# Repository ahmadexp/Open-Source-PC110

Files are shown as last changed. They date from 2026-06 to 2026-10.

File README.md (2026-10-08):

<p align="center">
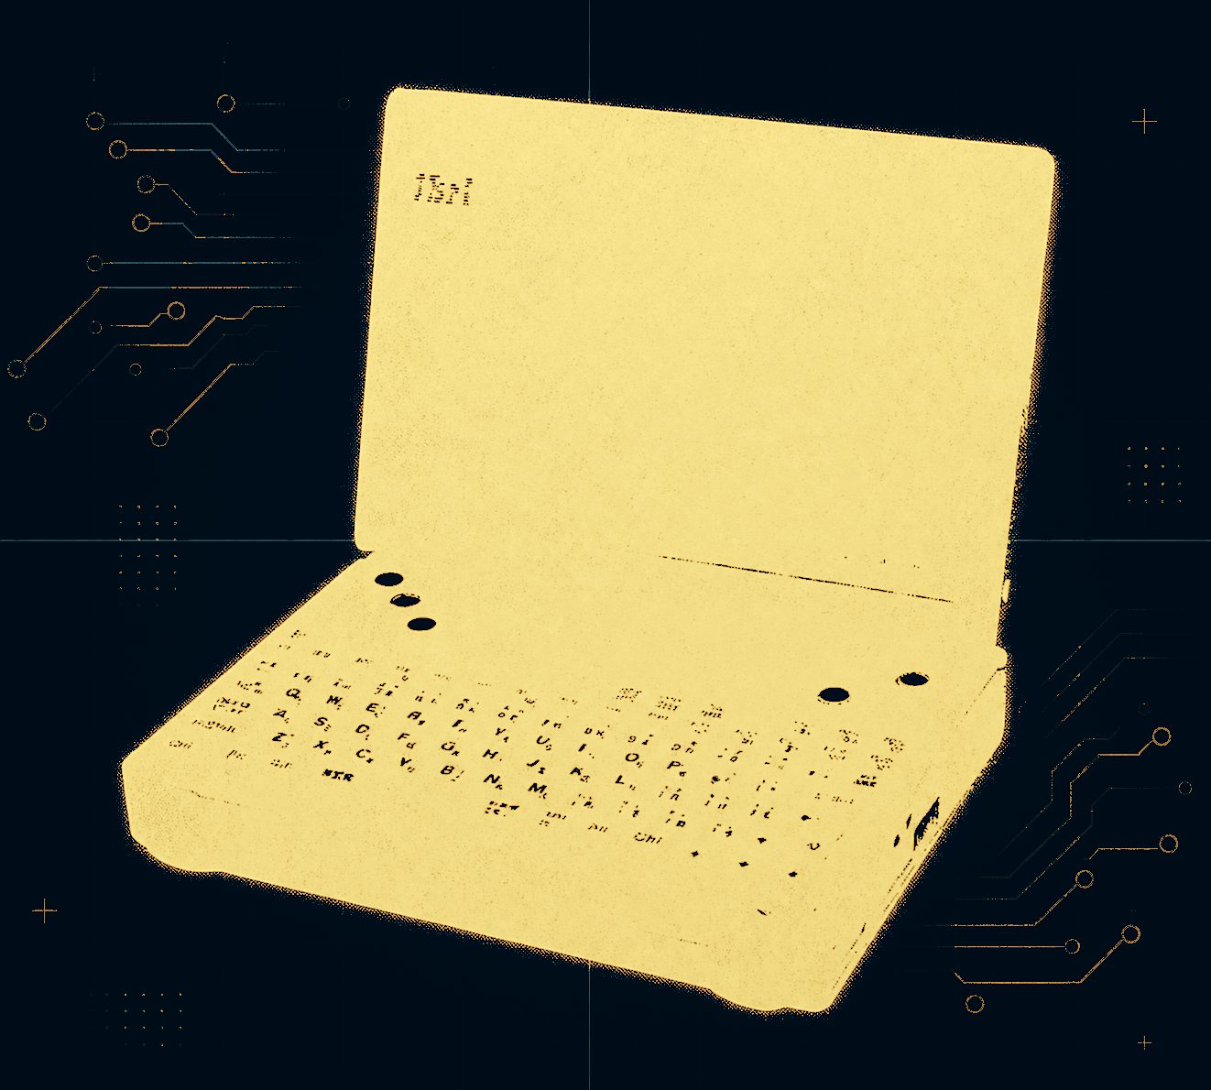
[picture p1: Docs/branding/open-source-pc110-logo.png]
Open-Source PC110 logo
  
</p>

<h1 align="center">Open-Source IBM Palm Top PC110</h1>

<p align="center">
  A complete, open-source reverse engineering of the IBM Palm Top PC110: schematics, PCB layouts,
  ROM and firmware dumps, chip analysis, optical scans, hardware mods, and system tools.
</p>

<p align="center">
  
  
</p>

<p align="center">
  <a href="https://github.com/ahmadexp/Open-Source-PC110/wiki"><strong>Wiki / project story</strong></a>
  ·
  <a href="PCB/PC110-Schematics-Combined.pdf"><strong>Combined schematics</strong></a>
  ·
  <a href="Discovery/Service-Manual/"><strong>Service manual</strong></a>
  ·
  <a href="Mods/ROADMAP.md"><strong>Modernization roadmap</strong></a>
  ·
  <a href="Mods/"><strong>Mods</strong></a>
  ·
  <a href="Software/"><strong>Software</strong></a>
</p>

<p align="center">
  IBM Palm Top PC110 hardware
  PC110 reverse-engineering view
</p>

A complete, open-source reverse engineering of the **IBM Palm Top PC110** (type 2431, 1995), a Japanese-market, 486-class subnotebook co-developed by IBM Japan and Ricoh / RIOS Systems. This repository gathers everything needed to understand, repair, recreate, and modernize the machine: recreated schematics and PCB layouts, die-level chip analysis, firmware and BIOS dumps with disassembly, high-resolution optical and X-ray scans, datasheets, and hardware mods.

> **Goal:** preserve the PC110 in full, signal-for-signal, so it can be rebuilt, repaired, emulated, and reimagined long after the last original board has corroded away.

---

## PC110 Atlas platform compatibility

PC110 Atlas brings the PC110 hardware reference and emulator to modern devices.
Updated October 8, 2026. Features and release availability differ by edition.

### Released editions

| Platform / channel | Compatibility | Download or installation | Availability |
| --- | --- | --- | --- |
| iPhone and iPad | iOS / iPadOS 17 or later | [App Store](https://apps.apple.com/us/app/pc-110/id6801404183) | Available; 1.0.2 (65), released October 7, 2026 |
| iPhone Duo adaptation | Native iOS edition with adaptive inner/outer-display layouts and hinge alignment | [App Store](https://apps.apple.com/us/app/pc-110/id6801404183) | Available in 1.0.2 (65); simulator-tested, with physical-device and guest-runtime validation pending |
| Apple Watch | watchOS 10 or later, paired iPhone | [App Store companion](https://apps.apple.com/us/app/pc-110/id6801404183) | Available; live display, controls, and guest audio from the iPhone session |
| Apple Vision Pro | visionOS 2 or later | [App Store](https://apps.apple.com/us/app/pc-110/id6801404183) | Available; native visionOS edition with local emulation and an interactive 3D PC110 |
| Apple TV | tvOS 17 or later | [App Store](https://apps.apple.com/us/app/pc-110/id6801404183) | Available; hardware, schematics, and history reference with Siri Remote navigation |
| Android phones, tablets, and foldables | Android 8.0 or later; 64-bit ARM64 or x86-64 runtime | [Google Play](https://play.google.com/store/apps/details?id=org.opensourcepc110.atlas) | Available; 1.1.0 (6), published October 8, 2026, with fold-aware layouts, keyboard/mouse support, and optional gamepad controls |
| Wear OS / PC110 Live | Wear OS 3 or later; paired Android phone with matching app and Google Play services | [Google Play companion](https://play.google.com/store/apps/details?id=org.opensourcepc110.atlas) | Available; 1.1.1 (1000007), published October 8, 2026; live display, controls, and optional guest audio |
| Chromebooks and Android gaming handhelds | Compatible Android runtime with Google Play; same Android requirements above | [Google Play](https://play.google.com/store/apps/details?id=org.opensourcepc110.atlas) | Included in Android 1.1.0; resizable workspace and controller support, with physical-device validation still pending |
| Mac App Store edition | macOS 14 or later, Apple M1 or later | [Mac App Store](https://apps.apple.com/us/app/pc-110/id6801404183) | Available |
| Mac desktop / Homebrew | macOS 12 or later; Intel and Apple silicon | [Intel DMG](https://github.com/ahmadexp/homebrew-pc110-atlas/releases/download/desktop-v1.0.0/pc110-atlas-1.0.0-macos-x64.dmg), [Apple silicon DMG](https://github.com/ahmadexp/homebrew-pc110-atlas/releases/download/desktop-v1.0.0/pc110-atlas-1.0.0-macos-arm64.dmg), or [Homebrew instructions](https://github.com/ahmadexp/homebrew-pc110-atlas#install) | Available; Developer ID signed and Apple notarized |
| Windows installers | Windows 10 or later, x64 | [MSI](https://github.com/ahmadexp/homebrew-pc110-atlas/releases/download/desktop-v1.0.0/pc110-atlas-1.0.0-windows-x64.msi) or [EXE](https://github.com/ahmadexp/homebrew-pc110-atlas/releases/download/desktop-v1.0.0/pc110-atlas-1.0.0-windows-x64.exe) | Available |
| Windows / Chocolatey | Windows 10 or later, x64 | [Chocolatey Community package](https://community.chocolatey.org/packages/pc110-atlas/1.0.0) | Approved September 23, 2026; `choco install pc110-atlas` |
| Ubuntu / Snap Store | amd64 and arm64; Linux with snapd | [Snap Store](https://snapcraft.io/pc110-atlas) | Available on stable; `sudo snap install pc110-atlas` |
| Linux / APT | amd64 and arm64; tested on Ubuntu 24.04 | [Signed APT repository and setup](https://ahmadexp.github.io/homebrew-pc110-atlas/) | Available; DEB packages |
| Linux / YUM and DNF | x86_64 and aarch64; compatible RPM distributions | [Signed YUM/DNF repository and setup](https://ahmadexp.github.io/homebrew-pc110-atlas/) | Available; RPM packages |
| Pinokio launcher | Pinokio 8.2+; supported macOS, Windows x64, and Linux x64/ARM64 editions | [Public launcher and installation guide](https://github.com/ahmadexp/pc110-atlas-pinokio) | Available; launches the matching installed edition, not a separate emulator |

### Previews and pending distribution

| Platform / channel | Compatibility | Access or release record | Status |
| --- | --- | --- | --- |
| Android XR | Compatible Android XR headset and 64-bit Android runtime | [Google Play Android edition](https://play.google.com/store/apps/details?id=org.opensourcepc110.atlas) | Optional 3D-laptop preview in 1.1.0; simulator-tested, with physical-headset input and performance validation pending |
| Amazon Fire tablets | Compatible Fire OS with Android API 26+ and a 64-bit ARM64 runtime | [Android 1.1.0 source release](https://github.com/ahmadexp/PC110_MiSTer/releases/tag/pc110-android-1.1.0) | Separate Google-services-free build prepared; hardware validation and Amazon Appstore publication pending |
| Raspberry Pi / Pi-Apps | ARM64 desktop; Raspberry Pi OS Bookworm/Trixie or compatible Ubuntu | [1.0.1 review build](https://github.com/ahmadexp/homebrew-pc110-atlas/releases/tag/desktop-v1.0.1) and [testing guide](https://github.com/ahmadexp/homebrew-pc110-atlas/blob/main/desktop/packaging/pi-apps/README.md) | QEMU review build available and tested on Raspberry Pi 5; [Pi-Apps PR #3051](https://github.com/Botspot/pi-apps/pull/3051) remains open |
| Microsoft Store | Windows 10 or later, x64 desktop | Store ID `9P4QHSVPL2VF` | QEMU-enabled 1.0.1.0 submitted September 18; public Store release not confirmed |
| IRIX / Unix X11 | Experimental IRIX 6.5, MIPS n32 target | [Source test kit](https://github.com/ahmadexp/homebrew-pc110-atlas/releases/tag/irix-v1.0.0) and [build instructions](https://github.com/ahmadexp/homebrew-pc110-atlas/blob/main/unix/README.md) | Source only; frontend tested on Linux X11, with SGI hardware testing still required |

### Edition and device notes

- Apple TV is a reference edition, not a QEMU emulator, and does not import firmware or disk images.
- Apple Watch and Wear OS display a paired phone's running session. QEMU does not run on the watch. Wear OS physical pairing and audio validation remain pending.
- Android requires a 64-bit operating system, not just a 64-bit processor. Android TV / Google TV, cars, 32-bit Android, and Amazon Vega OS are not supported. Physical foldable, Chromebook, handheld/controller, XR, Wear OS, and Fire validation remains incomplete; implementation does not mean every device has been tested.
- The Mac App Store and Homebrew apps are separate editions. Published portable desktop 1.0.0 packages for Intel/Apple silicon Mac, Windows, and Linux use the portable PC110 core, not QEMU, and do not include guest audio. The Raspberry Pi review build and Microsoft Store candidate are separate QEMU-enabled packages.
- Linux packages require compatible system libraries and a graphical desktop. The smaller Unix edition requires a C99 compiler, GNU make, and X11 development libraries.
- Import your own legally obtained compatible system media where supported; guest operating-system compatibility varies by edition.

See [desktop downloads and checksums](https://github.com/ahmadexp/homebrew-pc110-atlas/releases/tag/desktop-v1.0.0),
the [distribution validation record](https://github.com/ahmadexp/homebrew-pc110-atlas/blob/main/desktop/DISTRIBUTION_VALIDATION.md),
and the [Android 1.1.0 corresponding source](https://github.com/ahmadexp/PC110_MiSTer/releases/tag/pc110-android-1.1.0).

## Start here

| If you want to... | Go here |
|---|---|
| Install PC110 Atlas on your device | [Platform compatibility and downloads](#pc110-atlas-platform-compatibility) |
| Understand the full reverse-engineering journey | [Wiki / A Tribute to the IBM PC110](https://github.com/ahmadexp/Open-Source-PC110/wiki) |
| Repair or inspect original hardware | [Unofficial service manual](Discovery/Service-Manual/) and [power sequence guide](Discovery/Power-Sequence/) |
| Review the recreated boards | [PCB projects](PCB/) and [combined schematic PDF](PCB/PC110-Schematics-Combined.pdf) |
| Explore the custom chips and ROMs | [Components](Components/) and [Flash / ROM dumps](Components/Flash/) |
| Work on emulation or system software | [Discovery notes](Discovery/), [PS2 tools](Software/), and [PC110 emulators & FPGA cores](#pc110-emulators--fpga-cores) |
| Build a modernized PC110 variant | [Mods](Mods/) including ITX boards, CPU upgrade work, RAM expansion, and TFT replacement |

## Repository map

| Folder | What you'll find |
|---|---|
| [**Wiki**](https://github.com/ahmadexp/Open-Source-PC110/wiki) | The polished project story and guided tour: why the PC110 matters, how the board was reconstructed, and where to start. |
| [**`PCB/`**](PCB/) | Recreated **KiCad schematics and PCB layouts** for the mainboard, PSU, keyboard membrane, docking station, modem, and 16 MB RAM module. Includes a [combined schematic PDF](PCB/PC110-Schematics-Combined.pdf), fab files, BOMs, and 3D renders. |
| [**`Components/`**](Components/) | **Chip-level reverse engineering**: die-level analysis (with John McMaster), firmware/BIOS/ROM dumps for six chips, disassembly, emulators, and the internal 4 MB disk image. |
| [**`Discovery/`**](Discovery/) | **Deep-dive subsystem notes** for each major chip and bus, plus an unofficial, comprehensive **service & technical reference manual**, a **live hardware dump** from a running unit, and a reverse-engineering of IBM's `PS2.EXE` tool. Start here to understand how it all fits together. |
| [**`Software/`**](Software/) | **Tools for the PC110** — including **PS2TUI**, **PS2GUI**, and **COMrade**, the serial bridge for DOS and Windows 95 control. |
| [**`Mods/`**](Mods/) | **Hardware modifications and redesigns**: ITX-form-factor recreations, a CPU upgrade adapter, a new docking station, a +4 MB RAM mod, a TFT display swap, and Altium ports. |
| [**`Optical/`**](Optical/) | **High-resolution optical scans, X-ray captures, and individual copper-layer images** of every board and the custom chips. |
| [**`Datasheets/`**](Datasheets/) | Datasheets, pinouts, and connector maps for the chips and connectors across the motherboard and peripheral boards. |
| [**`Docs/`**](Docs/) | The project's story — ["A Tribute to the IBM PC110"](Docs/) — covering the sanding, scanning, decapping, and schematic-extraction journey. |

---

## Recreated PCBs ([`PCB/`](PCB/))

All boards are recreated in **KiCad 9.0** (requires the [Alternate KiCad Library](https://alternatekicadlibrary.com/)), with fab files and BOMs.

| Board | Description | Layers |
|---|---|---|
| Mainboard | Motherboard | 10 |
| PSU | Power supply | 4 |
| Keyboard | Keyboard membrane | 2 + 2 |
| Docking Station | Port expansion | 4 |
| Modem | 14.4 kbps internal modem | 6 |
| RAM-16MB | 16 MB RAM module | 4 |

**[Combined schematic PDF →](PCB/PC110-Schematics-Combined.pdf)**

### Mother Board
- Schematic

Mainboard schematic

- Layout

Mainboard layout

### Power Supply
- Schematic

PSU schematic

- Layout

PSU layout

### Keyboard Membrane
- Schematic

Keyboard schematic

- Layout

Keyboard layout

### Port Expansion (Docking Station)
- Schematic

Dock schematic

- Layout

Dock layout

### 14.4 kbps Internal Modem
- Schematic

Modem schematic

- Layout

Modem layout

### 16 MB RAM Module
- Schematic

RAM schematic

- Layout

RAM layout front
RAM layout back

---

## Component Reverse Engineering ([`Components/`](Components/))

### Die-level investigation

A collaboration with [John McMaster](https://siliconpr0n.org/archive/doku.php?id=ibm:pc110) — laser-decapped chips with high-resolution die imaging.

| Designator | Part | Function | Notes |
|---|---|---|---|
| U61 | VL82C420FC5 | "SCAMP IV" chipset (DMA, PIC, PIT, RTC) | [Notes](Components/U61-VL82C420FC5/) |
| U35 | Pluto | Custom I/O gate array | [Notes](Components/U35-Pluto/) |
| U21 | Bowman | Custom system-controller gate array | [Notes](Components/U21-Bowman/) |
| U75 | D17137AGT | TrackPoint controller | [Notes](Components/U75-D17137AGT/) |

### Flash & ROM dumps

Raw readouts plus reverse-engineering analysis (reports, extracted strings, hexdumps, disassembly, and in some cases emulators) for the programmable chips. See [`Components/Flash/`](Components/Flash/).

| Chip | Size | Role |
|---|---|---|
| [Intel E28F002BXT](Components/Flash/E28F002BXT/) | 256 KiB | Main/system **BIOS** (IBM VGA-compatible, APM) — includes BIOS disassembly project |
| [OKI MSM538032E](Components/Flash/OKI-MSM538032E/) | 1 MiB | Japanese/system **font mask ROM** |
| [Eon EN29F040A](Components/Flash/EN29F040A/) | 512 KiB | **Modem/fax board** flash |
| [Mitsubishi M38813E4HP](Components/Flash/M38813E4HP/) | ~16 KiB | **Keyboard controller** firmware (U67) |
| [Mitsubishi M38223E4HP](Components/Flash/M38223E4HP/) | ~16 KiB | **Power-sense** MCU firmware (U6) — includes an emulator |
| [Atmel AT29LV512](Components/Flash/AT29LV512/) | 64 KiB | SanDisk PCMCIA ATA FlashDisk controller (68000) |

### Internal disk image

Images of the PC110's internal 4 MB solid-state drive in [`Components/Internal-Disk-Image/`](Components/Internal-Disk-Image/) (raw `.img` and PowerQuest `.PQI`).

---

## Discovery — subsystem deep-dives ([`Discovery/`](Discovery/))

Reconstructed from schematic recreations, firmware disassembly, die scans, and the datasheets of architectural-twin parts.

| Folder | Subject |
|---|---|
| [**Service-Manual**](Discovery/Service-Manual/) | Unofficial comprehensive service & technical reference manual — **start here** |
| [Chipset](Discovery/Chipset/) | VLSI VL82C420 "SCAMP IV" system controller, full pin map |
| [Bowman](Discovery/Bowman/) | U21 main system-controller ASIC |
| [Pluto](Discovery/Pluto/) | U35 I/O gate array (with 6502 disassembler) |
| [65535](Discovery/65535/) | C&T F65535 flat-panel/CRT VGA controller |
| [ES488](Discovery/ES488/) | ESS ES488F "AudioDrive" + YM3812 (OPL2) FM chain |
| [Modem](Discovery/Modem/) | MN195001 single-chip fax engine |
| [PSU-MB-M38](Discovery/PSU-MB-M38/) | U6 M38223E4HP power-sense MCU + connector map |
| [Power-Sequence](Discovery/Power-Sequence/) | Power-on sequence & "won't power on" repair guide |
| [Trackpoint](Discovery/Trackpoint/) | U75 µPD17137A pointing-device controller |
| [Debug](Discovery/Debug/) | 80486SX debug / JTAG headers + a homebrew debug pod |
| [PS2](Discovery/PS2/) | IBM's `PS2.EXE` configuration tool, fully reverse-engineered — including the hidden `_@` commands |
| [Live-Dump](Discovery/Live-Dump/) | Chipset / BIOS / OS state captured from a **running PC110** over a serial link |

---

## Modifications & redesigns ([`Mods/`](Mods/))

| Project | Description |
|---|---|
| [PC110-ITX](Mods/PC110-ITX/) | An ITX-form-factor motherboard reimplementing the PC110, with original BGA parts converted to QFP for easier assembly |
| [PC110-ITX-all-in-one](Mods/PC110-ITX-all-in-one/) | ITX variant that merges the motherboard and docking-station PSU into one board |
| [CPU Upgrade](Mods/CPU%20Upgrade/) | BGA-to-socket adapter work toward a faster CPU (shares the VL82C420 with Taka's 230cs upgrade) |
| [NewDock](Mods/NewDock/) | A redesigned docking station as a standalone KiCad project |
| [RAS4](Mods/RAS4/) | Enables an extra 4 MB of internal RAM by repurposing `VL_D12` as `RAS#4` |
| [TFT](Mods/TFT/) | TFT display replacement, including a BIOS patch image |
| [Altium](Mods/Altium/) | The PCB projects ported from KiCad to Altium |

---

## Optical scans & X-rays ([`Optical/`](Optical/))

High-resolution optical scans, X-ray captures, and individual copper-layer images of every board and the custom chips — including the full 10-layer copper stack of the mainboard, x-rays of the BGA/QFN packages, and corner-stitch die photos for the 486SX, VL82C420, F65535, Bowman, and Pluto. See [`Optical/README.md`](Optical/).

---

## Community

Join the discussion, ask questions, and share your work:

**Discord:** [discord.gg/WvRh6C6WT](https://discord.gg/WvRh6C6WT)
**Facebook group:** [IBM PC110 community](https://www.facebook.com/groups/985746629171739)

---

## How can you help?

- **Review** the schematics and PCB layouts to spot bugs, errors, and issues.
- **Verify** the layout against the schematic and against real hardware.
- **Find** missing datasheets for the custom and undocumented parts.
- **Contribute** firmware / ROM analysis and disassembly.
- **[Fund the next iteration of PCBA](https://gofund.me/716b7dae)** so we can fabricate and test the recreated motherboard.

---

## Press

Featured on **Hackaday**:
- [Reverse Engineering The IBM PC110, One PCB At A Time](https://hackaday.com/2025/04/06/reverse-engineering-the-ibm-pc110-one-pcb-at-a-time/)

Featured on **Taka's blog**:
- [PC110 New PSU](https://garakutaen.sakura.ne.jp/misc2/MlogmP3.html#e0318)
- [PC110 PCB Pattern](https://garakutaen.sakura.ne.jp/misc2/MlogmP1.html#e0130)
- [PC110 PCB Layout creation](https://garakutaen.sakura.ne.jp/misc2/MlogmP2.html#e0208)
- [PC110 New Docking Station PCB](https://garakutaen.sakura.ne.jp/misc2/MlogmP3.html#e0324)
- [X-ray photos of the inside of the PC110's LSI](https://garakutaen.sakura.ne.jp/misc2/MlogmP2.html#e0225)

**Jeff Geerling's YouTube Channel**:
- [Reverse engineering Episode](https://youtu.be/p7IvioiveOo?si=PUlHSzOhwXYEpZJ3&t=217)

**LGR YouTube Channel**:
- [LGR Vlog: VCFMW20](https://www.youtube.com/watch?v=yIwXQicYClw&t=7595s)

**VCFMW20 YouTube Channel**:
- [Archaeology of the IBM PC110](https://www.youtube.com/watch?v=8Uja7g9hQlo)

---

## Acknowledgements

This project would not have been possible without **Kevin Moonlight** (microcontroller ROM extraction), **Mike Lycett** (fundraiser & coordination), **Nick Rogers** (debugging & verification), **John McMaster** (high-resolution die imaging), **CLC / Fred Nielsen** (decapping & silicon prep), and the wider **open hardware & retrocomputing community**.

---

## PC110 Emulators & FPGA cores

**[PC110-EMU](https://github.com/ahmadexp/PC110-EMU)**: an experimental emulator built around the *real* machine artifacts documented here. It boots the actual PC110 BIOS, runs PC DOS and Personaware, and loads the power-sense and keyboard-controller MCU firmware and the Japanese font flash — the very dumps that live in this repository's [`Components/Flash/`](Components/Flash/) folder.

Highlights:

- Boots the real PC110 BIOS and runs **PC DOS** and supported **Personaware** disk images, including the ROM-backed graphical **Easy-Setup** screen.
- Renders the Personaware launcher with **Japanese DBCS glyphs** pulled from the PC110 font flash ([`MSM538032E`](Components/Flash/OKI-MSM538032E/)).
- Loads the **M38223** power-sense MCU and **M38813** MELPS 740 keyboard-controller firmware for diagnostics and controller responses.
- Models the **front LCD status strip** (the startup `IBM` segment display, time, disk, PMCU, KBC, speaker, and setup state).
- Two frontends: a native **macOS SwiftUI** app for bring-up and diagnostics, and a **portable CMake** build (Linux / Windows / macOS) with a headless runner and an optional SDL2 GUI.
- Rich diagnostics: copy-ready CPU state, traces, memory, and text-screen dumps.

> The emulator ships **no copyrighted ROMs** — use the legally obtained dumps from hardware you own. This repo documents where those dumps come from and what each one does.

The macOS frontend running **Personaware**, with live diagnostics and the modeled front LCD:

PC110 EMU running Personaware with diagnostics and front LCD

The ROM-backed graphical **BIOS Easy-Setup** screen:

PC110 BIOS Easy-Setup screen

**[Get the emulator → ahmadexp/PC110-EMU](https://github.com/ahmadexp/PC110-EMU)**

**[PC110-QEMU](https://github.com/ahmadexp/pc110-qemu)**: a QEMU based emulator for the PC110 with support for the BIOS and is able to boot into DOS7 and run Personaware.

It turns out stock QEMU can run the PC110's software once you give it the handful of PC110-specific
hardware bits the software insists on. PC110-QEMU adds three small QEMU device models, all fed by
the *real* ROM dumps archived in this repository:

- **`pc110-fontrom`** — the banked 1 MB **kanji font ROM** (I/O port `0x1160` selects one of 128 ×
  8 KB banks into a window at `0xDE000`, exactly the mechanism DOS/V's `$FONT.SYS` probes), fed by
  the [MSM538032E dump](Components/Flash/OKI-MSM538032E/). This is what makes Personaware's
  Japanese text render.
- **`pc110-chipset`** — a VLSI/SCAMP + power-MCU shim with an optional full-ROM shadow overlay,
  enough to boot the **real PC110 BIOS** ([E28F002BXT dump](Components/Flash/E28F002BXT/)) on QEMU.
- **`pc110-setupcfg`** — a SeaBIOS-safe config-register + power-MCU interface for the Easy-Setup
  program.

With those in place (`-cpu 486 -m 20M -vga cirrus -device pc110-fontrom,romfile=...`):

- **Personaware**, IBM's Japanese pen-centric GUI, boots to its full home screen in ~20 s — every
  applet (Schedule, ToDo, Notebook, Address, EMail, FAX, IR, WorldClock, DrawMemo, …), live clock,
  working mouse, and sharp DBCS kanji rendered from the real font ROM.
- The graphical **BIOS Easy-Setup** runs under SeaBIOS too: the LZW-compressed setup image is
  extracted from the BIOS flash and chain-loaded by a custom floppy boot sector that enters it
  exactly like the real BIOS does — full main menu, config screens, and the bird mascot — and
  exiting Easy-Setup drops you back into Personaware, just like on the real machine.

The repo also ships the supporting tooling: the LZW Easy-Setup extractor, the Easy-Setup boot
loader (with exit/restart routed back to the hard disk), a partition-dump → bootable-disk
converter (the PC110's internal disk images are partition dumps that need an MBR prepended), and
build/run scripts. No ROMs or disk images are included — supply your own legally obtained dumps,
which this repository documents how to make.

**[Get it → ahmadexp/pc110-qemu](https://github.com/ahmadexp/pc110-qemu)**

**[PC110_MiSTer](https://github.com/ahmadexp/PC110_MiSTer)**: the PC110 as an **FPGA core** — not
emulation but a hardware reimplementation, targeting the **MiSTer** platform (**DE10-Nano**) and built
on the `ao486` core infrastructure. Like the emulators above, it is fed by the *real* dumps archived
here.

Verified milestone: **a zero-error POST, IBM Easy-Setup with working keyboard navigation, and an
unattended PC DOS J7.0/V boot into the PersonaWare V1.0 desktop.**

What the core implements, and where it lines up with this repository:

- **486-class CPU** (forced 30 MHz) plus the AT peripheral set — IDE, floppy, VGA, keyboard, mouse.
- **The stock PC110 memory map**: 4 MiB planar RAM + a 16 MiB expansion module — i.e. the factory 20 MB
  configuration documented in [`Discovery/RAM-Module`](Discovery/RAM-Module/readme.md).
- **256 KiB flash mapped at `C0000h–FFFFFh`** — the [E28F002BXT BIOS dump](Components/Flash/E28F002BXT/).
- **Font-ROM banking** with a 1 MiB font image — the [MSM538032E dump](Components/Flash/OKI-MSM538032E/)
  and the `0x1160` bank-select mechanism, which is what makes Japanese text render.
- **PCMCIA and CMOS** interfaces, the **inking** interface
  ([`Discovery/Inking`](Discovery/Inking/)), and PC110-specific board **I/O decode**.

The project is refreshingly candid about its scope — it calls itself *"an engineering core, not yet a
cycle-exact replacement for the whole PC110 planar,"* and documents which parts are **measured** versus
**placeholder** separately. Building needs **Quartus 17.0.2** (provided via a Docker container), with
scripts for ROM preparation, build, and deployment to MiSTer hardware over SSH.

**[Get the core → ahmadexp/PC110_MiSTer](https://github.com/ahmadexp/PC110_MiSTer)**

## PC110 System Configuration tools

**[PS2TUI](https://github.com/ahmadexp/PS2TUI)**: a text UI based tool to configure, test and perform system level operations on the PC110.

`PS2.EXE` is IBM's command-line utility for configuring the PC110: ~50 cryptic, largely
undocumented switches controlling power management, device I/O assignment, display, keyboard, and
low-level chipset settings. We disassembled it and decoded its hardware interface in
[`Discovery/PS2`](Discovery/PS2/) — the full command reference **including the hidden `_@`
commands**, how it drives the APM BIOS (`INT 15h AX=5300/530A`), IBM's **vendor APM extension**
(`AX=5380`), and where the settings are stored in extended CMOS
([`DISASM.md`](Discovery/PS2/DISASM.md) has the annotated disassembly).

**PS2TUI** turns that knowledge into a tool you'd actually want to use: a full-screen,
keyboard-driven menu for all of it, written in assembly as a ~3.4 KB DOS `.COM`.

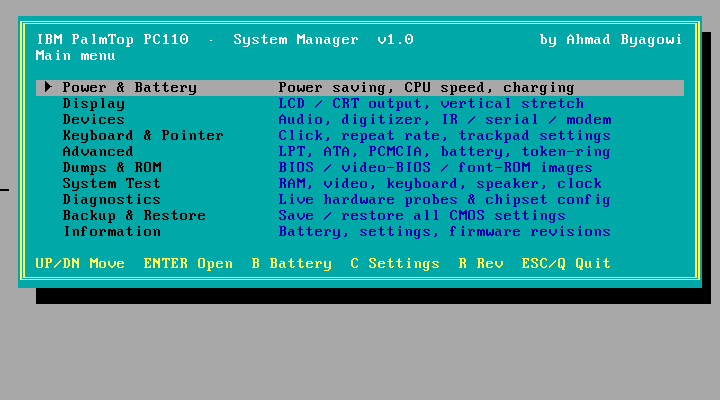
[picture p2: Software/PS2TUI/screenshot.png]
PS2TUI main menu


- Covers the documented **and hidden** setting groups (power, display, audio, IR/serial/modem
  routing, keyboard, PCMCIA, and more); every change shows the exact `PS2` command and asks for
  confirmation before running it.
- **Native read paths** — no `PS2.EXE` needed: live battery / AC status straight from the APM
  BIOS, and the current settings read directly from CMOS.
- Extras `PS2.EXE` never had: byte-perfect **dumps of the system BIOS, video BIOS, and the 1 MB
  font ROM** to disk (CRC-verified against the dumps in this repo), plus an Easy-Setup-style
  **system test** (RAM, video, keyboard, speaker).
- Settings are *applied* by invoking IBM's own `PS2.EXE`, so all writes go through IBM's tested
  hardware paths.
- Built with NASM; developed and verified **on real PC110 hardware** over a serial
  [COMrade](Discovery/Live-Dump/) session.

Prebuilt binary and source: [`Software/PS2TUI/`](Software/PS2TUI/) · standalone repo:
**[ahmadexp/PS2TUI](https://github.com/ahmadexp/PS2TUI)**

**[PS2GUI](https://github.com/ahmadexp/PS2GUI)**: a graphical IBM Easy-Setup-style system manager for the IBM PalmTop PC110.

**PS2GUI** builds on the same PS2TUI command tree and turns it into a VGA mode 12h
(640x480x16) icon-grid interface that closely matches the PC110's own BIOS Easy-Setup screen.

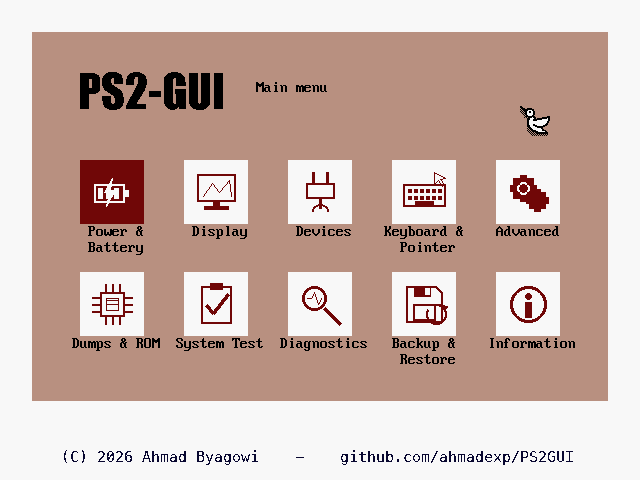
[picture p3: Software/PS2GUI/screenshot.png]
PS2GUI main menu


- Recreates the Easy-Setup look: white border, mauve desktop, dark-red selection, matching DAC
  palette, heavy title lettering, and a 5x2 grid of white icon tiles.
- Covers the same ten top-level categories and option lists as PS2TUI, with hand-drawn pixel-art
  icons for each category and item.
- Runs as a self-contained real-mode DOS `.COM`; the native APM / CMOS / SCAMP / PCIC / 8042
  read paths, dumps, diagnostics, and tests are built in, so no external `PS2TUI.COM` is needed.
- Supports keyboard navigation and INT 33h mouse input, including an Easy-Setup-style arrow cursor
  and graphical value-picker dialogs.
- Applies configuration changes through IBM's own `PS2.EXE` / `ULTRACHG.COM`, keeping writes on
  the original tested hardware paths.

Prebuilt binary and source: [`Software/PS2GUI/`](Software/PS2GUI/) · standalone repo:
**[ahmadexp/PS2GUI](https://github.com/ahmadexp/PS2GUI)**

**[COMrade](Software/COMrade/)**: a serial control bridge for PC110 bring-up and
remote diagnostics. The DOS TSR supports screen and console capture, file
transfer, keyboard injection, real-mode memory, port I/O, and hardware probes.
The included `COMR95.EXE` is a separate Win32 agent for Windows 95 with file,
keyboard, screen, and small GDI desktop-thumbnail support, using the same wire
protocol and Python MCP bridge.

Prebuilt agents and source: [`Software/COMrade/`](Software/COMrade/) · upstream:
**[yyzkevin/COMrade](https://github.com/yyzkevin/COMrade)**

---

## License

This project is licensed under the Creative Commons Attribution-NonCommercial 4.0 International License (CC BY-NC 4.0).

You are free to:
- Share, copy and redistribute the material in any medium or format
- Adapt, remix, transform, and build upon the material

Under the following terms:
- Attribution: You must give appropriate credit, provide a link to the license, and indicate if changes were made.
- NonCommercial: You may not use the material for commercial purposes.

For full details, see: https://creativecommons.org/licenses/by-nc/4.0/

As the project creator, I reserve the right to use this material commercially or under any other terms.

Apple and the Apple logo are trademarks of Apple Inc., registered in the U.S. and other countries and regions. App Store is a service mark of Apple Inc.

Google Play and the Google Play logo are trademarks of Google LLC.

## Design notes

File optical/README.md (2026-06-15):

# IBM PC110 — Optical Scans

This directory holds high-resolution optical scans, X-ray images, and PCB layer
captures of the IBM PC110 palmtop and its peripheral boards. The images are
intended to support reverse-engineering, repair, and re-creation of the original
hardware.

## Root images

- `top.png` / `top.jpg` — Optical scan of the top (component) side of the main board.
- `bottom.png` / `bottom.jpg` — Optical scan of the bottom side of the main board.
- `PC110 keyboard.png` — Scan of the keyboard.
- `PSU_BC.png`, `PSU_BC_2.png`, `PSU_BC_parts.jpg` — Power supply board scans (back/component side and part annotations).

## Folders

### `layers/`
Individual copper-layer images of the main board, extracted from the optical
stack. The layer order, from top to bottom, is:

`FC2` (top) → `FC1` → `IP1` (power) → `IC1` → `IC2` → `IC3` → `IC4` → `IP2` (ground) → `BC1` → `BC2` (bottom)

Also includes `top-parts.png` / `bottom-parts.png` part-annotation overlays.
See `layers/README.md` for the layer stack and a link to full-resolution files.

### `x-ray/`
X-ray captures of individual chips and the overall board, used to trace internal
bonding and routing. Includes the `82C420` (BGA and QFN packages), `82c144`,
`486`, `f65535`, `bowman`, and `pluto` devices.

### `Chip Diagnostic/`
Close-up die / package photos of the main ICs (`486sx`, `80486dx2`, `VL82C420`,
`F65535`, `Bowman`, `Pluto`) taken from multiple corners (TL/TR/BL/BR/center)
for stitching, plus board diagnostic shots (`BRD*`) and extracted layers.

### `VL82C420FC5/`
Detailed imagery of the VL82C420 system controller chip, including a
`04 Sample 4 ECO Green.pptx` reference deck.

### `Bowman/` and `Pluto/`
Sequential scan images (`Picture1`–`Picture12`) of the Bowman and Pluto
custom chips.

### `Modem/`
Scans of the modem board: component side (`FC`) and back (`BC`), with variants
showing parts, part values, mask-removed copper, and internal layers (`In1`–`In4`).

### `PSU/`
Scans of the power-supply board: front/back component sides with parts, plus
PCB copper layers (`FC`, `BC`, `IC`, `IP`) including mask-removed versions.

### `DockingStation/`
Scans of the docking-station board: front/back sides with and without parts,
ribbon cables (top/back), and internal layers.

### `16MB-RAM/`
Scans of the different layers of the 16 MB RAM module (front, back, and
multiple scan passes).

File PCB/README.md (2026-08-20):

## PC110 Recreated PCBs

Here you can find the recreated all the boards [Schematics](https://github.com/ahmadexp/Open-Source-PC110/blob/main/PCB/PC110-Schematics-Combined.pdf).

Mainboard, RAM-16MB, and Keyboard project file require KiCad 9.0 (with the [AKL](https://alternatekicadlibrary.com/) as a requirement).

Other project file require KiCad 10.0.4. footprint and symbol library included each project folder.

Here is a description of each folder:

| Index | Folder | Description | Number of Layers | KiCad version |
| ----- | --- | --- | --- | --- |
| 1 | Mainboard | Mother Board | 10 | 9.0 |
| 2 | PSU | Power Supply | 4 | 10.0.4 |
| 3 | Keyboard | Keyboard Membrane  | 2 + 2 | 9.0 |
| 4 | DockingStation | Port Expansion | 4 | 10.0.4 |
| 5 | Modem | 14.4 Interal Modem | 6 | 10.0.4 |
| 6 | RAM-16MB | 16MB RAM Module | 4 | 9.0 |

Here are some 3D renders of the PCBs

### Mother Board:

- Schematic

Screenshot 2025-06-19 at 7 54 10 AM

- Layout

motherboard

### Power Supply:

- Schematic
PSU

- Layout
Screenshot 2025-04-04 at 7 01 09 PM

### Keyboard Membrane:

- Schematic
Screenshot 2025-06-19 at 7 48 27 AM

- Layout
Screenshot 2025-03-26 at 6 59 02 PM

### Port Expansion (Docking Station):

- Schematic
dock

- Layout
dock

### 14.4 Kbps Internal Modem:

- Schematic
modem

- Layout
modem

### 16MB RAM Module:

- Schematic
Screenshot 2025-06-19 at 7 48 20 AM

- Layout
Screenshot 2025-03-26 at 7 45 36 PM

Screenshot 2025-03-26 at 7 45 54 PM

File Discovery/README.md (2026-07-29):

# PC110 Discovery

Reverse-engineering notes for the **IBM PalmTop PC110** (type 2431, 1995 — a Japanese-market, 486-class subnotebook co-developed by IBM Japan and Ricoh / RIOS Systems). Part of the [Open-Source-PC110](https://github.com/ahmadexp/Open-Source-PC110) project.

Each folder below is a deep-dive into one chip or subsystem, reconstructed from KiCad schematic recreations, ROM/firmware disassembly, die scans, and the datasheets of architectural-twin parts. Most folders contain a `readme.md` with the full analysis; several also include schematic crops, ROM dumps, and disassembly scripts.

## Folders

| Folder | Subject | What's inside |
|---|---|---|
| **Service-Manual** | Unofficial, comprehensive service & technical reference manual (rev 2.0, June 2026) | The umbrella document tying every subsystem together — machine overview, system architecture, chip roster, power, troubleshooting, and a glossary. Start here. |
| **Live-Dump** | Ground-truth capture from a **running** PC110 (2026) | Live I/O-port reads, BIOS/video-BIOS/CMOS/font-ROM dumps, power-MCU and PCMCIA-controller state, and the on-disk software inventory — read over the wire and cross-checked against the reverse-engineering chapters (incl. a live authentication of the archived BIOS ROM). |
| **PS2** | IBM's **`PS2.EXE`** system-management tool, reverse-engineered | How the tool drives the hardware (APM `INT 15h/53h` + direct CMOS/SCAMP/power-MCU port pokes), the live firmware-revision manifest, and a command↔subsystem cross-reference. A friendlier menu front-end lives in [`Software/PS2TUI`](../Software/PS2TUI/). |
| **ULTRACHG** | The **"operation charge"** utility, reverse-engineered | How `ULTRACHG.COM` lets the PC110 charge while running — it drives the **embedded-controller mailbox** at `0x15E8/0x15EC` with `Zn10`/`Zn00` commands (reclassifying that I/O window). |
| **Inking** | The **resistive inking / signature pad** (digitizer), reverse-engineered | The pen/handwriting/signature panel behind the `ADDINKing` I/O window (base `0x15E0`), read by the M38223 touch-panel ADC via Bowman. Full register model + 3-byte packet format from `INKDRV.COM`, verified live. A direct-drive **"Signature pad test"** ships in [`Software/PS2GUI`](../Software/PS2GUI/). |
| **Chipset** | VLSI **VL82C420** "SCAMP IV" system controller | Full technical reference: CPU local bus, DRAM controller, ISA bridge, integrated DMA/PIT/PIC/RTC, power management, and the reverse-engineered 208-signal pin map. |
| **BIOS-Flash** | Reprogramming the **U59** BIOS flash (Intel 28F002BXT) | How the machine reflashes its own BIOS: the board-level VPP switch and `Pluto_BIOS_WR_EN` WE#-gate (from the netlist), the register/port enable sequence and 28F002 program/erase commands (decoded from a working updater), the write-enable = `block2[0xFE]` + VPP-enable = `port 0x98` bit 3 answer, and the open-source in-system flasher in PS2GUI/PS2TUI. |
| **Bowman** | **U21 "Bowman"** — main system-controller ASIC | The custom ~144-pin RIOS gate array bridging the 80486SX local bus to the 16-bit ISA bus; ROM decode, interrupts, DMA, floppy, keyboard-MCU link, audio glue. |
| **Pluto** | **U35 "Pluto"** — I/O gate array | The 100-pin custom ASIC handling peripheral I/O glue: keyboard, floppy, PCMCIA/CF detect, IrDA, RS-232, LCD/power rails, docking, modem, BIOS flash. Includes a 6502 disassembler and KBC/RAM/dock notes. |
| **65535** | **U51** — Chips & Technologies **F65535** display controller | Deep-dive on the single-chip flat-panel/CRT VGA controller (BGA169): CPU bus interface, integrated DRAM controller and RAMDAC, LCD formatter, full pin map. |
| **ES488** | **U4** — ESS **ES488F** "AudioDrive" audio subsystem | Sound Blaster–compatible ISA codec plus the discrete YM3812 (OPL2) FM chain and speaker amp. Now includes the **complete traced audio signal path** — sound is mixed **twice** (inside the ES488, then again in a discrete NJM3414A summing mixer that sets the PCM:FM balance in *hardware*), the YM3014B serial DAC, the DS1669 push-button volume pot, the LM4861 BTL amp and headphone-mute logic — plus **live chip ID** (self-IDs as ES488, running only as **SB 2.0** — mono, 8-bit, no mixer) and two replacement assessments: an ES1488 swap (**not worth it**) and putting an **RP2350 in the U4 socket** to inherit the ISA interface, DMA channel and tuned analogue back-end while presenting SB Pro/SB16 in firmware (**the recommended path**). |
| **Modem** | **MN195001** single-chip fax engine | How the internal fax/modem module connects through the motherboard to the docking station, the "extra" dock pins, and analysis of the IC11 firmware ROM ("RIOS Ver 1.04"). A board-level teardown of the modem PCB itself (memory bus, discrete DAA, handset audio, CNP4 pinout) is in `board-teardown.md`. |
| **DockingStation** | The desktop **docking station** (port replicator) | Board-level analysis of the dock PCB: a mostly-passive, EMI-filtered port replicator (VGA, LPT, floppy, serial, dual PS/2) + power pass-through; full J1–J4 dock-connector net map, active parts (DS14C535, 74VHCT244), and recreation notes. |
| **Keyboard** | The **keyboard membrane** (key-matrix flex) | The passive 8×16 scan matrix behind the built-in keyboard: 90 keys + 2 pointer buttons, KB1/KB2 net → M38813 KBC port mapping, J1/J2 ribbon-tail pinouts, and PET-membrane recreation notes. |
| **RAM-Module** | The proprietary **16 MB RAM expansion module** | Eight 2M×8 EDO DRAMs as two 32-bit banks (RAS2/RAS3, four byte-lane CAS strobes), the full 64-pin J15 connector pinout, and the RAM_ID strap encoding read by Pluto. |
| **PSU-MB-M38** | **U6** — Mitsubishi **M38223E4HP** power-sense MCU | Firmware reverse-engineering of the power-management micro plus the J5/J3 inter-board connector map. Includes the disassembly (`disasm_full.asm`), tracing scripts, and connector crops. |
| **Power-Sequence** | Power-on sequence & "won't power on" repair guide | Step-by-step power-up chain derived from the U6 firmware and PSU schematics, with what to measure at each stage. |
| **Storage** | The **ATA/CF disk path** (`0x1F0–0x1F7`, IRQ 14, via the RF5C396 PCIC) | Why big CF cards fail: the BIOS has **no `INT 13h` extensions (no LBA)** and **never issues ATA `IDENTIFY`** — it only sends diagnostic/seek/read and reports a ~3.85 MB stub geometry, so Windows 95 bypasses it entirely. Includes ranked causes of the ~4 GB limit, workarounds, and the LBA fixes. |
| **Trackpoint** | **U75** — NEC **µPD17137A** trackpad controller | The 4-bit MCU (SSOP-28) that scans the pointing-device pad and reports over a PS/2-style interface; part, net map, and pinout. |
| **Debug** | CPU debug headers (J9 / J12 / JTAG) | Pinouts of the 80486SX debug/ICE headers and JTAG TAP, what they're for, and a homebrew modern debug-pod design. Includes pod source (`pc110_debug_pod.c`). |

## Conventions

Analyses use a confidence key throughout:

- ✅ **Verified** — read directly from firmware, a ROM dump, or a fully traced schematic net.
- 🟡 **Strongly inferred** — consistent with evidence and standard practice, not independently confirmed.
- ⚠️ **Assumption** — plausible but unverified; confirm on the bench against a known-good unit.

Some chapters also tag provenance: **[DS]** datasheet of an architectural twin, **[PAT]** patents, **[DECAP]** die analysis, **[RE]** reverse-engineered pin map / board, **[BIOS]** BIOS disassembly, **[H]** hypothesis.

> These materials are **unofficial**. IBM never published board-level schematics or datasheets for the PC110's custom silicon. Work on these boards at your own risk, observe ESD precautions, and never assume a board is fully "off" while powered.

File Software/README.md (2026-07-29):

# Software

DOS tools for the IBM PalmTop PC110, plus the host-side bridge used to drive one over a serial link.
All are small, dependency-free real-mode `.COM` programs (except COMrade, which runs on the host),
hand-written in assembly and built with NASM.

| Tool | What it is |
|---|---|
| **[PS2TUI](PS2TUI/)** | Full-screen text-UI **system manager** — replaces IBM's cryptic `PS2.EXE` switches with a two-level menu, reads live battery/settings natively (APM + CMOS), and adds ROM/CMOS dumps, hardware diagnostics, system tests, and the BIOS-flash features. |
| **[PS2GUI](PS2GUI/)** | A **graphical** fork of PS2TUI that reproduces IBM's *Easy-Setup* skin in VGA mode 12h — icon grid, exact palette, mouse support with the authentic duck cursor. Same engine and features. |
| **[SCAMPRD2](SCAMPRD2/)** | **Read-only** chipset probe: dumps the VL82C420 EC/ED config window (`0x00–0x0F`) + a Pluto strap byte. This is how a PC110's **installed RAM module is identified** (`eced[0x03]`). Produced the live data behind `Discovery/RAM-Module` §7.4. |
| **[ESSPROBE](ESSPROBE/)** | **Read-only** audio-chip identification: SB DSP version, the ESS family ID (`0xE7`), and a mixer dump. Confirmed live that the fitted part self-IDs as **ES488** (`0x48`) running as **SB 2.0** (DSP `2.01`) with no mixer decoded — see `Discovery/ES488` §9. |
| **[FNTEST](FNTEST/)** | **Read-only** raw-scancode monitor (`INT 9` hook). Built to settle empirically whether pressing **`Fn`** produces anything the host can see — see `Discovery/Keyboard` §6.4. |
| **[COMrade](COMrade/)** | Host-side **serial bridge / MCP server** to a resident DOS agent on the PC110: screen and console capture, keystroke injection, file transfer with CRC verification, and memory/I-O access. Used for most of the live reverse-engineering in `Discovery`. |

## Related

BIOS-patching tools live under [`Mods/`](../Mods/) rather than here, because they carry the
brick-risk warnings and the hardware prerequisites:

- **[`Mods/BIOS-Multi-Patcher`](../Mods/BIOS-Multi-Patcher/)** — `PCPATCH.COM`, one menu for every known
  BIOS mod (DSTN↔TFT, Windows 256-colour, 32 MB memory patch enable/remove) plus a **read-only
  diagnosis** of which patches a machine currently has.
- **[`Mods/32MB-Memory-BIOS-Patch`](../Mods/32MB-Memory-BIOS-Patch/)** — the standalone 17-byte
  memory-cap patch and a reproducible builder.
- **[`Mods/TFT/bios-patch`](../Mods/TFT/bios-patch/)** — the reproducible DSTN→TFT video-BIOS patch.

> ⚠️ Anything that **writes** the BIOS flash needs A/C **and** a battery ≥ 20 % installed, **and** a boot
> from a floppy in an IBM-marked drive (the 12 V VPP interlock). See
> [`Discovery/BIOS-Flash`](../Discovery/BIOS-Flash/readme.md) §7. The read-only tools above have no such
> requirement.

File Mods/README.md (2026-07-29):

# Modifications

> 🗺️ **New here? Start with the [Modernization roadmap](ROADMAP.md)** — a ranked, opinionated list of
> the mods worth doing (with effort/risk, what our reverse engineering already de-risks, and the traps
> and hard limits to know before you plan).

Hardware modifications and redesigns for the IBM PC110 palmtop. Each folder is a self-contained project, mostly KiCad/Altium PCB designs, with its own `README.md` and screenshots.

## Projects

### PC110-ITX
An ITX form factor motherboard that reimplements all of the PC110 components, with the original BGA parts converted to QFP alternatives for easier assembly. Full KiCad project with per-block schematics (Processor, Chipset, ASIC, Memory, ROM, VGA, Audio, PCMCIA, Storage, Power, Clock, Super I/O, Keyboard, Dock). Includes netlist, placement, and 3D render views.

### PC110-ITX-all-in-one
A variant of the ITX board that blends the motherboard and the docking station's PSU board into a single all-in-one design. Same KiCad block structure as PC110-ITX, plus the docking station ports and footprints.

### CPU Upgrade
Work toward upgrading the PC110 CPU using a BGA-to-socket adapter board (`pcb-bga-adapter`, plus dual-connector variants). Includes KiCad adapter projects, datasheets, and 3D models. References Taka's 230cs CPU upgrade, which shares the VL82C420 design with the PC110.

### NewDock
A redesigned docking station as a standalone KiCad project (`DockingStation`).

### RAS4
A modification that enables an extra 4MB of internal RAM by repurposing the `VL_D12` line as `RAS#4` on the schematic. Documented with annotated schematic captures.

### BIOS-Multi-Patcher
`PCPATCH.COM` — one DOS tool that applies (and where possible reverses) every known PC110 BIOS mod from a single menu: **DSTN↔TFT** display, **Windows 256-colour** fix, and **32 MB memory patch enable/remove**. Flash sequence byte-identical to `vpatch`; reflashes only the 96 KB main block (boot block preserved); CS-relative staging + pre-flash verification. **⚠️ VALIDATION REQUIRED** and requires booting from an IBM-marked floppy (12 V VPP interlock — see `Discovery/BIOS-Flash` §7).

### 32MB-Memory-BIOS-Patch
A **firmware** memory-expansion mod: a 17-byte BIOS patch that caps POST's extended-memory count so a PC110 populated beyond the stock 20 MB (e.g. a 16+16 MB module) cold-boots cleanly, without the RC circuit / `DARK2301` warm-boot dance of the classic taka 32 MB hack. Includes a reproducible build script and pre-built 256 KB / 96 KB images, flashable via the PS2GUI/PS2TUI "Flash BIOS" feature. **⚠️ VALIDATION REQUIRED — verified by disassembly + emulator only, never flashed to real hardware.**

### TFT
TFT display replacement work, including the TFT Upgrade Kit's BIOS patch floppy (`BIOS_Patch.img`) and a reproducible form of the same DSTN→TFT video-BIOS patch in [`TFT/bios-patch`](TFT/bios-patch) (builder + 18-byte patch spec, decoded in `Discovery/65535` §6c). **⚠️ VALIDATION REQUIRED**; a reverse TFT→DSTN patch is pending a confirmed unpatched-DSTN dump.

### Altium
The PCB projects converted from KiCad to Altium, to add versatility and make Altium's tooling available to the project.

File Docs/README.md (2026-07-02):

# A Tribute to the IBM PC110

WhatsApp Image 2026-06-18 at 18 43 05

Here is a picture of Kevin Moonlight and Ahmad Byagowi showcasing the recreated schematic of the PC110 during VCF2025. 

## A Deep Dive into Silicon, Sandpaper, and Secrets of the IBM PC110

**Reverse engineering the beloved IBM PC110, a 486SX-based subnotebook from the 90s, released exclusively in Japan with custom repackaged BGA chips, custom ASICs, and an attractive form factor.**

---

## Introduction: A Palm-Sized Powerhouse

The **IBM PC110**, released exclusively in **Japan in 1995**, was one of the smallest fully functional x86 systems ever made by IBM. This palmtop computer crammed a 486SX CPU, a CHIPS 65535 VGA chip, two PCMCIA slots, a CF card, and more great features into something that fits on top of your palm.

Despite rumors of an **English-language or U.S. release**, no such version ever reached the market. The project was reportedly in development but was quietly shelved, making the IBM PC110 unique and **regionally rare and historically mysterious**.

What fascinated me wasn’t just the size—it was the story under the keyboard: repackaged BGA packages and chips with no public documentation, the usage of camcorder batteries instead of a proprietary battery, and a CF card slot which made the machine sort of future proof and relevant to be "practical", even today. 

Unfortunately, most of the IBM PC110s ended up breaking down over time due to the leak of the bridge battery, causing corrosion and destroying the circuit board. It was heartbreaking to see those laptops end up in the landfill helplessly.  

So I decided to **reverse engineer the entire machine**. That journey involved **sandpaper**, **ROM dumps**, **laser decapping**, **high-resolution die photos**, and the help of some brilliant hardware and software hackers. What I found includes rare chipsets, custom logic arrays, and design decisions that were both *visionary* and *tragically destructive*.

---

## A Design Ahead of Its Time and One Fatal Flaw

The PC110 had forward-thinking design features, including:

- A **standard camcorder battery** (still sold on Amazon today)
- A **CompactFlash card slot**, used as its primary storage drive

These were remarkable decisions in 1995, long before CF replaced spinning disks in industrial systems.

But the system had a fatal flaw:  
A small **NiMH-based bridge battery**, placed internally, which was designed to maintain power between main battery swaps.
This was mainly because the internal PSU was unable to charge the battery while the machine was operating (things we take for granted with today's laptops). Therefore, the bridge battery was placed there to keep the machine running for about 2 minutes while you perform a battery swap.

Over time, that battery becomes a **ticking time bomb**.  
As it fails, it **leaks potassium hydroxide (KOH)**, a highly corrosive chemical that **destroys PCB traces**, **eats through components**, and **wrecks solder joints**.  
It’s the leading cause of death for otherwise restorable PC110 units today.

---

## Sanding a 10-Layer PCB — With a Flatbed Scanner

To begin understanding the system, I took the hard and destructive, yet necessary route:  
I **sanded the motherboard** down layer by layer.

The board is just **1.0mm thick**, with **10 copper layers**, each ~**70 microns**. I used **ultra-fine grit sandpaper** to remove layers delicately, scanning the exposed surface after each pass with a **high-resolution flatbed scanner**.

It was slow, imperfect, and occasionally damaging—but it worked. By the end, I had a full stack of perfectly aligned copper layers. Because I made several mistakes during the sanding and went too far, especially as I progressed through the layers, I had to sacrifice a second PCB, this time by sanding it from the other side.

---

## Reconstructing the Board in KiCad

With the scanned layers imported into **KiCad**, I aligned them and manually traced:

- Every net  
- Every via (through and blind)  
- Every component pad  
- Every trace/track  
- Every power polygon  
- Many more details  

Bit by bit, the **entire circuit** came together. I gave up many times in the middle due to some complexity or unresolved issues, but each time, I returned and continued. Some traces were incomplete or degraded, but logic and redundancy allowed me to **reconstruct the full schematic** of the system. Some tracks even appeared to go nowhere—perhaps used for debugging or cut later by the manufacturer. Who knows what software IBM used in the mid-90s; certainly not KiCad.

---

## Schematic Extraction and Deep System Insight

After the layout was reconstructed and the parts were identified, I began to **extract the schematic**, piece by piece.  
I organized different **subsystems** into separate schematic sheets, including:

- Clock Tree  
- CPU and debug port  
- Chipset and RTC  
- VGA controller  
- RAM interface  
- ROM and BIOS  
- ASICs  
- Super IO (FDD, Serial, LPT)  
- Power and charging logic  
- PCMCIA controller  
- Audio and FM Synthesizer  
- Storage and CF slot  
- Keyboard/PS2  
- IRDA and Docking station connector  

This gave me exceptional insight into **how IBM and RIOS Systems engineered this device**. After extracting the full schematic, I linked it back to the layout to identify and resolve discrepancies.  

The result is a schematic that **perfectly reflects the physical PCB** — signal-for-signal.

---

## Why This Schematic Unlocks the Future

With a fully accurate schematic and layout, this project now enables:

- **Redesigning the motherboard** with modern components  
- **Changing the form factor** entirely (e.g., vertical/landscape designs)  
- **Creating a Raspberry Pi-based recreation**  
- **Hardware diagnostics and repair**  
- **Upgrades and mods**, including custom RAM cards, new docks, and embedded devices

---

## The Known and Unknown Silicon

Identified components:

- **Intel 80486SX** CPU  
- **CHIPS65535** VGA controller  
- **Ricoh RB5C396** PCMCIA bridge  
- **FDC37C665IR** for FDD, Serial, LPT  
- **SC414281PU4** Storage Controller  
- Various logic ICs

Mysterious components:

- **VL82C420** – part of the SCAMP IV chipset, no datasheet available  
- **ES488** – no datasheet found; To recover the pinout, we purchased an old ISA sound card based on the ES488 and carefully traced all the connections from the ISA bus to the chip. This revealed almost the entire pinout and, in turn, helped us determine the ISA bus pinout of the PC110 motherboard.
- **IBM “Pluto” and “Bowman” ASICs**

The VL82C420 integrates 6 known chips (VL82C59s, VL82C37s, VL82C54, VL82C018) and a custom gate array.

---

## Decapping Chips with CLC and John McMaster

With Fred Nielsen from **CLC**, we decapped the VL82C420, Pluto, and Bowman using a laser-driven photo-chemical process.  
**John McMaster** provided high-resolution die imaging.

### Inside the VL82C420

- 2× VL82C59 (Interrupt Controller)  
- 2× VL82C37 (DMA Controller)  
- 1× VL82C54 (Timer)  
- 1× VL82C018 (RTC)  
- Integrated gate array  
- BGA packaging custom-made by RIOS

### Pluto and Bowman

IBM-designed gate arrays responsible for:

- Power sequencing  
- Interrupt control  
- ISA and docking logic  
- System glue logic

---

## PSU, Modem, and Docking Station Reverse Engineering

Reverse-engineering the PSU, modem, and docking station enabled:

- Full **pinout mapping**  
- Verification of unknown connector functions  
- Potential for **custom modern docks**

---

## Embedded Microcontrollers and ROM Extraction

| Chip | Function |
|---|---|
| **M38223** | Power sequencing |
| **M3881** | Keyboard & PS/2 |
| **D17137AGT**  | TrackPoint controller |

ROMs for M38223 and M3881 were extracted (thanks to **Kevin Moonlight**).  
**D17137AGT** was imaged optically but not visually decoded.

---

## Everything is Open-Source

GitHub Repo: [https://github.com/ahmadexp/Open-Source-PC110](https://github.com/ahmadexp/Open-Source-PC110)

### Contents

- `/scans/` — 10-layer PCB scans  
- `/kicad/` — Full KiCad schematic/layout  
- `/rom_dumps/` — ROM binaries  
- `/die_images/` — Die photographs  
- `/pinouts/` — Pin mappings  
- `/notes/` — Research notes

---

## What You Can Do

- Rebuild or modify the hardware  
- Use for emulation or form factor experiments  
- Study VL82C420 and ES488  
- Build docks, RAM, and CF replacements  
- Contribute firmware or ROM analysis

---

## Thanks and Acknowledgements

This project would not have been possible without:

- **Kevin Moonlight** — for microcontroller ROM extraction  
- **Mike Lycett** — for organizing the fundraiser, coordinating the effort, and promoting the project  
- **Nick Rogers** — for debugging and verification  
- **John McMaster** — for high-resolution die imaging and technical consultation  
- **CLC** — for decapping services and silicon prep  
- The **open hardware & retrocomputing community** — for encouragement, contributions, and documentation support

---

## Featured on Hackaday

Read the article: [https://hackaday.com/2025/04/06/reverse-engineering-the-ibm-pc110-one-pcb-at-a-time/](https://hackaday.com/2025/04/06/reverse-engineering-the-ibm-pc110-one-pcb-at-a-time/)

> “The kind of project that goes beyond repair — it preserves design history, reveals hidden hardware, and makes future restoration possible.”

---

## Stay Updated

- GitHub: [ahmadexp/Open-Source-PC110](https://github.com/ahmadexp/Open-Source-PC110)  
- Contact: Ahmad Byagowi / [@ahmadexp](https://github.com/ahmadexp)  
- YouTube video coming soon!

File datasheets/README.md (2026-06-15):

# Datasheets

A collection of datasheets, pinouts, and reference material for the chips and connectors found on the IBM PC110 (PalmTop PC) board and its peripherals.

Files are organized by board area or subsystem. PDFs are the original component datasheets; `.png`/`.jpg`/`.tif` files are pinouts, connector maps, and board photos used to identify parts. Where a part is marked with only a short SMD code on the silkscreen, the filename uses that code and the relevant README maps it to a full part number.

## Folder structure

| Folder | Contents |
|---|---|
| [`top/`](top/) | Components on the **top** layer of the motherboard, plus connector pinouts (RAM, LCD, docking, power). |
| [`bottom/`](bottom/) | Components on the **bottom** layer, including the i486SX CPU, VL82C420 chipset, CHIPS 65535 LCD controller, and BGA ball maps. |
| [`generic/`](generic/) | Small generic parts (transistors, regulators, logic) identified by SMD marking code. See the code→part-number table in the folder README. |
| [`Modem/`](Modem/) | Components on the modem board, including the modem connector and scanner pinout. |
| [`PSU/`](PSU/) | Power supply parts (regulators, controllers such as MAX786). |
| [`LCD/`](LCD/) | LCD panel datasheets, backlight, and the L6481L driver pinout. |
| [`DockingStation/`](DockingStation/) | Components on the docking station (LT1237, DS14C535). |
| [`VL82C420/`](VL82C420/) | Datasheets for the VL82C420 chipset's integrated peripheral cores (82C37 DMA, 82C54 timer, 82C59 interrupt controller, 82C018). |
| [`16MB-RAM/`](16MB-RAM/) | RAM chip datasheet (HM51W1788) used on the 16MB memory module. |

## Notable parts

- **CPU:** Intel i486SX-33 (`bottom/4-486SX-33.pdf`), with bond/die and BGA ball-map diagrams.
- **Chipset:** VL82C420 single-chip AT controller (`bottom/3-VL82C420.pdf`).
- **Video:** Chips & Technologies 65535 LCD/CRT controller (`bottom/2-CHIPS65535.pdf`).
- **Sound:** Yamaha YM3812 (OPL2) with Y3014 DAC (`top/7-YM3812.pdf`, `bottom/9-Y3014.pdf`).
- **I/O:** SMC FDC37C665IR super-I/O controller (`top/5-FDC37C665IR.pdf`).
- **Flash/BIOS:** Intel 28F002 / 28F200BX flash (`bottom/7-28F200BX-TB.PDF`).
- **IrDA:** HP HSDL-1000 infrared transceiver (`top/HSDL-1000.PDF`).

## Connector references

Connector pinouts are kept alongside the boards they belong to: RAM, LCD, docking, and power connectors in `top/`; the modem and scanner connectors in `Modem/`.

## Naming conventions

- Numeric prefixes (e.g. `4-486SX-33.pdf`, `2-CHIPS65535.pdf`) correspond to the part reference numbers marked on the board diagrams (`top-parts.tif`, `bottom-parts-complete.tif`).
- Single-letter prefixes (e.g. `a-sn74ls123.pdf`, `b-v74.pdf`) mark smaller logic/glue parts.
- Files in `generic/` are named by their SMD marking code; the folder README contains the code-to-part-number lookup table.

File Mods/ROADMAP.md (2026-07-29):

# Modernization roadmap — pushing the PC110 to the next level

An opinionated, ranked list of hardware (and firmware) mods that make a PC110 genuinely nicer to use
with today's parts — each one grounded in what this project's reverse engineering has already
established, so you know what is de-risked and what is still a research problem.

Three things recently changed what is realistic:

1. **A working in-system BIOS flasher** with patch / undo / diagnose ([`Mods/BIOS-Multi-Patcher`](BIOS-Multi-Patcher/)).
2. **Net-level schematics** for every board ([`PCB/`](../PCB/)), traced pin-by-pin.
3. **Firmware disassemblies** for the power MCU, the keyboard controller, and the BIOS memory sizer
   ([`Discovery/`](../Discovery/)).

That turns several "someday" ideas into weekend projects.

Effort/risk key: 🟢 low · 🟡 moderate · 🔴 high (irreversible or needs BGA/SMD rework)

---

## Tier 1 — do these first (high reward, low risk, mostly solved)

### 1. 28 MB RAM 🟢
The single biggest usability jump; Windows 95 on 28 MB vs 20 MB is a different machine. Two routes,
both now understood:

- **16 + 8 MB module = 28 MB on a bone-stock BIOS.** The POST sizer is **probe-based**, not table-based,
  and natively produces geometry codes `D` (16 MB) + `C` (8 MB) — no patch, no RC circuit, no
  `DARK2301`.
- **16 + 16 MB module + our count-cap patch** ([`Mods/32MB-Memory-BIOS-Patch`](32MB-Memory-BIOS-Patch/)).

**What we have:** the DRAM geometry decode (`eced[0x02]`/`[0x03]`, confirmed on 3 units), the patch, its
undo, and a detector. → [`Discovery/RAM-Module`](../Discovery/RAM-Module/readme.md) §7, [`Software/SCAMPRD2`](../Software/SCAMPRD2/)

### 2. TFT panel conversion (+ Windows 256-colour fix) 🟢
The DSTN is the worst thing about using a PC110 — viewing angle, ghosting, contrast. Now fully
**bidirectional**: the 18-byte XR patch, the **confirmed stock DSTN baseline**, the reverse patch, and a
detector that reports which state a machine is in. Flash the 256-colour fix (`0x1CB = 0x1F`) in the same
pass. → [`Discovery/65535`](../Discovery/65535/readme.md) §6c/§6c.1, [`Mods/TFT`](TFT/)

### 3. Internal ESP32 "WiFi modem" 🟢
Cheapest modern win by far. An ESP32 speaking Hayes-AT over the internal serial gives telnet/BBS
immediately, and with SLIP/PPP real TCP/IP under mTCP. Mount it **inside**, wired at **TTL** (skip the
RS-232 transceivers), powered from 3.3 V. Pluto muxes COM1/COM2 and the internal modem already sits at
COM2/`0x2F8`, so there is a free port to claim. → [`Discovery/Pluto`](../Discovery/Pluto/readme.md), [`Discovery/Modem`](../Discovery/Modem/readme.md)

### 4. CF / SD storage 🟢
Largely solved via the card slot, but worth doing deliberately: a modern CF gives a big FAT16 volume and
removes the original flash-disk wear risk. → [`Discovery/Live-Dump`](../Discovery/Live-Dump/) (ATA/CHS findings)

---

## Tier 2 — real projects with big payoff

### 5. Li-ion + USB-C PD conversion 🟡
Runtime and convenience, and we are unusually well armed: full PSU schematic, the J5/J3 connector map
**both sides**, MAX786 details (incl. ESR-critical caps), `ULTRACHG`'s charge logic, and the M38223
power-MCU firmware.

> **Two constraints our RE exposes — plan around them:**
> - The power MCU's battery sense feeds **both** the front-LCD gauge (rendered from `$70/$71`) **and**
>   the APM `530A` charge percentage. A bogus percentage has real consequences: the BIOS flasher
>   **refuses to run below 20 %** — we hit exactly this on a bench unit reporting 0 %.
> - **Keep the 12 V rail alive.** It feeds PCMCIA VPP *and* the BIOS-flash VPP. A naive 5 V-only USB-C
>   conversion silently destroys your ability to reflash.

→ [`Discovery/PSU-MB-M38`](../Discovery/PSU-MB-M38/readme.md), [`Discovery/Power-Sequence`](../Discovery/Power-Sequence/), [`Discovery/BIOS-Flash`](../Discovery/BIOS-Flash/readme.md) §7

### 6. Modern IPS panel via a parallel-RGB bridge 🟡
Potentially the best-looking result of any mod. The F65535 flat-panel port is 15-bit RGB
(`LCD_R0-4/G0-4/B0-4`) plus `SHFCLK`, `LP`, `FLM`, `M`, `STNDBY#` — and after the TFT patch it runs a
**25 MHz dot clock at 640×480**, essentially standard VGA timing. Many small IPS panels accept 24-bit
parallel RGB in that range, so the "bridge" may reduce to **level shifting and padding 5:5:5 → 8:8:8**
— no FPGA required. A CPLD is only needed for scaling or a different native resolution.
→ [`Discovery/65535`](../Discovery/65535/readme.md) §3d (pinout) + §6b (timing registers)

### 7. RP2040 replacing the M38813 keyboard controller 🟡
Feasible now because the original firmware is disassembled: **19 rows × 8 columns**, key index =
`row*8 + bit`, three scancode-set tables, the `E0`-prefix attribute table, and the 8042-style host
interface through Pluto (`KB_CCS`, `KB_CNTR#`, `KB_RESET#`). Payoff: full remapping, a **sane Fn layer**,
macros — and since the trackpad is a standard PS/2 mouse, pointer handling could fold in too. Doubles as
the repair path if a KBC dies. → [`Discovery/Keyboard`](../Discovery/Keyboard/readme.md) §6, [`Discovery/Pluto`](../Discovery/Pluto/readme.md), [`Discovery/Trackpoint`](../Discovery/Trackpoint/)

### 8. RP2040 on the internal ISA bus — emulate new devices 🟡
The PC110 has a **real internal ISA bus** (not just Bowman's ML/companion path): `SA`/`LA`/`SD`,
`MEMR#`/`MEMW#`, `IOR#`/`IOW#`, `BALE`, `SBHE#`, `MEMCS16#`, `IOCS16#`, `REFRESH#` and an 8 MHz
`ISA_SYSCLK`. RP2040-on-ISA device emulation is proven art on desktops (**PicoGUS**), and one PC110
detail makes it much easier than expected:

> **`IOCHRDY` is present** ([`Discovery/Chipset`](../Discovery/Chipset/readme.md) §6). You can **stretch
> bus cycles**, so the RP2040 does not have to meet hard ISA setup times — it can hold the CPU until
> ready. That turns the timing problem from "tight" into "comfortable."
>
> **But not at the U4 footprint.** The ES488's 52-pin package has **no `IOCHRDY` pin**
> ([`Discovery/ES488`](../Discovery/ES488/readme.md) §3), so a tap *or* a replacement there gets
> cycle-stretching only by running **one extra wire** to `IOCHRDY` on the bus proper. Budget for it,
> or plan to meet real 8 MHz ISA I/O timing (PicoGUS does, so it is possible — just not lazy).

**Best tap point: the ES488F audio chip (U4).** It is a 52-pin QFP ISA device carrying `A0–A9`
(= `SA1–SA9`), `IOR`, `IOW`, `AEN`, `IRQ1`, `IRQ2` and `DACK1#`, with data through HD151015
transceivers — **a complete 8-bit ISA I/O interface in one physical location**, and we have the
schematic crops plus a mainboard net dump for exactly that block.
→ [`Discovery/ES488`](../Discovery/ES488/readme.md)

**Two constraints our RE surfaces — design around them:**

- Those **HD151015s are documented as 5 V↔3.3 V level translators**, so *which side you tap decides your
  level-shifting bill*. The peripheral side may already be 3.3 V (RP2040-friendly). **Measure first.**
- **Skip DMA.** `AEN` comes from Pluto (`Pluto_ESS_AEN`) and `DACK1#` from Bowman
  (`Bowman_ESS_DACK1#`) — bus arbitration is produced by the custom gate arrays, not a standard
  82C206, and those cannot be reprogrammed. Target **8-bit, I/O-mapped, IRQ-driven** devices only.

Scoped that way it is ~22 signals rather than 40. Free I/O windows are pickable from the live port map,
and **IRQ 10/11 look available** (5 = audio, 9 = PC Card, 12 = pointer, 14 = ATA).
→ [`Discovery/Live-Dump`](../Discovery/Live-Dump/)

**What is worth emulating, ranked:**

1. **NE2000 + WiFi** — strictly better than the serial-modem route (#3): standard DOS packet drivers,
   mTCP, real throughput. Needs a Pico W/CYW43 or an ESP32 companion for the radio.
2. **Option ROM + SD-backed disk** — an "XT-IDE for PC110". This is also **the fix for the CF size
   limit**, because it supplies the `INT 13h` extensions the stock BIOS lacks.
   → [`Discovery/Storage`](../Discovery/Storage/readme.md)
3. **Sound — see #9 instead.** An earlier version of this item dismissed audio on the grounds that the
   machine "already has SB Pro." **That was wrong**: the live probe found the ES488 running as
   **SB 2.0** — mono, 8-bit, mixer registers all reading `0xFF`
   ([`Discovery/ES488`](../Discovery/ES488/readme.md) §9). There *is* a ceiling worth raising, but the
   way to raise it is to **take the socket** rather than tap it — which is item **#9**.

**Space:** removing the internal modem module frees a whole bay. (Its 26-pin connector carries serial,
not ISA — space only, not a bus tap.) → [`Discovery/Modem`](../Discovery/Modem/readme.md)

### 9. RP2350 **replacing** the ES488 (U4) — a programmable sound card 🟡
The same physical location as #8, but the opposite relationship to the chip: **remove U4 and take its
footprint** instead of soldering alongside it. That single change buys more than tapping does, because
you inherit everything the board already provides to that socket:

- the full 8-bit ISA I/O interface (`A0–A9`, `D0–D7`, `IOR`, `IOW`, `AEN`, `RESET`)
- an **IRQ** line (via `R29`) **and a working DMA channel** (`DRDY` + `DACK1#`)
- **the entire analogue back-end** — drive pin 9 (`LineOut`) and your audio flows through `C18` → `R34`
  → the NJM3414A summing mixer → the DS1669 volume pot → the LM4861 BTL amp → speaker, with
  headphone-mute already working. You inherit a tuned output stage *and* the physical volume buttons.
  → [`Discovery/ES488`](../Discovery/ES488/readme.md) §8

> **#8's "skip DMA" constraint does not apply here.** That warning exists because `AEN` (Pluto) and
> `DACK1#` (Bowman) are produced by gate arrays you cannot reprogram — but in this socket **you *are*
> the device those gate arrays were already wired to serve**, so DMA channel 1 works as designed.
> This matters: streaming PCM wants DMA.

**Pin budget** ≈ 28: 10 address + 8 data + 4 (`IOR`/`IOW`/`AEN`/`RESET`) + 3 (`DRDY`/`DACK1#`/IRQ) +
1 `DIR` (you must drive the YM3812's chip select — §8.2 there) + 2–3 for PWM audio out and mic in. An
RP2040's 30 GPIO technically fits but leaves nothing for a debug UART, so **RP2350B (48 GPIO) is the
right part**; RP2040 only if you drop the second IRQ and the game port.

**The payoff:** present **SB Pro or SB16** where the fitted part only ever did **SB 2.0** — stereo,
16-bit, a real mixer. Keep the genuine YM3812 for authentic OPL2 (you have to drive its `CS#` anyway),
*or* ignore it and emulate OPL3 on the second core for more voices. MPU-401 MIDI is nearly free.
**PicoGUS** is direct precedent for all of it, so most firmware is ported rather than invented.

**Five things to settle first:**

1. **Measure `PNET5`.** U4 shares it with the HD151015 `VCCB`, i.e. **U4 sits on the *translated* side**
   of those 5 V↔3.3 V transceivers. If PNET5 is 3.3 V an RP2350 connects nearly directly and the
   level-shifting problem largely evaporates. This one measurement swings the whole design.
2. **No `IOCHRDY` at this footprint** — see the caveat in #8. One extra wire, or meet real ISA timing.
3. **Clock:** `X2` suits the ES488, not an RP2040. Put a 12 MHz crystal on the adapter.
4. **Analogue level:** 3.3 V p-p PWM is far hotter than the line level the mixer expects into
   `C18`/`R34`. A divider fixes it — get it right or you clip the LM4861.
5. **Boot time vs POST:** the RP2040 needs ~100–300 ms from flash; POST takes seconds, so this is
   probably fine, but a very early probe of `0x220` could miss.

**What you give up:** the ES488 as a fallback, and mic recording unless you wire the mic into the MCU's
ADC. **This supersedes the ES1488 swap** — same mechanical work, but instead of hoping a part is
pin-compatible, *you* define the mapping.
→ [`Discovery/ES488`](../Discovery/ES488/readme.md) §11

### 10. CPU upgrade — 486DX / DX2 / DX4 / Am5x86 (and the only way to get an FPU) 🔴
Biggest raw-performance mod, and you gain an **FPU** over the SX. Adapter groundwork exists in
[`Mods/CPU Upgrade`](CPU%20Upgrade/), with taka's 230cs as precedent. Be clear-eyed: BGA rework, a new
VRM, 3.3 V vs 5 V, SCAMP IV clocking, and thermals in a fanless palmtop.

| Question | Status |
|---|---|
| **Package/ballout** — does a 486DX exist in the same **BGA256** footprint? | **The key unknown.** Check the Intel 486 databook already in [`CPU Upgrade/datasheets/`](CPU%20Upgrade/datasheets/) |
| **CPU rail voltage** | measure before choosing a part (DX4 / Am5x86 are 3.3 V) |
| **Thermals** | a plain **486DX-33** is the conservative FPU choice; DX2/DX4/5x86 add real heat with no fan |
| **Adapter** | the existing BGA-to-socket adapter work relaxes the package constraint |
| **Bus speed** | clock multiplication is internal, so the 33 MHz bus and SCAMP IV timing are unaffected |

#### 9.1 You cannot *add* an FPU to a 486 — you must replace the CPU
The 386 had a genuine external coprocessor interface (the 387 sat on dedicated CPU-local signals).
**The 486 does not** — the FPU is on-die. The 486SX's "upgrade", the Intel **487SX** (and later
OverDrive parts), was really *a complete 486DX that took over the bus* and disabled the SX, in a
dedicated second socket. The PC110 has neither that socket nor any coprocessor bus, and an FPU
**cannot** be hung off the ISA bus — there is no protocol for it. So: DX-class CPU swap, or nothing.

#### 9.2 The BIOS is already FPU-ready — no firmware work needed  ✅ **[RE 2026-07-28]**
Encouragingly, the firmware was clearly written for an FPU-equipped sibling machine. Found in the
flash image:

- **A complete FPU detection routine at `F000:6F17`** — the textbook sequence:
  `out 0xF0` (clear the coprocessor error/busy latch) → `FNINIT` → poison the status slot with `0x5A5A`
  → `FNSTSW` (a real FPU writes `0x00` low byte) → `FNSTCW` and compare the default control word
  (`& 0x0F3F == 0x033F`, i.e. `0x037F`) → `FLD1`/`FLDZ`/`FDIVP`/`FLD ST0` divide-by-zero check, with a
  distinct "no FPU" branch at `0x6F90`.
- **An IRQ13 coprocessor-error handler at `F000:EB77`** — `out 0xF0` to clear the latch, `out 0xA0,0x20`
  EOI to PIC2.
- **Real x87 diagnostics in the LZW-compressed region** — 43 × `FNINIT`, plus `FSQRT`, `FLDPI`,
  `FNSAVE`, `FLDCW`.
- Consistent with a machine that has **no** FPU fitted: **IRQ13 is currently masked** in PIC2
  ([`Discovery/Live-Dump`](../Discovery/Live-Dump/)).

**So a DX swap needs no BIOS patching**: POST will detect the FPU, set the equipment-word bit, and the
IRQ13 path already exists.

#### 9.3 If you only need FPU *compatibility*, do this instead 🟢
For software that **requires** an FPU (rather than software you want to be *fast*), a DOS x87 emulator
— `EMU387`, `Q387`, `WEMU387`, DJGPP's `emu387` — hooks the coprocessor-absent exception (`#NM`, INT 7)
and emulates x87 in software. Zero hardware risk, reversible, and it is how 486SX owners handled this in
period. Roughly an order of magnitude slower than real hardware, which is irrelevant if the alternative
is "won't run at all". Windows 3.1/95 also carry their own emulation paths.

**Recommendation:** try the emulator first — it settles whether you actually need the silicon. If you
later swap the CPU for *speed*, the FPU arrives as a bonus, and the BIOS will welcome it unmodified.

---

## Tier 3 — moonshots

### 11. Replace the M38223 power MCU (U6) — repair path *and* the key to Li-ion 🟡/⚠️
Of all the "replace a custom part" ideas this is the **most feasible**, because U6's interface is small
and we have both a full firmware disassembly **and an emulator** to develop against.

**What U6 has to do** — from [`Discovery/PSU-MB-M38`](../Discovery/PSU-MB-M38/readme.md) and
[`Discovery/Power-Sequence`](../Discovery/Power-Sequence/):

| Function | Pins |
|---|---|
| Front status LCD | 14 (`SEG0–9` + `COM3–0`) |
| Battery/charger analog sense | 4 (`P60/AN0`, `P61/AN1`, `P63/AN3`, `P64/AN4`) + `VREF`, via PSU op-amps U6A–U6D |
| **Main power enable** | `P52/RTP0` → Q4 → switches the `PWR_IN_10v5` rail |
| Control output ("BLR") | `P53/RTP1` → Q31/Q33 |
| Host handshake | `P20` (bidirectional request) + `P21` (response) |
| Power-button wake | `P5.1` / `INT3` |

**≈25–30 signals** — inside an RP2040's 30 GPIO, roomy on an RP2350B's 48. (For contrast, the 486
local bus needs 70–80 signals, which is one of the reasons an MCU cannot stand in for the *CPU*.)

**Why bother — two strong reasons:**

1. **Repairability.** These are almost certainly **OTP** parts (the sibling KBC is confirmed
   *"M38813E4HP … with OTPROM"*). You cannot reprogram the original and cannot buy blanks — and U6 is
   the **power-on gatekeeper**, so a dead U6 means a **permanently dead PC110**. A modern replacement is
   the only repair path, and it is far easier than the Bowman/Pluto moonshot (#12).
2. **It is the missing half of the Li-ion conversion (#5).** The charge algorithm and fuel gauge live in
   *this* firmware, written for the original chemistry. Replacing U6 is how you get proper **CC/CV Li-ion
   charging** *and* an honest **APM percentage** — which matters concretely, because the APM charge
   percentage **gates BIOS flashing** ([`Discovery/BIOS-Flash`](../Discovery/BIOS-Flash/readme.md) §7.3).

**What already de-risks it:** a full disassembly **plus** the `m38223_emu` emulator as a *golden
reference model* ([`Components/Flash/M38223E4HP/`](../Components/Flash/M38223E4HP/)); the complete
power-on sequence (standby rail keeps U6 in STOP → button pulls `P5.1`/`INT3` → wake → check battery →
drive enables → handshake `P20`/`P21` → the 74HC74 U54 latches power state); the **fully decoded front
LCD** (1/4 duty, 1/3 bias, font table, gauge rendered from `$70/$71`); and a **Saleae rig** for capturing
the original's real behaviour before reproducing it.

**Three real problems:**

> **1. ⚠️ Charging is safety-critical.** U6 controls the charger — get it wrong and you overcharge a
> pack, a fire risk especially with Li-ion. This is qualitatively different from a mod that merely fails
> to boot. Any replacement must **fail safe (default: not charging)** and be validated on the bench with
> current monitoring before it ever sees a real pack.

- **2. The LCD needs analogue drive, not digital.** The M38223 has a *hardware* LCD controller producing
  1/3-bias multiplexed waveforms — **four voltage levels, not two**. This was proven empirically on this
  project: driving the panel from a plain MCU's digital pins produced exactly the **crosstalk on
  supposedly-off segments** you would predict. So you need a dedicated segment driver, a bias ladder with
  analogue switches, or to sidestep it by replacing the panel (#14).
- **3. Standby current.** U6 sits in STOP on the always-on rail drawing microamps so it can watch the
  power button and charge while the machine is off. RP2040 dormant is ~180 µA — hundreds of times worse —
  so a naive swap **drains the battery in storage**. Cleanest fix: leave the button/latch path discrete
  and keep the MCU **unpowered until the machine is on**, delegating charge-while-off to a dedicated
  charger IC (which is the right answer for Li-ion anyway).

**Plan for the bootstrap problem:** if the replacement misbehaves the machine **will not power on**, so
you cannot debug it from DOS the way most work on this project is done. Build a bench rig with a debug
UART on the MCU and the original U6 on a removable breakout so you can always go back.

**Suggested order:** capture the original's behaviour with the logic analyser → develop against the
emulator → bring up on the bench with a current-limited supply and a dummy load → only then a real pack.

### 12. FPGA/CPLD replacements for Bowman and Pluto 🔴
The project that matters most to the *community* rather than to one machine: today a dead gate array
means a **permanently** dead PC110 — they are custom RIOS parts with no source. We have extensive
pinouts for both (Pluto 100-pin, Bowman ~144-pin) plus a decoded register surface. Multi-month effort,
but it is the difference between the platform being repairable and not — and it opens the door to
enhancements like wiring up spare RAS lines or faster ROM decode.
→ [`Discovery/Bowman`](../Discovery/Bowman/readme.md), [`Discovery/Pluto`](../Discovery/Pluto/readme.md)

### 13. Custom BIOS 🟡
We can flash, the sizer and the memory count are located, and the 96 KB main block is safe to rewrite
with the boot block intact as recovery. That makes real features tractable: faster POST, skip the
destructive memory test, larger-disk support, custom splash, patches baked in permanently.
→ [`Discovery/BIOS-Flash`](../Discovery/BIOS-Flash/readme.md), [`Discovery/RAM-Module`](../Discovery/RAM-Module/readme.md) §7.4

### 14. Custom front-panel display 🟢
Niche but a lovely showcase: the 14-pin LCD is fully decoded (SEG0-9 + COM3-0, 1/4 duty, 1/3 bias), as
are the U6 font table and render state machine. Decode the multiplexed segment drive with a small MCU
and mirror it to an OLED, or drive a replacement directly.
→ [`Discovery/PSU-MB-M38`](../Discovery/PSU-MB-M38/readme.md) §7/§8

---

## Traps and hard limits — read before planning

- **32 MB is a hard chipset ceiling**, not a BIOS limit. Past it, addresses wrap onto low memory and
  corrupt POST — which is exactly why taka's 36 MB build needs the RC circuit. **28 MB is the sweet
  spot.** ([`Discovery/RAM-Module`](../Discovery/RAM-Module/readme.md) §7.5)
- **Flashing needs A/C *and* a ≥20 % battery *and* a floppy boot from an IBM-marked drive.** The 12 V
  VPP interlock is hardware; software cannot work around it. POST *does* arm a write-protect bit
  (`block2[0xFE]` bit 0), but clearing it is **not** sufficient — proven live.
  ([`Discovery/BIOS-Flash`](../Discovery/BIOS-Flash/readme.md) §7.1–§7.3)
- **`RAS1` is stranded** — the chipset pin has **no net** on the PC110. That is a free bank select
  sitting unused, arguably a cleaner path to extra memory than [`Mods/RAS4`](RAS4/)'s repurposing of
  `VL_D12`. Needs the bank↔RAS ordering question settled first; our live captures partially answer it.
- **A full 256 KB live BIOS dump is impossible** from a running machine — banks 0/1 are boot-decompressor
  only. Use the physical chip read. ([`Discovery/BIOS-Flash`](../Discovery/BIOS-Flash/readme.md) §9)
- **The BIOS has no `INT 13h` extensions and never issues ATA `IDENTIFY`** — real-mode disk access is
  CHS-only and the reported geometry is a ~3.85 MB stub. That is *not* what causes the ~4 GB CF wall
  (a capacity-blind BIOS cannot break at 4 GB), but it does mean large cards need LBA from somewhere:
  a BIOS patch, an option ROM (#8), or a Dynamic Drive Overlay.
  ([`Discovery/Storage`](../Discovery/Storage/readme.md))
- **Don't bother with:** IrDA modernization (dead end), audio upgrades (the ES488F is already SB Pro
  compatible — low ceiling), PCMCIA USB cards (slow, poor DOS support).

---

## Suggested sequence

**28 MB RAM → TFT + 256-colour → internal ESP32 WiFi → Li-ion/USB-C.**

Four mods, each independently rewarding, **no BGA rework**, all within territory this project's
documentation already covers. The result: usable memory, a screen you enjoy looking at, real network
access, and modern power.

The most *exciting* one to build is arguably **#7, the RP2040 keyboard controller** — it is where the
firmware RE gives the biggest unfair advantage, it fixes a real daily annoyance (the Fn layout), and it
doubles as a repair path for a part nobody can buy.

## Two habits worth adopting

1. **Before any flash:** run the flasher's **Diagnose** option, and keep both `PANEL.SAV` and a full BIOS
   backup. ([`Mods/BIOS-Multi-Patcher`](BIOS-Multi-Patcher/))
2. **After a battery mod:** verify APM still reports a sane charge percentage — otherwise you quietly
   lose the ability to reflash.

---

*Rankings and effort estimates are engineering judgement, not measurements. Items are cross-referenced
to the `Discovery/` chapter that supports them; where a mod depends on something we have **not** proven,
it is called out inline.*

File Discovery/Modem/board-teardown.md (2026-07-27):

# PC110 Modem — Board-Level Teardown (PCB companion)

*A physical, component-level companion to [`readme.md`](readme.md), which traces the modem's signal path to the docking station. That document covers the MN195001's fax-engine pins and the dock connector; this one documents the **modem PCB itself** — the parts placed, the two memory chips, the DAA/telephone-line front end, and the handset/answering audio path.*

**Sources:** `PCB/Modem/Modem-Schematic.pdf` (fuller capture) / `Modem_Schematic.pdf`; `Modem.kicad_sch`; BOM `Fab/Modem.kicad_pcb_bom.csv`; IPC‑D‑356 netlist `Fab/Modem.kicad_pcb_netlist.ipc` (exact pin→net). Board title: *"PC110 Internal Modem Module."* Tags **[C]** confirmed / **[H]** inferred.

## 1. What the board is

A single ~64.6 × 58.9 mm 6‑layer module — the PC110's **internal data/fax modem**, plus the analog hardware for the machine's **built-in telephone / answering‑machine** feature. It plugs into the motherboard through one 26‑pin connector (**CNP4 "Modem‑Connector"**, the module side of the motherboard's **J8**) and terminates the phone line at its own **RJ11 jack (CNP1 "Tel Line")**. ~211 components, essentially all SMD.

```
                       CNP4 (26-pin host / J8)          CNP1 (RJ11 phone line)
                                 │                              │
   host COM2 serial ─────────────┤                        ┌─────┴─────┐  telephone-line
   + dock spare lines            │                        │  DAA /    │  front end
   ┌──────────────┐   mem bus ┌──┴──────────┐  Line-Module│  line I/F │ (T1,VA1,RL1,
   │ IC11 flash   │◄─────────►│  IC5         │◄──IC3──────►│  PC2,     │  bridges)
   │ IC12 SRAM    │  A0-18/D0-7│  MN195001   │  connector  └─────┬─────┘
   └──────────────┘           │ fax/modem DSP│                   │
                              └──────┬───────┘            IC8 TA31033F audio
                                     │                    → CNP2/CNP3 headset, CNP5 speaker
```

## 2. Architecture — controller + datapump + memory + DAA

The controller + datapump are fused into the single **MN195001 fax engine (IC5)** (see `readme.md` §2 for the on‑chip block breakdown). What the *board* adds:

| Function | Realized by | Notes |
|---|---|---|
| Modem controller + DSP datapump | **IC5 MN195001** | 128‑pin QFP; no on‑chip program store |
| Program store (firmware) | **IC11 EN29F040A** | 512 KB NOR flash — "RIOS Ver 1.04" (`readme.md` §10) |
| Working RAM | **IC12 KM681000BLT‑7** | 128K×8 (1 Mbit) fast SRAM |
| Master clock | **OSC1 41.472 MHz** | sole oscillator |
| Reset / supervisor | **IC18 (3L01)** → `MN195_HDRES#` (IC5 pin 12) | **[H]** |
| Line interface (DAA) | T1, VA1, RL1, PC2, D1/D7/D9, DA1 | via **IC3 "Line Module"** connector |
| Telephone/handset audio | **IC8 TA31033F** + CNP2/CNP3/CNP5 | earpiece/mic/speaker, answering‑machine **[H]** |

### 2.1 External memory bus (new detail)
IC11 (flash) and IC12 (SRAM) share an 8‑bit data bus + address bus off the MN195001's external memory interface: address `29F_A0…A18` (flash A0–18 = 512 KB, SRAM A0–16 = 128 KB); data `29F_DQ0…DQ7`; strobes `29F_OE#`/`29F_WE#`; chip selects `29F_CE#`→IC11 (via R101), `68_CS1#`→IC12 (via R112), from the MN195001's `UC00`/`UC01` outputs. Reset net `MN195_HDRES#` = {IC5 pin 12, IC18 pin 1, R51}.

## 3. Main components (from `Fab/Modem.kicad_pcb_bom.csv`)

| Ref | Part / Value | Package | Role |
|---|---|---|---|
| **IC5** | MN195001 | QFP‑128 | Fax/modem engine (controller + DSP datapump) |
| **IC11** | EN29F040A | TSOP‑32 | 512 KB NOR flash — firmware "RIOS Ver 1.04" |
| **IC12** | KM681000BLT‑7 | TSOP‑32 | 128K×8 (1 Mbit) SRAM |
| **IC8** | TA31033F | SOIC‑16 | Handset/speech audio amplifier **[H]** |
| IC10 | AT32 (74×32) | TSSOP‑14 | Quad OR — line‑control / pulse‑dial gating |
| IC2/7/9/13/14/16/4/6 | single‑gate logic | SOT‑353 | buffers/inverters in ring‑detect & enable chains |
| IC18 | "3L01" | TSOT‑23‑5 | reset / supervisor → `HDRES#` **[H]** |
| **OSC1** | 41.472 MHz | 4‑pin SMD | modem master/sample clock |
| **T1** | Iso Transformer | — | telephone‑line isolation/coupling |
| **VA1** | Varistor | 2512 | tip–ring surge clamp |
| **RL1** | Relay | 8‑pin | line‑seize / off‑hook |
| **PC2** | TLP124 | opto | ring‑detect isolation |
| D1/D7/D9 | TO‑269AA arrays | — | line polarity‑guard / bridge & protection |
| DA1 | "M1T" | — | DAA line coupling **[H]** |
| CNP1 | Line_Connector | RJ11 | telephone line jack |
| CNP4 | Modem‑Connector | 26‑pin | host interface (= motherboard J8) |
| CNP2/CNP3 | headset jack / JST‑8 | — | handset (earpiece + mic) |
| CNP5 | JST‑2 | — | answering‑machine / call‑progress speaker |

## 4. Host interface — CNP4 (26‑pin) = module side of motherboard J8

Exact pinout from `Fab/…_netlist.ipc` (matches `readme.md` §3 pin‑for‑pin):

| Pin | Net | Meaning | Pin | Net | Meaning |
|--:|---|---|--:|---|---|
| 1,13,14,26 | GND | ground | 14 | (GND) | |
| 2,25 | VCC_PC110 | power | 3 | MN195_U1RD#_R | USART RX |
| 4 | FDC_DCD1 | carrier detect | 5 | FDC_RI1 | ring indicator |
| 6 | DC_DIR1# | DTR1# | 7 | FDC_DSR1 | DSR1 |
| 8 | FDC_CTS1# | CTS1# | 9 | DC_RTS1# | RTS1# |
| 10 | FDC_RXD1 | RXD1 (rx) | 11 | FDC_TXD1 | TXD1 (tx) |
| 12,15 | _ENABLED_PNET5 | Pluto power/enable | 16 | MN195_VSEN# | scanner enable → dock |
| 17 | MN195_VSDA# | scanner data → dock | 18 | MN195_VPCK# | plotter clock |
| 19 | MN195_VPDA# | plotter data → dock | 20 | MN195_IRQ1# | ext interrupt → dock |
| 21 | MN195_ADCK# | eye‑pattern clk → dock | 22 | **MN192_S11_BUF** | GPIO S11, buffered by Q4 |
| 23 | J13_41 | → dock J13 pin 41 | 24 | J13_42 | → dock J13 pin 42 |

- The serial group carries `FDC_*`/`DC_*` prefixes — the modem's DTE channel is the motherboard's second UART, i.e. **COM2 (0x2F8)**, routed through the FDC/serial block (physical confirmation of "modem uses COM2").
- Pin 22's net `MN192_S11_BUF` vs pin 16 `MN195_VSEN#` — the **MN192/MN195 naming inconsistency** flagged in `readme.md` §9; S11 is buffered through transistor Q4.

## 5. Phone‑line / DAA side (new)

The line front end reaches the MN195001 only through the **IC3 "Line Module"** connector — never the digital bus. From the netlist:

- **Line entry/protection:** CNP1 (RJ11) pin 1 `TEL_LINE` → **L1 (1.2 µH)** → net = {D1‑4, D9‑4, D7‑4, **VA1** (surge clamp), **T1**}; the TO‑269AA arrays (D1/D7/D9) form the polarity‑guard/bridge. The other leg goes through the **line‑seize relay RL1**, R75, L2.
- **Isolation/coupling:** **T1 (IsoTransformer)** couples line↔modem; **PC2 (TLP124)** isolates **ring detection**, feeding buffer chain IC2→IC7→IC9 → `MN195_S3#`. **DA1 (M1T)** + C70–C74 + IC17 form the TX/RX hybrid. **[H]** exact DA1 function.
- **Off‑hook / power control:** **`_ENABLED_PNET5`** is the master enable from **Pluto** — net = {RL1‑1 coil, buffer enable pins, PC2‑2, CNP4‑12/15, …}. Asserting it powers the front‑end, energizes the relay (off‑hook), and lights the ring opto. This is the switch that connects the modem to the line.

**IC3 "Line Module" connector (18 pins):** brings out the MN195001's analog front end — `RXL`, `TXOUT`, `TXLPIN`, `HPOUT`, `SHIN`, `AGCIN/AGCOUT`, `HVDD`, `PLSD` (pulse dial), `S1/S4` — terminated by the T1/VA1/RL1/PC2/DA1 DAA network.

### 5.1 Telephone / answering‑machine audio (separate path)
Distinct from the modem DAA, **IC8 (TA31033F)** is the **handset speech/audio amplifier** for the built‑in telephone + answering‑machine. Its I/O fans out to **CNP3 (JST‑8 headset)**, filter L/C, bias Q9, **CNP2** headset jack, **CNP5** speaker, **SW2** mode switch — realizing the earpiece/mic and the "canned ROM voice / wake‑on‑ring" answering‑machine behavior (`readme.md` §8) through IC8's audio path rather than the datapump. **[H]** TA31033F exact part.

## 6. Recreation notes

- **The MN195001 needs an external boot flash** (IC11 EN29F040A, RIOS Ver 1.04); without a valid image it does nothing. IC12 (KM681000) is the working SRAM. Both share A0–18 / D0–7 with `OE#`/`WE#` and two chip selects from IC5 `UC00`/`UC01`.
- **Clock = a single 41.472 MHz can (OSC1)** — preserve this reference.
- **The DAA is fully discrete** (T1 + VA1 + RL1 + TLP124 + D1/D7/D9 + DA1), gated on by the Pluto `_ENABLED_PNET5` line — not a packaged DAA module. Line compliance = reproducing this network.
- **Two interfaces define the board:** CNP4 (26‑pin host/J8) and CNP1 (RJ11 line). CNP2/CNP3/CNP5 are the optional telephone‑audio path (IC8) and can be omitted for data/fax‑only.
- **Naming caveat:** several nets use `MN192_*` where the silicon is the **MN195001** — treat `MN192_*` and `MN195_*` as the same device (`readme.md` §9).

*All connectivity taken directly from `Fab/Modem.kicad_pcb_netlist.ipc`; uncertain small‑signal part functions (IC8, IC15, IC18, DA1) tagged **[H]**.*

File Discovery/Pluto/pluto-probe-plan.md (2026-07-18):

# Pluto (U35) probe plan — mapping the peripheral-I/O register set

**Goal:** build **Pluto's I/O register map** — which ports it decodes, what each read/write does, and
which subsystem each register drives. This is the main open item in [Pluto §7](readme.md) ("the register
map … is not derivable from the schematic alone — needs bus-trace capture or BIOS disassembly").

**Why Pluto is the tractable target:** unlike the proprietary VL82C420↔Bowman **ML bus** (which took
§11a–i to partially decode and whose data payload is unreachable at the QFP), **Pluto speaks a plain
ISA-style local bus** — `SA[0:15]` address, `SD[0:7]` data, `IOR#`/`IOW#`/`AEN` — all on an accessible
~96-pin QFP with the pinout already mapped ([Pluto §3](readme.md)). Every cycle is directly decodable.

Rig: same as the ML-bus work — Saleae Logic Pro 16 on the NUC (`user@100.66.96.126` over Tailscale,
`user@192.168.10.183` on-LAN), driven by COMrade (`:2010`) for stimulus and the Lantronix KVM for the
console. See [[saleae-pc110-mlbus]] / [Chipset/ML-bus-payload-probe.md](../Chipset/ML-bus-payload-probe.md)
for rig mechanics (solder taps at 0.5 mm pitch; **clean the NUC `/tmp` between raw exports — it's a 7.4 G
tmpfs that silently fills and yields 0-byte CSVs**).

---

## ⚠️ Safety — read this first
Pluto controls **BIOS write-enable, power-management rails, and the LCD**. A careless `io_out` to the
wrong Pluto register could **enable BIOS-flash writes** or disturb power. Therefore:

- **Map with `io_in` (reads) only.** Reads are side-effect-free enough for decode.
- For **write** behaviour, **observe BIOS/driver-driven writes** (capture while the machine does its own
  thing) rather than driving blind `io_out`.
- COMrade's `io_out` is **unguarded** on real hardware. Never drive writes to unknown Pluto ports.
- Standing rule: **never** issue CPU-speed changes over COMrade; restore any port you do touch.

---

## Method
1. **Bus-trace Pluto's ISA interface** while driving known `io_in` over COMrade → decode `SA`→port,
   `IOR#`/`IOW#`→direction, `SD`→data. Reveals **which ports Pluto owns and their register values**.
2. **Function-map** by probing a Pluto **subsystem output** pin (KB_CCS, speaker KB_SPKUP/DN, LCD_IO,
   IRDA_O, RS-232 enable) alongside the port access → ties a register to what it *does*.
3. **KBC path:** probe `KB_CCS` (pin 60) + `SD` while driving `0x60/0x64` → maps the 8042-style keyboard
   interface and the µPD/M38xx MCU behind it (ties into the KBC-firmware disasm, Pluto §7).
4. **Complement with BIOS/driver disassembly** for the exact programming sequences (as was done for the
   inking pad's `INKDRV.COM`).

---

## Pass 1 — which ports does Pluto decode? (16 Saleae channels)
Full I/O port address (0–0x3FF) + direction + 3 data bits.

| CH | Signal | Pluto pin | | CH | Signal | Pluto pin |
|---:|---|---:|---|---:|---|---:|
| 0 | IOR# | 86 | | 8 | SA5 | 15 |
| 1 | IOW# | 89 | | 9 | SA6 | 16 |
| 2 | AEN | 6  | | 10 | SA7 | 17 |
| 3 | SA0 | 8  | | 11 | SA8 | 18 |
| 4 | SA1 | 9  | | 12 | SA9 | 19 |
| 5 | SA2 | 10 | | 13 | SD0 | 33 |
| 6 | SA3 | 11 | | 14 | SD1 | 34 |
| 7 | SA4 | 12 | | 15 | SD2 | 35 |

*Note: address pins skip 13/14 (GND/VCC); data pins skip 37/38 (GND/VCC).* `AEN` low qualifies a real CPU
I/O cycle (vs DMA). Trigger on `IOR#` (or `IOW#`) falling; or timed-capture while sweeping `io_in`.

**Run:** drive a read-only `io_in` sweep across the I/O space over COMrade; bucket the cycles by `SA`
(port) to see which ports Pluto actually responds on, with their low data bits.

## Pass 2 — full register data on the ports of interest
Keep `IOR#`(86)/`IOW#`(89)/`AEN`(6); move CH3–CH10 to the **full data byte** `SD0–SD7`
(33,34,35,36,39,40,41,42); keep a few `SA` on CH11–15 to identify the port. Re-drive `io_in` to the
Pluto-owned ports found in Pass 1 → read the full register values.

## Pass 3 — function mapping (register → subsystem)
Keep the ISA framing; add a **subsystem output** pin and toggle it via its port:

| Subsystem | Pluto pin(s) |
|---|---|
| Keyboard-controller chip select | KB_CCS 60, KB_CNTR# 61, KB_RESET# 66 |
| Speaker | KB_SPKUP 44, KB_SPKDN 43 |
| Floppy | FDD_IO1–4 68–71, Pluto_IOW 58 |
| LCD / power | LCD_IO 93, PSU_IO 83, PWRGD 67, CPU_STPCLK# 62 |
| IrDA | IRDA_O 81 |
| Modem codec | MN195_VSDA 75 (likely; schematic typo `NM192`) |
| BIOS bank | BIOS_SA17 54 |
| Bowman↔Pluto link | Bowman_IO1 51 / Bowman_IO2 52 / Pluto_IO 129 (on Bowman) |

---

## Known Pluto facts to anchor against ([Pluto readme](readme.md))
- SMC-fabbed peripheral controller (~96-pin QFP), marked `…PLUTO … JAPAN` (visible in the bench photo,
  [Chipset/images](../Chipset/images/ml-bus-probe-bench.jpg)).
- Presents an **8042-style keyboard controller** to the CPU (`KB_CCS`/`KB_CNTR#`/`SD0–7`).
- Fans the ISA bus out to: keyboard, floppy, PCMCIA/CF card-detect, IrDA, RS-232, LCD/PM rails, dock
  detect, modem, external BIOS flash. Uses external 74-series flip-flops (`FF_*`) for some lines.
- Already-RE'd port hints elsewhere in the project: inking/signature pad at I/O base `0x15E0`
  (INKDRV.COM); trackpad µPD17137A as std PS/2 on the KBC path.

## Open questions this campaign should close (Pluto §7)
- The `SD`/`SA` register map (**this plan's primary target**).
- Exact names for placeholder pins 50, 55–57, 74.
- The `FF_*` external flip-flop network behaviour.
- The FDD signal split between Pluto and Bowman (`FDD_Bowman`).
- Host-interface port ↔ `KB_CCS`/`KB_CNTR#`/`SD` mapping; re-disassemble the KBC firmware with a
  **740-aware** disassembler.
- Whether `Pluto` is laser-marked on U35 (as `RIOS BOWMAN` turned out to be on U21).

## Force-multiplier — `BUS_STIM` (BUILT & DEPLOYED 2026-07-16)
COMrade now has the **bus-stimulus burst op** — `cm.bus_stim(kind, target, width, count)` /
MCP `bus_stim` (kind `'io'`=io_in on a port, `'mem'`=mem_read at a linear addr) — which loops the READ
K times in a tight DOS-side CPU loop from one serial round-trip. Measured ~**0.34 M io/s** and
~**0.79 M mem/s**; a burst took its target from **0.003 %→19.3 %** of bus ADS# cycles (~7,800×), so driven
stimulus **dominates the bus**. **Use it for the Pluto sweep:** `bus_stim('io', <port>, 1, ~5_000_000)`
to a candidate port while capturing → that port's cycles dominate, making `IOR#`/`SA`/`SD` decode trivial
even against background. (Reads only — safe. New agent version `COMRADE/…20260717…`; source committed in
the COMrade repo, `COMRADE.EXE` on `C:\`, old build in `C:\COMRADE.BAK`.)

---

## Pass 1 results — runtime I/O activity map  **[MEASURED 2026-07-17]**
Wiring validated (`io_in(0x1EB)` burst → `SA=0x1EB` on 100% of IOR# cycles; SA/IOR#/AEN/burst all correct;
an SA5/pin-15 reseat was needed). AEN = 0 on all cycles (pure CPU I/O, no DMA). Passive capture (50 ms)
of natural traffic — the running system's I/O working set, all **index/data register pairs**:

| Port (SA0–9, may alias mod 0x400) | R/W | count | note |
|---|---|---|---|
| `0x074` w / `0x076` r | idx/data | 864/864 | **VL82C420 SCAMP config pair** (Chipset §13) — actively driven |
| `0x070` w | RTC index | 433 | RTC/CMOS |
| `0x024` w / `0x023`,`0x025` r/w | idx/data | 3028 / ~1.3–1.7k | second indexed config block at `0x22–0x25` |
| `0x1EA`,`0x1EB`,`0x1EE` r/w | idx/data | ~0.4–1.7k | `0x1Ex` block — possibly the inking pad (`0x15E0` base, aliased) or a real `0x1Ex` reg; needs SA10+ to de-alias |
| `0x020` w | PIC EOI | 2 | 8259 |

**Limits hit:** only SD0–2 wired (can't read register *contents*); SA0–9 aliases mod `0x400`.

**Next wiring (Pass 2 — full data byte):** CH0 IOR#(86), CH1 IOW#(89), CH2 AEN(6), CH3–10 = **SD0–SD7**
(33,34,35,36,39,40,41,42), CH11–15 = **SA0–SA4** (8,9,10,11,12). Then burst-drive a target port
(`0x074`/`0x024`/`0x1EA`) and read its full register value; SA0–4 gives the offset. Later: SA10–13 to
de-alias, KB_CCS(60) for Pluto attribution.

*Plan written 2026-07-16; Pass 1 run 2026-07-17.*

---

## Pass 2 results — full 8-bit data byte  **[MEASURED 2026-07-17]**
Rewired to **IOR#(86) / IOW#(89) / AEN(6) / SD0–SD7(33,34,35,36,39,40,41,42) / SA0–SA4(8,9,10,11,12)**.
Wiring re-validated end-to-end: `bus_stim('io', 0x1EB)` → capture shows `SA0-4 = 0x0B` (= `0x1EB & 0x1F`)
and full byte `SD = 0xFF` on 100 % of 6894 IOR# cycles. Swept every Pass-1 data port with a dominant
burst (each burst's `SA0-4` matched its port exactly — address wiring correct across the range).

> ⚠️ **Rig gotcha found:** a `BUS_STIM` burst runs a tight loop **on the DOS side** for its full count
> (~88 s at 30 M). Killing the *Mac-side* `comrade_bg.py` does **not** stop the DOS loop, so back-to-back
> captures get contaminated by the prior port. Fix: size the burst to ~4 M (~12 s), start capture ~3 s in,
> then **block until the burst process returns** (DOS loop done) before the next port.

**Idle single-port reads (burst each port, read its byte):** every data port returns `0xFF` at idle
**except `0x074` = `0x0F`** — i.e. `0x074` is an **index register that reads back the last-written index**
(0x0F), confirming `0x074/0x076` = the **VL82C420 SCAMP config index/data pair** (Chipset §13). The `0xFF`
elsewhere is open-bus / "index points at an unused reg" at idle.

**Live transaction capture (passive, IOW#-triggered, full byte) — the real payoff.** With the running
system's own I/O reconstructed cycle-by-cycle we can read **actual indexed-register contents off the bus**
(read-only, safe). Two indexed register files are active plus a status-poll loop:

| Block | Index port | Data port | Observed registers (idx → value) |
|---|---|---|---|
| **VL82C420 SCAMP** | `0x074` | `0x076` | `0x7E → 0x15`, `0x7F → 0xEE` |
| **Block 2** (8-bit index space) | `0x024` | `0x025` | `0x2E → 0x0F`, `0xB7 → 0x20` (then written `0x5F`), `0xBD ← 0x00`, `0xF9 ← 0x00`, `0xFA ← 0x01` |

Direct (non-indexed) ports seen live: `0x1EA` (W `0x01`/`0x08`) ↔ `0x1EB` (R `0xFF`) — a **~50 µs
status-poll loop** (the `0x1Ex` block, base `0x15E0` aliased → likely the inking pad); `0x1EE ← 0x80`;
`0x070 ← 0x0F` (RTC/CMOS index); `0x023` R `0xFF`; and a **`0x?1F` status port** returning *varying*
values (`0x20,0x28,0xAA,0xEA,0xFB,…`) — a live register worth de-aliasing.

**What this wiring fundamentally cannot resolve (→ next wiring):**
1. **Owner attribution.** `SD`/`IOR#`/`IOW#` are the *shared ISA bus* fanned out by Pluto, so every cycle
   appears on Pluto's pins whether Pluto or the VL82C420 decodes it. We know `0x74/0x76` = chipset (§13),
   but **who owns `0x24/0x25`, `0x1Ex`, `0x070`?** Needs a Pluto **chip-select / subsystem-output** wire.
2. **Full port de-alias.** `SA0–4` only gives offset mod `0x20`; the real 10-bit ports come from Pass-1's
   `SA0–9`, and bits above `SA9` are still aliased.

### → Recommended next wiring (Pass 3 — attribution / function map)
Drop the data byte (contents already captured); anchor the offset and add a **fan of Pluto output/select
pins**, then `bus_stim` each mystery port so its cycles dominate and watch which Pluto pin moves in lockstep:

| CH | Signal | Pluto pin | | CH | Signal | Pluto pin |
|---:|---|---:|---|---:|---|---:|
| 0 | IOR# | 86 | | 8 | KB_CCS | 60 |
| 1 | IOW# | 89 | | 9 | KB_CNTR# | 61 |
| 2 | AEN | 6 | | 10 | LCD_IO | 93 |
| 3 | SA0 | 8 | | 11 | IRDA_O | 81 |
| 4 | SA1 | 9 | | 12 | KB_SPKUP | 44 |
| 5 | SA2 | 10 | | 13 | FDD_IO1 | 68 |
| 6 | SA3 | 11 | | 14 | BIOS_SA17 | 54 |
| 7 | SA4 | 12 | | 15 | PSU_IO | 83 |

Then `bus_stim('io', 0x24)`, `0x1EA`, `0x070` in turn: a Pluto pin that toggles synchronously with the
bursted port ⇒ **Pluto decodes/drives that port** and ties it to that subsystem; if *no* Pluto pin moves,
the port is the **VL82C420 chipset** (like `0x74/0x76`). That closes Pluto §7's "which ports does Pluto
own, and what does each drive."

*Pass 2 run 2026-07-17.*

### Pass 2b — two more things this wiring settled (no rewire)  **[2026-07-17]**
Before rewiring, exhausted the rest of what IOR#/IOW#/AEN + SD0-7 + SA0-4 can measure:

**Cycle timing / wait-state signature.** Measured IOR# low-width per port under a dominant burst: **every
port is identical — 536 ns IOR# low, 2888 ns fall→fall period** (the 2888 ns is the DOS burst-loop rate;
the 536 ns is the ISA cycle). So the VL82C420 issues **one uniform standard 8-bit-ISA I/O cycle for all
these ports, with no differential wait states** → *timing cannot attribute owner* (a slow external
peripheral would stretch IOR#/IOCHRDY; none here do). This confirms attribution needs the Pass-3 select
pins, not timing.

**Aliasing resolved via full-address `io_in` (COMrade returns the byte the CPU sees) — the `0x1Ex` block
is the inking/signature pad.** `SA0–9` can't see bits above bit 9, but COMrade can drive the *full* 16-bit
port and read the data back:

| port | byte | port | byte |
|---|---|---|---|
| `0x01E0` | `0xFF` (open bus) | `0x15E0` | **`0x00`** (real) |
| `0x01EE` | `0xFF` (open bus) | `0x15EE` | **`0x80`** (real) |
| `0x0074` | `0x0F` (real idx) | `0x0474` | `0xFF` (open bus) |

The pad **decodes its full address at base `0x15E0`** (checks `SA10–12`); the low `0x1Ex` aliases are
undecoded open-bus. So the passive **`0x1Ex` ~50 µs poll loop is `INKDRV` polling the pad at `0x15EA/EB/EE`**
([[pc110-inking-pad]], 3-byte `[flags,rawX,rawY]`) — not a mystery register. And `0x0074` reads back its
index while `0x0474` is open bus, re-confirming `0x74/0x76` is a real full-decoded chipset port.

**Verdict: this wiring is now fully exhausted.** Remaining unknowns (owner of `0x24/0x25` and `0x070`;
what each Pluto subsystem port drives) require the **Pass-3 select-pin wiring** above — they are not
obtainable from the shared ISA data/address bus alone.

*Pass 2b run 2026-07-17.*

---

## Pass 3 results — owner attribution  **[MEASURED 2026-07-17]**
Rewired to **IOR#(86)/IOW#(89)/AEN(6)/SA0–4(8,9,10,11,12)** + a fan of Pluto outputs: **KB_CCS(60),
KB_CNTR#(61), LCD_IO(93), IRDA_O(81), KB_SPKUP(44), FDD_IO1(68), BIOS_SA17(54), PSU_IO(83)**. Method:
`bus_stim('io', port)` so the target dominates the bus, then per Pluto pin count transitions and its level
during each IOR#-low → a **per-cycle chip-select** shows ~100 % assert + ~2 transitions/cycle.

**Validation (known truth):** bursting the keyboard ports drives **KB_CCS low on 100 % of cycles**
(`0x64`: 7913 transitions; `0x60`: 7715) — Pluto's keyboard decode, exactly as expected. Every other pin
static. Method confirmed.

**Attribution sweep:**

| Port(s) | Pluto pin that fires | Verdict |
|---|---|---|
| `0x60`, `0x64` | **KB_CCS** (100 %/cycle) | **Pluto** decodes the 8042-style keyboard interface |
| `0x74`/`0x076` (SCAMP cfg) | *none* | **VL82C420 chipset** (known-good negative control — §13) |
| `0x24`/`0x25` (2nd index/data block) | *none* | **VL82C420 chipset** — a second on-chip indexed config window, **not Pluto** |
| `0x70` (RTC index) | *none* | **VL82C420 chipset** (integrated RTC) |
| `0x15EA`, `0x15EE` (inking pad) | **KB_CNTR#** (~212–214 edges, deterministic; **not** per-cycle) | pad data/trigger regs **coupled to the KBC control path** |
| `0x15E0` (pad base) / `0x2E2` (null) | *none* | (base reg / undecoded → clean baseline) |

**Findings:**
1. **Pluto owns the keyboard controller** (`0x60/0x64` → KB_CCS, hard per-cycle select).
2. **The config/RTC ports are chipset, not Pluto.** `0x24/0x25`, `0x70`, `0x74/0x76` fire **none** of the
   8 monitored Pluto outputs. `0x74/0x76` is independently known-chipset (§13) and serves as the negative
   control; `0x24/0x25` behaves identically (indexed pair, no Pluto output) ⇒ a **second VL82C420 config
   window**. *Caveat:* 8 of Pluto's ~96 pins were watched, so "not Pluto" = "drives none of
   KB_CCS/KB_CNTR#/LCD_IO/IRDA_O/KB_SPKUP/FDD_IO1/BIOS_SA17/PSU_IO."
3. **The inking pad is serviced through the KBC path.** Reads of the pad's *higher* registers
   (`0x15EA/0x15EE`) deterministically induce **KB_CNTR#** toggling (~212 edges/8 ms) while the pad base
   `0x15E0` and a null port induce none — i.e. touching a pad data/trigger reg kicks the
   keyboard-controller-serviced digitizer. KB_CCS never asserts for the pad, so it's a **functional
   side-effect on the KBC control line, not an address chip-select**. Ties to [[pc110-inking-pad]] /
   [[pc110-u75-trackpad]] (digitizer + trackpad both on the KBC MCU).

This closes Pluto §7's core question: **among the CPU-visible I/O, Pluto decodes the keyboard/KBC
interface; the chipset owns the config-register and RTC ports.** Remaining refinements (optional next
wiring): watch Pluto's *other* peripheral outputs (modem/PCMCIA/dock/FDD2–4/Bowman-link) to make the
`0x24/0x25`=chipset claim exhaustive, and probe the KBC-MCU data lines while reading `0x15EA` to watch the
digitizer conversion directly.

*Pass 3 run 2026-07-17.*

---

## Pass 4 results — extended pin fan (partial / method limit reached)  **[MEASURED 2026-07-17]**
Rewired to **IOR#(86)** as an IOR#-only trigger (anchor CH1–5 dropped — for a dominant single-port burst
the port is already known) + 10 probe pins: the 5 unknown placeholder pins **50, 55, 56, 57, 74** and
Pluto peripheral outputs **MN195_VSDA/modem(75), Bowman_IO1(51), Bowman_IO2(52), FDD_IO2(69),
FDD_IO3(70)**. Bursted `0x24/0x25/0x70/0x15EA` (mystery ports), `0x60/0x64` (known-Pluto keyboard control),
`0x3F4/0x3F5` (floppy).

> ⚠️ **Rig notes this session:** the NUC power-cycled mid-session → ttyUSB re-enumerated and ser2net came
> back on the wrong port; **fixed `/etc/ser2net.yaml` to bind `0.0.0.0:2010` durably** (was `2001`).
> The Pass-4 rewire also left **IOR#(CH0/pin 86) intermittent** — it caught only 3–4 of ~6800 burst
> strobes (all clean 536 ns, so signal-good/contact-bad); reseating pin 86 restored it (65 k clean pulses).
> Method to catch this: timed capture + IOR# low-width histogram — real strobes cluster at 500–550 ns.

**Result: every one of the 10 probe pins stayed static (0 transitions) for every port, including the
keyboard ports.** The pins read stable **mixed** DC levels (pin50=L, pin55=H, pin56=L, pin57=L, pin74=H,
MN195/Bowman/FDD=H), so they are **connected but never toggle under a safe `io_in` read**.

**Interpretation — this pin set can't advance attribution, and here's the (real) reason:** these are
**subsystem-output / status lines**, which only move when the subsystem is *actively exercised* (LCD paint,
IR TX, modem, floppy seek/motor) — a passive port read never stirs them — and the only proven *per-access
select* line, **KB_CCS**, was dropped this pass, so there is **no positive control**. A null therefore
can't separate "chipset owns `0x24/0x25`" from "these lines simply don't respond to reads."

**What Pass 4 *does* establish (small but real):** the 5 previously-unknown pins **50/55/56/57/74 are not
bus-cycle signals** — they hold static DC (idle 50=L, 55=H, 56=L, 57=L, 74=H) through thousands of I/O
cycles, so they are **straps / config / slow-status**, not per-cycle I/O selects. That trims Pluto §7's
"unknown pin" list.

**Attribution conclusion stands from Pass 3:** `0x24/0x25` = VL82C420 chipset **by behavioral identity**
with the known-chipset `0x74/0x76` (indexed pair, no reaction on KB_CCS/KB_CNTR# — the two Pluto lines
that *do* respond to reads). Making that *provable* rather than *inferred* needs a Pluto line that asserts
on any Pluto I/O decode (e.g. **Pluto_IOW pin 58** or a data-buffer-enable), which in turn needs
write-stimulus to Pluto-owned ports — outside the read-only safety envelope — so it is deferred. A cheaper
next step is a **KB_CCS(60) positive-control rewire** to confirm harness+method, but KB_CCS only fires for
keyboard ports and so cannot itself attribute `0x24/0x25`.

*Pass 4 run 2026-07-17. Attribution limit of output-pin probing reached; Pass-3 result is the standing answer.*

---

## Pass 5 results — Pluto_IOW + full strobe fan  **[MEASURED 2026-07-17]**
Rewired to **IOR#(86)** trigger + **IOW#(89)** + the two stars **KB_CCS(60)** (positive control) and
**Pluto_IOW(58)** (Pluto's own I/O write strobe — the generic-decode candidate), plus every remaining
Pluto strobe/link: **KB_CNTR#(61), KB_RESET#(66), FDD_IO1(68), FDD_IO4(71), CPU_STPCLK#(62), PWRGD(67),
Bowman_IO1(51), Bowman_IO2(52)**. (CH6/7/12/15 = KB_SPKUP/KB_SPKDN/SD0/LCD_IO were not landed this pass —
all low-value/known-static.)

**Method validated:** read-burst `0x64`/`0x60` → **KB_CCS asserts low on 100 % of cycles** (5941
transitions). IOR# trigger + harness confirmed.

**Reads still don't attribute:** read-burst `0x24`/`0x25`/`0x70` → **none** of the 10 wired Pluto lines
move. Consistent with Pass 3/4.

**Pluto_IOW characterised:** it is **write-only** (did not move on any read, incl. the keyboard reads that
fire KB_CCS). A passive capture of **1802 of the machine's own write cycles** showed Pluto_IOW asserting on
**zero** of them — expected, because at idle every write targets a chipset port (`0x24/0x25/0x74/0x70`,
per Pass 2), so a quiet Pluto_IOW is consistent with those being chipset. **But** it also means there is
**no positive control** yet proving Pluto_IOW *can* assert — the machine writes no Pluto-owned port at idle
(even the KBC-coupled pad writes to `0x15EA` left it quiet, so Pluto_IOW is a *narrow* strobe, not a
generic decode flag).

**Where this leaves it:** every read-only avenue is exhausted. `0x24/0x25/0x70 = VL82C420 chipset` stands
as a **strong inference** (behavioural identity with known-chipset `0x74/0x76`; no response on ~20 probed
Pluto lines incl. the KB_CCS control; no Pluto_IOW on the machine's own writes to them). Turning inference
into **proof** requires *write* stimulus: (a) a positive control — write a **Pluto-owned** port to show
Pluto_IOW *can* fire, and (b) a no-op write to `0x24` to see if it does. That crosses the read-only safety
envelope, so it is gated on an explicit go-ahead and a chosen safe port/value.

**Bonus read-only result — keyboard and pad use *different* KBC lines.** With KB_CNTR#(61) and the
Bowman↔Pluto link (Bowman_IO1/2) wired for the first time, re-ran the KBC path read-only:
- **Keyboard `0x60`/`0x64`:** only **KB_CCS** asserts (100 %/cycle); KB_CNTR#, Bowman link, all else quiet
  → keyboard reads go through the 8042 chip-select alone.
- **Pad `0x15EA`/`0x15EE`:** **KB_CCS quiet, KB_CNTR# = 212** (deterministic) → the inking pad is **not**
  behind the 8042 chip-select; it is tied specifically to **KB_CNTR#**. So keyboard and pad are distinct
  branches of Pluto's KBC subsystem.
- **Bowman_IO1/2** stayed static through every I/O read *and* a memory-read burst → the Bowman↔Pluto link
  carries neither I/O nor memory cycles in these tests (function still open, but it is not the I/O path).

*Pass 5 run 2026-07-17.*

### Pass 5 write-test — Pluto_IOW positive control (approved, keyboard-safe)  **[MEASURED 2026-07-17]**
With explicit go-ahead for a keyboard-safe write, drove `io_out(0x64, 0xAE)` ("enable keyboard" — a no-op
on an already-enabled KBC; the only value written, benign, nothing to restore) while triggering on
**IOW# falling + KB_CCS low** (a keyboard write) and watching **Pluto_IOW**.

**Result across ~17 confirmed keyboard writes (5 captures):** KB_CCS asserted on **every** one (so the
write reaches Pluto — and note KB_CCS asserts on writes as well as reads), but **Pluto_IOW asserted on
zero**. Therefore **Pluto_IOW is a narrow device strobe, NOT a generic "Pluto decoded this I/O" flag** —
it does not fire even for a confirmed Pluto (keyboard) write.

> **Investigated (2026-07-17):** the netlist labels pin 58 `FDC_IOW`, which suggested it might be the
> FDC write strobe. **Tested and disproven:** continuous writes to the FDC DOR (`0x3F2`←`0x0C`, safe
> no-op, no drive attached) while triggering *directly* on pin 58 → it **never asserted** (28 s timeout),
> and a windowed count found 0 assertions on floppy writes (and 0 on keyboard/idle writes across all of
> Pass 5). So **pin 58 is NOT the FDC write strobe** — the FDC37C665 (U22) takes `IOW#` directly from the
> ISA bus (its own pin 43), needing no strobe from Pluto. Pin 58 stayed static under every stimulus tried;
> its function/connectivity is **unconfirmed** (the `FDC_IOW → U23` net may be a mistrace, or route to the
> small U23 support part by the FDC crystal). The FDC-ownership finding (U22 = the FDC, not Pluto) is
> unaffected — it rests on the netlist part ID, not on pin 58.

**Consequence:** the planned write #2 (a no-op write to `0x24` watching Pluto_IOW) is **moot and was not
performed** — a null Pluto_IOW on `0x24` would be meaningless when it is already null on confirmed Pluto
writes. The write path cannot attribute `0x24/0x25` either.

### Final attribution verdict
`0x24/0x25/0x70 = VL82C420 chipset` — **strong inference, and now the standing final answer.** Every
available method has been run: behavioural identity with known-chipset `0x74/0x76`; no response across
~20 probed Pluto lines on reads; Pluto_IOW quiet on the machine's own writes to them; and the one Pluto
decode indicator that *could* have proven it (Pluto_IOW) shown to be a narrow strobe that doesn't flag
generic Pluto decodes. **Proof beyond this inference would require a VL82C420 BGA interposer** (watch the
chipset's own I/O-decode/chip-select at the balls) — out of scope for the QFP-probe rig.

**Pluto map — closed:** Pluto owns the **keyboard/KBC interface** (`0x60/0x64` → KB_CCS, reads *and*
writes); the **inking pad** is a distinct KBC branch on **KB_CNTR#** (`0x15EA/EE`, not the 8042 select);
the **config-register and RTC ports** (`0x24/0x25`, `0x70`, `0x74/0x76`) are the **VL82C420 chipset**; the
**Bowman↔Pluto link** carries neither I/O nor memory cycles in these tests (function still open). Pins
50/55/56/57/74 are static straps. Remaining open items need an interposer or the KBC-MCU pinout.

*Pass 5 write-test run 2026-07-17. Pluto I/O-attribution campaign complete.*

### Pass 5 completion — full 16-channel fan (CH6/7/12/15 landed)  **[MEASURED 2026-07-18]**
The four channels dropped earlier (KB_SPKUP 44, KB_SPKDN 43, **SD0 33**, LCD_IO 93) were wired, giving the
complete pin fan. Idle health check: all 16 live (CH0 IOR# solid; SD0 a live data line). Re-ran the sweep
watching **all 16** — SD0 acts as a "real data was driven" witness:

| Port | Pluto decode pin | SD0 (data)? | Owner (confirmed) |
|---|---|---|---|
| `0x60`/`0x64` keyboard | **KB_CCS** (100 %/cyc) | yes | **Pluto** |
| `0x15EA` inking pad | KB_CNTR# (~212, side-effect) | no (reads `0xFF`) | **Pluto** KBC branch |
| `0x3F4` floppy | **none** | **yes** | **U22 FDC37C665IR** — data flows but *no Pluto pin* → Pluto uninvolved |
| `0x24`/`0x25`/`0x70` config/RTC | **none** | no (read `0xFF`) | **VL82C420 chipset** |

**The `0x3F4` row is the live corroboration of the netlist FDC finding:** a floppy read drives real data
onto the bus (SD0 toggles) yet asserts **no Pluto decode line at all** — precisely the signature of the
FDC living in **U22, not Pluto**. Symmetrically, keyboard reads assert **both** KB_CCS (Pluto's decode)
and SD0 (data). And the config/RTC ports assert neither → chipset. With the full 16-line fan, the mystery
ports `0x24/0x25/0x70` fire **nothing** across every wired Pluto output — the attribution is now as
exhaustive as this rig can make it.

*Pass 5 completed 2026-07-18 — full pin fan; FDC=U22 confirmed live; Pluto owns keyboard + pad branch only.*

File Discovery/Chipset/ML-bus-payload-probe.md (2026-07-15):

# ML-bus payload probe — capturing the multiplexed address/data

**Goal:** go beyond the 5 handshake lines and capture the *payload* of the VL82C420↔Bowman ML
bus — the three 16-bit groups that US 5,793,990 time-multiplexes onto the CPU's `A[25:2]`
address lines — so the full cycle (target address, cycle type, and 16-bit data) can be decoded.

Read alongside [Chipset §11a](readme.md) (protocol, decoded from the patent) and
[Chipset §11b](readme.md) (the handshake lines, measured live 2026-07-06). Bowman pinout is in
[Discovery/Bowman](../Bowman/readme.md) §3.1.

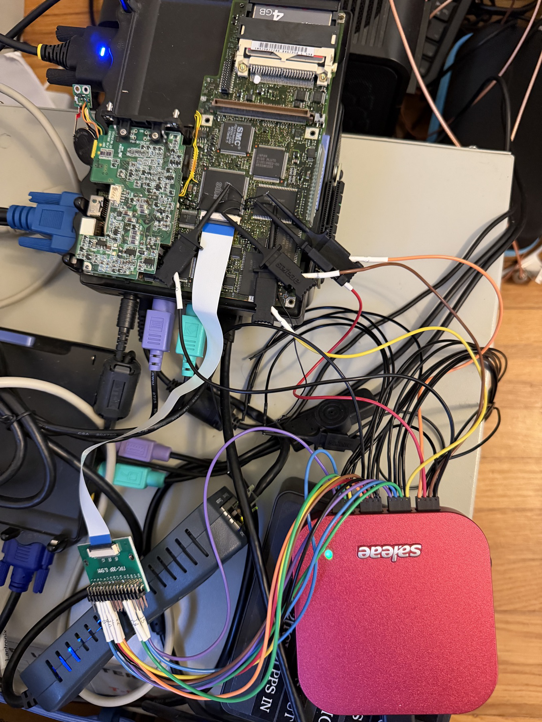
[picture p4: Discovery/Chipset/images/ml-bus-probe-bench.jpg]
ML-bus probe bench setup


*Bench setup: the PC110 mainboard running live, with the **Saleae Logic Pro 16** (red) micro-gripping
Bowman/CPU pins — MLADS#/MLCLK plus the CPU address lines — via flying leads and grabber clips. The
SMC-fabbed **Pluto** (U35) sits mid-board beside the 4 GB CF card and the PC-Card connector; the
**Lantronix Spider** KVM (the blue-LED unit) carries the PC110's VGA + PS/2 + serial over IP, and an
FPC-30P breakout taps a flex connector. The whole rig is driven headless from the NUC
(`192.168.10.183`): Saleae automation for capture, COMrade for driving known bus cycles.*

---

> **⚠️ Measured outcome (2026-07-14):** the premise below — that this PC110 multiplexes address/data
> onto `A[25:2]` — was **tested and disproved**. The address is presented *statically* on `A[25:2]` for
> the whole cycle and the data rides a *separate* data bus; the multiple MLADS# strobes are Bowman
> decode/handshake phases, not multiplex groups. See [Chipset §11d](readme.md). This section is kept as
> the (generic, patent-derived) hypothesis that motivated the probe; to capture ML **data**, probe the
> data bus (`SD`/`D[15:0]`), not the address lines.

## 1. Why the address bus *is* the data bus (hypothesis — not what the PC110 does; see §11d)

The ML bus has **no dedicated data wires**. Each transaction is sent as **three successive
16-bit groups**, driven onto the CPU's own `A[25:2]` local-address lines and strobed by
`MLADS#` (the controller tri-states the CPU off the bus with `AHOLD` between groups):

| Group | Memory cycle | I/O cycle |
|---:|---|---|
| 1 | `A[25:10]` — high address, 1 KB granularity | address bits, 4-byte granularity |
| 2 | `A[9:2]` + control: `A1`, `BHE#`, `BLE#`, `W/R#`, `D/C#` | same control set |
| 3 | `D[15:0]` — the 16-bit data payload | `D[15:0]` |

So decoding the protocol = **sampling the CPU address lines on each `MLADS#` strobe** and
sorting the captured words into groups 1/2/3.

The CPU (U76, 80486SX-33) is **BGA256 — inaccessible**. Every one of these nets also lands on
**Bowman (U21), a 144-pin QFP** — the ML-bus companion — whose pins are physically reachable.
**Probe at Bowman.**

---

## 2. Probe points — Bowman U21

### 2.1 CPU address lines (all on the pins-1–36 edge)

| Signal | Pin | Signal | Pin | Signal | Pin |
|---|----:|---|----:|---|----:|
| CPUA2  | 10  | CPUA10 | 19  | CPUA18 | 27  |
| CPUA3  | 11  | CPUA11 | 20  | CPUA19 | 29  |
| CPUA4  | 12  | CPUA12 | 21  | CPUA20 | 30  |
| CPUA5  | 13  | CPUA13 | 22  | CPUA21 | 31  |
| CPUA6  | 14  | CPUA14 | 23  | CPUA22 | 32  |
| CPUA7  | 15  | CPUA15 | 24  | CPUA23 | 33  |
| CPUA8  | 16  | CPUA16 | 25  | CPUA24 | 34  |
| CPUA9  | 17  | CPUA17 | 26  | CPUA25 | 35  |

*(Pins 18 and 28 are gaps in the `CPUA*` run — power/other nets, do not probe for this.)*

### 2.2 Framing + cycle-type (other edges)

| Signal | Pin | Edge | Why |
|---|----:|---|-----|
| **MLADS#**  | **52**  | 37–72 | ML group strobe — the decode trigger / group framing |
| **MLCLK** | **39**  | 37–72 | 22.7 MHz sample clock — count phases between strobes |
| CPU_ADS# | 49 | 37–72 | CPU cycle start — correlate CPU cycle ↔ ML groups |
| CPU_MIO# | 50 | 37–72 | memory vs I/O |
| CPU_WR# | 42 | 37–72 | write vs read |
| CPU_DC# | 41 | 37–72 | data vs control |

Note `A0`/`A1` are **not** exposed on Bowman (byte selection is via byte-enables); the group-2
control bits (`BHE#`/`BLE#`/etc.) are inferred from cycle behaviour, not from dedicated pins.

---

## 3. Channel budget — two passes

24 address lines + framing exceed the Logic Pro 16's 16 channels, so capture in **two passes**.
Keep the framing/cycle-type pins **identical across both passes** as alignment references, and
drive **repeatable** cycles from COMrade so the passes stitch together.

### Pass 1 — semantics + high address (what each cycle targets)

| CH | Signal | Pin | CH | Signal | Pin |
|---:|---|----:|---:|---|----:|
| 0 | MLADS# | 52  | 8  | CPUA13 | 22 |
| 1 | MLCLK | 39  | 9  | CPUA14 | 23 |
| 2 | CPU_ADS# | 49  | 10 | CPUA15 | 24 |
| 3 | CPU_MIO# | 50  | 11 | CPUA16 | 25 |
| 4 | CPU_WR#  | 42  | 12 | CPUA17 | 26 |
| 5 | CPUA10 | 19  | 13 | CPUA18 | 27 |
| 6 | CPUA11 | 20  | 14 | CPUA19 | 29 |
| 7 | CPUA12 | 21  | 15 | CPUA20 | 30 |

### Pass 2 — low address + data payload

Keep CH0–CH4 (MLADS#, MLCLK, ADS#, MIO#, WR#) on the same pins; move CH5–CH15 to:

| CH | Signal | Pin | CH | Signal | Pin |
|---:|---|----:|---:|---|----:|
| 5  | CPUA2 | 10 | 11 | CPUA8  | 16 |
| 6  | CPUA3 | 11 | 12 | CPUA9  | 17 |
| 7  | CPUA4 | 12 | 13 | CPUA21 | 31 |
| 8  | CPUA5 | 13 | 14 | CPUA22 | 32 |
| 9  | CPUA6 | 14 | 15 | CPUA23 | 33 |
| 10 | CPUA7 | 15 | | | |

*(CPUA24/25 on pins 34/35 spill to a third short pass, or swap in for two low bits if the top
address bits prove constant for the chosen stimulus.)*

Group 3 (data) rides the same wires, so across the passes you recover the full `A[25:2]` **and**
the 16 data bits `D[15:0]`.

---

## 4. Capture settings

- **Rate:** 250 MS/s (≈11× oversample of the 22.7 MHz MLCLK — enough to resolve each phase).
- **Mode:** digital trigger, **`MLADS#` falling** (or `CPU_ADS#` falling to frame from the CPU side).
- **Window:** a few hundred µs is plenty; each transaction is a handful of MLCLK periods.
- Rig: Saleae Logic Pro 16 on the NUC (`192.168.10.183`), automation gRPC :10430 / MCP :10530.

---

## 5. Stimulus — drive deterministic cycles over COMrade

The passes only stitch if every capture frames the *same* transaction. Drive known, repeatable
cycles from the host:

- **I/O cycle:** `io_in` a fixed, side-effect-free port (e.g. a Pluto/PCIC status register) in a
  tight loop → `MIO#` low, `WR#` high, a known low-address group.
- **Memory read:** `mem_read` a fixed ROM address → `MIO#` high, `WR#` high, a known high-address
  group whose `A[25:10]` value you can predict and check against group 1.

> **Safety:** `io_out`/`mem_write` are unguarded on real hardware and can crash or reprogram the
> box — use **reads** for stimulus. **Never** issue CPU-speed changes over COMrade.

Predictable stimulus also validates the decode: the group-1 word you capture must equal the
`A[25:10]` of the address you asked COMrade to read.

---

## 6. Decode plan

1. Find each `MLADS#` assertion; sample all address channels on the qualifying `MLCLK` edge.
2. Sequence the samples into groups 1→2→3 by strobe order (see §11a read/write timing).
3. Group 1 → target address (1 KB page) → identify the device/register.
4. Group 2 → low address + control → reconstruct `W/R#`, `D/C#`, byte enables.
5. Group 3 → the 16-bit data word.
6. Cross-check `MIO#`/`WR#`/`ADS#` (captured directly) against the reconstructed control bits.
7. Correlate against the COMrade-driven address to confirm the mapping.

Open question this resolves: **how Bowman raises interrupts to the VL82C420's 8259 pair over the
ML bus** — candidates are an encoded field in group 2 or an as-yet-unmapped sideband ball
(see [Chipset §11a](readme.md) caveat).

---

## 7. Practical / mechanical notes

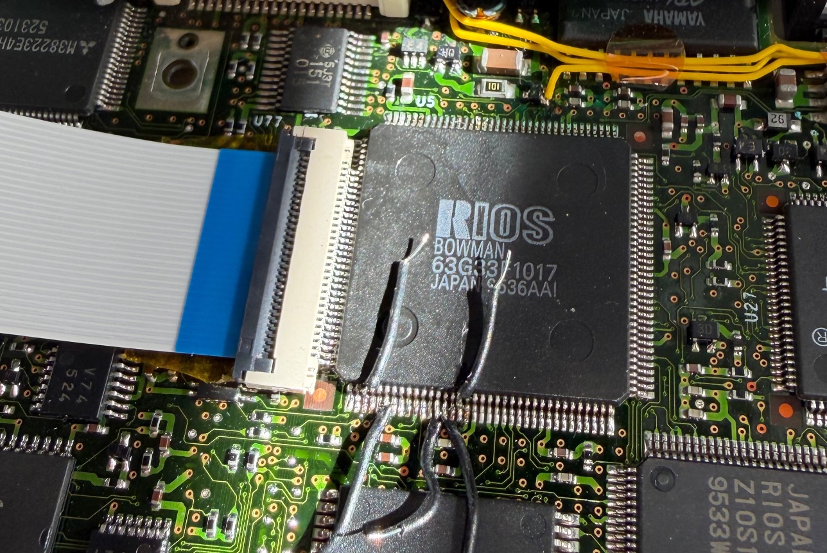
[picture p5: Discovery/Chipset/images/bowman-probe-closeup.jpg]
Bowman (U21) close-up with soldered probe taps


*Close-up of **Bowman (U21)** — marked `RIOS BOWMAN 63G33 1017 JAPAN S536AAI`, a 144-QFP. The probe
wires here are **soldered directly to the pins** with fine magnet wire rather than clipped — after grabber
clips kept slipping on the 0.5 mm pitch (and once crashed the machine), soldered taps gave reliable,
crash-free contact for the framing signals. The white FPC ribbon at left goes to the U77 flex connector.*

- **Pitch:** 0.5 mm QFP pins. The 24 address lines are all on the **pins-1–36 edge** — a 144-QFP
  test clip or a row of fine micro-hooks covers them in one go.
- `MLADS#` (52), `MLCLK` (39), and the control pins (41/42/49/50) are all on the **pins-37–72
  edge** — use individual micro-grabbers for those.
- **Ground:** tie several Saleae GND leads to a board `VSS` near Bowman; the 22 MHz edges need a
  short return path or you'll get ringing/false transitions.
- Verify each probe with a quick continuity/scope check before the run — a single lifted address
  line corrupts the whole group decode.

---

## 8. Next-session rewires (to break past the current probe limits)

The 2026-07-14 battery (§11e) exhausted what the current probe set can see. Both rewires below **keep
CH0–CH4 framing untouched** (MLADS# 52, MLCLK 39, CPU_ADS# 49, CPU_MIO# 50, CPU_WR# 42) and move only
CH5–CH15. Pins from [Bowman §3.1](../Bowman/readme.md).

### Rewire A — capture the ML **data** (low byte)
Goal: read the companion-cycle data payload. **Caveat: Bowman exposes only the low data byte `SD0–SD7`;
the high byte `SD8–15` is routed elsewhere (Pluto/chipset), so a Bowman-only tap gets 8 of 16 bits** —
enough to prove data-on-SD and read the low byte.

| CH | Signal | Pin | | CH | Signal | Pin |
|---:|---|----:|---|---:|---|----:|
| 5 | SD0 | 96 | | 10 | SD5 | 91 |
| 6 | SD1 | 95 | | 11 | SD6 | 89 |
| 7 | SD2 | 94 | | 12 | SD7 | 88 |
| 8 | SD3 | 93 | | 13 | A18 | 27 (region ref) |
| 9 | SD4 | 92 | | 14 | A19 | 29 (region ref) |
| | | | | 15 | A20 | 30 (region ref) |

`SD0–SD7` are on the **pins-73–108 edge** (side 3). Keep CH13–15 on A18–A20 to tag which region each
captured byte belongs to. **Method:** `mem_write(0xB8000, data)` with walking-1 low-byte patterns
(`0x01,0x02,0x04,…,0x80`) → map each SD bit to its pin at the data phase; then `mem_read` to read
companion data back.
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

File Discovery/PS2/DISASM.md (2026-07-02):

# PS2.EXE disassembly — the hardware interface, decoded

*This decodes **how `PS2.EXE` actually talks to the machine**, from a disassembly of the binary
(`ndisasm -b 16`) plus live probing of the same BIOS calls over [COMrade](../Live-Dump/). It is the
basis for re-implementing PS2's functions natively — see [`Software/PS2TUI`](../../Software/PS2TUI/),
which now performs the read paths itself with no `PS2.EXE` dependency.*
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

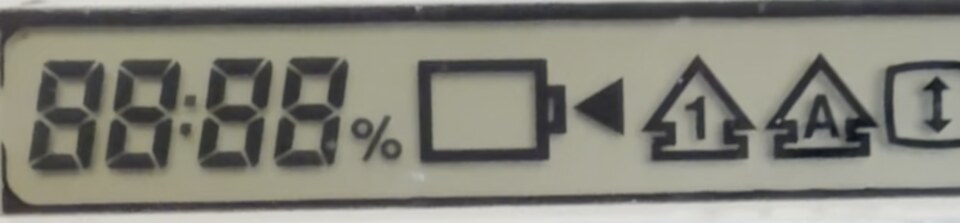
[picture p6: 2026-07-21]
Discovery/PSU-MB-M38/images/frontlcd_layout.jpg

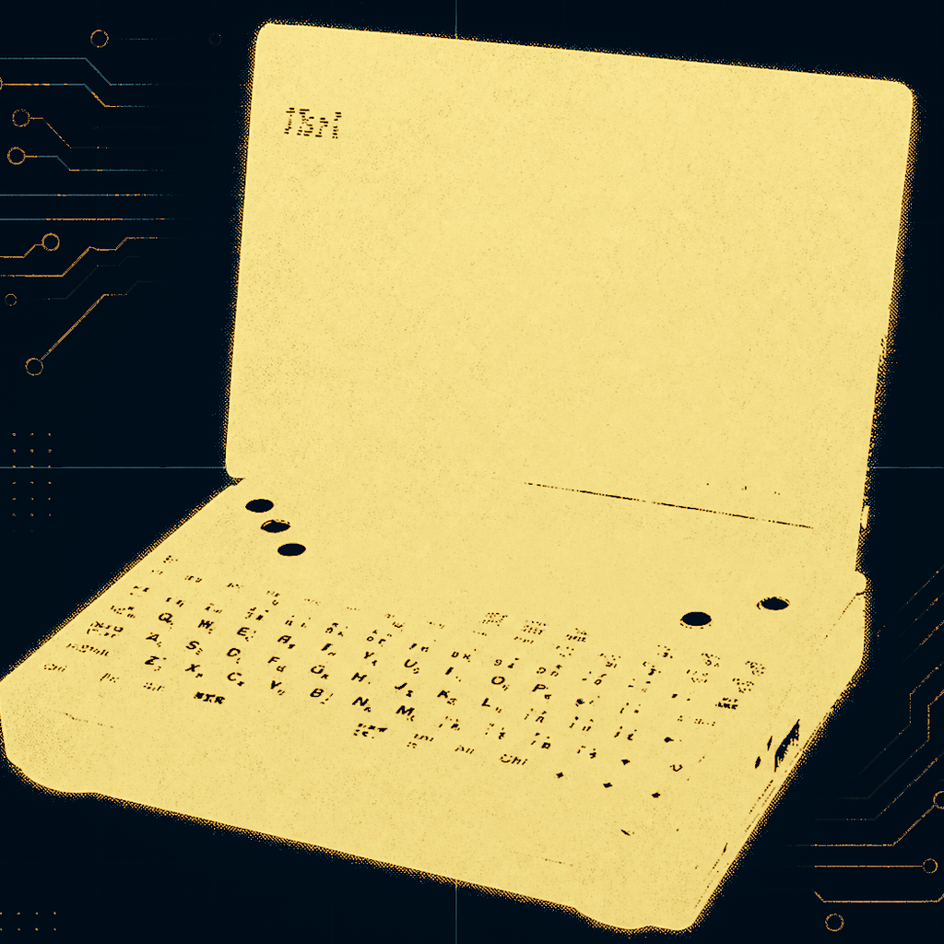
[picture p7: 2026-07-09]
Docs/branding/open-source-pc110-mark.png

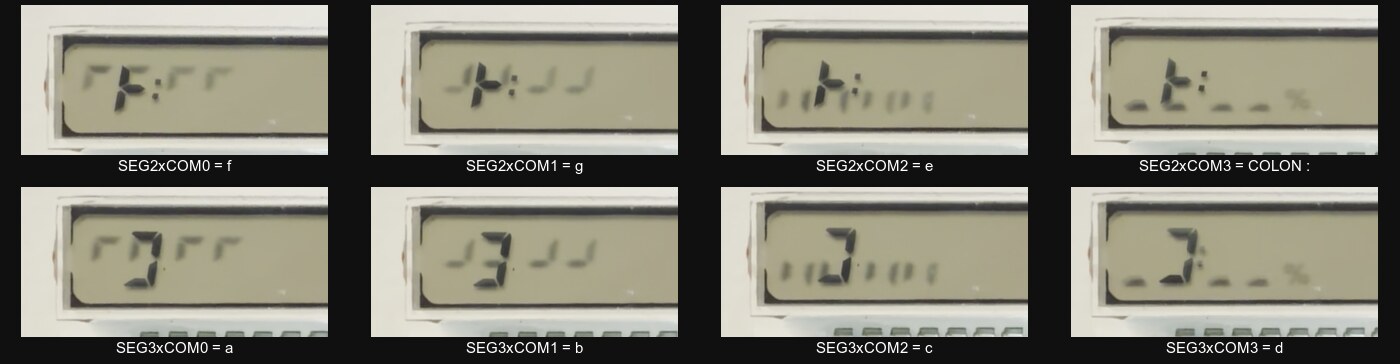
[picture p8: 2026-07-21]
Discovery/PSU-MB-M38/images/frontlcd_digit_scan.jpg

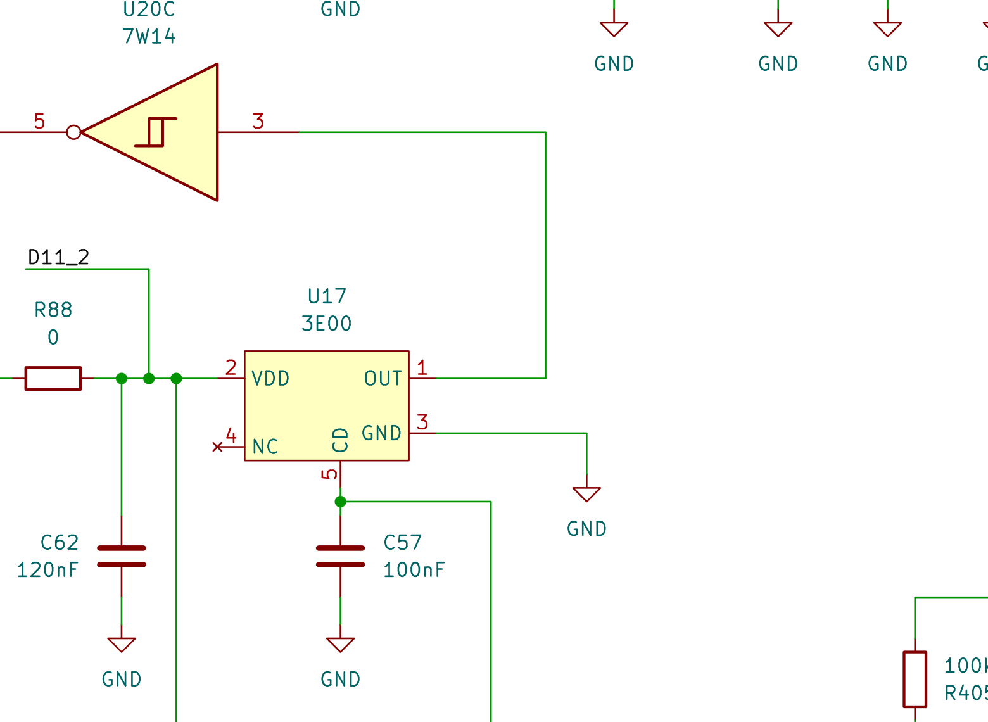
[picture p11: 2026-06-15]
Discovery/ES488/u17_osc.png

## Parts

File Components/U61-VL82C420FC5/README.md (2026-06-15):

## VL82C420FC5 - The SCAMP IV system controller

Screenshot 2025-04-10 at 7 49 05 AM

*The SCAMP IV system controller. A synthesis of everything recoverable from patents, decap
evidence, the Intel 486 SL datasheet, the IBM PC110 hardware/BIOS, and the reverse-engineered
208-pin map — since no official VL82C420 datasheet was ever published.*

> **Provenance & confidence.** No VLSI datasheet for this part exists publicly. Items below are
> tagged where useful: **[DS]** from the Intel 486 SL datasheet (architectural twin), **[PAT]** from
> VLSI patents, **[DECAP]** from die analysis, **[RE]** from the reverse-engineered pin map / PC110
> board, **[BIOS]** from PC110 BIOS disassembly, **[H]** hypothesis.

---

## Table of contents
1. Identity & summary
2. Part numbers & packages
3. Place in the SCAMP family (and the QuadNote sibling)
4. Internal architecture
5. The Multiplexed Local (ML) Bus
6. CPU interface (486 SL local bus)
7. DRAM controller
8. ISA bridge & ROM/flash
9. Integrated peripherals (DMA / PIT / PIC / RTC)
10. Power management
11. The patent family (de-facto documentation)
12. Pinout — the 208-signal map
13. Configuration registers (observed)
14. IBM PC110 implementation
15. Documentation status & how to learn more
16. Open questions
17. Sources

---

## 1. Identity & summary
The **VL82C420** is the **system controller** of VLSI Technology's **SCAMP IV** chipset, a three-chip
80486SL-class notebook/subnotebook solution announced by VLSI's **Portable Systems Division (Tempe,
Arizona)** in **June 1993** (samples August, volume October 1993). It integrates almost the entire
"motherboard" of a portable PC into one device.

| | |
|---|---|
| Family | SCAMP IV (VL82C420 + VL82C144 peripheral chip + optional VL82C146 ExCA) |
| Role | system controller: CPU local bus, DRAM controller, ISA bridge, integrated DMA/PIT/PIC/RTC, power management, ML-bus host |
| Process | 0.8 µm CMOS, **mixed 3.3 V / 5 V** |
| CPU | power-managed Intel 486SL-class, **up to 33 MHz**, incl. clock-doublers |
| Memory | up to **32 MB** DRAM |
| Interconnect | VLSI-proprietary **Multiplexed Local (ML) Bus** to the companion chips |
| Board cost | a full design needs **as few as 3 TTL parts**; up to **four** VL82C146s per system |
| 1k price (1993) | **$32.50** (VL82C144 $25.00, VL82C146 $8.50) |

## 2. Part numbers & packages
- **VL82C420FC4** — appears at brokers as new-old-stock; package/revision variant.
- **VL82C420FC5** — the variant used in the IBM PC110: a **256-ball BGA (16×16, rows A–T skipping
  I/O/Q, cols 1–16)**. **[RE]** Of 256 balls, **~208 are active signals** and the rest power/ground/NC.
- "FC" is VLSI's package/grade code; FC4 vs FC5 are minor variants/steppings.

## 3. Place in the SCAMP family
VLSI's "SCAMP" = **S**ingle-**C**hip **A**T, **M**id-range **P**erformance single-chip controllers:

| Gen | Parts | Year | CPU class |
|-----|---|---|---|
| SCAMP | VL82C310/311/311L | Jan 1992 | 286 / 386SX |
| SCAMP II | VL82C315 / VL82C316 / VL82C323 | late 1992 | 386 / 486, ≤33 MHz |
| **SCAMP IV** | **VL82C420** / VL82C144 / VL82C146 | **1993** | **486SL notebook** |

*(No publicly released "SCAMP III" is known — the numbering jumps from II to IV.)*

> **Sibling, not the same:** **QuadNote** (Feb 1994) = **VL82C410 + VL82C142** + the same VL82C146,
> from VLSI's *Personal Computer Division (San Jose)*, co-developed with **Compaq** and used in the
> **Contura Aero 4/25 and 4/33C**. QuadNote (410/142) is a close cousin of SCAMP IV (420/144) but a
> different chipset; the Contura Aero is **not** a VL82C420 machine.

## 4. Internal architecture
Decap of the PC110's VL82C420 die identifies its sub-blocks as licensed cores of standard parts,
matching the integrated-peripheral model and the patent block diagram:

| Block | Core | **[DECAP]** | Function |
|---|---|:---:|---|
| DMA | **82C37** (×2 cascaded) | ✓ | 7-channel ISA/floppy DMA |
| Timer | **82C54** | ✓ | system tick, refresh, speaker |
| Interrupts | **82C59** (×2) | ✓ | 15-level PIC |
| RTC/CMOS | **MC146818** | ✓ | clock/calendar + battery CMOS RAM |
| Memory ctlr | (VLSI) | — | DRAM RAS/CAS, up to 32 MB |
| ISA bridge | (VLSI) | — | full ISA bus |
| ML engine | (VLSI) **[PAT]** | — | multiplex system controller (US 5,793,990) |
| Power mgmt | (VLSI/Intel-licensed) | — | SMI/STPCLK#/suspend/resume |

Licensed technology: **Intel** 386SL/486SL power-management architecture, the **Intel 80C51**
core (embedded for keyboard control), **Intel 82365SL**-compatible ExCA logic (in the VL82C146), and
**Hewlett-Packard** infra-red comms (for the VL82C144 UART's IR mode).

## 5. The Multiplexed Local (ML) Bus  **[PAT: US 5,793,990]**
The proprietary interconnect between the VL82C420 and its companion chips. It exists to cut companion
pin count: the controller **tri-states the CPU's 32-bit address bus (via AHOLD)** and time-shares a
portion (A[25:2]) to send two 16-bit address groups then one 16-bit data group over the same wires.

**Control signals (5):**
| Signal | Dir (from controller) | Function |
|---|---|---|
| `MLCLK` | out | 1× bus clock, synchronous to CPU clock but separately gateable for power saving |
| `MLADS#` | out | address strobe — controller is driving valid addr/data on the CPU lines |
| `MLLBA#` | in | device asserts when it positively decodes its address; also indicates which CPU lines carry read data |
| `MLRDY#` | in/out | transfer complete / data valid; controller can assert it to terminate an unacked cycle |
| `Mpriority` | in | a higher-priority device can pre-empt/terminate an ML cycle |

Memory-I/O devices decode to **1 KB** granularity (first 16-bit group = A25–A10); I/O-only devices
decode to **4-byte** granularity. Cycle types documented in the patent: I/O read (high/low device),
I/O write, terminated I/O, memory read/write, terminated memory, and multiplex-DMA read/write. In the
PC110 these five lines are the `Bowman1–5` net group linking the VL82C420 to the IBM "Bowman" gate
array. **[RE]**

## 6. CPU interface (486 SL local bus)  **[RE + DS]**
Full 486 local bus with SL power-management extensions (matches the Intel 486 SL signal set):
`A[2..31]`, `D[0..31]`, `ADS#`, `BLAST#`, `BRDY#`, `RDY#`, `KEN#`, `HOLD`, `AHOLD`, `HLDA`, `W/R#`,
`D/C#`, `M/IO#`, `BE0-3#`, `EADS#`, `A20M#/A20GATE`, `RESET`, `SRESET`, `FLUSH#`, `INTR`, `NMI`,
`SMI#`, `SMIACT#`, `STPCLK#`, plus `LDEV#` (local-device-access, the patent's LBA# concept).
Clocking: `CPU_CLK`, `CPU_CLK_33`, `2XCPU_CLK` (for clock-doubled CPUs), `CPU_CLK_SENS`.

## 7. DRAM controller  **[RE]**
Up to 32 MB. Pins: `RAM_A[0..11]` (multiplexed row/col address), `RAM_RAS0-3` (four bank selects),
`RAM_UCASU#/UCASL#/LCASU#/LCASL#` (per-byte/upper-lower CAS), `RAM_WE#`. Standard FPM-DRAM controller
behavior; refresh driven by the integrated timer (`REFREQ`-style internal refresh).

## 8. ISA bridge & ROM/flash  **[RE + DS]**
ISA: `SA0/SA1/SA16`, `LA17–23`, `SD0–15`, `BALE`, `AEN`, `SBHE#`, `MEMR#/MEMW#`, `IOR#/IOW#`,
`MEMCS16#`, `IOCS16#`, `IOCHRDY`, `ZEROWS#`, `REFRESH#`, `ISA_SYSCLK`, `ISACLK2` (16 MHz osc in → 8 MHz
SYSCLK). Mid SA lines (SA2–SA15) are generated internally and not all bonded out (PCMCIA-only boards
have no ISA slots). ROM/flash: `ROMCS0#`, `ROMCS1#`, `BIOS_CE#`/`FLSHCS#`, `ROM16/8#`, `FDC_TC`.

## 9. Integrated peripherals  **[DECAP + BIOS]**
- **DMA** — 82C37 ×2 at ports `0x00–0x0F` / `0xC0–0xDF`, page regs `0x80–0x8F`; floppy uses a channel
  (`FDC_TC`).
- **Timer** — 82C54 at `0x40–0x43`; timer-2 → `SPKR`.
- **PIC** — 82C59 ×2 at `0x20/0x21` and `0xA0/0xA1` (15 IRQs).
- **RTC** — MC146818 at `0x70/0x71` with `RTCOSCI/RTCOSCO` (32.768 kHz), `RTCBAT`, `RTCBAT_RES/Sense`,
  `PS/RCLR#` (power-sense / RAM-clear), `RTC-SQW` (square-wave out) and `RTC-IRQ#` (alarm).

## 10. Power management  **[PAT + DS]**
SL-compatible. Key signals: `SMI#`/`SMIACT#` (System Management Mode), `STPCLK#` (stop CPU clock),
`SUS_STAT#` (suspend state), `PWRGD`. Features (per the announcement): socket power control, **3.3 V/5 V
suspend** with **modem & ring-resume** detection, and power-down on Windows inactivity. The embedded
80C51 keyboard controller lets OEMs reuse existing 386SL/486SL power firmware.
**US 5,715,467** details the event-driven scheme: it modifies `STPCLK#` so the CPU returns to full
speed to service "break events." A modem/ring-resume **wake input** is a VLSI addition beyond the stock
SL pin set. **[H: this is the still-unidentified `VL_F5` ball, between `SUS_STAT#` and `STPCLK#`]**

## 11. The patent family (de-facto documentation)
Filed by VLSI Tempe engineers (Jirgal, Evoy, Potts) around the 1993 launch:

| Patent | Title | Topic |
|---|---|---|
| **US 5,793,990** (WO 1994/029797) | Multiplex address/data bus with multiplex system controller | the ML bus + VL82C420 block diagram & timing |
| **US 5,715,467** | Event-driven power management control circuit | STPCLK#-based PM |
| **US 5,561,772** | Expansion bus replicating an internal bus as an external bus with logical interrupts | the "HCI" pin-count-reducing portable bus |
| **US 5,805,901** | Mapping interrupt requests in a high-speed CPU interconnect bus | ML-bus interrupt mapping |
| **US 5,655,142** | High-performance derived local bus | deriving a CPU-style bus from the multiplexed peripheral bus |
| **US 5,652,847** | Multiplexing data and a portion of an address on a bus | address/data muxing detail |
| **US 5,958,055** | Power management system for a computer | PM architecture |

## 12. Pinout — the 208-signal map  **[RE]**
The reverse-engineered map (256-ball BGA, ~208 active) breaks down as:

| Group | Count | Examples |
|---|---:|---|
| CPU address + control | ~33 | A[2..31], ADS#, BLAST#, BRDY#, RDY#, KEN#, HOLD/AHOLD/HLDA, BE0-3#, etc. |
| CPU data | 32 | D[0..31] |
| CPU power-mgmt | ~6 | SMI#, SMIACT#, STPCLK#, SUS_STAT#, SRESET, A20GATE |
| ISA bus | ~30 | SA/LA/SD, MEMR#/W#, IOR#/W#, BALE, SBHE#, MEMCS16#, IOCS16#, IOCHRDY, ZEROWS#, REFRESH# |
| DRAM | 20 | RAS0-3, UCAS/LCAS ×, MA0-11, WE# |
| RTC | 6 | RTCOSCI/O, RTCBAT, RTCBAT_RES, RTC-SQW, RTC-IRQ# |
| ML bus | 5 | MLCLK, MLADS#, MLLBA#, MLRDY#, Mpriority |
| Clocks | ~5 | CPU_CLK, CPU_CLK_33, 2XCPU_CLK, ISA_SYSCLK, ISACLK2, 32KHz |
| ROM/misc | ~6 | ROMCS0#, ROMCS1#, FDC_TC, SPKR, KB_RESET, RESET |
| Power/ground | ~20 | VCC (main), VCC2 (3.3 V), VSS/GND |

**~95% identified** by cross-referencing the **Intel 486 SL** datasheet (architectural twin). The only
group with **no** external analog is the ML bus (VLSI-proprietary). Remaining unknown balls and best
candidates: `VL_K16`→`ISACLK2` [H-high]; `VL_F5`→ring/EXTSMI wake [H]; `VL_F15/F16`→`MASTER#`/`ROM16/8#`
[H]; `VL_T8`→test/config strap (Turbo/SELFTEST/ONCE# class) [H]; `VL_A14/B14/C14/A15`→likely VCC corner
balls [H]; `VL_P13/L11/R12/N10`→board-specific. `TP1` (ball T14) → a test pad, likely an `ONCE#`-class
test/tri-state control.

## 13. Configuration registers (observed)  **[BIOS]**
The PC110 BIOS programs the chipset largely through a `0x4F` config-latch/index plus direct config
ports. POST writes these `0x4F` indices: **0x11, 0x66, 0x70, 0x0A, 0x1E, 0xB6, 0x8F, 0x65, 0xBF, 0xFF**.
Other config writes: `0x22/0x23` unlock (`←0x80`), `0x8B` (`←6F,0A,80,70,71`), `0x98←BF`, `0xF1←65`,
SCAMP indexed pair `0x74/0x76` (index `0x80`). Exact register *semantics* remain to be mapped (the
emulator path: trace these index→data transactions live).

## 14. IBM PC110 implementation  **[RE]**
- The VL82C420FC5 is **U61** (BGA256); it pairs with the IBM custom gate-array ASIC **"Bowman" (U21)**
  over the 5-line ML bus (`Bowman1–5`).
- Integrated-RTC outputs `RTC-SQW`/`RTC-IRQ#` route (via an HD151015 bus switch) to the **M38223
  power-sense MCU**.
- Two pulled-up strap inputs (`PullDN1/2`, balls R8/N8) set chipset config/test mode.
- Board CPU debug: headers **J9 (Debug-10)** and **J12 (Debug-6)** expose the 486's HOLD/AHOLD/cache/
  reset control signals + a JTAG TAP — a HOLD-method ICE/debug interface.

## 15. Documentation status & how to learn more
- **No datasheet/databook** for the VL82C420 exists on bitsavers, DatasheetArchive, DOS Days, or
  The Retro Web (bitsavers' VLSI PC collection stops at the VL82C114, March 1993).
- **Best authoritative sources:** the patents above (esp. US 5,793,990); the **Intel 486 SL** /
  **82360SL** datasheets (architectural twin) for ~95% of the pins; standalone **82C37/82C54/82C59A/
  MC146818** datasheets for the integrated cores; and the predecessor **SCAMP / SCAMP II** data manuals
  on bitsavers.

## 16. Open questions
1. Exact `0x4F`/`0x22`/`0x8B` register semantics (DRAM timing, decode windows, PM control).
2. `VL_F5` — the ring/modem-resume wake input (VLSI-specific, not in the Intel datasheet).
3. `VL_A14/B14/C14/A15` — confirm as VCC vs extra DRAM `MA12`.
4. The exact ML-bus 1:1 mapping of `Bowman1–5` (which line is MLCLK/MLADS#/…).

## 17. Sources
- Patents: [US 5,793,990](https://patents.google.com/patent/US5793990A/en),
  [US 5,715,467](https://patents.google.com/patent/US5715467A/en),
  [US 5,561,772](https://patents.google.com/patent/US5561772A/en),
  [US 5,805,901](https://patents.google.com/patent/US5805901A/en),
  [US 5,655,142](https://patents.google.com/patent/US5655142A/en).
- Trade press: [Tech Monitor, "VLSI Technology has 80486SL notebook chip set," 17 Jun 1993](https://www.techmonitor.ai/technology/vlsi_technology_has_80486sl_notebook_chip_set);
  [QuadNote/Compaq, 10 Feb 1994](https://www.techmonitor.ai/technology/vlsi_technology_offers_compaqs_80486_sub_notebook_chip_set).
- [The Retro Web — SCAMP IV](https://theretroweb.com/chipsets/568).
- [DOS Days — VLSI Technology](https://www.dosdays.co.uk/topics/Manufacturers/vlsi.php).
- Intel 486 SL datasheet (Intel 241325 / "KU82360" scan) — architectural twin.
- IBM PC110 schematic, BIOS dump, and the reverse-engineered `vl82c420_pinmap.xlsx` (Open-Source-PC110).
- Companion reconstructed docs in this project: `VL82C420_Technical_Reference.pdf`,
  `VL82C420_vs_486SL_reconciliation.md`, `PC110_VL82C420_analysis.md`, `SCAMP_IV_dossier.md`.

*Compiled from the full Open-Source-PC110 investigation. Where the chip's behavior is inferred rather
than documented, it is tagged; the ML bus and the `0x4F` register set are the parts still lacking
official documentation.*

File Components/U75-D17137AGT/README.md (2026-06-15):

## D17137AGT — Trackpad Controller

D171

---

## 1. Summary

**U75** is the **trackpad (pointing-device) controller** on the IBM PC110 motherboard. Instead of a dedicated touch ASIC, the design uses a small general-purpose **4-bit microcontroller** running firmware that scans the capacitive/resistive pad matrix, reads the physical click buttons, and reports pointer movement to the host over a PS/2-style clock + data interface.

| Field | Value |
|---|---|
| Reference designator | **U75** |
| Part number (Value) | **D17137AGT** (NEC µPD17137A) |
| Device class | 4-bit single-chip microcontroller (NEC "17K" / µPD17134A subseries) |
| Footprint | **PC110:SSOP-28** (28-pin shrink small-outline package) |
| Schematic description | "Trackpad Controller" |
| Net-naming prefix | `D171_` (derived from the part number) |
| Source document | `Mainboard.pdf` — *PC110 Motherboard*, generated by KiCad Eeschema |

---

## 2. The part: NEC µPD17137A

`D17137AGT` decodes to NEC's **µPD17137A**, a member of the **µPD17134A subseries** of NEC's **17K-family 4-bit single-chip microcontrollers** (circa early 1990s). The leading `D` is NEC's standard prefix (µPD), and the `GT` suffix denotes the package option.

Key characteristics of the family:

- 4-bit CMOS single-chip microcontroller architecture.
- On-chip ROM/RAM, timer, and general-purpose I/O ports organized into nibble-wide ports (P0A, P0B, P0C, P1A, P1B …).
- Designed for low-cost embedded control tasks — exactly the role it plays here, scanning a pointing-device sensor and emulating a mouse.

Using a programmable MCU (rather than fixed-function silicon) is why the schematic exposes raw port lines (`P0A0`, `P0B1`, etc.) directly to the pad — the scanning logic lives in firmware.

---

## 3. Connections / net map

All I/O nets carry the `D171_` prefix (after the part number). Grouped by function:

### Pad sensing matrix (scan / sense lines)
These read finger position off the trackpad surface.

- **Port 0A:** `/D171_P0A0`, `/D171_P0A1`, `/D171_P0A2`, `/D171_P0A3`
- **Port 0B:** `/D171_P0B0`, `/D171_P0B1`, `/D171_P0B2`, `/D171_P0B3`
- **Port 0C:** `/D171_P0C2`, `/D171_P0C3`
- **Port 1A:** `/D171_P1A0`, `/D171_P1A1`, `/D171_P1A2`, `/D171_P1A3`
- **Port 1B:** `P1B0` (appears as the auto-named net `Net-(U75-P1B0)`)

### Button inputs
- `/TRKPD_Lclick` — left physical click button
- `/TRKPD_Rclick` — right physical click button

### Host interface (pointer data out)
- `/D171_GPCLK` — PS/2-style clock line
- `/D171_GPDATA` — PS/2-style data line

### Control
- `Net-(U75-INT)` — interrupt line

### Power
- **`PNET3`** — supply rail
- **`GND`** — ground

---

## 4. Support circuitry around U75

### Decoupling / bulk capacitors
| Ref | Value | Footprint |
|---|---|---|
| C87 | 120 nF | C_0402_1005Metric |
| C126 | 150 nF | C_0402_1005Metric |
| C135 | 2.7 µF | C_0805_2012Metric |

### Resistors (pull-ups / dividers)
| Ref | Value | Notes |
|---|---|---|
| R196 | 47 k | |
| R197 | 47 k | |
| R198 | 10 k | |
| R200 | 47 k | |
| R201 | 100 k | |
| R203 | 10 k | |
| R204 | 47 k | |
| R205 | 100 k | |
| R206 | 47 k | |
| R199 | DNP | not populated |
| R202 | DNP | not populated |

All resistors use the `R_0402_1005Metric` footprint.

---

## 5. Board neighborhood

U75 sits in a dense region of the motherboard alongside the core system controllers, and the CPU data bus (`/CPU_D28`–`/CPU_D31`) routes nearby.

| Ref | Value | Role | Package |
|---|---|---|---|
| **U51** | CHIPS65535 | Chips & Technologies VGA / LCD controller | BGA-169 |
| **U74** | RB5C396 | Ricoh PC-Card / power controller | BGA-256 |
| **U75** | D17137AGT | Trackpad controller | SSOP-28 |

Other nearby nets observed: `Net-(C135-+)`, `Net-(C281--)`, `Net-(C283-+)`, and power net `PNET3`.

---

## 6. Functional picture

```
                 +-------------------------+
  Pad matrix --->|  P0A0..P0A3             |
  (rows/cols)    |  P0B0..P0B3             |
                 |  P0C2, P0C3             |
                 |  P1A0..P1A3, P1B0       |
                 |                         |
  L/R buttons -->|  TRKPD_Lclick           |---> GPCLK  (PS/2 clock) --> host KBC
                 |  TRKPD_Rclick           |---> GPDATA (PS/2 data)  --> host KBC
                 |                         |
                 |  U75  (NEC uPD17137A)   |---> INT (interrupt)
                 |  SSOP-28, 4-bit MCU     |
                 +-----------+-------------+
                       PNET3 |  | GND
                             |  |
                        decoupling: C87, C126, C135
```

The MCU continuously drives/reads the port lines to scan the pad, debounces the two click inputs, and streams the resulting pointer packets to the system's keyboard/mouse controller over the `GPCLK`/`GPDATA` pair.

---

## 7. Sources

- [Reverse Engineering The IBM PC110, One PCB At A Time — Hackaday](https://hackaday.com/2025/04/06/reverse-engineering-the-ibm-pc110-one-pcb-at-a-time/)
- [Open-Source-PC110 — GitHub](https://github.com/ahmadexp/Open-Source-PC110)
- [µPD17137A 4-bit single-chip microcontroller datasheet (NEC)](https://datasheetspdf.com/datasheet/UPD17137A.html)
- [1992 NEC 17K 4-bit Microcontroller Data Book — bitsavers.org](https://www.bitsavers.org/components/nec/_dataBooks/1992_NEC_17K_4-bit_Microcontroller_Data_Book.pdf)
- Primary source: `Mainboard.pdf` (PC110 Motherboard schematic, KiCad Eeschema export)

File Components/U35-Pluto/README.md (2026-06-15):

# Pluto - Central I/O hub

Pluto

## In one sentence

Pluto is a custom, undocumented IBM gate-array chip (a 100-pin QFP ASIC, reference designator U35) that acts as the central I/O hub of the IBM PalmTop PC110 — the part that sits between the CPU and almost every "slow" device in the machine and decides what talks to what.

## What it actually is

The PC110 was a mid-1990s subnotebook built around a BGA-packaged 486SX-33 plus a small set of custom large-scale-integration chips that IBM (or its design partner) gave informal code names: Pluto, Bowman, and Rios. None of these parts ever had a public datasheet. Everything known about Pluto today comes from reverse engineering — optical and X-ray scans of the silicon, plus painstaking net-by-net tracing of the motherboard schematic. The description here is the picture that emerges from that work, so some pin names are confirmed function and others are still educated guesses.

In the language of the schematic, Pluto is the system's **I/O glue and peripheral controller**. It behaves as a slave on an ISA-style local bus: it receives an 8-bit data bus (SD0–SD7), a 16-bit address bus (SA0–SA15), and the standard bus control strobes — I/O read (IOR#), I/O write (IOW#), and address enable (AEN). The CPU reads and writes Pluto's internal registers over that bus, and Pluto in turn fans the bus out to the rest of the laptop. Where it makes sense, Pluto doesn't do all the latching itself; it offloads some timed/latched logic to a handful of ordinary external 74-series flip-flops (U30, U40, U45, U53).

## What it connects to

Think of Pluto as a switchboard. On one side is the CPU's local bus; on the other side is essentially every peripheral subsystem in the machine:

The **keyboard subsystem** is one of the biggest. Pluto presents the keyboard to the CPU like a classic 8042-style controller: it provides the chip-select (KB_CCS), control and reset lines (KB_CNTR#, KB_RESET#), and two speaker drive lines (volume up/down). The other end of those wires is a separate on-board keyboard microcontroller (more on that below).

For **storage and expansion**, Pluto handles the floppy interface (four FDD I/O lines plus a write strobe), CompactFlash/PCMCIA card-detect, and docking-station detect. For **communications**, it gates the RS-232 serial transceivers, drives the IrDA infrared transmitter and its enable, and carries a control line to the internal modem. For **display and power management**, it deals with the CPU stop-clock line, power-good and power-on sense, the LCD bias-rail enable, and LCD standby.

Pluto also has a direct hand in the **BIOS**: it controls the flash write-enable and supplies an extra high address bit (BIOS_SA17), meaning it governs how the BIOS ROM is banked and reflashed. It even reads two **RAM module identity straps** so firmware can tell what memory is installed. And it has dedicated lines to its sibling ASIC, **Bowman**, with which it shares some of the workload.

## How far it reaches (cross-module findings)

Cross-checking Pluto's nets against the docking-station, modem, and RAM-module schematics confirmed several things that had been guesses, and showed Pluto reaches well beyond the motherboard:

- **It is the floppy controller** — but the drive lives in the docking station. Pluto's FDD lines (pins 68–71) and write strobe (pin 58) route out to the dock's floppy connector, which carries the full classic floppy interface. This job is split with Bowman.
- **It is the serial/dock power manager.** Pluto's RS-232 enable (pin 77) appears all over the dock, switching on the serial line drivers and level shifters — so Pluto decides when the docked serial port is actually live.
- **It is the modem's control-bus master.** Pin 75 connects to the internal modem's Panasonic MN195001 DSP/codec, tapping its voice-serial data line. (The schematic label "NM192" is almost certainly a transcription error for "MN195.")
- **It is the RAM-module ID reader.** Pins 31/32 sample two identity bits from the memory module so firmware can size installed RAM. (The actual DRAM timing is done by the chipset, not Pluto — only the ID detect touches Pluto.)

So Pluto is much more than a generic bus buffer: it is simultaneously the floppy controller, the serial/dock power manager, the modem control-bus master, and the RAM-module ID reader. The dock, modem, and RAM module are effectively extensions of Pluto's I/O fan-out.

## Who built it — the authorship lead

The on-board keyboard microcontroller on the other end of Pluto's keyboard pins is a Mitsubishi M38813E4HP (a 6502-compatible 8-bit MELPS 740 micro). Its mask-ROM dump contains a plain-text banner:

> "MELPS 740 Series Keyboard Firmware Version 1.1 (C) Copyright 1992-1995 RIOS Systems Co., Ltd."

That is a concrete attribution. The Japanese design house **RIOS Systems Co., Ltd.** wrote the keyboard firmware — and "Rios" is itself one of the PC110 custom-chip codenames, alongside Pluto and Bowman. That strongly suggests the whole custom-silicon family (Pluto / Bowman / Rios) plus its firmware originated at RIOS Systems rather than IBM's in-house gate-array group. It's currently the best lead on who actually designed Pluto.

## What's still unknown

The reverse-engineering picture is solid on connectivity but incomplete on internal behavior. The biggest open item is Pluto's **register map** — exactly what each bus read/write does inside the chip — which can't be recovered from the schematic alone and needs bus-trace capture or BIOS disassembly. A few pin names (notably pins 50, 55–57, and 74) are still placeholders, the external flip-flop network deserves its own diagram, the precise floppy split between Pluto and Bowman needs mapping, and the X-ray die shots could still confirm the true package details. The pin-75 "NM192" label should almost certainly be corrected to "MN195."

---

*Source: reverse-engineering documentation of the IBM PC110 (Open-Source-PC110 project), derived from the PC110 motherboard schematic and cross-referenced docking-station, modem, and RAM-module sheets.*

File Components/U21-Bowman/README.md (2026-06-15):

# Bowman (U21) — The IBM PC110 System Controller

bowman

## Overview

**Bowman** is the codename, carried in the value field of reference designator **U21**, for the IBM PC110 palmtop's main system-controller ASIC. It is a roughly 144-pin custom gate array (QFP-class) that sits at the center of the machine, bridging the 80486SX CPU's fast local bus to a slower 16-bit ISA-style system bus while soaking up nearly all of the computer's glue logic. In a desktop PC of the era this work would have been spread across a multi-chip chipset and a board full of discrete logic; in the PC110 it is consolidated into one part.

Bowman corresponds to the documented custom **RIOS** chip that "controlled the ISA bus and expanded the bus width to 16 bits." The PC110 was co-developed in 1995 by IBM Japan and Ricoh (the RIOS partnership), and its 486SX-33 CPU and several support chips carry RIOS markings. "Bowman" is the project/schematic codename — there is no public datasheet for the part, and the name is almost certainly an internal codename rather than an IBM or RIOS part marking.

## What it does

The CPU never talks directly to the peripheral bus. Instead, the 80486SX (U76, a BGA256 part) communicates only with Bowman over its local bus, and Bowman translates those CPU cycles into 16-bit ISA bus cycles. From that central position Bowman performs the full set of "chipset" jobs:

- **CPU bus interface** — accepts the 486 address bus (A2–A25, with A0/A1 implied by byte-enables) and the control signals ADS#, M/IO#, D/C#, W/R#, RDY#, INTR, RESET and the CPU clock.
- **ISA bus generation** — drives the system address bus (SA0–SA15), the low byte of system data (SD0–SD7), and the I/O control strobes (IOR#, IOW#, AEN, MEMCS16#).
- **Interrupt aggregation** — collects roughly fifteen interrupt sources (IRQ2–IRQ15 plus the keyboard's IRQ1 and the audio chip's ESS_IRQ1) in the manner of a pair of cascaded 8259 controllers and presents a single INTR to the CPU.
- **DMA handshaking** — manages floppy and peripheral DMA requests and acknowledges (FDRQ, PDRQ, DACK#, PDACK#) including a dedicated channel for the ESS audio device.
- **ROM/BIOS decode** — generates the high ROM address lines (ROMA12–ROMA19) and the chip-enable (ROMCE#) for the system Flash BIOS.
- **Keyboard / power-management link** — a 12-line parallel bus (M38_IO1–12) connects Bowman to U67, the Mitsubishi M38813M4 microcontroller that handles the keyboard and power management, plus dedicated keyboard reset and scroll-lock-LED lines.
- **Power sequencing and housekeeping** — power-good in/out, PSU control I/O, the 24 MHz reference and 32.768 kHz timekeeping clocks, and the volume up/down button inputs.

## Bowman and Pluto

Bowman does not work alone. A companion custom chip, **Pluto (U35)**, a roughly 100-pin ASIC, handles the lower-speed peripheral I/O: CompactFlash and dock detection, the LCD, IrDA, RS-232 enable, floppy data lines, the keyboard speaker, RAM identification, and BIOS write-enable. The two custom chips share the SA/SD bus and coordinate over dedicated status lines — Bowman exposes a `Pluto_IO` pin, while Pluto carries `Bowman_IO1` and `Bowman_IO2`. The exact division of labour passing over those lines is one of the open questions in the reverse-engineering effort. Together, Bowman and Pluto replace what would otherwise be a conventional chipset plus an embedded controller.

## The peripherals on the far side

Through the 16-bit ISA-style bus that Bowman creates, the system reaches its peripherals: CompactFlash mass storage, PCMCIA slots, the Yamaha YM3812 (OPL2) FM synthesizer with its YM3014B DAC, and the ESS AudioDrive (ES488) Sound Blaster-compatible audio. Local support components clustered around U21 on the board — pull-up resistors, a couple of transistors, a flip-flop for reset timing (74LVT74), and a TPS2201 PCMCIA power switch — and a shared power-sequencing network suggest Bowman also oversees card-slot power-up and reset timing.

## Pin summary

| Attribute | Value |
|---|---|
| Reference designator | U21 |
| Value / codename | Bowman |
| Function | System controller / CPU-to-ISA bridge ("chipset") |
| Pin count | ~144 (QFP-class custom gate array) |
| CPU interface | 80486SX-33 local bus (U76, BGA256) |
| Companion controller | U35 "Pluto" |
| Power rails | VCC/VCC2 on 13 pins; GND on 8 pins; 3 no-connects |

## Notable open questions

A few details remain unresolved in the project. The CPU address bus to Bowman starts at A2, so it is worth confirming how byte-enables (BE#) are routed, if at all. More intriguingly, Bowman exposes only the low data byte (SD0–SD7) even though its documented job is the *16-bit* bus expansion that CompactFlash relies on (SD0–SD15) — the high-byte steering is presumably handled via the `ADDHI` qualifier, the internal `Chipset_IO` lines, or in concert with Pluto, and tracing that against board X-rays would settle it. Finally, if die photos or X-rays ever reveal the laser/silk markings on the package, the true RIOS part number could replace the "Bowman" codename in the bill of materials.

---

*Source: schematic `Mainboard.pdf` ("PC110 Motherboard", KiCad), part of the [Open-Source-PC110](https://github.com/ahmadexp/Open-Source-PC110) reverse-engineering project, with corroborating teardown reporting from Hackaday, iPhone Wired, and ThinkWiki.*

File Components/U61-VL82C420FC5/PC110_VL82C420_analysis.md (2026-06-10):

# PC110 schematic expansion — VL82C420 (U61) analysis

Scope: crack the `UNKNOWN1–4` balls, consolidate the VL82C420 pinout, and cross-check against
the patent-derived reference and companion datasheets. Source: your `PC110-Singlesheet-Schematic.pdf`
(KiCad, "PC110 Motherboard"), read directly. Confidence is tagged **[C]** confirmed-from-sheet,
**[H]** hypothesis, **[?]** uncertain/needs probing.

---

## 1. Chip identities (corrected)

Two distinct large chips were being conflated. They are **not** the same part:

| Ref | Part | Package | Role |
|-----|---|---|---|
| **U21** | **"Bowman"** — IBM custom **gate-array ASIC** | QFP (pins 1–~144) | ROM addressing (`ROMA12–19`, `ROMCE#`), M38 keyboard-MCU interface (`M38_IO1–12`), VGA address-high, 5-bit chipset link (`Chipset_IO1–5`), `CPUCLK`, `LDEV#` |
| **U61** | **VLSI VL82C420FC5** — SCAMP IV system controller | **BGA256** (A–T × 1–16) | 486 local bus, DRAM control, ISA bridge, RTC, clocks, power management, PCMCIA glue. **Carries `UNKNOWN1–4`.** |

So every unknown ball is on the **VL82C420** — the one chip we have patent data for (US 5,793,990).
The nets `Bowman1–5` are the **inter-chip link** between VL82C420 balls `N9/P9/R9/T9/T13`
(pin-named `Chipset_IO1–5` on the ASIC side, U21 pins 45/40/39/52/130). See §4.

---

## 2. Confirmed VL82C420 (U61) pinout — high-confidence balls

Read directly off the sheet. This is, as far as I can tell, the first consolidated public
VL82C420 ball map. (Full 256-ball transcription is feasible but bulk text extraction collides
with neighbouring BGAs; the groups below were visually verified.)

### 486 local-bus interface  [C]
| Ball | Pin name | Net |
|---|---|-----|
| N2 | CPU_ADS# | CPU_ADS# |
| L1 | CPUBE0# | CPU_BE0# |
| L4 | CPUBE1# | CPU_BE1# |
| K3 | CPUBE2# | CPU_BE2# |
| K2 | CPUBE3# | CPU_BE3# |
| L2 | CPUWR# | (W/R#) |
| L6 | CPURDY# | CPU_RDY# |
| M2 | CPUKEN# | CPU_KEN# |
| M3 | CPUBRDY# | CPU_BRDY# |
| L5 | CPU_AHOLD | CPU_AHOLD |
| M4 | CPU_LDEV# | CPU_LDEV# |
| T7 | CPU_DC# | CPU_DC# |
| H3 | CPU_A20M# | CPU_A20M# |
| E1 | CPU_STPCLK# | CPU_STPCLK# |
| F2 | CPU_SMI# | CPU_SMI# |
| G3 | CPU_NMI | CPU_NMI |

(Plus the full CPU_A[2..31] / CPU_D[0..31] busses on the A/B/C-row balls.)

### Clocks, RTC, reset, power  [C]
| Ball | Pin name | Net |
|---|---|-----|
| K1 | Chipset_CPU_CLK | CPUCLK out |
| R2 | CPU2XCLK | Chipset_2XCPU_CLK |
| R15 | CLOCK_IN | Chipset_CLK |
| H16 | PCMCIA_CLK | PCMCIA_CLK |
| T11 | RTCBAT | RTC battery |
| P10 | RTCBAT_Sense | RTC battery sense |
| R11 | RTCOSCI | 32.768 kHz xtal in |
| P11 | RTCOSCO | 32.768 kHz xtal out |
| M11 | PS/RCLR# | power-supply / RAM-clear |
| N13 | RESET | system reset |
| R10 | PWRGD | power-good |
| P13 | PWRGD_P13 | power-good (2nd) |
| T14 | TP1 | test point |

### ISA / peripheral control  [C]
| Ball | Pin name | Net |
|---|---|-----|
| J14 | IOW# | IOW# |
| J15 | IOR# | IOR# |
| F13 | MEMR# | MEMR# |
| G14 | MEMW# | MEMW# |
| J16 | IOCS16# | IOCS16# |
| F12 | SBHE# | PCMCIA_SBHE# |
| G16 | AEN | AEN |
| E14 | REFRESH# | PCMCIA_REFRESH |
| N11 | FDCTC / FDC_TC | Chipset_FDC_TC |
| G15 | BIOS_CE# | Chipset_BIOS_CE# |

### Inter-chip link to Bowman ASIC  [C]
| Ball | Pin name | Net | → U21 (Bowman) |
|---|---|-----|---|
| N9 | Chipset I/O 1 | Bowman1 | pin 45 |
| P9 | Chipset I/O 2 | Bowman2 | pin 40 |
| R9 | Chipset I/O 3 | Bowman3 | pin 39 (via R149 33Ω) |
| T9 | Chipset I/O 4 | Bowman4 | pin 52 |
| T13 | Chipset I/O 5 | Bowman5 | pin 130 |

---

## 3. Cracking UNKNOWN1–4

The four unknowns split into **two pairs** that behave very differently on the sheet:

### UNKNOWN1 = ball **R13**, UNKNOWN2 = ball **N12**  — *connected, real signals*
Both route off-chip through **U7 (HD151015 bus switch)** onto the shared "Device_Address_BUS"
that also carries the link to the Bowman ASIC. On U7's A-side they sit in this group:

```
U7.A0 = UNKNOWN1   U7.A3 = KB_SRDY#    U7.A6 = Pluto_EN_IRDA
U7.A1 = UNKNOWN2   U7.A4 = KB_SCLK#    U7.A7 = SA0
U7.A2 = (Bowman5)  U7.A5 = PWRGD       U7.A8 = GND
```
Physical neighbours on the BGA: `M11 PS/RCLR#`, `N13 RESET`, `N11 FDCTC`, `R10 PWRGD`,
`P10/P11/R11/T11` (RTC). So R13/N12 are in the **system-control / power / device-select corner**,
and they are switched onto a bus alongside keyboard-serial and chip-select-like signals.

**Ranked hypotheses**
1. **[H, high]** General-purpose I/O / programmable device-select (GPIO / GPCS) from the VL82C420,
   muxed by the HD151015 onto the device-address/select bus shared with the ASIC. The company they
   keep (KB serial, IrDA-enable, SA0, a chip-select bus) fits SCAMP-family GPIO/GPCS pins.
2. **[H, med]** A second low-speed serial / strobe pair extending the keyboard-MCU interface
   (immediate neighbours of `KB_SRDY#`/`KB_SCLK#`).
3. **[H, med]** Power-management discretes (suspend/resume handshake) — adjacency to `PS/RCLR#`,
   `RESET`, `PWRGD`; SCAMP IV advertised "3.3 V/5 V suspend with modem and ring-resume."

**Fastest way to confirm:** with the board off, buzz `R13`/`N12` to the HD151015 A0/A1 (already
shown), then trace the matching **B-side** pins to their destination on the Bowman ASIC / keyboard
section — that destination names the function. Powered, scope them against `KB_SCLK#`: if they
toggle in lock-step they're part of the serial/scan group; if static they're selects/PM.

### UNKNOWN3 = ball **R8**, UNKNOWN4 = ball **N8**  — *no external connection traced*
These appear **only at U61** (no net endpoint elsewhere) — i.e. currently floating / no-connect /
untraced. Critically, they sit one column inboard of the inter-chip link balls
`N9/P9/R9/T9` (the `Bowman1–5` group).

**Ranked hypotheses**
1. **[H, high]** Additional inter-chip (VL82C420 ↔ Bowman) link lines that are **unused in the PC110**
   — i.e. the chip's `Chipset_IO` / ML-bus group is wider than 5, and `R8/N8` are the next lines,
   left unconnected on this board. Their position immediately beside `N9/R9` is the main evidence.
2. **[H, med]** Reserved / factory-test / NC balls.
3. **[?]** If powered measurement shows them tied to a rail internally, they could be unrouted
   power/ground (less likely — VCC/VSS balls are labelled elsewhere).

**Fastest way to confirm:** continuity-check `R8`/`N8` to every nearby net and to VCC/VSS; if truly
isolated, mark as **NC/reserved**. On a known-good board, a quick scope during boot will show
whether they ever switch (→ active link line) or stay static (→ NC/reserved).

---

## 4. The `Bowman1–5` bus and the ML-Bus cross-reference  [H]

`Chipset_IO1–5` (VL82C420) ↔ `Bowman1–5` ↔ ASIC is a **5-line control link** between the system
controller and the IBM gate-array. US 5,793,990 (the VL82C420 designers' patent) defines the
**Multiplexed Local (ML) Bus** control set as exactly: `MLCLK, MLADS#, MLLBA#, MLRDY#` + a
**priority** line = **five signals**, with address/data multiplexed onto the CPU's `A[25:2]`.

That the inter-chip link is precisely 5 lines is suggestive: **`Bowman1–5` may be the ML-bus control
group**, with the Bowman ASIC acting as an ML "memory-I/O / I/O-only device" per the patent, and the
multiplexed address/data riding the shared CPU bus (which the ASIC also taps — note U21's
`VGA_ADDHI`, `ROMA*`, and CPU-derived signals). Worth testing by checking whether one of
`Bowman1–5` is a free-running clock (→ `MLCLK`) and another strobes at cycle starts (→ `MLADS#`).
If so, `R8/N8` (UNKNOWN3/4) being adjacent could be spare ML handshake lines (§3, hypothesis 1).

See `VL82C420_Technical_Reference.pdf` (built earlier) for the full ML-bus signal definitions and
the redrawn FIG.1/FIG.14 block diagrams.

---

## 5. Cross-check vs references — observations & flags

**Consistent with the patent / SCAMP IV (good signs):**
- `CPU_AHOLD` (L5) and `CPU_LDEV#` (M4) map directly to the patent's **AHOLD** (tri-state the CPU
  address bus to take an ML cycle) and **LBA#/local-device-access** concept. Strong corroboration
  that U61 is the multiplex system controller.
- Full 486 control set present (BE0–3#, WR#, RDY#, BRDY#, KEN#, ADS#, A20M#, STPCLK#, SMI#) — matches
  "power-managed Intel 486-class up to 33 MHz."
- Integrated RTC (RTCBAT/RTCOSCI/RTCOSCO/RTCBAT_Sense) and DRAM control (`U61_RAM_RAS0/2`,
  `U61_RAM_UCASL#/LCASU#`, `RAM_A[0..11]`, `U61_RAM_RAMWE#`) — matches a SCAMP single-chip system
  controller. Up-to-32 MB memory claim is consistent.

**Auto-named / unresolved nets to resolve (these are net *numbers*, not functions):**
`IOW#113`, `ADDHI124`, `FDRQ115`, `PWRGD_IN141`, `ROMCE#142`, `CPU_INTR133`, `PDRQ117`, `FDD_IO125`,
`KB_TP139`, plus the `U21_97/98/101…139` group on the Bowman ASIC and `U61_RAM_*`. These are pins the
tracer left with placeholder names — each is a candidate for a real-function rename once verified.

**Things to double-check on U61 (possible mis-reads in my bulk pass, verify against your symbol):**
- Several `FDC_*` names (`FDC_RTS2#`, `FDC_DTR2#`, `FDC_DSR2#`, `FDC_RDATA#`, etc.) appeared paired
  with U61 balls in the noisy extraction. The SCAMP IV *peripheral* chip (VL82C144) is what carries
  FDC/UART — so confirm whether these are truly VL82C420 balls or bled in from the adjacent
  FDC37C665 / VL82C144 symbol. If real, it means this VL82C420 variant integrates more peripheral
  glue than the SCAMP IV press specs implied.
- `J14=IOW#` / `J15=IOR#` vs the separate `IOW#`/`IOR#` 33Ω series resistors (R-numbers near J13–J16):
  confirm series-termination placement.

---

## 6. Suggested next steps (highest value first)
1. **Buzz out R13/N12 → HD151015 B-side → destination** to name UNKNOWN1/2 functionally.
2. **Continuity/scope R8/N8** to classify as spare-link vs NC/reserved.
3. **Scope `Bowman1–5`** to test the ML-bus hypothesis (look for a clock + an address strobe).
4. **Resolve the placeholder nets** (`*113/115/124/133/141/142`, `U21_9x`, `U61_RAM_*`) into real
   function names; many are inferable from the chip they land on.
5. Fold the confirmed VL82C420 ball map (§2) into the repo as the start of an open VL82C420 pinout —
   it would be the first public one.

*Prepared from the uploaded schematic + the VL82C420 patent reconstruction. Confidence tags reflect
what is provable from the sheet alone vs. what needs a meter/scope on hardware.*

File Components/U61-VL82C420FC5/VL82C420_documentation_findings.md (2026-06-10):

# VLSI VL82C420 (SCAMP IV) — Documentation Trail & Recovered Source Material

## The short answer

A conventional, published **VL82C420 datasheet does not exist anywhere in the public record.** VLSI Technology's
Portable Systems Division (Tempe, Arizona) launched the SCAMP IV chipset (VL82C420 system controller +
VL82C144 peripheral chip + optional VL82C146 ExCA controller) in **October 1993**, just as VLSI was exiting the
PC-chipset business. No databook covering it was ever scanned, and every datasheet archive (bitsavers,
DatasheetArchive, DOS Days, The Retro Web) confirms the gap — bitsavers' VLSI PC collection stops at the
**VL82C114, dated March 1993**, a few months short of SCAMP IV.

**However — the chip's actual engineering documentation survives, in VLSI's own patents.** The designers of the
VL82C420 filed for patent protection the same week the chip was announced. These patents contain the real
block diagrams, the internal architecture of the system controller, the full bus protocol, signal-level
definitions, and timing diagrams. This is the closest thing to a datasheet/schematic that exists, and it was
written by the people who built the chip.

---

## Primary source: the VL82C420 system-controller patent

**US 5,793,990 A — "Multiplex address/data bus with multiplex system controller and method therefor"**

- Assignee: **VLSI Technology, Inc.** (later Philips Semiconductors VLSI)
- Inventors: **James J. Jirgal, David R. Evoy, Walter H. Potts** (VLSI Tempe, AZ)
- **Filed: 11 June 1993** — the SCAMP IV public announcement was 17 June 1993
- Also published internationally as **WO 1994/029797 A1**

This patent describes the **"Multiplexed Local Bus" (ML Bus)** that the SCAMP IV announcement named as the
proprietary interconnect between the VL82C420, VL82C144 and VL82C146 — and the **multiplex system controller**,
which is the VL82C420 itself.

Read / figures / PDF:
- Patent page: https://patents.google.com/patent/US5793990A/en
- Full PDF: https://patentimages.storage.googleapis.com/89/6b/d8/84459ba2e43015/US5793990.pdf
- International (PCT) version: https://patents.google.com/patent/WO1994029797A1

### The figures (these are the schematics / block diagrams)

- **FIG. 1** — block diagram, local-bus architecture: CPU + memory-I/O device + I/O-only device + multiplex
  system controller, showing the split address bus A[25:18]/A[17:10]/A[9:2], D[31:0], CPU control bus, ISA
  A[23:0]/D[15:0], and the multiplex control bus.
- **FIG. 2** — "downstream" architecture: CPU and multiplex system controller integrated in one CPU-bus-controller
  chip, with an external CPU bus slave.
- **FIG. 3A / 3B** — the 16-bit address/data formats for memory-I/O and I/O-only devices.
- **FIG. 4** — byte-selection model (A1, BHE#, BLE#).
- **FIG. 5–13** — timing diagrams: I/O read (high/low device), I/O write, terminated I/O, memory read/write,
  terminated memory, and multiplex DMA read/write.
- **FIG. 14** — **internal block diagram of the multiplex system controller (the VL82C420 core)**: state machine,
  address latch, three multiplexers (36/38/40), and the DMA controller (42) with their bus connections.

Direct images of the drawing pages:
- Page 2: https://patentimages.storage.googleapis.com/55/e5/90/a5b69ab2d8e299/US5793990-drawings-page-2.png
- Page 3: https://patentimages.storage.googleapis.com/6a/f7/9d/91c4959da61ff3/US5793990-drawings-page-3.png
- Page 4: https://patentimages.storage.googleapis.com/d8/6b/0a/585cc552d74397/US5793990-drawings-page-4.png
- Page 5: https://patentimages.storage.googleapis.com/f5/dc/62/ff5d3f748ec276/US5793990-drawings-page-5.png
- Page 6: https://patentimages.storage.googleapis.com/0b/e8/b2/6ecba8d80ba7dd/US5793990-drawings-page-6.png
- Page 7: https://patentimages.storage.googleapis.com/5c/19/d7/d32f9da17bb907/US5793990-drawings-page-7.png
- Page 8: https://patentimages.storage.googleapis.com/6d/64/2b/aa57556dfceecf/US5793990-drawings-page-8.png
- Page 9: https://patentimages.storage.googleapis.com/f5/ab/4d/38500753dcd5e9/US5793990-drawings-page-9.png

### Bus signal definitions recovered from the patent (the ML Bus)

These are the actual SCAMP IV Multiplexed Local Bus signals as defined by the chip designers:

- **MLCLK** — multiplex bus clock; a 1X clock driven synchronously to the CPU clock, but separately gateable from
  the CPU clock so both can be independently stopped for power conservation.
- **MLADS#** — multiplex address strobe (low-true); asserted by the system controller when it is driving valid
  address or data on the CPU's address lines.
- **MLLBA#** — multiplex device local-bus-access (low-true); a target device asserts it when it positively decodes
  a valid address. Also used during reads to indicate which CPU address lines the device sits on
  (A[17:2] if asserted during MLRDY#, A[25:10] if negated).
- **MLRDY#** — multiplex ready; asserted by a device to signal write-data accepted or read-data valid; the
  controller can also assert it to terminate a cycle when no device acknowledges.
- **ADS#, M/IO#, AHOLD, RDY#, LBA#** — CPU-side handshake signals; AHOLD is how the controller tri-states the
  CPU address bus to take it over for a multiplex cycle.

### How the chip works (from the patent text)

The system controller translates ordinary x86 CPU memory/I/O cycles into **16-bit multiplexed bus cycles**, in
which address and data share the same lines — a portion (A[25:2]) of the CPU's 32-bit address bus. It asserts
**AHOLD** to tri-state the CPU's address bus, then sequentially drives two 16-bit address groups and one 16-bit
data group. Memory-I/O devices decode to 1 KB granularity; I/O-only devices decode to 4-byte granularity. The
internal core (FIG. 14) is a **state machine** driving an **address latch** and **three multiplexers**, with a
**DMA controller** feeding DMA addresses/acknowledges into those multiplexers. The whole point is pin reduction
for the companion chips — exactly the "only 3 TTL components needed" / low-pin-count design the SCAMP IV
announcement advertised.

---
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

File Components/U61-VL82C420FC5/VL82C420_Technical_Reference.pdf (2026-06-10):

# VLSI VL82C420

SCAMP IV Multiplex System Controller

## Reconstructed Technical Reference

No datasheet for the VL82C420 was ever released to the public, and no databook covering the SCAMP IV chipset (VL82C420 system controller + VL82C144 peripheral chip + optional VL82C146 ExCA controller) was ever archived. SCAMP IV was announced by VLSI Technology's Portable Systems Division (Tempe, Arizona) in June 1993 and shipped in volume that October, just as VLSI was leaving the PC-chipset business.
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

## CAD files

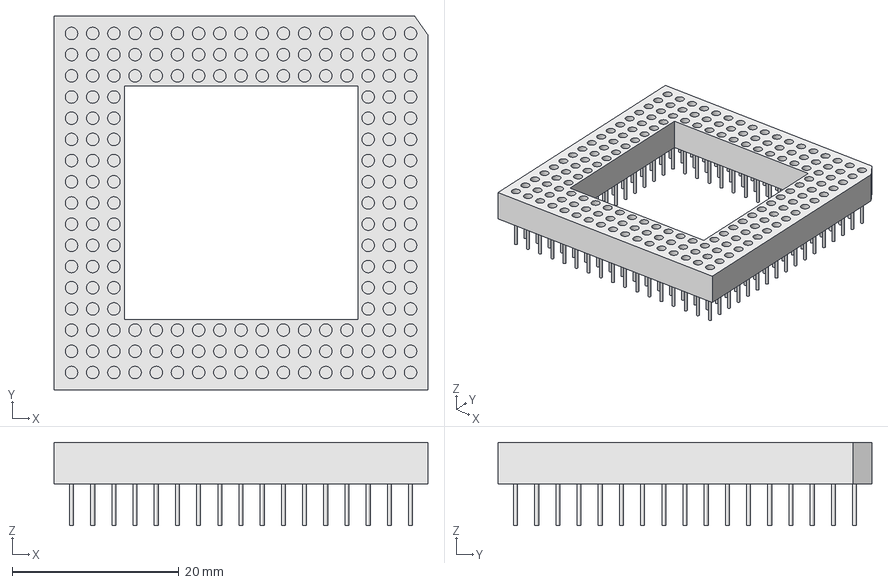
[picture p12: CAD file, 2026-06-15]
Mods/PC110-ITX/486_Socket.step
44.8 x 44.8 x 10.0 mm

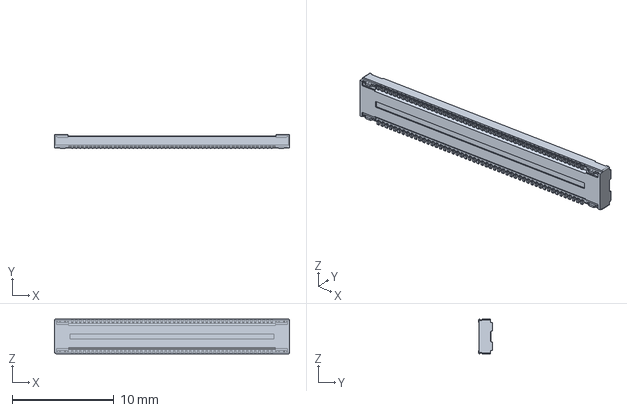
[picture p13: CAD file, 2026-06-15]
Mods/CPU Upgrade/bgacpu-dualcon/3D/51338-1074.stp
23.1 x 1.40 x 3.40 mm

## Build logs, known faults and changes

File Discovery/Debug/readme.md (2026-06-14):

# PC110 CPU debug headers (J9 / J12 / JTAG) — reference + homebrew pod

From the PC110 schematic: two CPU debug headers and a JTAG TAP, all tied to the **80486SX**
(not the VL82C420 chipset), buffered through `74LVT125` with 33 Ω series resistors.

## 1. Pinouts (as drawn)

### J9 — "Debug-10" (2×5, 0.1″)
| Pin | Signal | 486 dir | Pin | Signal | 486 dir |
|----:|---|:---:|----:|---|:---:|
| 1 | CPU_HOLD | **in** | 2 | CPU_BRDY# | **in** |
| 3 | CPU_BE1# | out | 4 | CPU_HLDA | out |
| 5 | CPU_BE3# | out | 6 | CPU_BE0# | out |
| 7 | CPU_A20M# | **in** | 8 | CPU_BE2# | out |
| 9 | CPU_SRESET | **in** | 10 | CPU_NMI | **in** |

### J12 — "Debug-6" (1×6, 0.1″)
| Pin | Signal | 486 dir |
|----:|---|:---:|
| 1 | CPU_BLAST# | out |
| 2 | CPU_FLUSH# | **in** |
| 3 | CPU_KEN# | **in** |
| 4 | CPU_EADS# | **in** |
| 5 | CPU_AHOLD | **in** |
| 6 | CPU_A31 | out (and `CPU_A[2..31]` runs alongside) |

### JTAG TAP (separate)
`TCK`, `TDI`, `TMS`, `TDO` (IEEE 1149.1 boundary scan on the 486). `TRST#` not separately broken out.

*("in" = CPU input → a pod **drives** it; "out" = CPU output → a pod **senses** it.)*

## 2. What the headers are for
This is the **HOLD-method 486 in-circuit-emulator / debug-pod control interface**. The signal
selection is the giveaway:
- **Bus takeover:** `HOLD`/`HLDA` (and `AHOLD`) float the 486 so an emulator can own the local bus —
  the standard way to ICE a *soldered* CPU (the PC110's 486 is BGA; no socket pod possible).
- **Cycle control:** `BRDY#` / `BLAST#` to drive/observe bus-cycle termination.
- **Cache coherency:** `EADS#` + `FLUSH#` + `KEN#` — the tell. A tool that modifies memory behind the
  running CPU uses `EADS#` (snoop-invalidate one line during `AHOLD`) and `FLUSH#` (flush the whole
  on-chip cache) so the 486's cache stays consistent. You only break these out for a debug tool.
- **Control:** `SRESET` (soft restart without power cycle), `NMI`, `A20M#`, byte enables for qualifying.
- **JTAG TAP:** IEEE-1149.1 boundary scan for board test (and pin-level debug via EXTEST/SAMPLE).

It was a development/bring-up interface (RIOS Systems / IBM, 1994-95). No public doc names a specific
commercial emulator model; the *class* is unambiguous from the pinout.

## 3. Honest limitation
J9/J12 expose **control + byte-enables + the address bus** but **not the data bus**. So by themselves
they let you *halt, reset, interrupt, and manage the cache* — and observe cycles — but a full
RAM-override (read/write memory behind the CPU) also needs the **data bus** (tap it at the DRAM/ROM,
or use JTAG boundary-scan EXTEST). Plan the pod accordingly.

## 4. Homebrew modern debug pod

Two practical paths; do JTAG first (cleanest), add the J9/J12 controller for run-control.

### Path A — JTAG boundary scan (recommended, lowest-risk)
- Adapter: **FT2232H** mini-module (or any OpenOCD-supported JTAG dongle).
- Wire `TCK/TMS/TDI/TDO` (+ GND, and tie/strap `TRST#` inactive). 3.3 V LVTTL via the existing
  `74LVT125` buffers — level-safe.
- Software: **OpenOCD** with a generic IEEE-1149.1 tap; once you have the 486's **BSDL** (boundary-scan
  description), you can `SAMPLE` every pin live and `EXTEST`-drive pins for board test — even do slow
  memory peeks by walking the boundary register. This needs *no* high-speed bus mastering.

### Path B — J9/J12 run-control pod (MCU or small FPGA)
A 3.3 V MCU (RP2040 is ideal — fast GPIO + PIO) or a small FPGA drives the CPU-input signals and
samples the CPU-output signals. **Use level shifting**: the 486 side may be 5 V; the board's `74LVT125`
buffers are 5 V-tolerant inputs / 3.3 V outputs, and there are 33 Ω series Rs — still, put proper level
translation between your pod and the header.

Pod ↔ header mapping:
| Pod role | Signals (drive) | Signals (sense) |
|---|---|---|
| Halt/run | `HOLD`, `AHOLD` | `HLDA`, `BLAST#` |
| Reset/IRQ | `SRESET`, `NMI`, `A20M#` | — |
| Cache | `FLUSH#`, `EADS#`, `KEN#` | — |
| Cycle | `BRDY#` | `BLAST#`, `BE0-3#`, `A31`/`A[2..31]` |

Core operations the pod can implement (see `pc110_debug_pod.c`):
1. **Halt:** drive `HOLD`=1 → wait `HLDA`=1 → CPU bus floated.
2. **Resume:** `HOLD`=0 → wait `HLDA`=0.
3. **Flush cache:** pulse `FLUSH#` low (≥ required clocks).
4. **Snoop-invalidate a line:** `AHOLD`=1 → present the line address on `A[2..31]` → pulse `EADS#` low
   → `AHOLD`=0. (Requires address-bus access.)
5. **Soft reset / restart:** pulse `SRESET`.
6. **Inject NMI:** pulse `NMI`.
7. **Single-cycle stepping** (if you also drive data/addr): use `BRDY#` to terminate each cycle.

### Caveats
- **Voltage/timing:** respect 5 V vs 3.3 V on each net; the 486 bus is fast — for real bus *mastering*
  (driving memory) prefer an FPGA. Run-control (HOLD/FLUSH/SRESET/NMI) is slow and fine on an MCU.
- **Cache:** the 486 internal cache is write-through; after any pod write to memory, `FLUSH#` (or
  per-line `EADS#`) before resuming, or the CPU may read stale cached data.
- **Don't fight the chipset:** the VL82C420 also issues `AHOLD`/`HOLD`/refresh; coordinate or only take
  the bus while the chipset is idle.
- A safe, high-value first milestone: **JTAG `SAMPLE`** to watch the CPU pins live during POST — no
  risk, immediately useful for bring-up.

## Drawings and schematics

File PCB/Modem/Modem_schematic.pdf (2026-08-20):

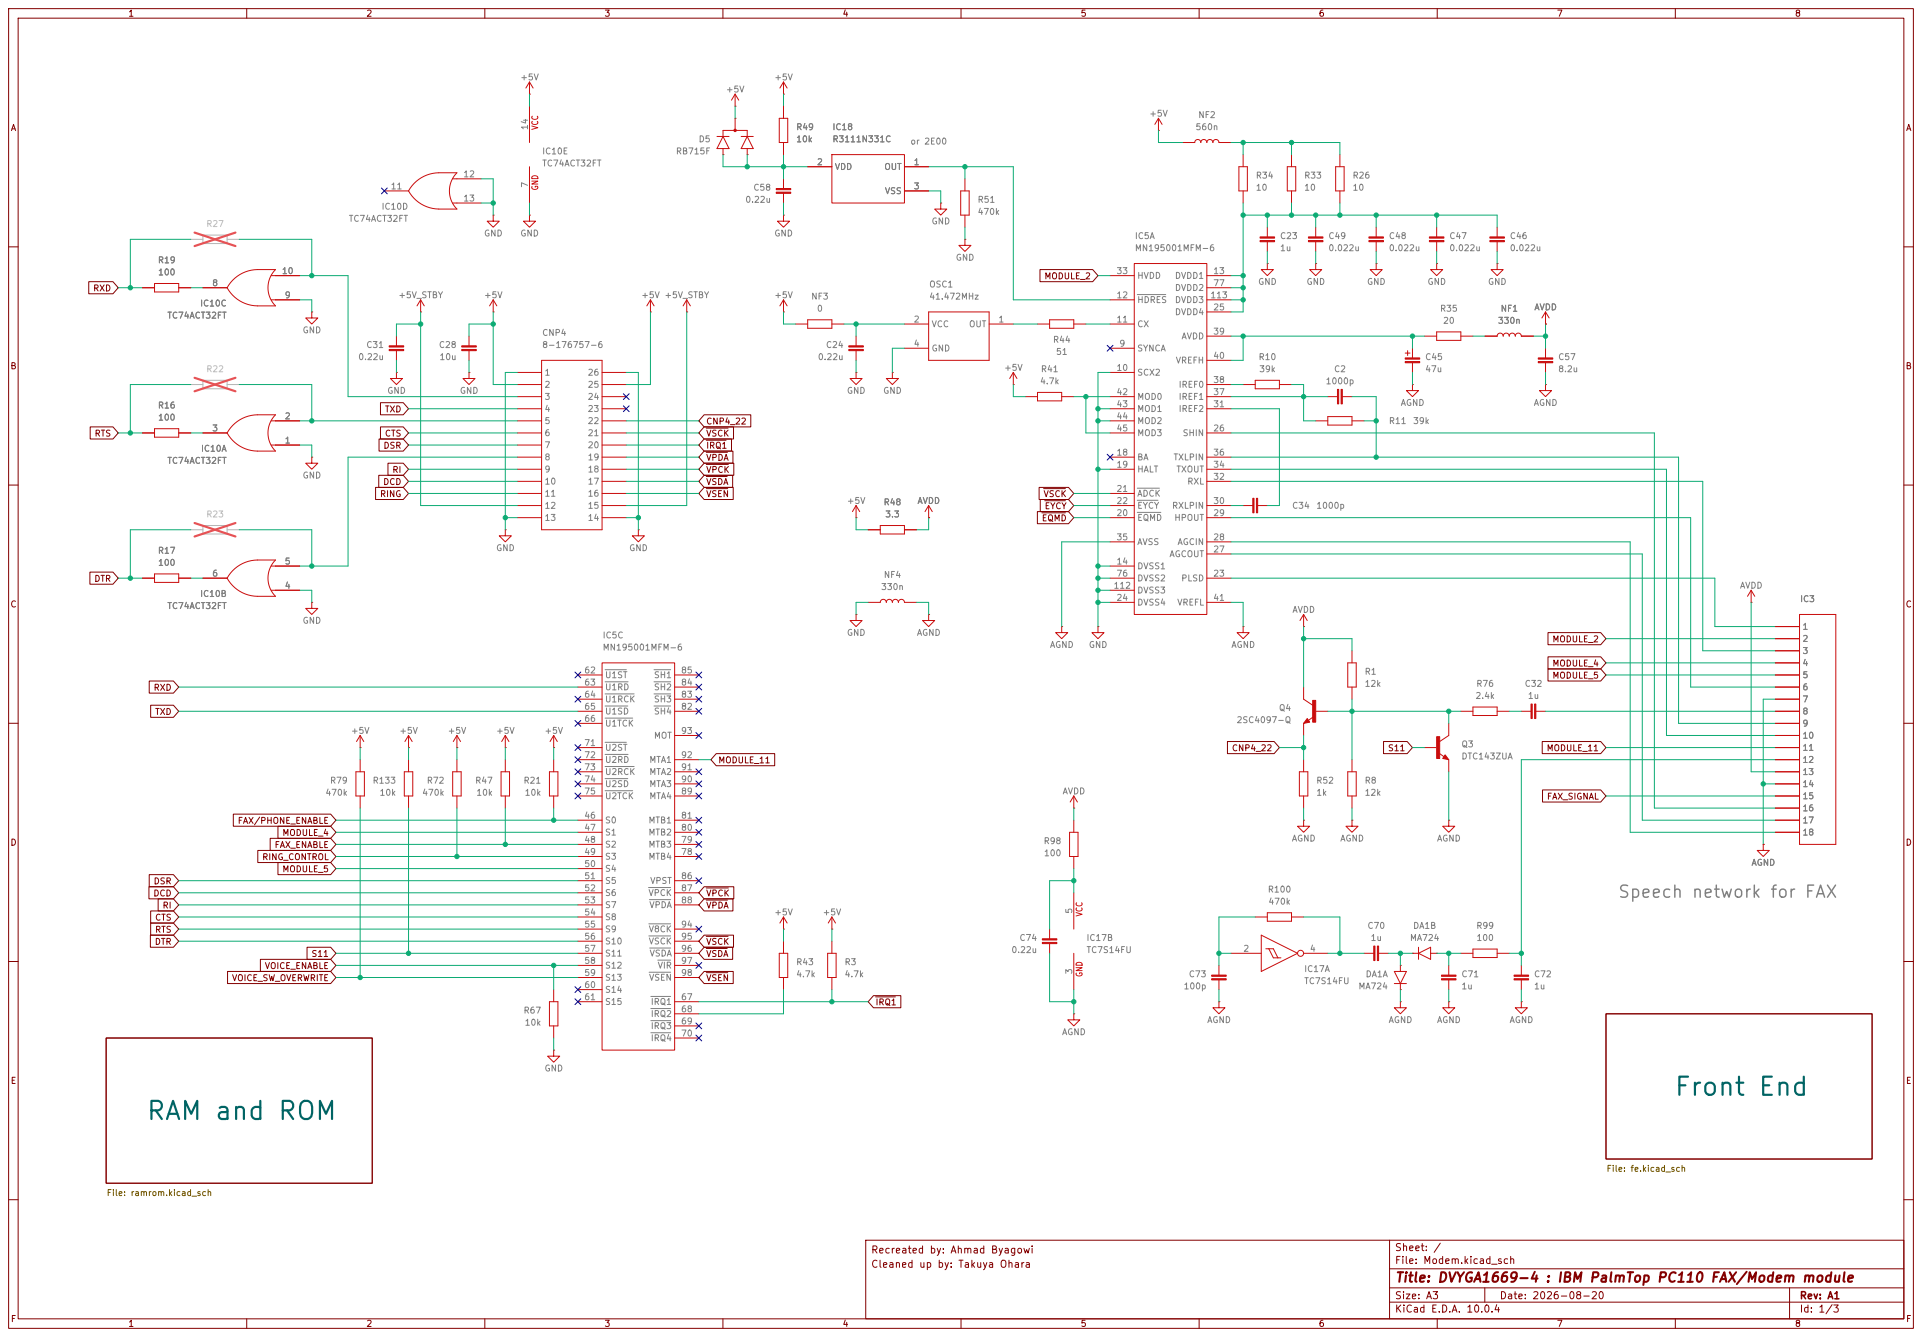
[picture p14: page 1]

S15 61 U1ST 62 U1RD 63 U1RCK 64 U1SD 65 U1TCK 66 S1 47 S2 48 S3 49 S4 50 S5 51

S6 52
S7 53
S8 54
S9 55

Speech network for FAX

Sheet: /
File: Modem.kicad_sch
Title: DVYGA1669-4 : IBM PalmTop PC110 FAX/Modem module

Recreated by: Ahmad Byagowi
Cleaned up by: Takuya Ohara

Size: A3 | Rev: A1
KiCad E.D.A. 10.0.4 | Id: 1/3 | F Date: 2026-08-20

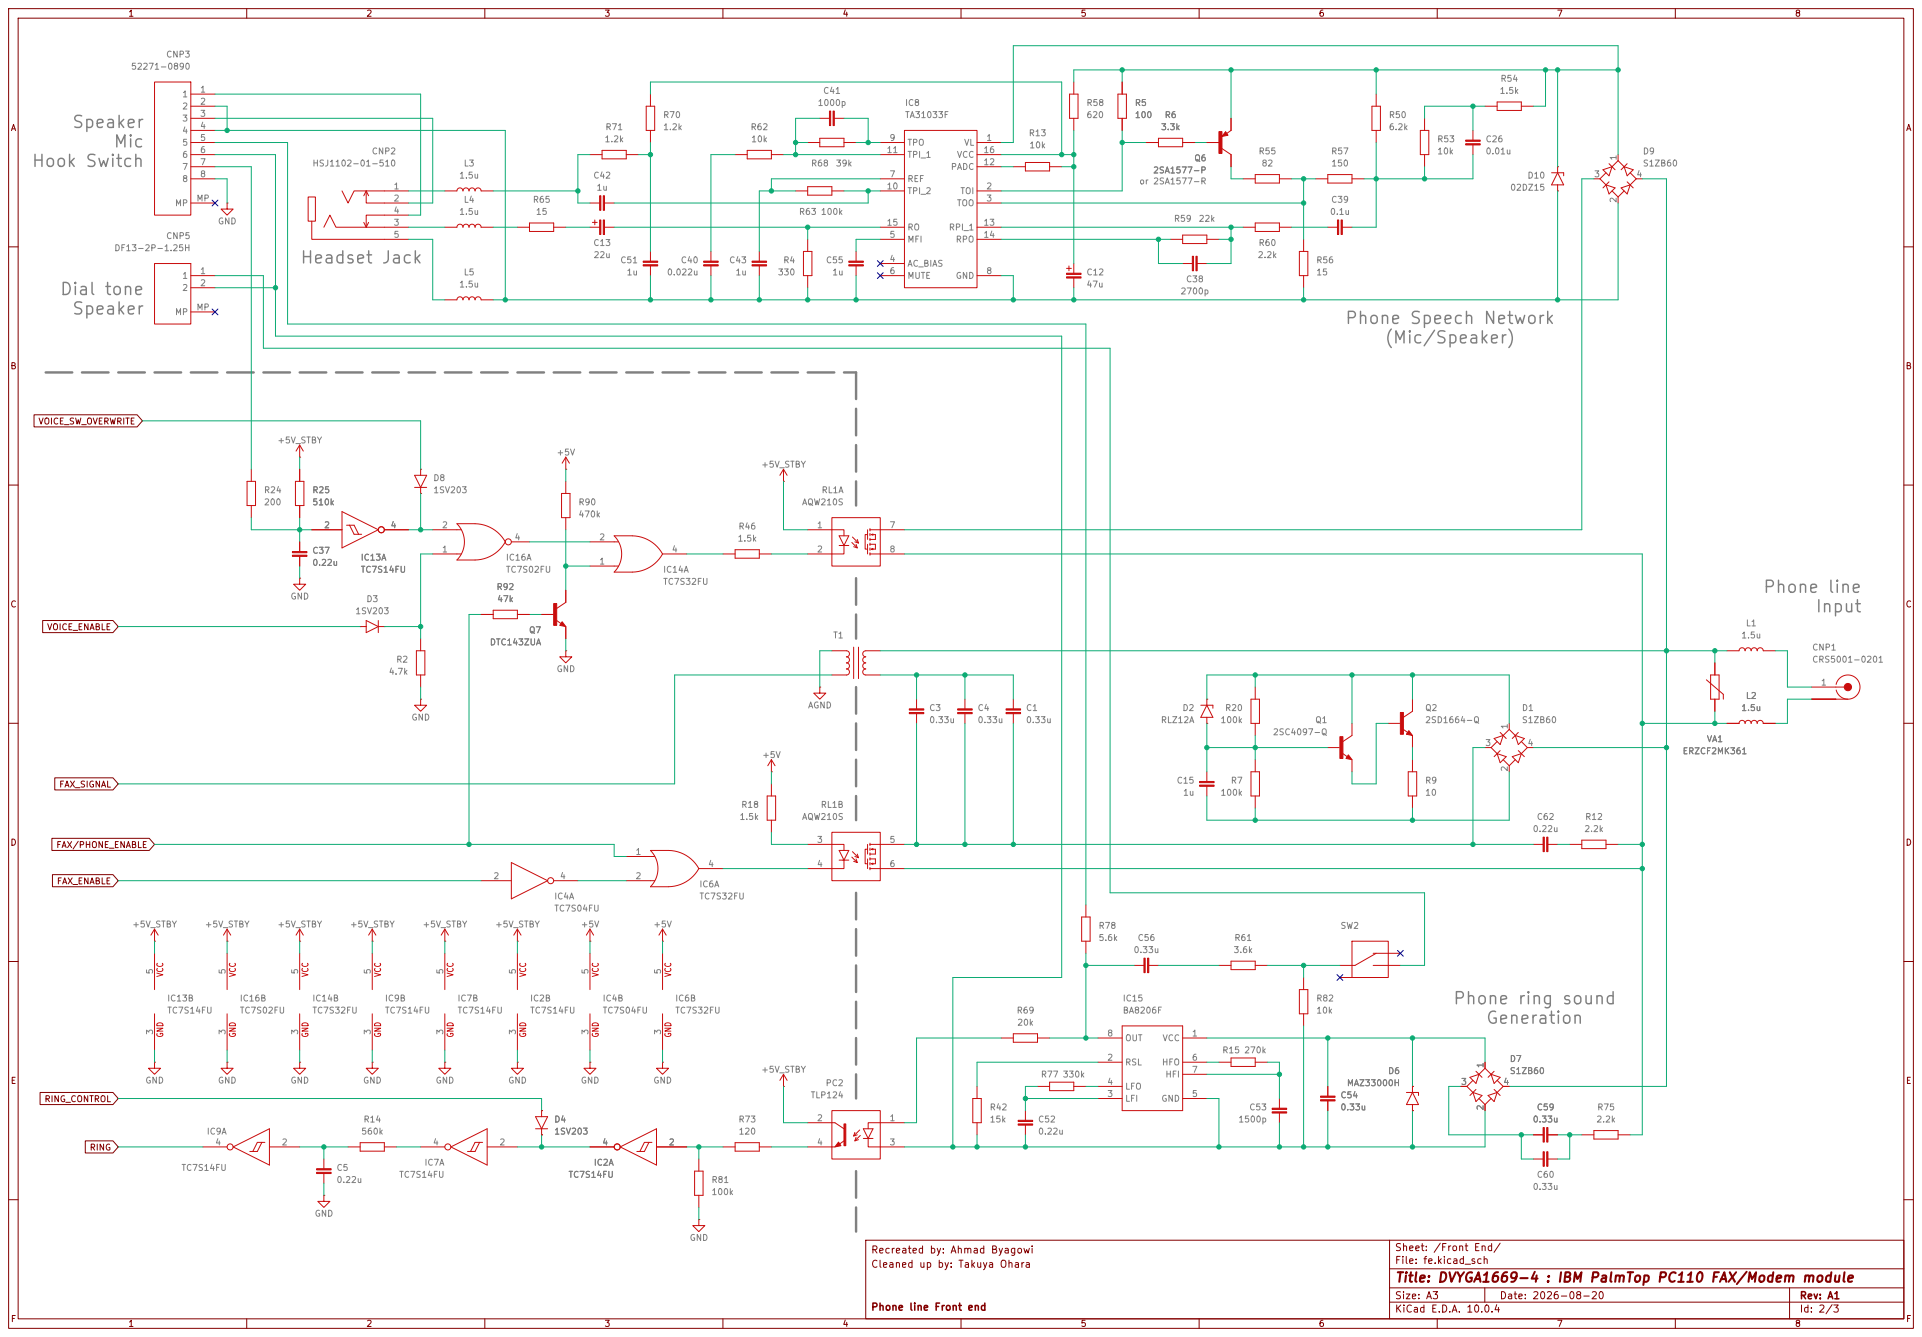
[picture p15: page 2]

Sheet: /Front End/
File: fe.kicad_sch
Title: DVYGA1669-4 : IBM PalmTop PC110 FAX/Modem module

Recreated by: Ahmad Byagowi
Cleaned up by: Takuya Ohara

Size: A3 | Rev: A1

F Date: 2026-08-20

Phone line Front end

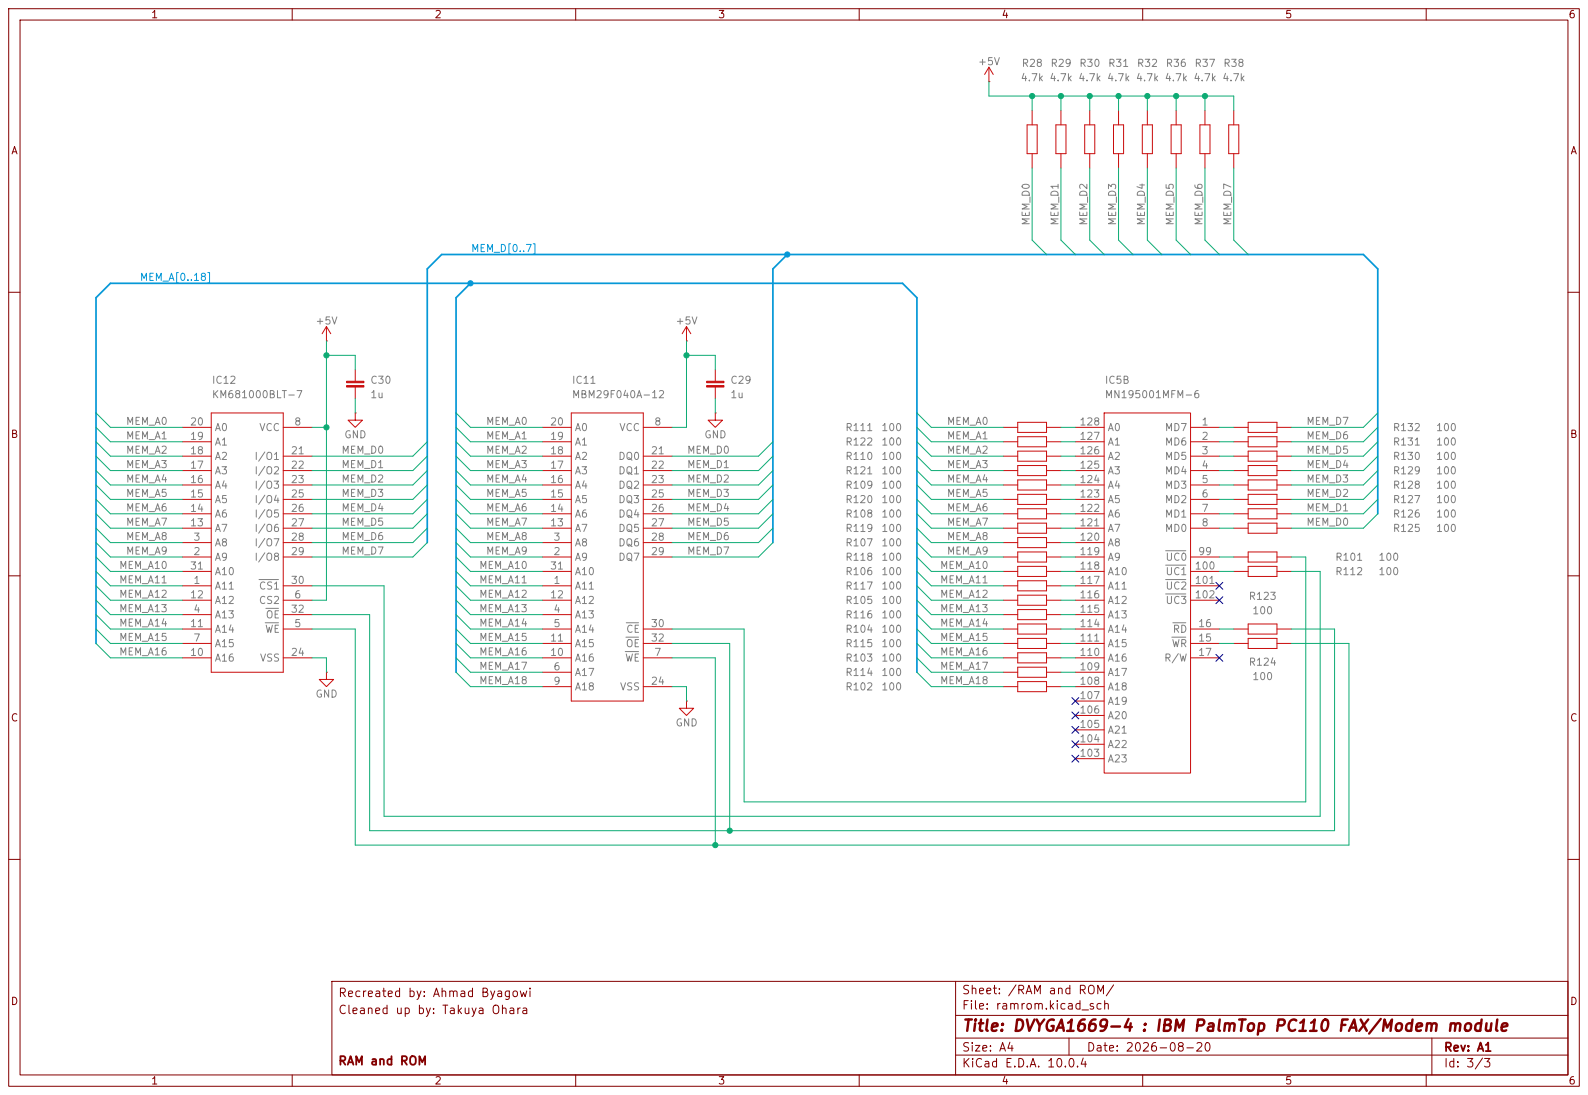
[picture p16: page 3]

Sheet: /RAM and ROM/
File: ramrom.kicad_sch
Title: DVYGA1669-4 : IBM PalmTop PC110 FAX/Modem module

Cleaned up by: Takuya Ohara

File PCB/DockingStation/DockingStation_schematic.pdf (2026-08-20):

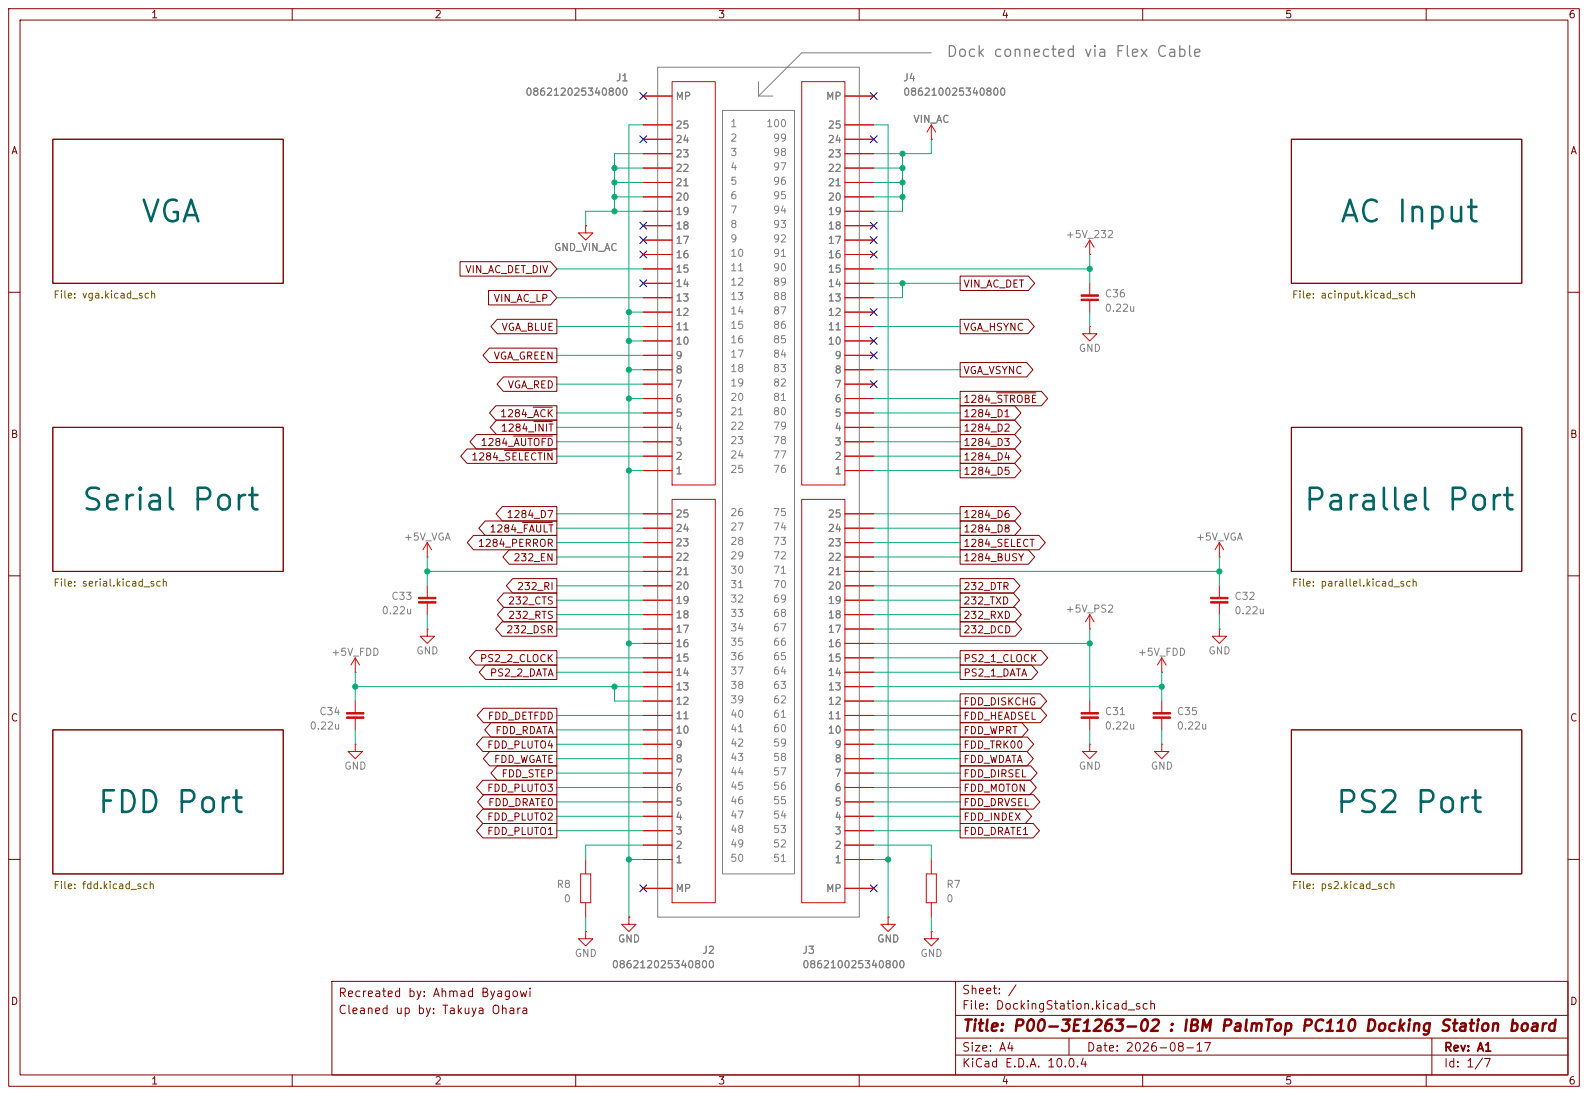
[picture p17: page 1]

Recreated by: Ahmad Byagowi
Cleaned up by: Takuya Ohara

Sheet: /
File: DockingStation.kicad_sch
Title: P00-3E1263-02 : IBM PalmTop PC110 Docking Station board

Size: A4 | Rev: A1
KiCad E.D.A. 10.0.4 | Id: 1/7

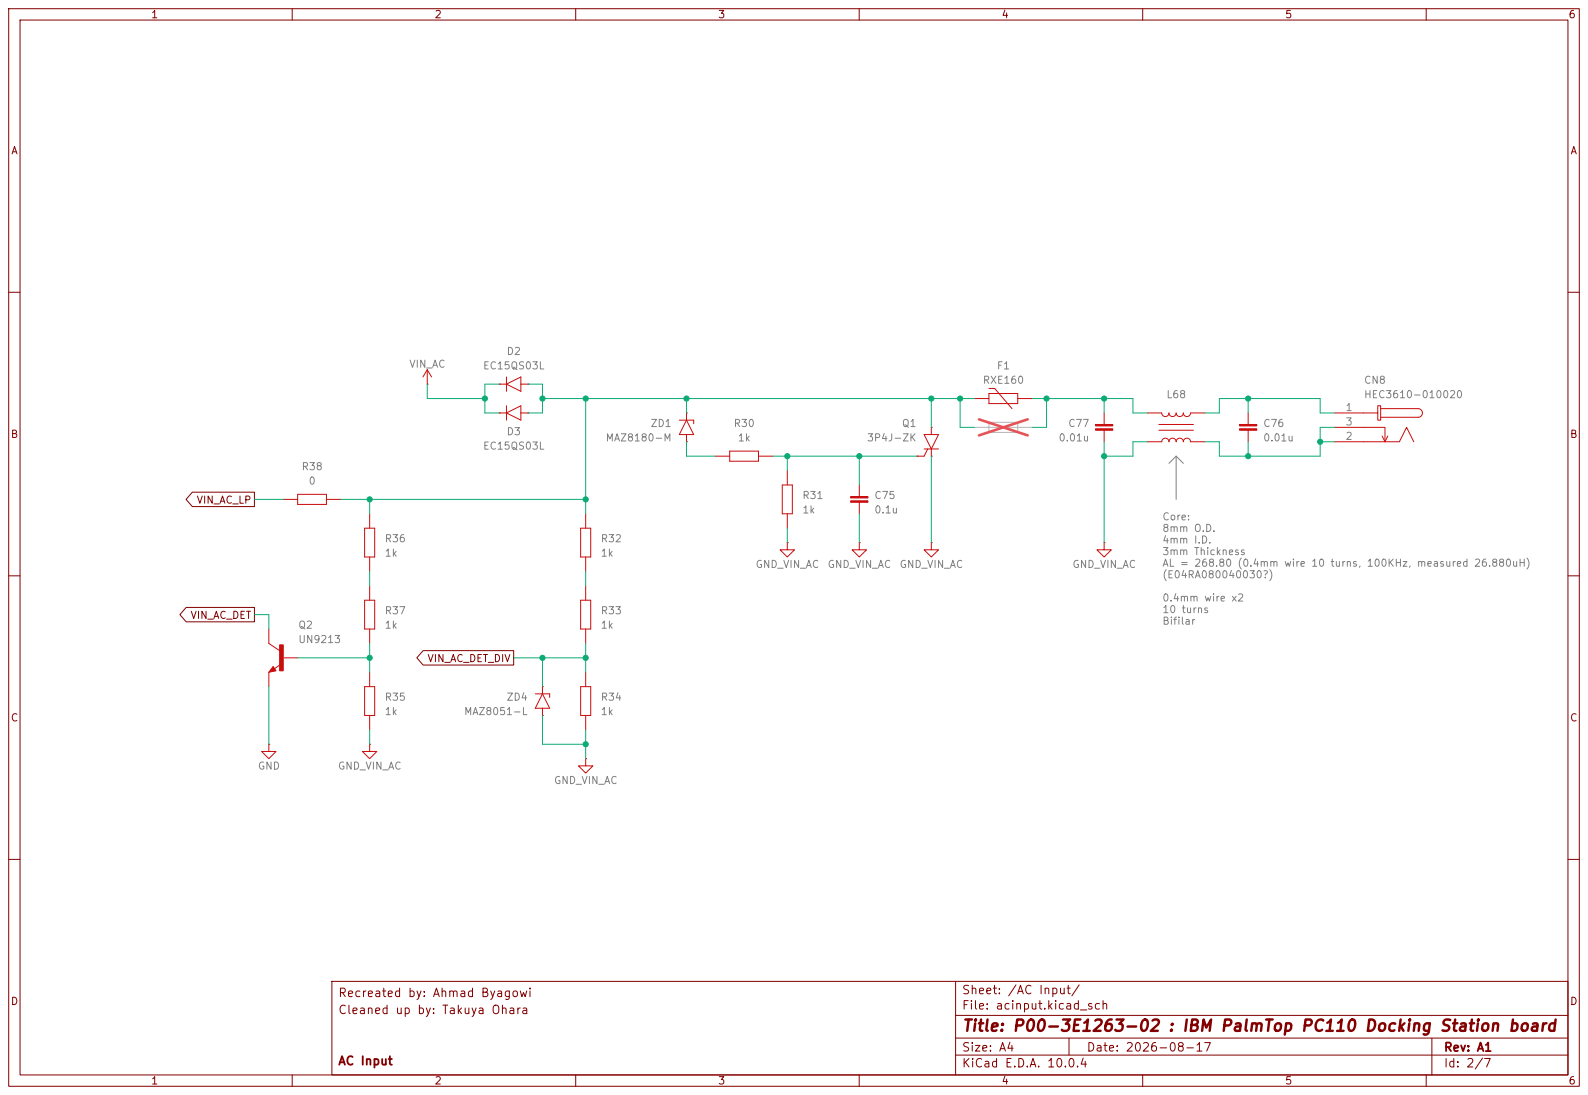
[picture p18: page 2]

Core: 8mm O.D. 4mm I.D. 3mm Thickness AL = 268.80 (0.4mm wire 10 turns, 100KHz, measured 26.880uH)

Recreated by: Ahmad Byagowi
Cleaned up by: Takuya Ohara

Sheet: /AC Input/
File: acinput.kicad_sch
Title: P00-3E1263-02 : IBM PalmTop PC110 Docking Station board

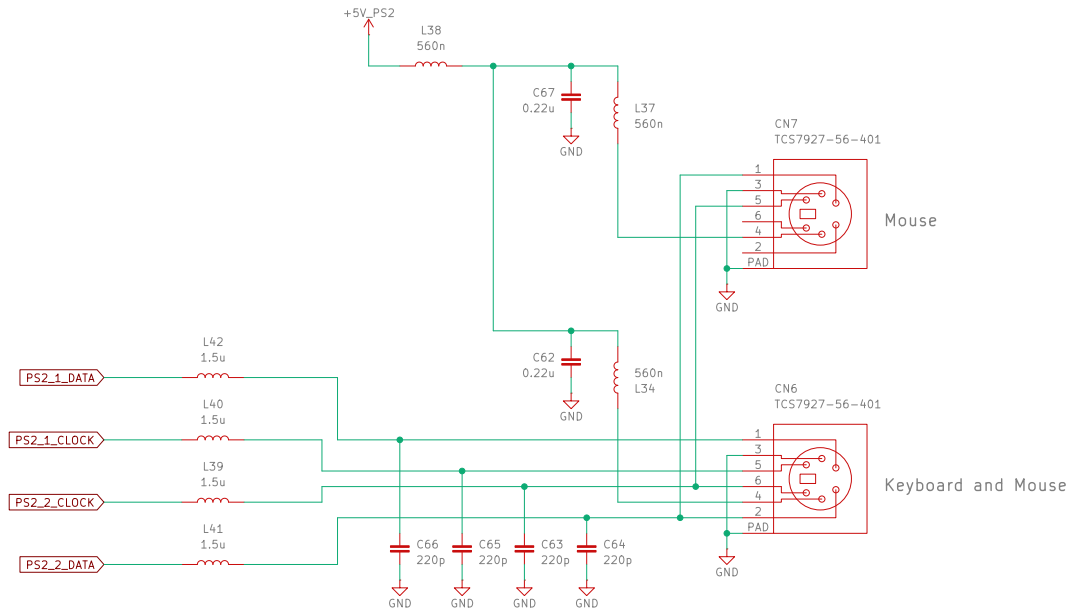
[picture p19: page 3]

5 6PAD 4

6PAD 4

Sheet: /PS2 Port/
File: ps2.kicad_sch
Title: P00-3E1263-02 : IBM PalmTop PC110 Docking Station board

Cleaned up by: Takuya Ohara

PS/2 Keyboard and Mouse Port

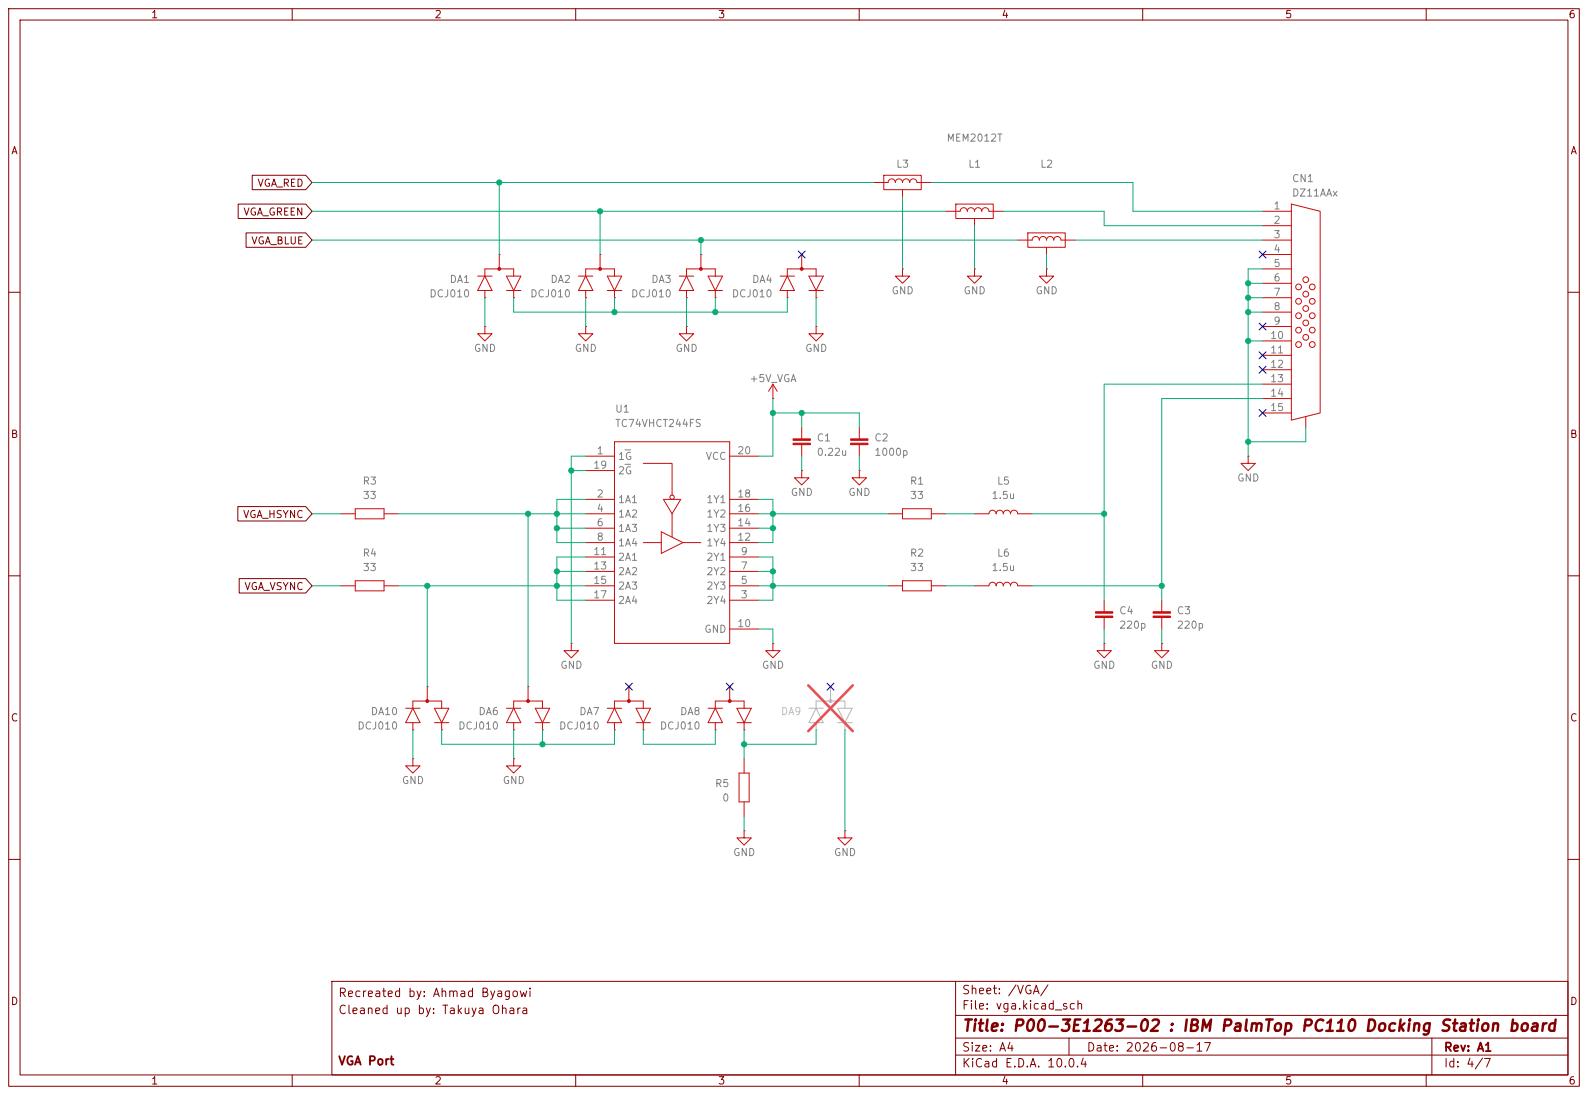
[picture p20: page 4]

Sheet: /VGA/
File: vga.kicad_sch
Title: P00-3E1263-02 : IBM PalmTop PC110 Docking Station board

Cleaned up by: Takuya Ohara

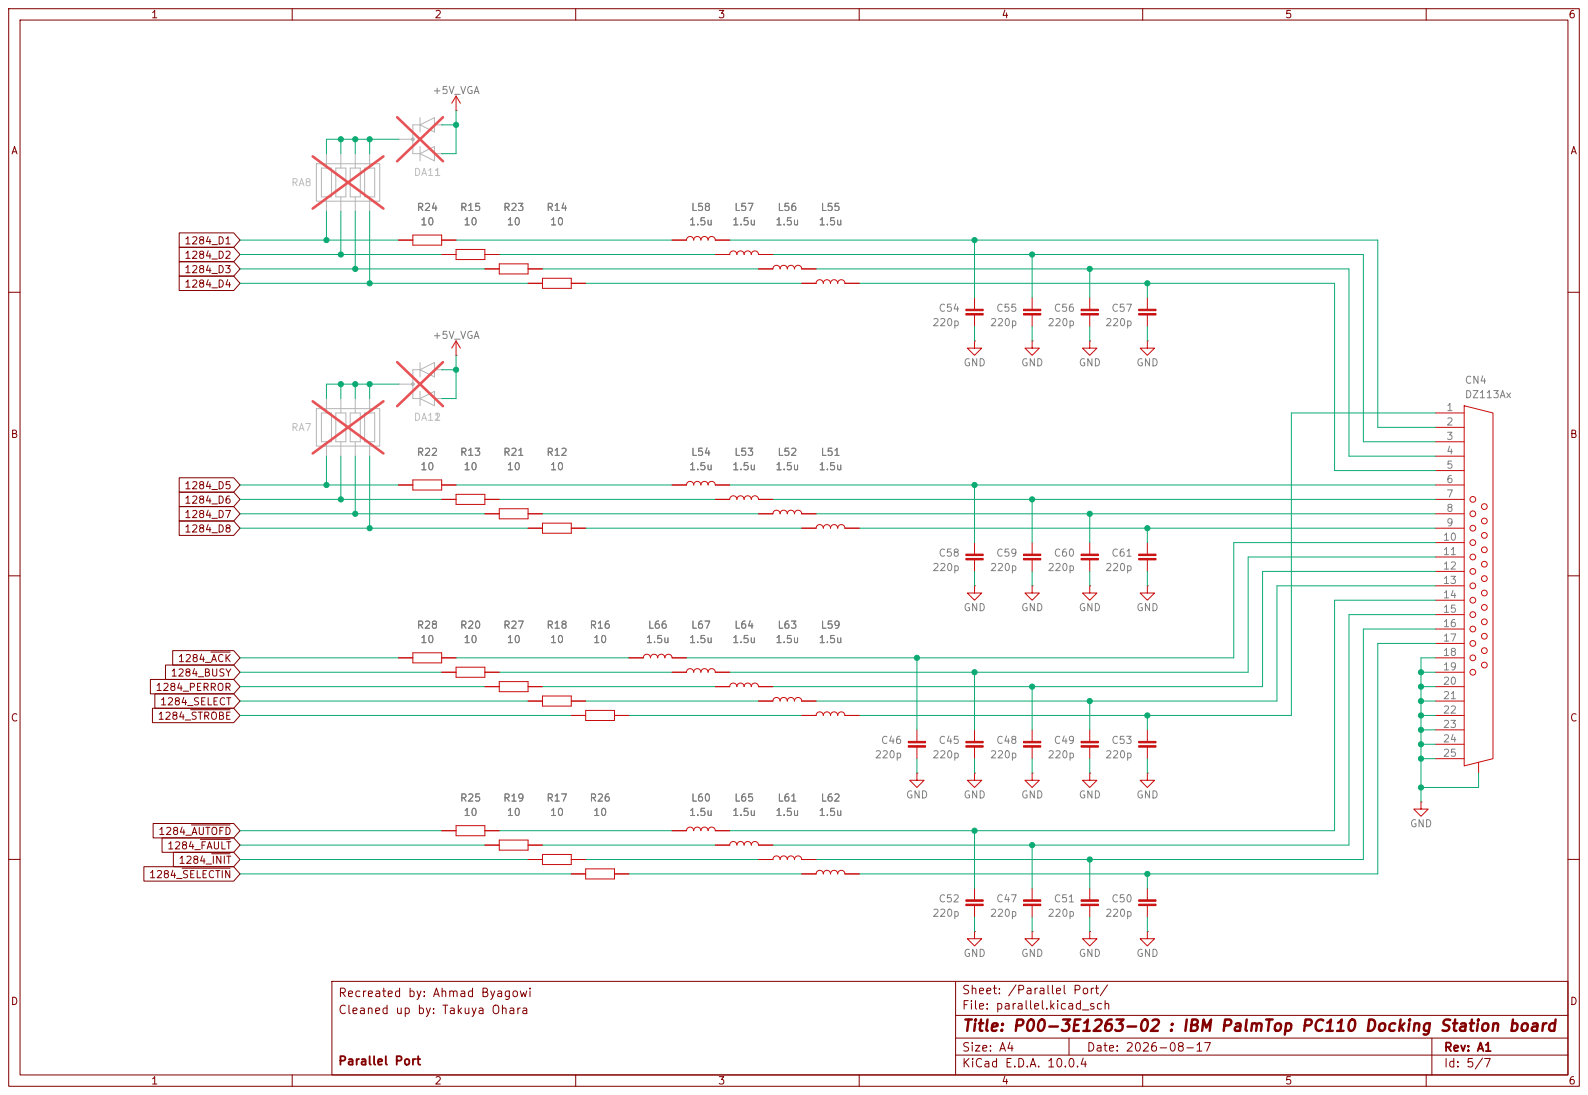
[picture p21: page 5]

Sheet: /Parallel Port/
File: parallel.kicad_sch
Title: P00-3E1263-02 : IBM PalmTop PC110 Docking Station board

Cleaned up by: Takuya Ohara

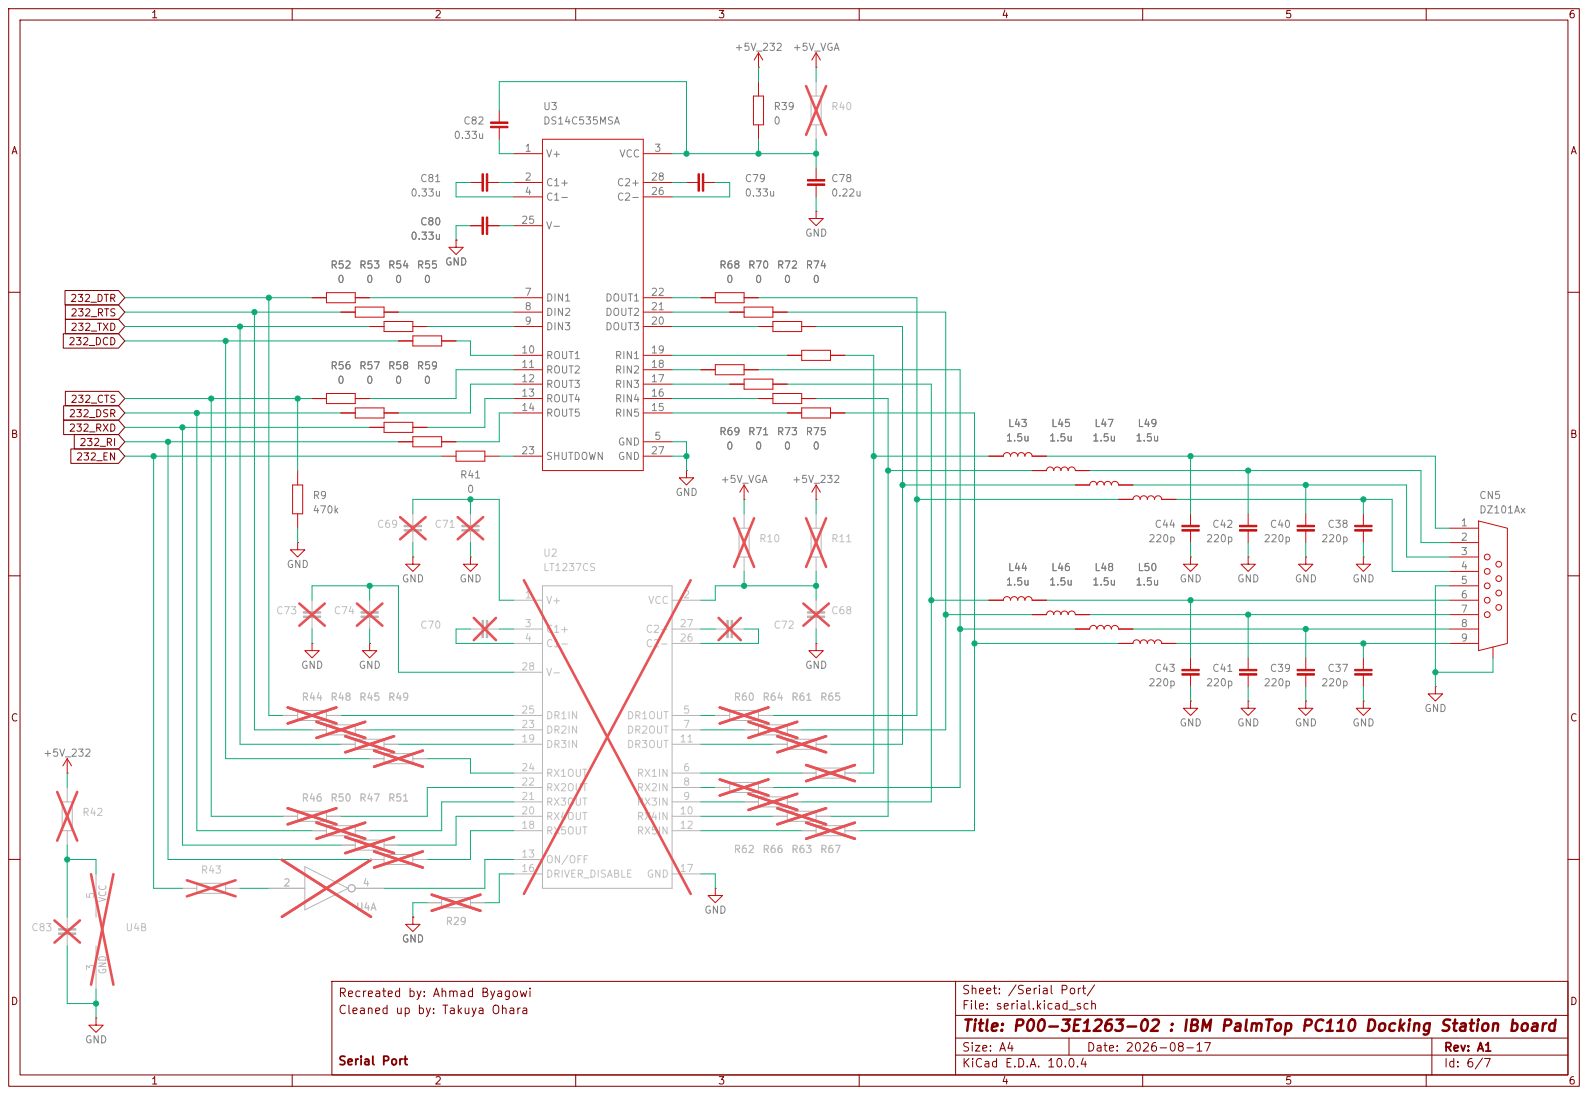
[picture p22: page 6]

Sheet: /Serial Port/
File: serial.kicad_sch
Title: P00-3E1263-02 : IBM PalmTop PC110 Docking Station board

Cleaned up by: Takuya Ohara

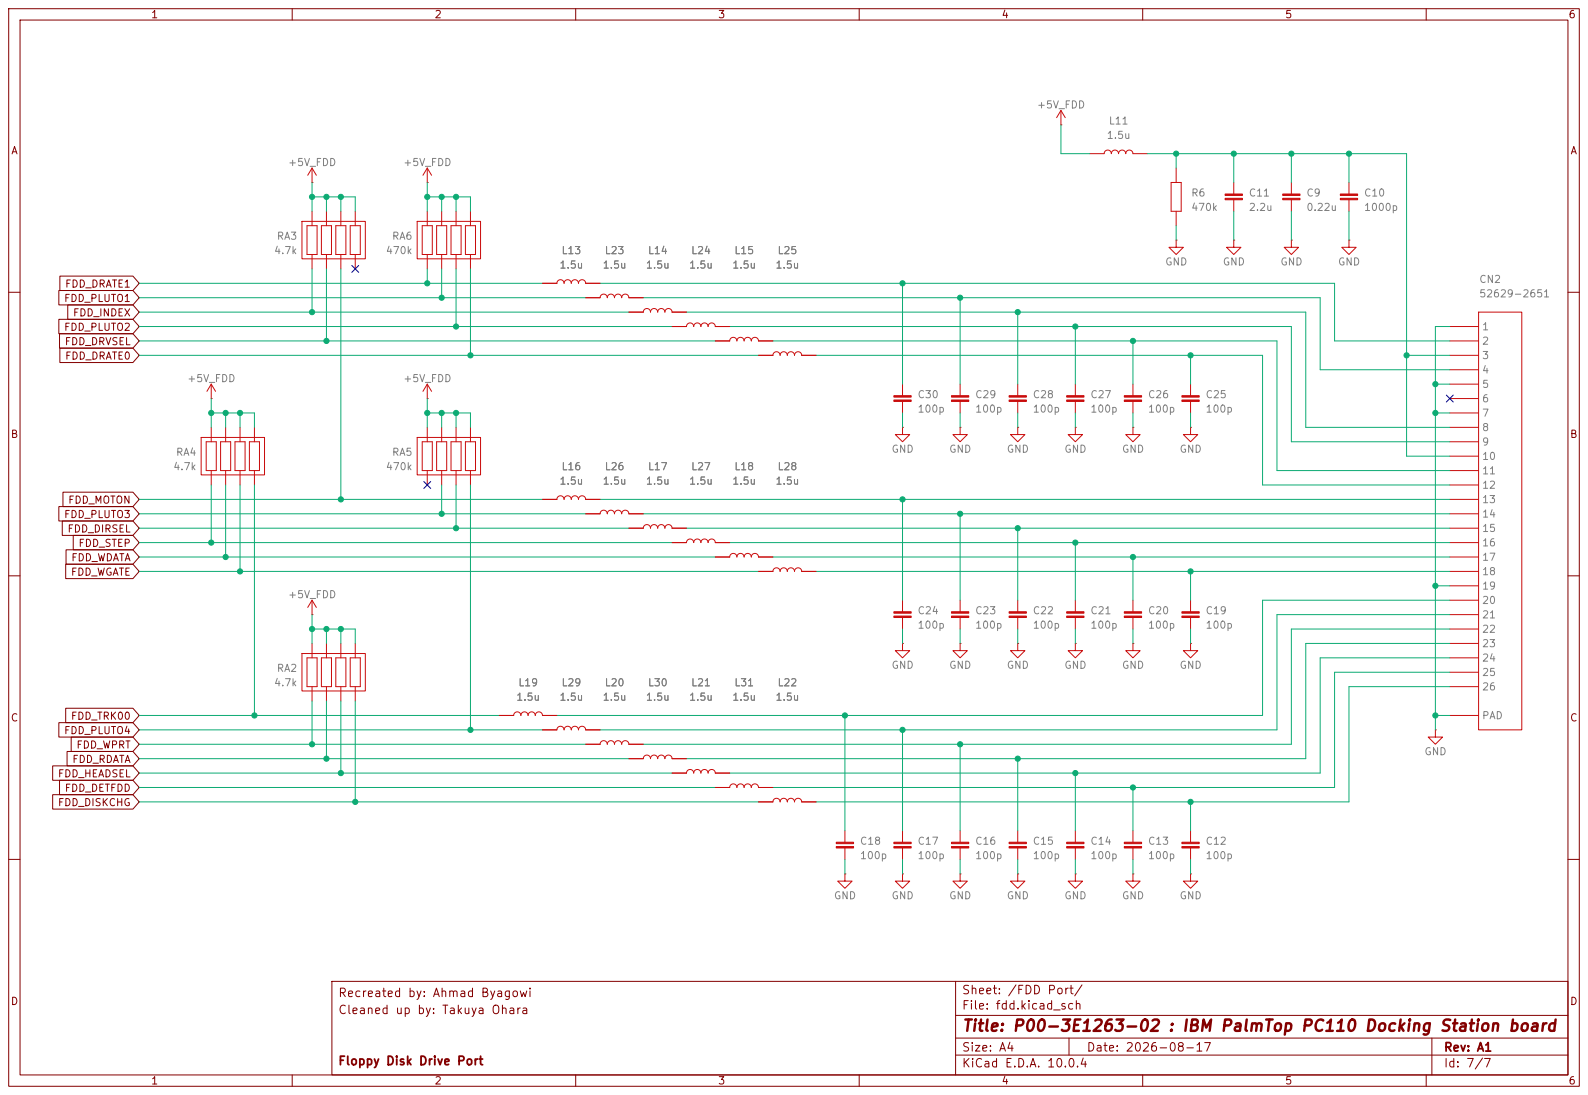
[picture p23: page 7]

Recreated by: Ahmad Byagowi
Cleaned up by: Takuya Ohara

Sheet: /FDD Port/
File: fdd.kicad_sch
Title: P00-3E1263-02 : IBM PalmTop PC110 Docking Station board

Floppy Disk Drive Port

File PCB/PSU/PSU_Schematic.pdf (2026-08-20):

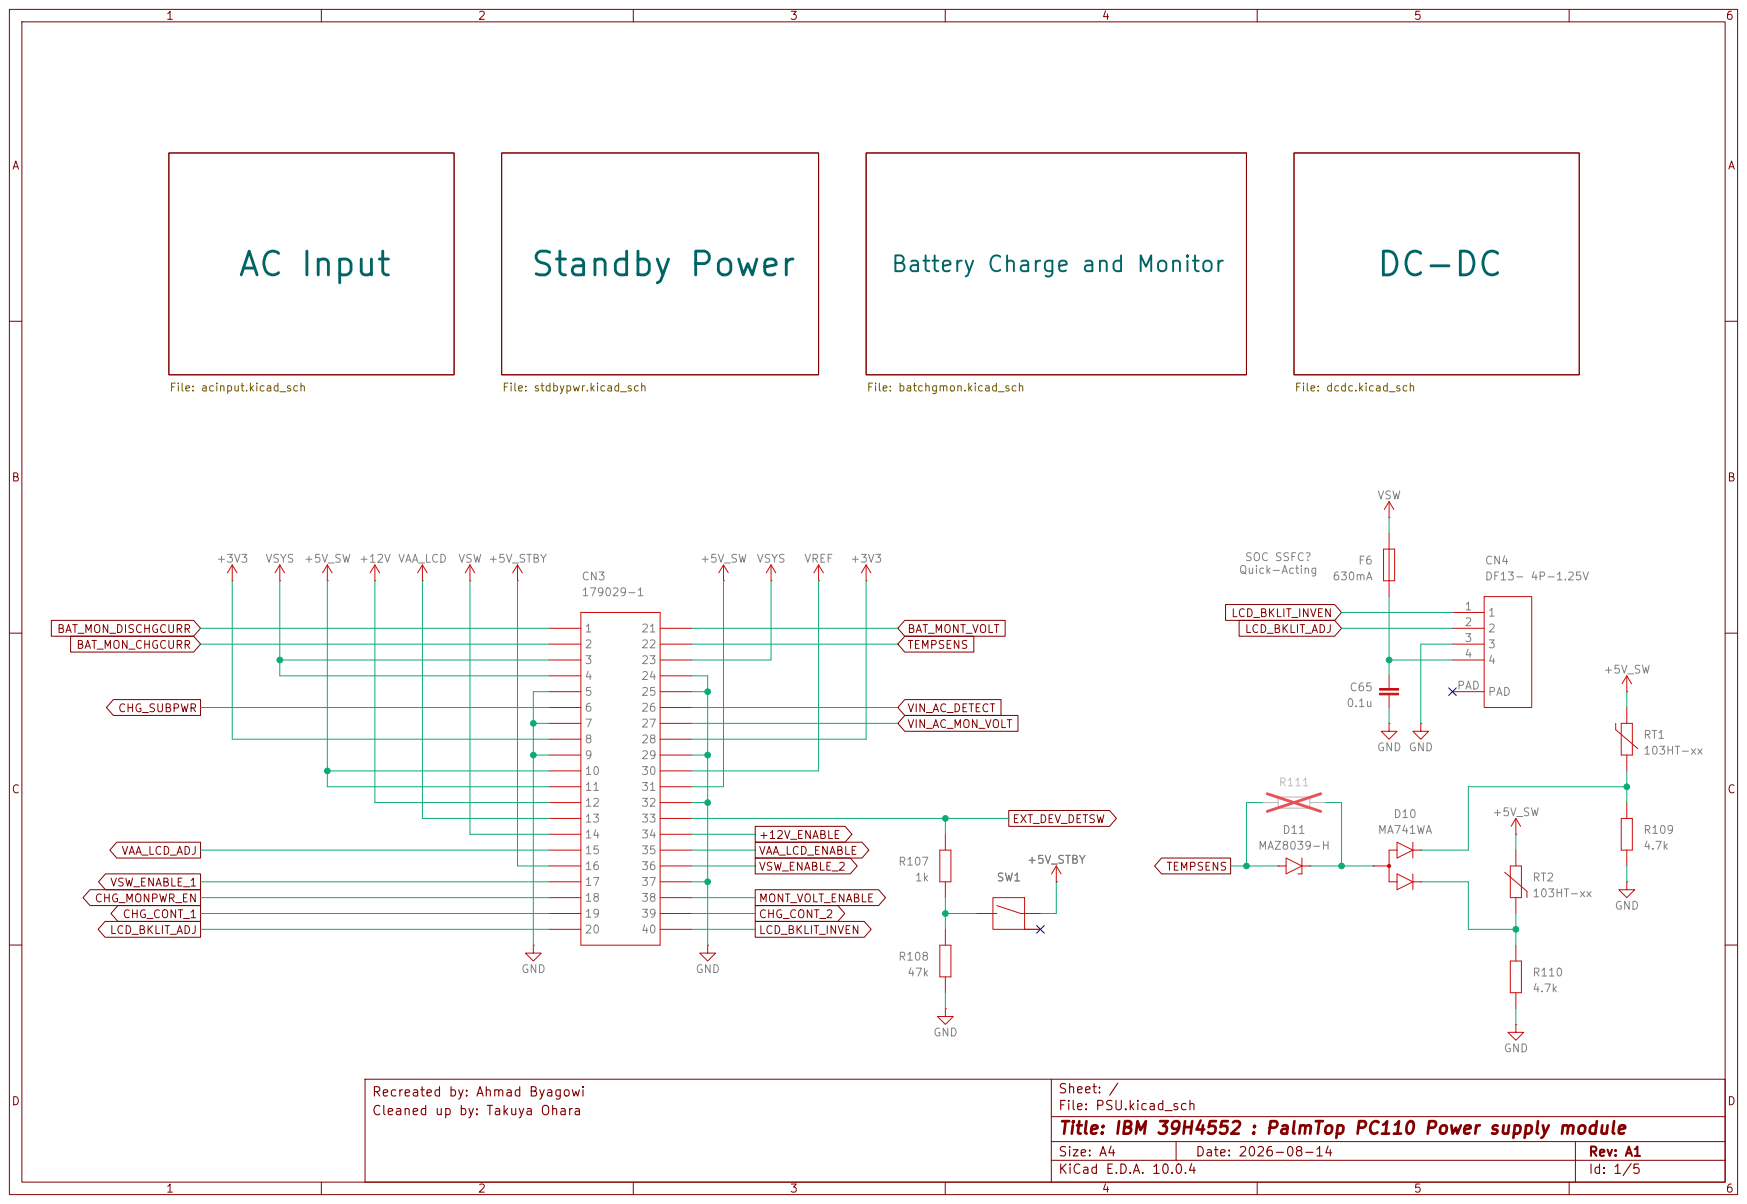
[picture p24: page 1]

File: dcdc.kicad_sch Standby Power

Battery Charge and Monitor

Recreated by: Ahmad Byagowi
Cleaned up by: Takuya Ohara

Sheet: /
File: PSU.kicad_sch
Title: IBM 39H4552 : PalmTop PC110 Power supply module

Size: A4 | Rev: A1
KiCad E.D.A. 10.0.4 | Id: 1/5

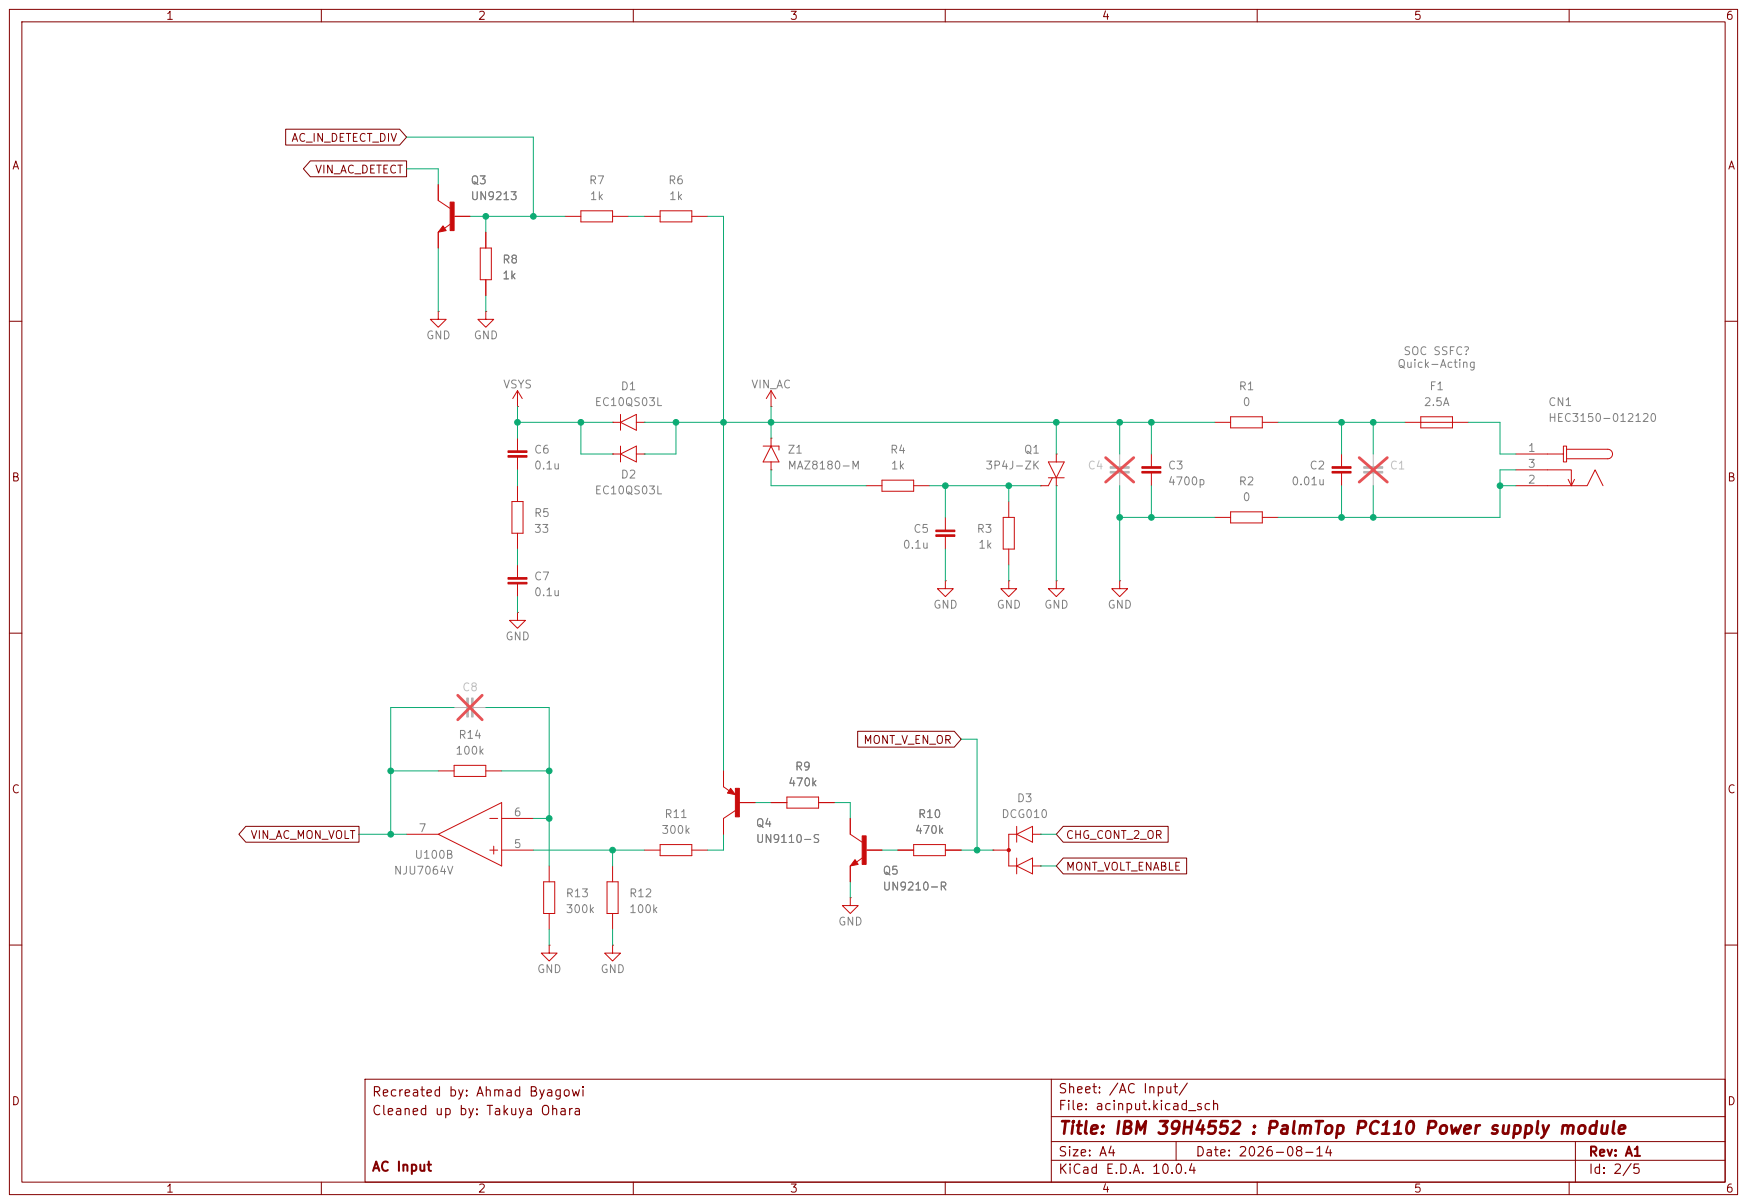
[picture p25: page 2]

SOC SSFC? Quick-Acting R8

Recreated by: Ahmad Byagowi
Cleaned up by: Takuya Ohara

Sheet: /AC Input/
File: acinput.kicad_sch
Title: IBM 39H4552 : PalmTop PC110 Power supply module


Sheet: /Standby Power/
File: stdbypwr.kicad_sch
Title: IBM 39H4552 : PalmTop PC110 Power supply module

Cleaned up by: Takuya Ohara


SOC SSFC? Quick-Acting

Sheet: /Battery Charge and Monitor/
File: batchgmon.kicad_sch
Title: IBM 39H4552 : PalmTop PC110 Power supply module

Cleaned up by: Takuya Ohara

Battery charge and Monitor


Sheet: /DC-DC/
File: dcdc.kicad_sch
Title: IBM 39H4552 : PalmTop PC110 Power supply module

Recreated by: Ahmad Byagowi
Cleaned up by: Takuya Ohara

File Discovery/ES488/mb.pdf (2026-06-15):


8 GND 28 VCC144 GND 44 VCC126 GND 64 VCC109 GND 80 VCC108 GND 100 VCC 90 GND 116 VCC 73 GND 136 VCC 72 VCC 54 VCC 37 NC 132 VCC 36 NC 135 VCC 18 NC 137 VCC

17 U67 M38813M4 C50 DNP
100k GND GND GND GND

3 VCC 27 NC 12 VCC 20 GND

9 NC 11 NC 13 Clock 10 NC 15 LOAD

5 GND 22 GND 26 GND 33 MIC

7 NC 84 VCC 14 NC 82 VCC 38 NC 80 VCC 64 NC 59 VCC 88 NC 49 VCC 95 NC 47 VCC 97 GND 87 GND 63 GND 37 GND 13 GND

GND
HD0 22 HD1 21 HD2 19 HD3 18 HD4 17 HD5 16 HD6 14 HD7 13 HD8 9 HD9 8 HD10 7 HD11 6 HD12 4 HD13 3 HD14 2 HD15 1 SA0 35 SA1 34 SA2 33 SA3 31 SA4 30 SA5 29 SA6 28 SA7 27 SA8 26 SA9 25 SA10 24 RC_IN 11 C_EXT 12 CSEL 23 RESET 36 CE1 37 VCC 38 CE2 39 OE 40 WE 41

5 GND 70 VCC 15 GND 61 VCC 56 GND 44 VCC 88 GND 32 VCC 65 GND 10 GND 20 TEST 64 WPROTCT

1 PS/2_Power 16 GND 51 FDD_PWR 88 GND 50 FDD_PWR 89 GND 64 FDD_PWR 13 GND 66 GND 68 GND 70 GND 75 PNET4 46 GND 85 PNET4 48 GND 100 PNET5 40 NC 32 NC 34 NC 35 J13_53 57 NC 37 J13_53 56 NC 43 J13_53 55 NC 44 J13_53 54 NC 45 J13_53 53 NC 47 NC 49 Pluto_Dock1

9 GND 15 NC 11 GND 16 NC 14 GND 18 GND 19 Cext1

IOR# 18
IOW# 20 WE# 22 CSEL# 28 DMACK# 38

2 GND 14 VCC 25 GND 13 GND

IORD 42
IOWR 43 REG 45 RDY 46 WAIT 47
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

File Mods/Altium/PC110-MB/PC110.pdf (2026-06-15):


Size: A Date: | Rev :
KiCad E. D . A . kicad (5. . 4)-1 | I d :


ASIC[2B],ASIC[3D],Audio[4C],Chipset[2C],Keyboard[2C],Keyboard[4C],PCMCIA[3C],Storage[2C],Super_IO[1B] IOR#

Recreated by: Ahmad Byagowi

Size: A2 | Rev:
KiCad E.D.A. kicad (5.1.4)-1 | Id: 1/1


Size: A | Rev :
KiCad E. D . A . kicad (5. . 4)-1 | I d :


PCMCIA[3A], Power[5B], Super_IO[2C], VGA[5C] RESET

ASIC[2B], ASIC[3B], ASIC[3C], Chipset[1C], Chipset[2D], ROM[3B], Super_IO[2C] PWRGD

AGND 8 VCC 13 GND 5 VCC 4 GND 12

Recreated by: Ahmad Byagowi
Sheet:/
File: Clock.kicad_sch
Title: PC110

Size: A3 | Date: | Rev:
KiCad E.D.A. kicad (5.1.4)-1 | | Id: 1/1


Enables all external PS/2 devices;
PS/2 conn on PC110 and dock

GND 68 GND 66 FDD_PWR 13 GND 64 FDD_PWR 89 GND 50 FDD_PWR 88 GND 51 PS/2_Power 16 GND 1

Recreated by: Ahmad Byagowi
Sheet: /
File: DockStation.kicad_sch
Title: PC110

Size: A1 | Rev:
KiCad E.D.A. kicad (5.1.4)-1 | Id: 1/1


IOW# ASIC[2B], ASIC[3D], Chipset[2C], Keyboard[4C],PCMCIA[3C], Storage[2C], Super_IO[2A]

IOR# ASIC[2B], ASIC[3D], Audio[3C], Audio[4C], Chipset[2C], Keyboard[4C], PCMCIA[3C], Storage[2C], Super_IO[1B]

ASIC[2B], ASIC[3D], Audio[3C], Audio[4C], Chipset[2C], Keyboard[2C], PCMCIA[3C], Storage[2C], Super_IO[1B] IOR#

ASIC[2B], ASIC[3D], Chipset[2C], Keyboard[2C], PCMCIA[3C], Storage[2C], Super_IO[2A] IOW#

ASIC[2B], ASIC[3D], Chipset[3C], PCMCIA[3C], Super_IO[1B] AEN

Recreated by: Ahmad Byagowi
Sheet:/
File: Keyboard.kicad_sch
Title: PC110

Size: A3 | Date: | Rev:
KiCad E.D.A. kicad (5.1.4)-1 | | Id: 1/1


Chipset[2A], Memory[3B], Memory[3C], Processor[1A]

Chipset[6B], Chipset[6D], Memory[1C], Memo

Chipset[6B], Chipset[6D], Memory[1B], Memo

Size : A 3 | Da te : | Re v:
KiC a d E .D. A . kica d (5 . 1 .4)-1 | | I d : 1 /1


Sheet: Keyboard and Trackpoint

Sheet: Docking Station and Modem

Recreated by: Ahmad Byagowi
Sheet: /
File: PC110.kicad_sch
Title: PC110 Motherboard

Size: A4 | Date: | Rev:
KiCad E.D.A. kicad (5.1.4)-1 | | Id:1/1


Size: A | Rev :
KiCad E. D . A . kicad (5. . 4)-1 | I d :


SN74H U 54A | 1 wer[1B],RO Po wer[1 M [4A] D28_1 B] 1 Po wer[1 B] R284_2 Q 43_2 1 V CC C] R73_2 1 1 | 29 28 F 65_EN A V EE Po

1 2 40 | 61 62 M38_SEG9 M38_SEG8

Title: PC110 File: Power.kicad_sch Sheet: / Recreated by: Ahmad Byag

Si z e : A D ate : | Re v:
K i Cad E . D . A . ki cad (5 . . 4)- | I d :


ASIC[1A], Chipset[6B], Processor[5C], VGA

5 | R 3. . 2 1 | 4
1 | R 4. . 2 1

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


ASIC[2B], ASIC[3B], ASIC[3C], Chipset[1C], Chipset[2D], Clock[3A], Sup

ASIC[1B], ASIC[3D], Audio[4B], Chipset[2D], Chipset[6B], Keyboard[1C], PCMCIA[2B], ROM[3B], Storage[1B], Storage[3

Devi
ASIC[1B], ASIC[3D], Audio[4B], Chipset[2D], Chipset[6B], Keyboard[1C], PCMCIA[2B], ROM[1B], Storage[1B], Storage[3

MEMR# Chipset[2C], PCMCIA[3C], ROM

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


GND 10 VCC 65 GND 32 VCC 88 GND 44

rd [ 4 | C ] , Stora | 23 | 84

Size: A | Rev :
KiCad E. D . A . kicad (5. . 4)-1 | I d :


IOW# ASIC[2B], ASIC[3D], Chipset[2C], Keyboard[2C], Keyboard[4C], PCMCIA[3C], Storage[2C]

ASIC[2B], ASIC[3D], Audio[3C], Audio[4C], Chipset[2C], Keyboard[2C], Keyboard[4C], PCMCIA[3C], Storage[2C] IOR#

ASIC[2B], ASIC[3D], Chipset[3C], Keyboard[3C], PCMCIA[3C] AEN

Clock[3A], PCMCIA[3A], Power[5B], VGA[5C] RESET

ASIC[2B], ASIC[3B], ASIC[3C], Chipset[1C], Chipset[2D], Clock[3A], ROM[3B] PWRGD

INDEX# 10 TRK0# 11 DSKCHG# 15 WRTPRT# 12 WGATE# 8 DENSELCT 99 DIR# 5 STEP# 6

Size: A3 | Date: | Rev:
KiCad E.D.A. kicad (5.1.4)-1 | | Id: 1/1


1 4
1 5

24
25

Size: A | Rev :
KiCad E. D . A . kicad (5. . 4)-1 | I d :

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

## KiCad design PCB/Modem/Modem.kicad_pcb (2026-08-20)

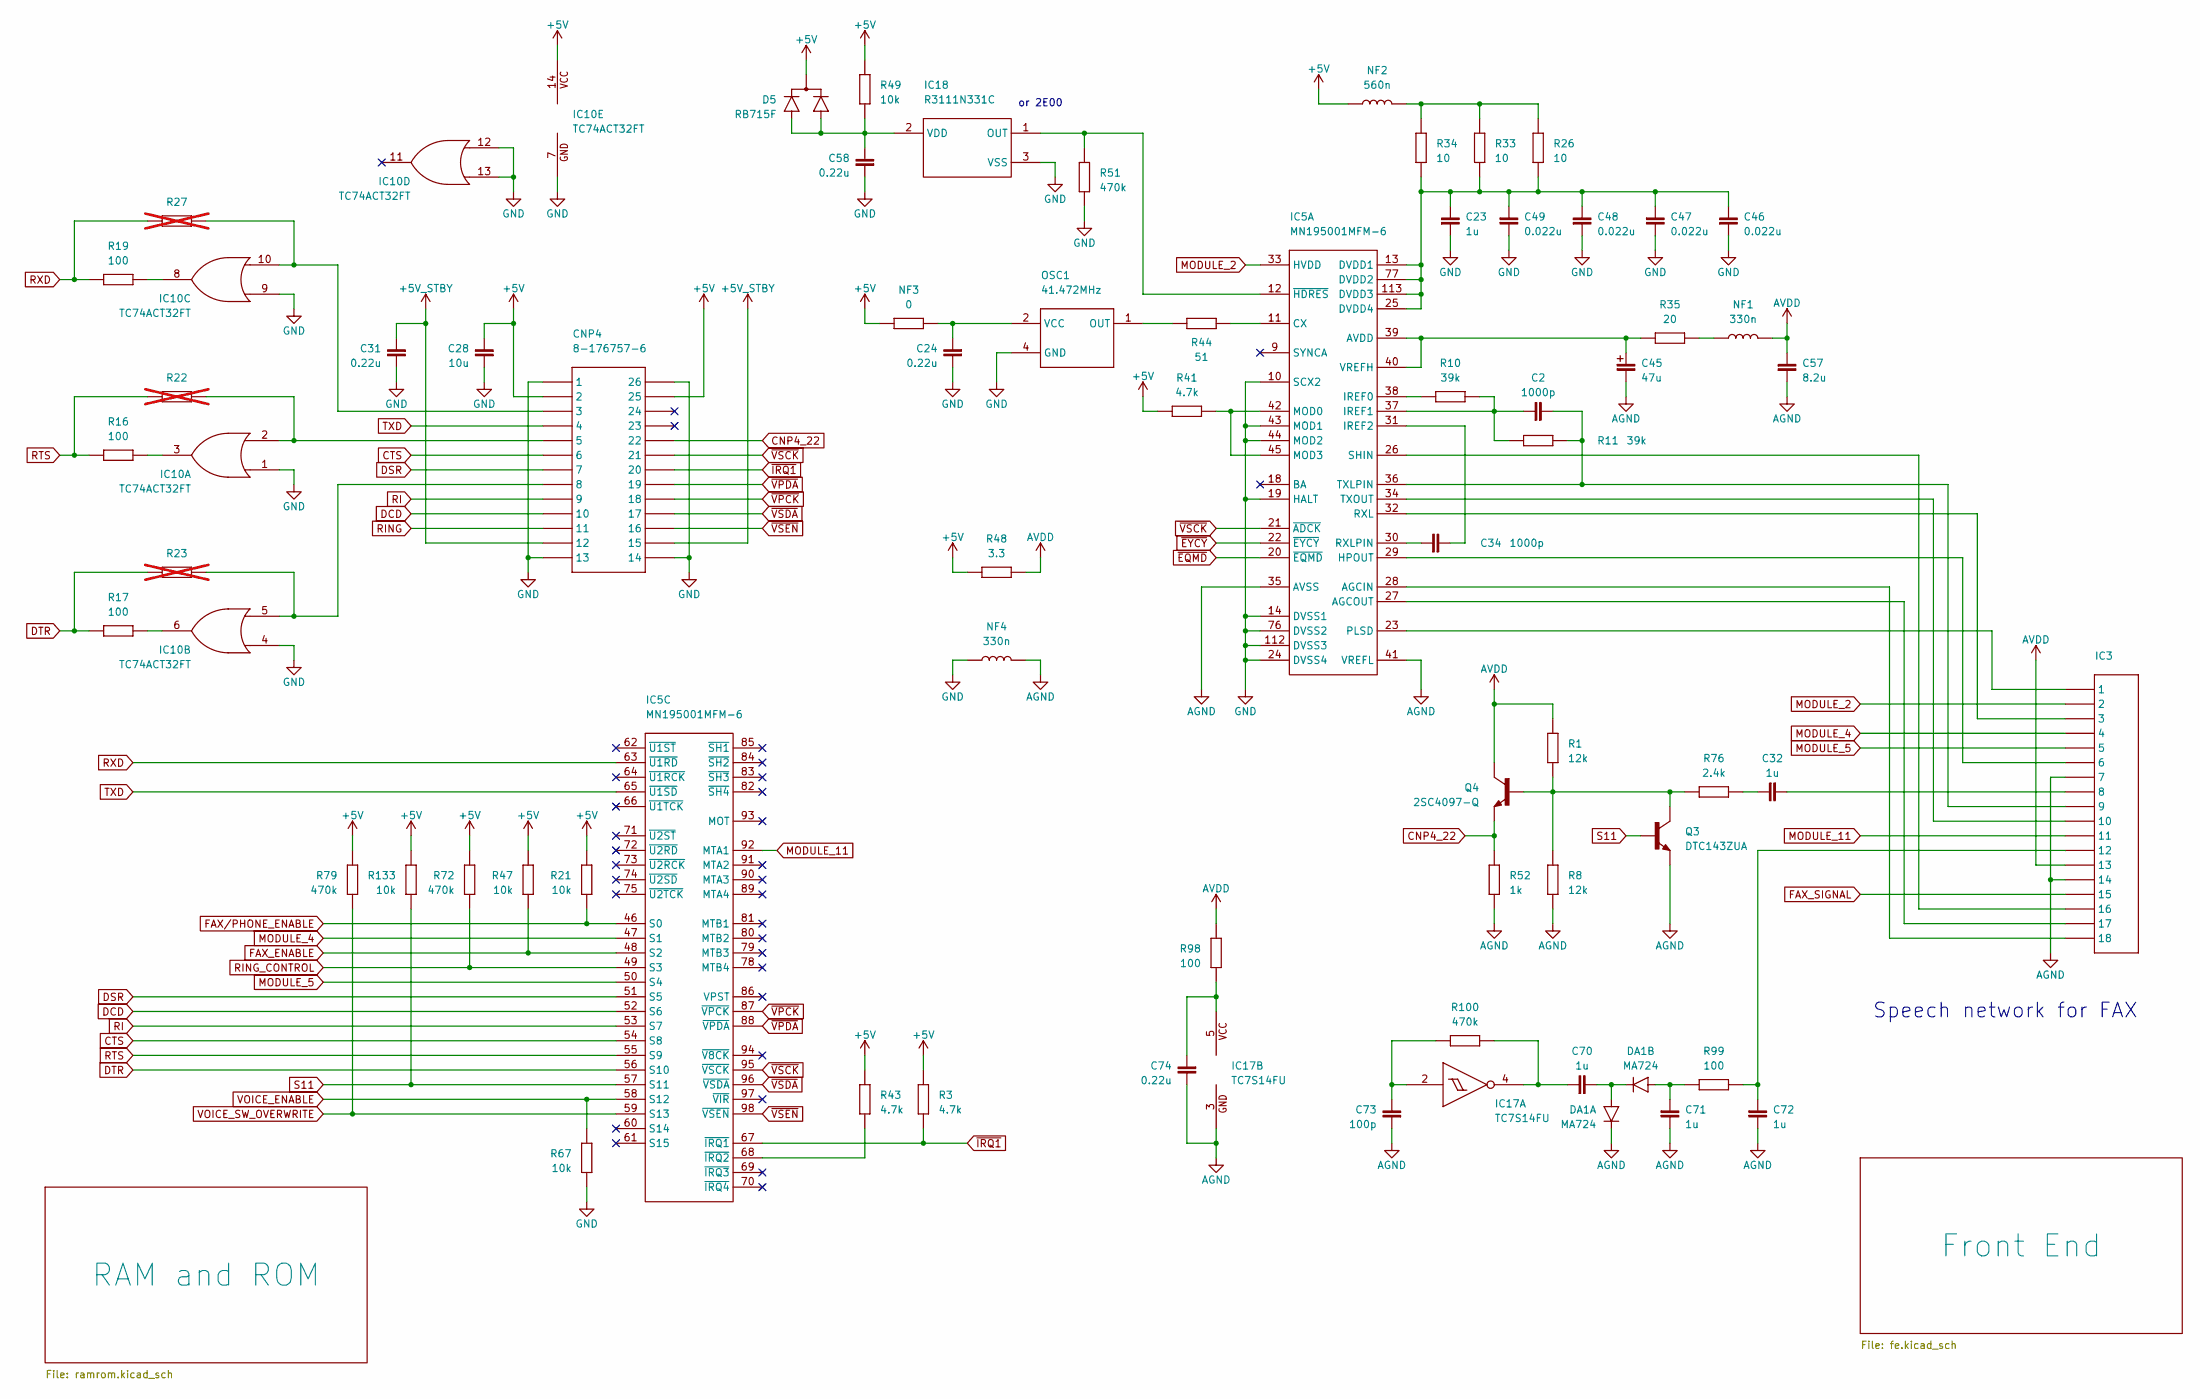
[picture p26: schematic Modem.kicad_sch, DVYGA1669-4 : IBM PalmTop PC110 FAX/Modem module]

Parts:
C2, C34: 1000p
C23, C32, C70, C71, C72: 1u
C24, C31, C58, C74: 0.22u
C28: 10u
C45: 47u
C46, C47, C48, C49: 0.022u
C57: 8.2u
C73: 100p
CNP4: 8-176757-6
D5: RB715F
DA1: MA724
IC3: (no value)
IC5: MN195001MFM-6
IC10: TC74ACT32FT
IC17: TC7S14FU
IC18: R3111N331C
NF1, NF4: 330n
NF2: 560n
NF3: 0
OSC1: 41.472MHz
Q3: DTC143ZUA
Q4: 2SC4097-Q
R1, R8: 12k
R3, R41, R43: 4.7k
R10, R11: 39k
R16, R17, R19, R98, R99: 100
R21, R47, R49, R67, R133: 10k
R22, R23, R27: not fitted
R26, R33, R34: 10
R35: 20
R44: 51
R48: 3.3
R51, R72, R79, R100: 470k
R52: 1k
R76: 2.4k

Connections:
+5V: C28.2, CNP4.2, CNP4.25, D5.3 (C), IC10.14 (VCC), NF2.2, NF3.2, R3.2, R21.1, R41.1, R43.1, R47.1, R48.2, R49.1, R72.1, R79.1, R133.1; also elsewhere on the board
+5V_STBY: C31.2, CNP4.12, CNP4.15; also elsewhere on the board
AGND: C45.1 (2), C57.1, C71.2, C72.2, C73.1, C74.2, DA1.3 (C1), IC3.7, IC3.14, IC5.35 (AVSS), IC5.41 (VREFL), IC17.3 (GND), NF4.1, Q3.2 (E), R8.1, R52.1; also elsewhere on the board
AVDD: C57.2, IC3.13, NF1.2, Q4.3 (C), R1.2, R48.1, R98.2
CNP4_22: CNP4.22, Q4.2 (E), R52.2
CTS: CNP4.6, IC5.54 (S8)
DCD: CNP4.10, IC5.52 (S6)
DSR: CNP4.7, IC5.51 (S5)
DTR: IC5.56 (S10), R17.2, R23.1
FAX_ENABLE: IC5.48 (S2), R47.2; also elsewhere on the board
FAX_SIGNAL: IC3.15; also elsewhere on the board
FAX/PHONE_ENABLE: IC5.46 (S0), R21.2; also elsewhere on the board
GND: C23.1, C24.2, C28.1, C31.1, C46.1, C47.2, C48.1, C49.2, C58.2, CNP4.1, CNP4.13, CNP4.14, CNP4.26, IC5.10 (SCX2), IC5.14 (DVSS1), IC5.19 (HALT), IC5.24 (DVSS4), IC5.43 (MOD1), IC5.44 (MOD2), IC5.76 (DVSS2), IC5.112 (DVSS3), IC10.1 (1A), IC10.4 (2A), IC10.7 (GND), IC10.9 (3A), IC10.12 (4A), IC10.13 (4B), IC18.3 (VSS), NF4.2, OSC1.4 (GND), R51.1, R67.1; also elsewhere on the board
MODULE_2: IC3.2, IC5.33 (HVDD)
MODULE_4: IC3.4, IC5.47 (S1)
MODULE_5: IC3.5, IC5.50 (S4)
MODULE_11: IC3.11, IC5.92 (MTA1)
unnamed: C32.1, IC3.8
unnamed: C32.2, R76.1
unnamed: C45.2 (1), IC5.39 (AVDD), IC5.40 (VREFH), R35.2
unnamed: C72.1, IC3.12, R99.2
unnamed: C58.1, D5.1 (A1), D5.2 (A2), IC18.2 (VDD), R49.2
unnamed: C70.2, DA1.1 (A1), DA1.4 (C2)
unnamed: C71.1, DA1.2 (A2), R99.1
unnamed: IC3.18, IC5.28 (AGCIN)
unnamed: IC3.17, IC5.27 (AGCOUT)
unnamed: IC5.11 (CX), R44.1
unnamed: C23.2, C46.2, C47.1, C48.2, C49.1, IC5.13 (DVDD1), IC5.25 (DVDD4), IC5.77 (DVDD2), IC5.113 (DVDD3), R26.1, R33.1, R34.1
unnamed: IC3.6, IC5.29 (HPOUT)
unnamed: IC5.38 (IREF0), R10.1
unnamed: C2.1, IC5.37 (IREF1), R10.2, R11.1
unnamed: C34.2, IC5.31 (IREF2)
unnamed: IC5.42 (MOD0), IC5.45 (MOD3), R41.2
unnamed: IC3.1, IC5.23 (PLSD)
unnamed: IC3.3, IC5.32 (RXL)
unnamed: C34.1, IC5.30 (RXLPIN)
unnamed: IC3.16, IC5.26 (SHIN)
unnamed: C2.2, IC3.9, IC5.36 (TXLPIN), R11.2
unnamed: IC3.10, IC5.34 (TXOUT)
unnamed: IC5.68 (~IRQ2), R43.2
unnamed: CNP4.5, IC10.2 (1B), R22.2
unnamed: IC10.3 (1Y), R16.1
unnamed: CNP4.8, IC10.5 (2B), R23.2
unnamed: IC10.6 (2Y), R17.1
unnamed: CNP4.3, IC10.10 (3B), R27.1
unnamed: IC10.8 (3Y), R19.2
unnamed: C73.2, IC17.2 (I), R100.2
unnamed: C70.1, IC17.4 (O), R100.1
unnamed: C74.1, IC17.5 (VCC), R98.1
unnamed: IC5.12 (~HDRES), IC18.1 (OUT), R51.2
unnamed: NF1.1, R35.1
unnamed: NF2.1, R26.2, R33.2, R34.2
unnamed: OSC1.1 (OUT), R44.2
unnamed: C24.1, NF3.1, OSC1.2 (VCC)
unnamed: Q3.3 (C), Q4.1 (B), R1.1, R8.2, R76.2
RI: CNP4.9, IC5.53 (S7)
RING: CNP4.11; also elsewhere on the board
RING_CONTROL: IC5.49 (S3), R72.2; also elsewhere on the board
RTS: IC5.55 (S9), R16.2, R22.1
RXD: IC5.63 (~U1RD), R19.1, R27.2
S11: IC5.57 (S11), Q3.1 (B), R133.2
TXD: CNP4.4, IC5.65 (~U1SD)
VOICE_ENABLE: IC5.58 (S12), R67.2; also elsewhere on the board
VOICE_SW_OVERWRITE: IC5.59 (S13), R79.2; also elsewhere on the board
~EQMD: IC5.20 (~EQMD)
~EYCY: IC5.22 (~EYCY)
~IRQ1: CNP4.20, IC5.67 (~IRQ1), R3.1
~VPCK: CNP4.18, IC5.87 (~VPCK)
~VPDA: CNP4.19, IC5.88 (~VPDA)
~VSCK: CNP4.21, IC5.21 (~ADCK), IC5.95 (~VSCK)
~VSDA: CNP4.17, IC5.96 (~VSDA)
~VSEN: CNP4.16, IC5.98 (~VSEN)

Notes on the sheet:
Speech network for FAX
or 2E00

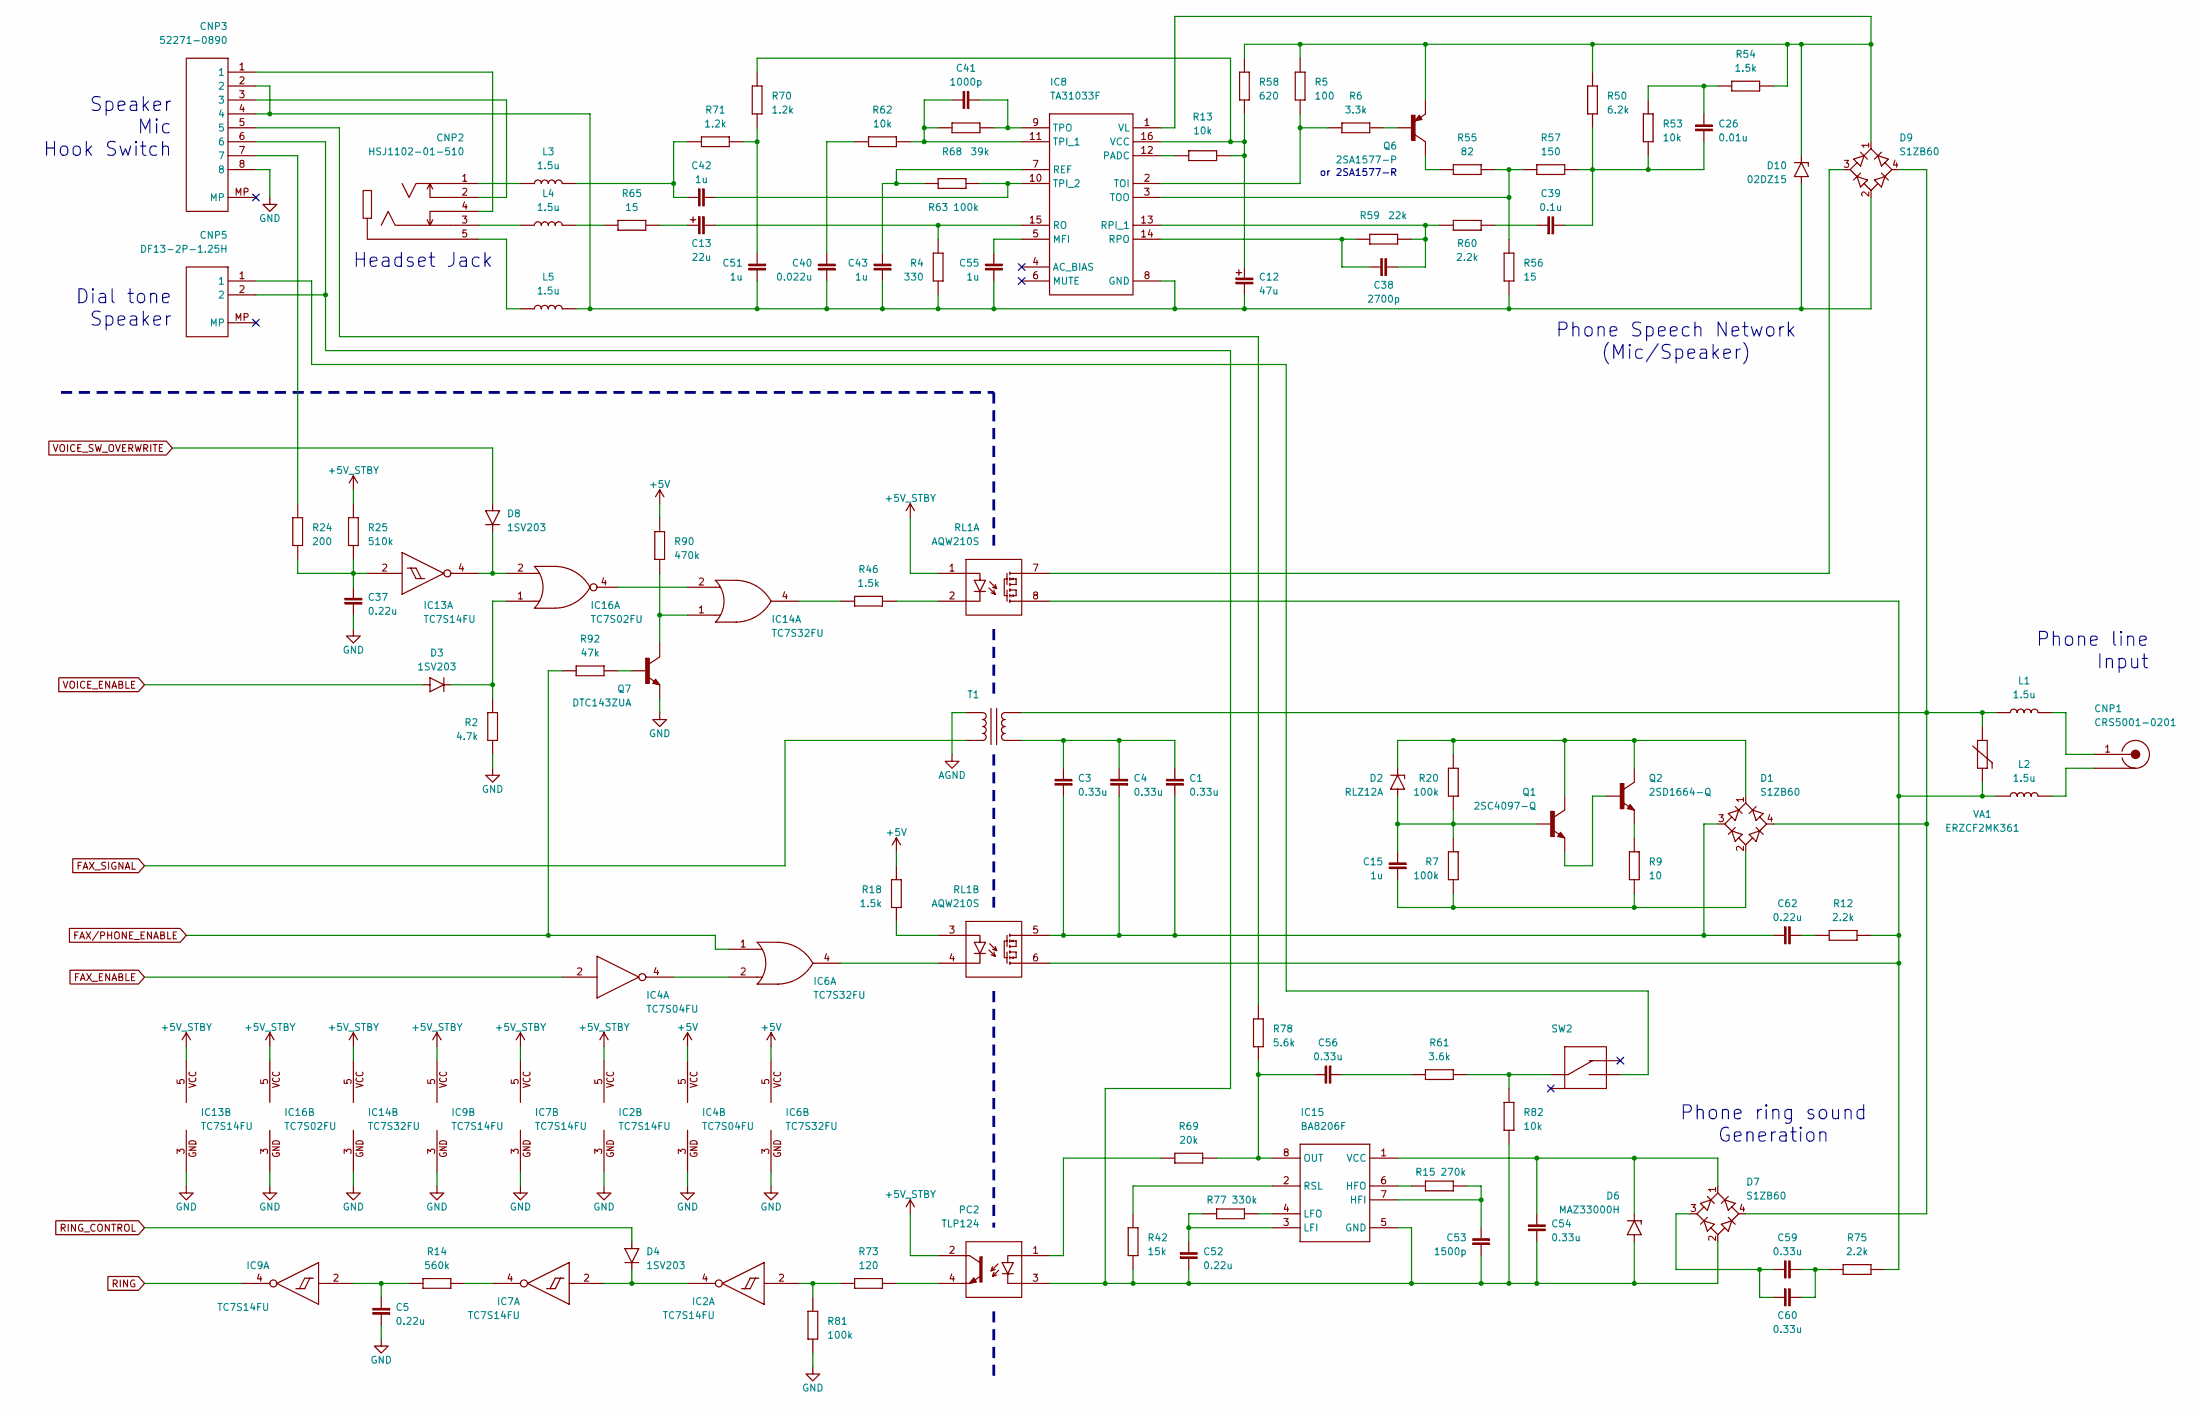
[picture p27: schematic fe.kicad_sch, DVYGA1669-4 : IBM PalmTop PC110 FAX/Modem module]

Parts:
C1, C3, C4, C54, C56, C59, C60: 0.33u
C5, C37, C52, C62: 0.22u
C12: 47u
C13: 22u
C15, C42, C43, C51, C55: 1u
C26: 0.01u
C38: 2700p
C39: 0.1u
C40: 0.022u
C41: 1000p
C53: 1500p
CNP1: CRS5001-0201
CNP2: HSJ1102-01-510
CNP3: 52271-0890
CNP5: DF13-2P-1.25H
D1, D7, D9: S1ZB60
D2: RLZ12A
D3, D4, D8: 1SV203
D6: MAZ33000H
D10: 02DZ15
IC2, IC7, IC9, IC13: TC7S14FU
IC4: TC7S04FU
IC6, IC14: TC7S32FU
IC8: TA31033F
IC15: BA8206F
IC16: TC7S02FU
L1, L2, L3, L4, L5: 1.5u
PC2: TLP124
Q1: 2SC4097-Q
Q2: 2SD1664-Q
Q6: 2SA1577-P
Q7: DTC143ZUA
R2: 4.7k
R4: 330
R5: 100
R6: 3.3k
R7, R20, R63, R81: 100k
R9: 10
R12, R60, R75: 2.2k
R13, R53, R62, R82: 10k
R14: 560k
R15: 270k
R18, R46, R54: 1.5k
R24: 200
R25: 510k
R42: 15k
R50: 6.2k
R55: 82
R56, R65: 15
R57: 150
R58: 620
R59: 22k
R61: 3.6k
R68: 39k
R69: 20k
R70, R71: 1.2k
R73: 120
R77: 330k
R78: 5.6k
R90: 470k
R92: 47k
RL1: AQW210S
SW2: (no value)
T1: (no value)
VA1: ERZCF2MK361

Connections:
+5V: IC4.5 (VCC), IC6.5 (VCC), R18.1, R90.1; also elsewhere on the board
+5V_STBY: IC2.5 (VCC), IC7.5 (VCC), IC9.5 (VCC), IC13.5 (VCC), IC14.5 (VCC), IC16.5 (VCC), PC2.2 (C), R25.1, RL1.1; also elsewhere on the board
AGND: T1.2; also elsewhere on the board
FAX_ENABLE: IC4.2 (I); also elsewhere on the board
FAX_SIGNAL: T1.3; also elsewhere on the board
FAX/PHONE_ENABLE: IC6.1 (I0), R92.1; also elsewhere on the board
GND: C5.1, C37.2, CNP3.8, IC2.3 (GND), IC4.3 (GND), IC6.3 (GND), IC7.3 (GND), IC9.3 (GND), IC13.3 (GND), IC14.3 (GND), IC16.3 (GND), Q7.2 (E), R2.1, R81.1; also elsewhere on the board
unnamed: C1.1, C3.1, C4.1, C62.1, D1.3 (AC), RL1.5
unnamed: C1.2, C3.2, C4.2, T1.4
unnamed: C12.2 (1), IC8.16 (VCC), R13.2, R58.1, R70.2
unnamed: C12.1 (2), C40.1, C43.1, C51.2, C55.2, CNP3.2, CNP3.4, D9.2 (-), D10.2 (A), IC8.8 (GND), L5.1, R4.1, R56.2
unnamed: C13.2 (1), R65.2
unnamed: C13.1 (2), IC8.15 (RO), R4.2
unnamed: C26.1, C39.2, R50.2, R53.1, R57.2
unnamed: C26.2, R53.2, R54.2
unnamed: C39.1, R60.2
unnamed: C40.2, R62.2
unnamed: C42.1, L3.1, R71.1
unnamed: C51.1, R70.1, R71.2
unnamed: C56.1, R61.2
unnamed: C59.1, C60.1, D7.3 (AC)
unnamed: C59.2, C60.2, R75.1
unnamed: C62.2, R12.2
unnamed: CNP1.2 (PAD), CNP1.3 (PAD), CNP1.4 (PAD), L2.1
unnamed: CNP1.1, L1.1
unnamed: CNP2.1, L3.2
unnamed: CNP2.2, CNP3.3
unnamed: CNP2.3, L4.2
unnamed: CNP2.4, CNP3.1
unnamed: CNP2.5, L5.2
unnamed: CNP3.5, R78.2
unnamed: CNP3.7, R24.2
unnamed: CNP5.1, SW2.3
unnamed: D1.1 (+), D2.1 (C), Q1.3 (C), Q2.2 (C), R20.1
unnamed: C15.1, D1.2 (-), R7.1, R9.2
unnamed: D1.4 (AC), D7.4 (AC), D9.4 (AC), L1.2, T1.1, VA1.1
unnamed: C15.2, D2.2 (A), Q1.1 (B), R7.2, R20.2
unnamed: D3.1 (C), IC16.1 (I0), R2.2
unnamed: D4.1 (C), IC2.4 (O), IC7.2 (I)
unnamed: C52.2, C53.1, C54.1, CNP3.6, CNP5.2, D6.1 (A), D7.2 (-), IC15.5 (GND), PC2.3 (C), R42.2, R82.1
unnamed: C54.2, D6.3 (C), D7.1 (+), IC15.1 (VCC)
unnamed: D8.1 (C), IC13.4 (O), IC16.2 (I1)
unnamed: D9.3 (AC), RL1.7
unnamed: D9.1 (+), D10.1 (C), IC8.1 (VL), Q6.2 (E), R5.2, R50.1, R54.1, R58.2
unnamed: IC2.2 (I), R73.2, R81.2
unnamed: IC4.4 (O), IC6.2 (I1)
unnamed: IC6.4 (O), RL1.4
unnamed: IC7.4 (O), R14.1
unnamed: C55.1, IC8.5 (MFI)
unnamed: IC8.12 (PADC), R13.1
unnamed: C43.2, IC8.7 (REF), R63.2
unnamed: C38.1, IC8.13 (RPI_1), R59.1, R60.1
unnamed: C38.2, IC8.14 (RPO), R59.2
unnamed: IC8.2 (TOI), R5.1, R6.2
unnamed: IC8.3 (TOO), R55.2, R56.1, R57.1
unnamed: C41.2, IC8.11 (TPI_1), R62.1, R68.2
unnamed: C42.2, IC8.10 (TPI_2), R63.1
unnamed: C41.1, IC8.9 (TPO), R68.1
unnamed: C5.2, IC9.2 (I), R14.2
unnamed: C37.1, IC13.2 (I), R24.1, R25.2
unnamed: IC14.1 (I0), Q7.3 (C), R90.2
unnamed: IC14.2 (I1), IC16.4 (O)
unnamed: IC14.4 (O), R46.1
unnamed: C53.2, IC15.7 (HFI), R15.2
unnamed: IC15.6 (HFO), R15.1
unnamed: C52.1, IC15.3 (LFI), R77.2
unnamed: IC15.4 (LFO), R77.1
unnamed: C56.2, IC15.8 (OUT), R69.1, R78.1
unnamed: IC15.2 (RSL), R42.1
unnamed: L2.2, R12.1, R75.2, RL1.6, RL1.8, VA1.2
unnamed: L4.1, R65.1
unnamed: PC2.1 (A), R69.2
unnamed: PC2.4 (E), R73.1
unnamed: Q1.2 (E), Q2.1 (B)
unnamed: Q2.3 (E), R9.1
unnamed: Q6.1 (B), R6.1
unnamed: Q6.3 (C), R55.1
unnamed: Q7.1 (B), R92.2
unnamed: R18.2, RL1.3
unnamed: R46.2, RL1.2
unnamed: R61.1, R82.2, SW2.2
RING: IC9.4 (O); also elsewhere on the board
RING_CONTROL: D4.2 (A); also elsewhere on the board
VOICE_ENABLE: D3.2 (A); also elsewhere on the board
VOICE_SW_OVERWRITE: D8.2 (A); also elsewhere on the board

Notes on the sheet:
Headset Jack
Phone ring sound Generation
or 2SA1577-R
Phone Speech Network (Mic/Speaker)
Phone line Input
Dial tone Speaker
Speaker Mic Hook Switch

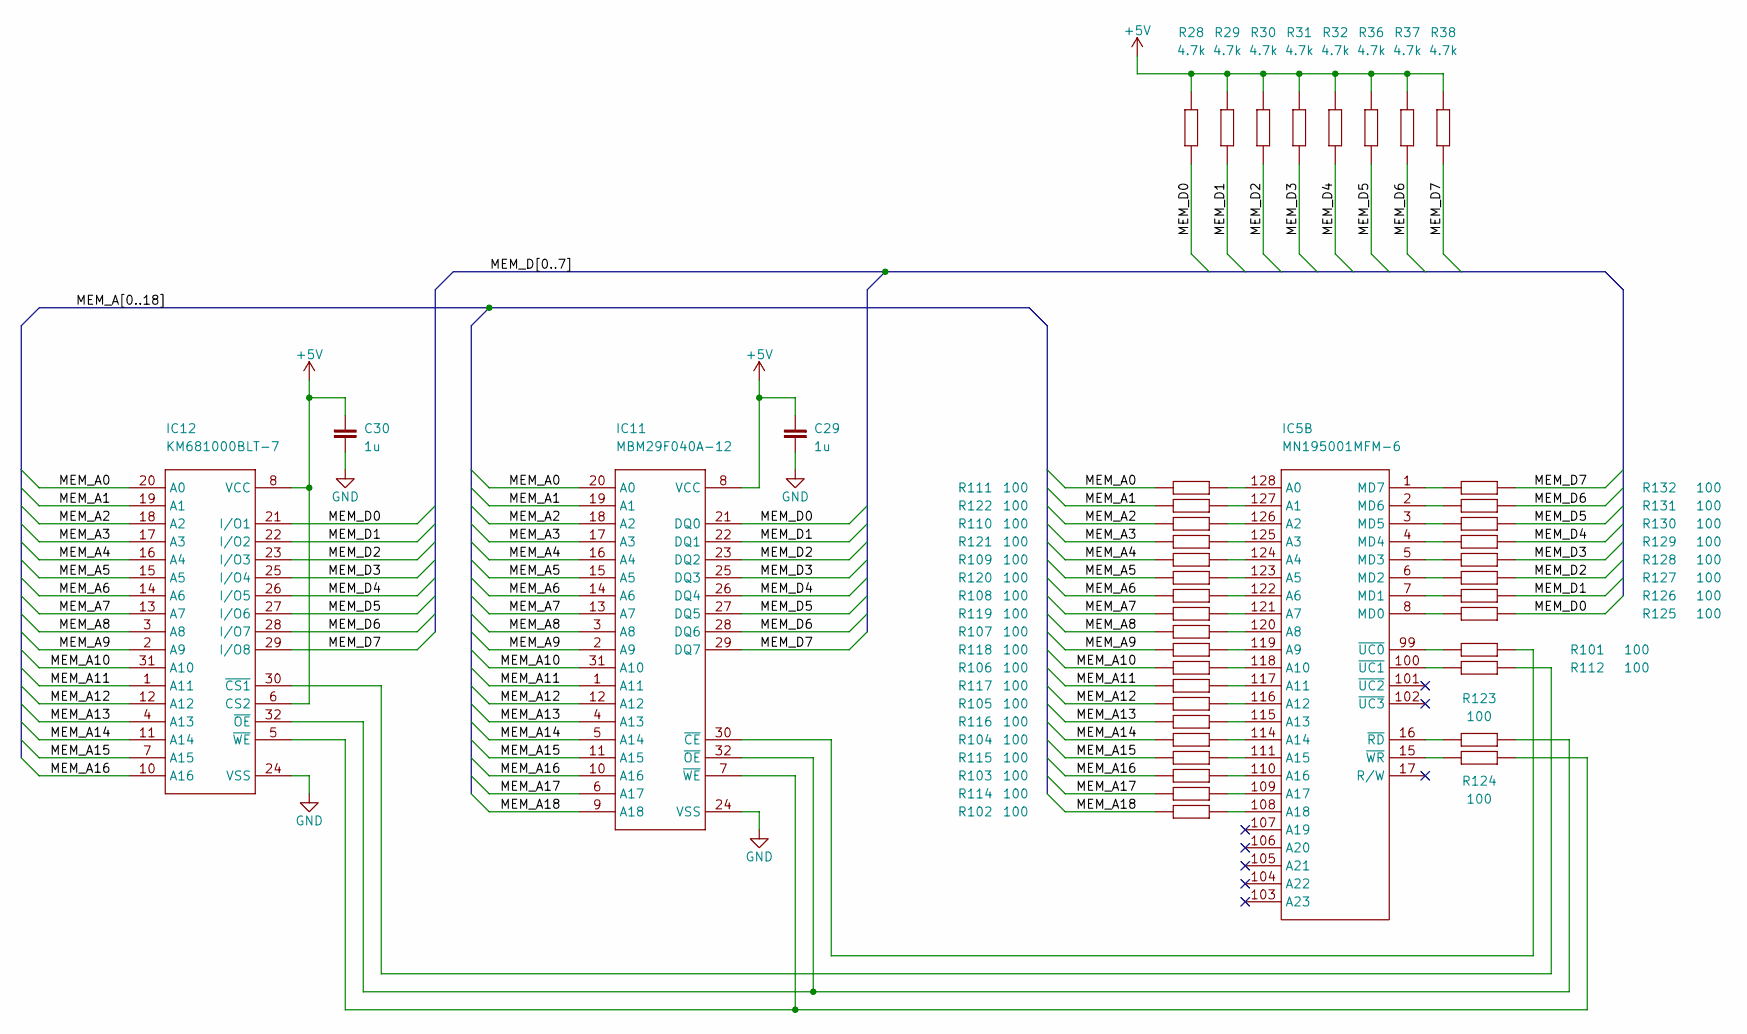
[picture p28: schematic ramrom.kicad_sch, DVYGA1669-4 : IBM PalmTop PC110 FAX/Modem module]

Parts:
C29, C30: 1u
IC5: MN195001MFM-6
IC11: MBM29F040A-12
IC12: KM681000BLT-7
R28, R29, R30, R31, R32, R36, R37, R38: 4.7k
R101, R102, R103, R104, R105, R106, R107, R108, R109, R110, R111, R112, R114, R115, R116, R117, R118, R119, R120, R121, R122, R123, R124, R125, R126, R127, R128, R129, R130, R131, R132: 100

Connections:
+5V: C29.2, C30.1, IC11.8 (VCC), IC12.6 (CS2), IC12.8 (VCC), R28.1, R29.1, R30.1, R31.1, R32.1, R36.1, R37.1, R38.1; also elsewhere on the board
/RAM and ROM/MEM_A0: IC11.20 (A0), IC12.20 (A0), R111.1
/RAM and ROM/MEM_A1: IC11.19 (A1), IC12.19 (A1), R122.1
/RAM and ROM/MEM_A2: IC11.18 (A2), IC12.18 (A2), R110.1
/RAM and ROM/MEM_A3: IC11.17 (A3), IC12.17 (A3), R121.1
/RAM and ROM/MEM_A4: IC11.16 (A4), IC12.16 (A4), R109.1
/RAM and ROM/MEM_A5: IC11.15 (A5), IC12.15 (A5), R120.1
/RAM and ROM/MEM_A6: IC11.14 (A6), IC12.14 (A6), R108.1
/RAM and ROM/MEM_A7: IC11.13 (A7), IC12.13 (A7), R119.1
/RAM and ROM/MEM_A8: IC11.3 (A8), IC12.3 (A8), R107.1
/RAM and ROM/MEM_A9: IC11.2 (A9), IC12.2 (A9), R118.1
/RAM and ROM/MEM_A10: IC11.31 (A10), IC12.31 (A10), R106.1
/RAM and ROM/MEM_A11: IC11.1 (A11), IC12.1 (A11), R117.1
/RAM and ROM/MEM_A12: IC11.12 (A12), IC12.12 (A12), R105.1
/RAM and ROM/MEM_A13: IC11.4 (A13), IC12.4 (A13), R116.1
/RAM and ROM/MEM_A14: IC11.5 (A14), IC12.11 (A14), R104.1
/RAM and ROM/MEM_A15: IC11.11 (A15), IC12.7 (A15), R115.1
/RAM and ROM/MEM_A16: IC11.10 (A16), IC12.10 (A16), R103.1
/RAM and ROM/MEM_A17: IC11.6 (A17), R114.1
/RAM and ROM/MEM_A18: IC11.9 (A18), R102.1
/RAM and ROM/MEM_D0: IC11.21 (DQ0), IC12.21 (I/O1), R28.2, R125.1
/RAM and ROM/MEM_D1: IC11.22 (DQ1), IC12.22 (I/O2), R29.2, R126.1
/RAM and ROM/MEM_D2: IC11.23 (DQ2), IC12.23 (I/O3), R30.2, R127.1
/RAM and ROM/MEM_D3: IC11.25 (DQ3), IC12.25 (I/O4), R31.2, R128.1
/RAM and ROM/MEM_D4: IC11.26 (DQ4), IC12.26 (I/O5), R32.2, R129.1
/RAM and ROM/MEM_D5: IC11.27 (DQ5), IC12.27 (I/O6), R36.2, R130.1
/RAM and ROM/MEM_D6: IC11.28 (DQ6), IC12.28 (I/O7), R37.2, R131.1
/RAM and ROM/MEM_D7: IC11.29 (DQ7), IC12.29 (I/O8), R38.2, R132.1
GND: C29.1, C30.2, IC11.24 (VSS), IC12.24 (VSS); also elsewhere on the board
unnamed: IC5.128 (A0), R111.2
unnamed: IC5.127 (A1), R122.2
unnamed: IC5.126 (A2), R110.2
unnamed: IC5.125 (A3), R121.2
unnamed: IC5.124 (A4), R109.2
unnamed: IC5.123 (A5), R120.2
unnamed: IC5.122 (A6), R108.2
unnamed: IC5.121 (A7), R119.2
unnamed: IC5.120 (A8), R107.2
unnamed: IC5.119 (A9), R118.2
unnamed: IC5.118 (A10), R106.2
unnamed: IC5.117 (A11), R117.2
unnamed: IC5.116 (A12), R105.2
unnamed: IC5.115 (A13), R116.2
unnamed: IC5.114 (A14), R104.2
unnamed: IC5.111 (A15), R115.2
unnamed: IC5.110 (A16), R103.2
unnamed: IC5.109 (A17), R114.2
unnamed: IC5.108 (A18), R102.2
unnamed: IC5.8 (MD0), R125.2
unnamed: IC5.7 (MD1), R126.2
unnamed: IC5.6 (MD2), R127.2
unnamed: IC5.5 (MD3), R128.2
unnamed: IC5.4 (MD4), R129.2
unnamed: IC5.3 (MD5), R130.2
unnamed: IC5.2 (MD6), R131.2
unnamed: IC5.1 (MD7), R132.2
unnamed: IC5.16 (~RD), R123.2
unnamed: IC5.99 (~UC0), R101.2
unnamed: IC5.100 (~UC1), R112.2
unnamed: IC5.15 (~WR), R124.2
unnamed: IC11.30 (~CE), R101.1
unnamed: IC11.32 (~OE), IC12.32 (~OE), R123.1
unnamed: IC11.7 (~WE), IC12.5 (~WE), R124.1
unnamed: IC12.30 (~CS1), R112.1

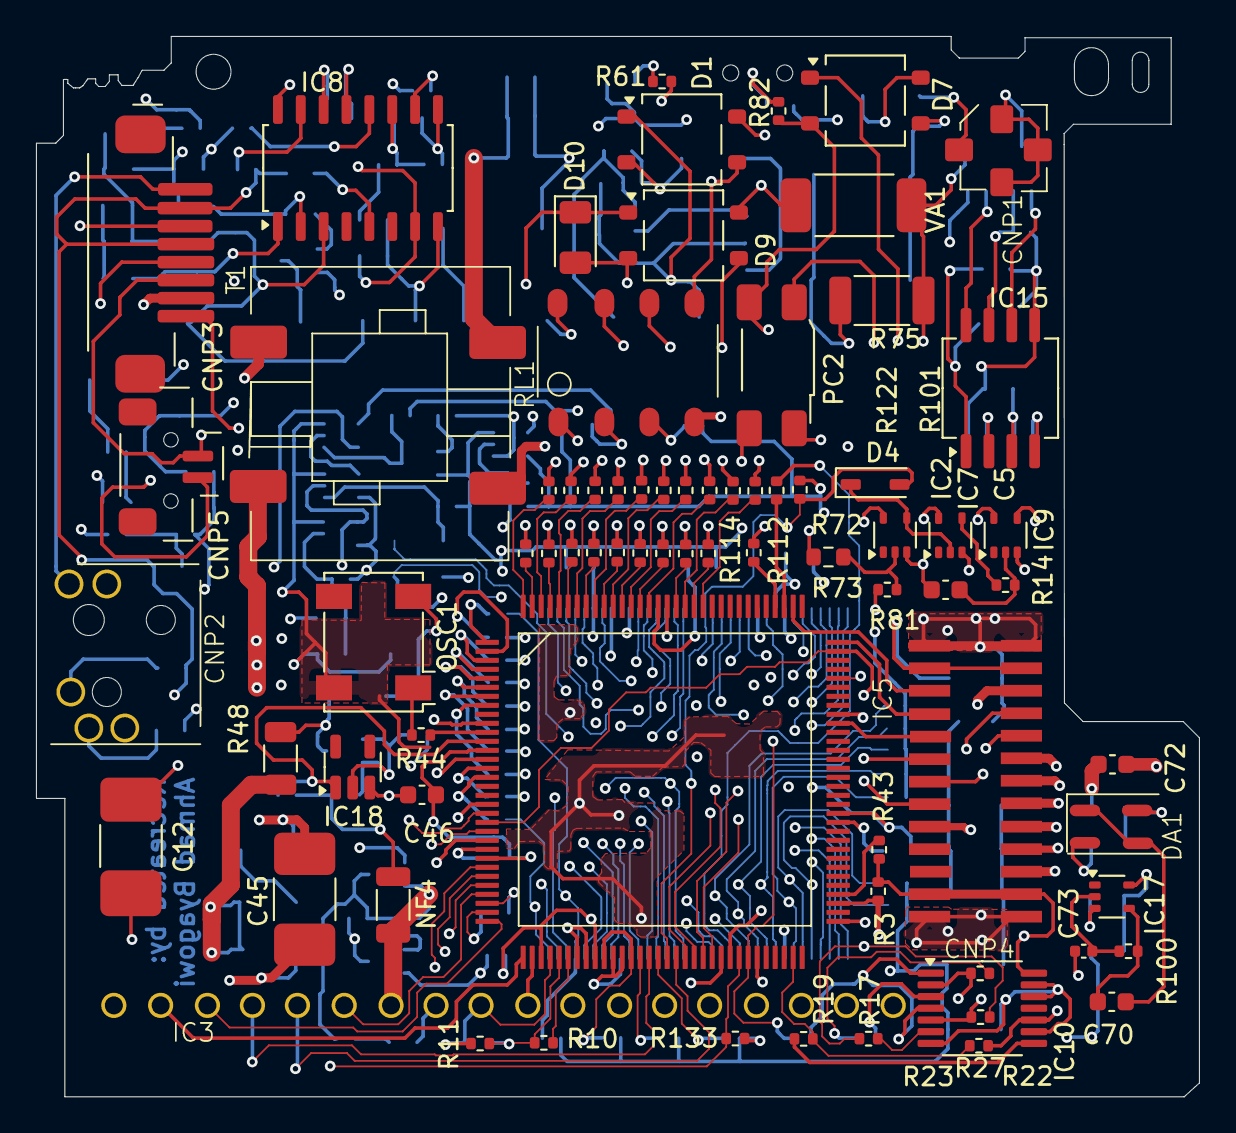
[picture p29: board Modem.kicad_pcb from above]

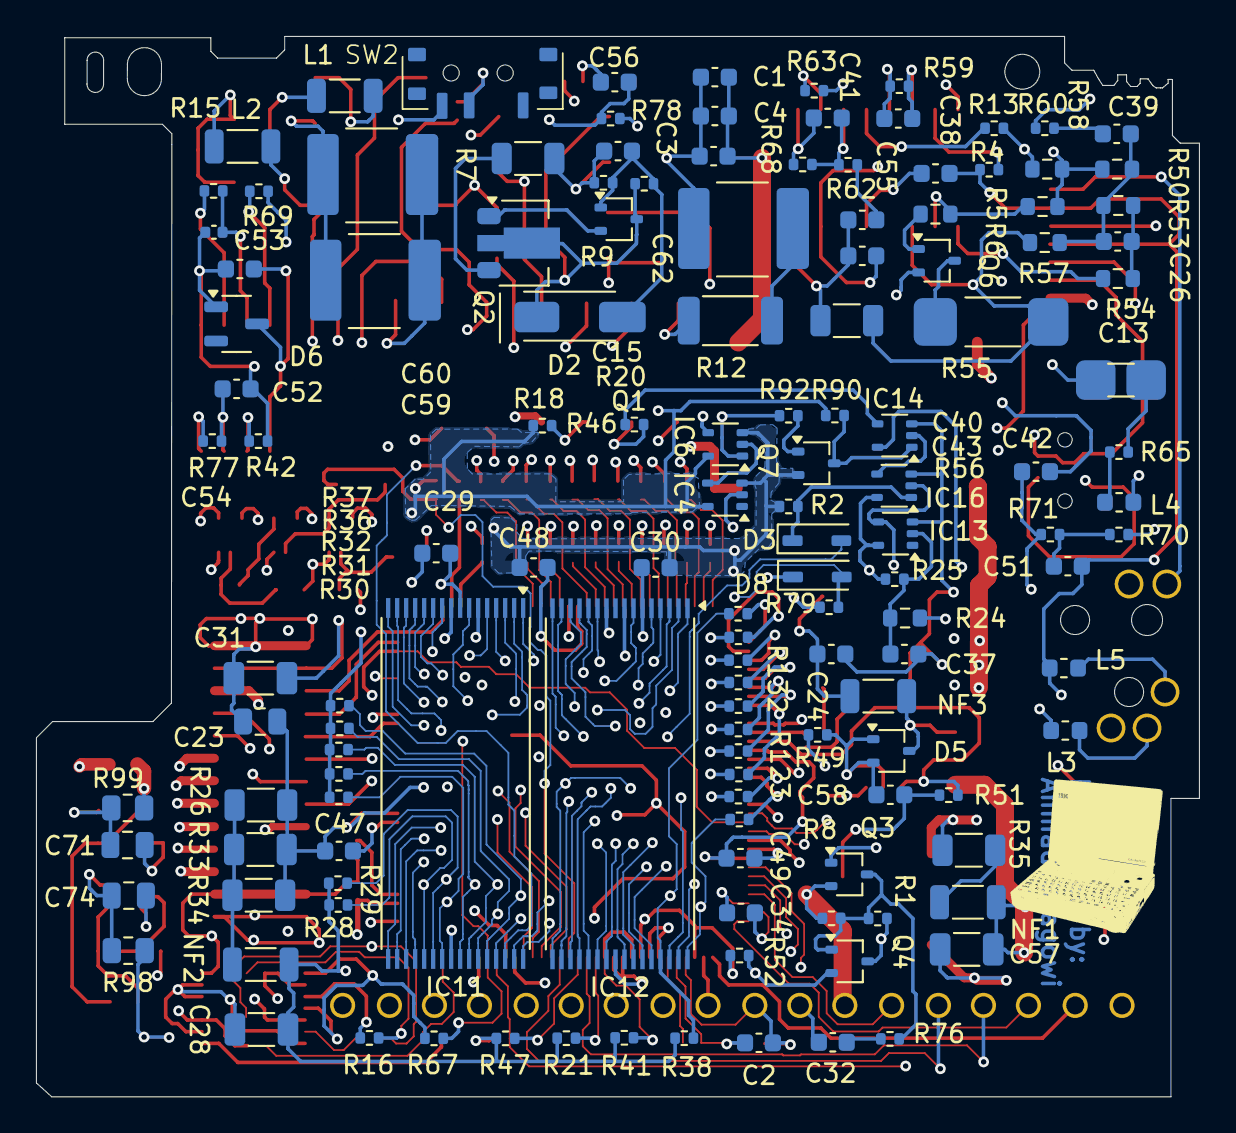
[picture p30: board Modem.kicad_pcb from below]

Board: 6 copper layers, 64.6 x 58.9 mm, 211 parts (136 on the bottom side), 206 nets.

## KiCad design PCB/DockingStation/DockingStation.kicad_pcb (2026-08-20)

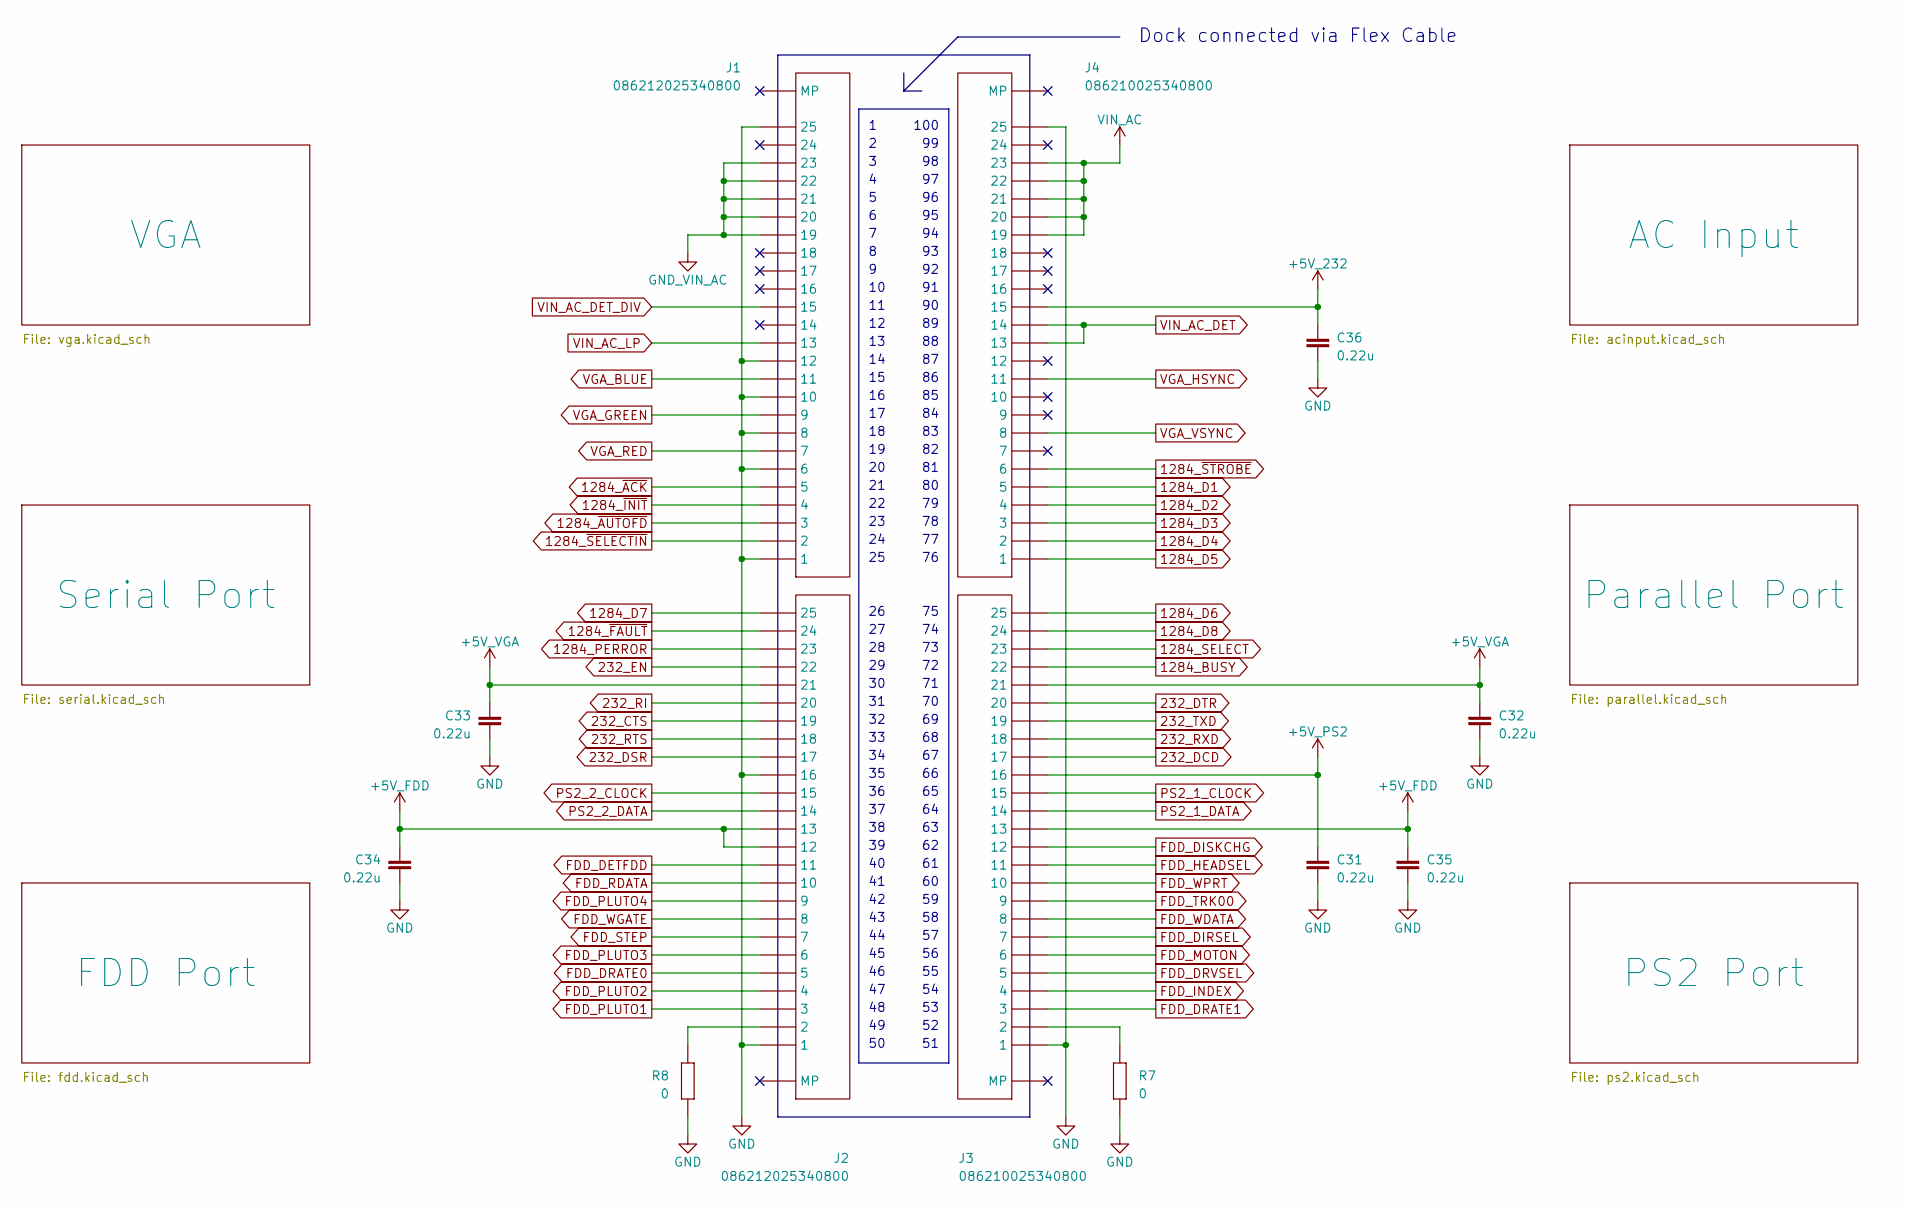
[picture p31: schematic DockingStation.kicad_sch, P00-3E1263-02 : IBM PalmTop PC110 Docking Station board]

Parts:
C31, C32, C33, C34, C35, C36: 0.22u
J1, J2: 086212025340800
J3, J4: 086210025340800
R7, R8: 0

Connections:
232_CTS: J2.19; also elsewhere on the board
232_DCD: J3.17; also elsewhere on the board
232_DSR: J2.17; also elsewhere on the board
232_DTR: J3.20; also elsewhere on the board
232_EN: J2.22; also elsewhere on the board
232_RI: J2.20; also elsewhere on the board
232_RTS: J2.18; also elsewhere on the board
232_RXD: J3.18; also elsewhere on the board
232_TXD: J3.19; also elsewhere on the board
1284_BUSY: J3.22; also elsewhere on the board
1284_D1: J4.5; also elsewhere on the board
1284_D2: J4.4; also elsewhere on the board
1284_D3: J4.3; also elsewhere on the board
1284_D4: J4.2; also elsewhere on the board
1284_D5: J4.1; also elsewhere on the board
1284_D6: J3.25; also elsewhere on the board
1284_D7: J2.25; also elsewhere on the board
1284_D8: J3.24; also elsewhere on the board
1284_PERROR: J2.23; also elsewhere on the board
1284_SELECT: J3.23; also elsewhere on the board
1284_~ACK: J1.5; also elsewhere on the board
1284_~AUTOFD: J1.3; also elsewhere on the board
1284_~FAULT: J2.24; also elsewhere on the board
1284_~INIT: J1.4; also elsewhere on the board
1284_~SELECTIN: J1.2; also elsewhere on the board
1284_~STROBE: J4.6; also elsewhere on the board
+5V_232: C36.2, J4.15; also elsewhere on the board
+5V_FDD: C34.2, C35.2, J2.12, J2.13, J3.13; also elsewhere on the board
+5V_PS2: C31.2, J3.16; also elsewhere on the board
+5V_VGA: C32.1, C33.1, J2.21, J3.21; also elsewhere on the board
FDD_DETFDD: J2.11; also elsewhere on the board
FDD_DIRSEL: J3.7; also elsewhere on the board
FDD_DISKCHG: J3.12; also elsewhere on the board
FDD_DRATE0: J2.5; also elsewhere on the board
FDD_DRATE1: J3.3; also elsewhere on the board
FDD_DRVSEL: J3.5; also elsewhere on the board
FDD_HEADSEL: J3.11; also elsewhere on the board
FDD_INDEX: J3.4; also elsewhere on the board
FDD_MOTON: J3.6; also elsewhere on the board
FDD_PLUTO1: J2.3; also elsewhere on the board
FDD_PLUTO2: J2.4; also elsewhere on the board
FDD_PLUTO3: J2.6; also elsewhere on the board
FDD_PLUTO4: J2.9; also elsewhere on the board
FDD_RDATA: J2.10; also elsewhere on the board
FDD_STEP: J2.7; also elsewhere on the board
FDD_TRK00: J3.9; also elsewhere on the board
FDD_WDATA: J3.8; also elsewhere on the board
FDD_WGATE: J2.8; also elsewhere on the board
FDD_WPRT: J3.10; also elsewhere on the board
GND: C31.1, C32.2, C33.2, C34.1, C35.1, C36.1, J1.1, J1.6, J1.8, J1.10, J1.12, J1.25, J2.1, J2.16, J3.1, J4.25, R7.2, R8.2; also elsewhere on the board
GND_VIN_AC: J1.19, J1.20, J1.21, J1.22, J1.23; also elsewhere on the board
unnamed: J2.2, R8.1
unnamed: J3.2, R7.1
PS2_1_CLOCK: J3.15; also elsewhere on the board
PS2_1_DATA: J3.14; also elsewhere on the board
PS2_2_CLOCK: J2.15; also elsewhere on the board
PS2_2_DATA: J2.14; also elsewhere on the board
VGA_BLUE: J1.11; also elsewhere on the board
VGA_GREEN: J1.9; also elsewhere on the board
VGA_HSYNC: J4.11; also elsewhere on the board
VGA_RED: J1.7; also elsewhere on the board
VGA_VSYNC: J4.8; also elsewhere on the board
VIN_AC: J4.19, J4.20, J4.21, J4.22, J4.23; also elsewhere on the board
VIN_AC_DET: J4.13, J4.14; also elsewhere on the board
VIN_AC_DET_DIV: J1.15; also elsewhere on the board
VIN_AC_LP: J1.13; also elsewhere on the board

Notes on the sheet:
100
Dock connected via Flex Cable

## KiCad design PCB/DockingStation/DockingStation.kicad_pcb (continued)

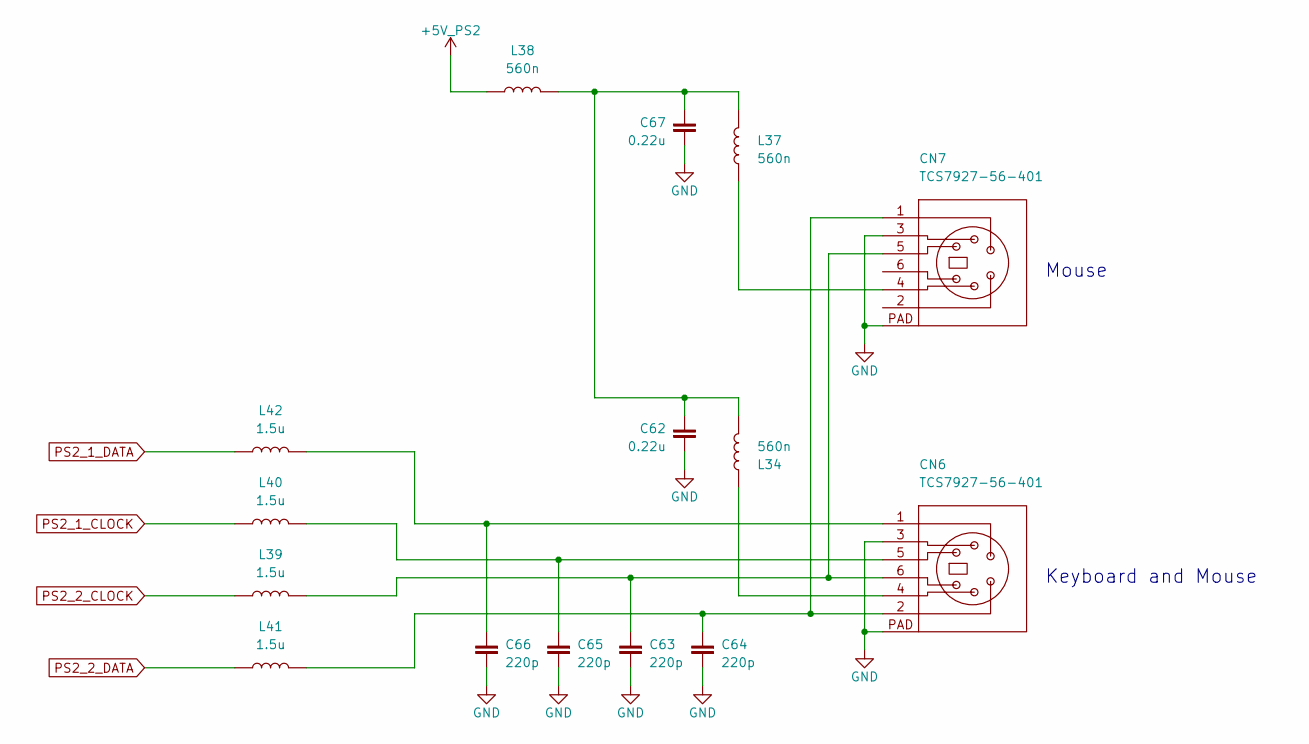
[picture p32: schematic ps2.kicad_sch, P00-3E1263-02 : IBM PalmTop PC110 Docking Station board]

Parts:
C62, C67: 0.22u
C63, C64, C65, C66: 220p
CN6, CN7: TCS7927-56-401
L34, L37, L38: 560n
L39, L40, L41, L42: 1.5u

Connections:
+5V_PS2: L38.2; also elsewhere on the board
GND: C62.2, C63.1, C64.1, C65.1, C66.1, C67.2, CN6.3, CN6.PAD (PDA), CN7.3, CN7.PAD (PDA); also elsewhere on the board
unnamed: C62.1, C67.1, L34.2, L37.2, L38.1
unnamed: C63.2, CN6.6, CN7.5, L39.1
unnamed: C64.2, CN6.2, CN7.1, L41.1
unnamed: C65.2, CN6.5, L40.1
unnamed: C66.2, CN6.1, L42.1
unnamed: CN6.4, L34.1
unnamed: CN7.4, L37.1
PS2_1_CLOCK: L40.2; also elsewhere on the board
PS2_1_DATA: L42.2; also elsewhere on the board
PS2_2_CLOCK: L39.2; also elsewhere on the board
PS2_2_DATA: L41.2; also elsewhere on the board

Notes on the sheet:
Mouse
Keyboard and Mouse

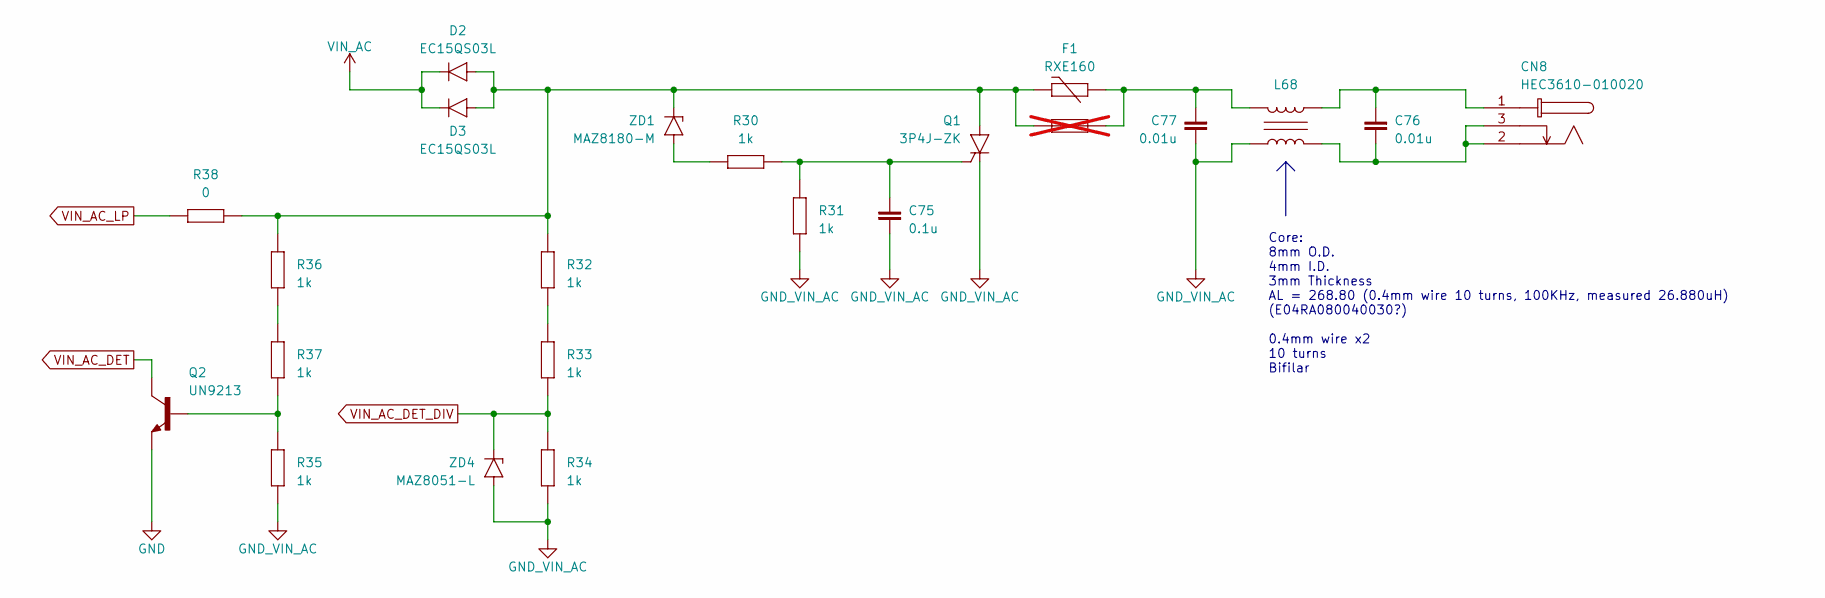
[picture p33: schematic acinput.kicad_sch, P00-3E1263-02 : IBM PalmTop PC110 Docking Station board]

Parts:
C75: 0.1u
C76, C77: 0.01u
CN8: HEC3610-010020
D2, D3: EC15QS03L
F1: RXE160
L68: (no value)
Q1: 3P4J-ZK
Q2: UN9213
R30, R31, R32, R33, R34, R35, R36, R37: 1k
R38: 0
SSFC1: not fitted
ZD1: MAZ8180-M
ZD4: MAZ8051-L

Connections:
GND: Q2.2 (E); also elsewhere on the board
GND_VIN_AC: C75.2, C77.2, L68.2, Q1.1 (C), R31.1, R34.1, R35.1, ZD4.2 (A); also elsewhere on the board
unnamed: C76.1, CN8.2, CN8.3, L68.1
unnamed: C76.2, CN8.1, L68.3
unnamed: C77.1, F1.1, L68.4, SSFC1.1
unnamed: D2.2 (A), D3.2 (A), F1.2, Q1.2 (A), R32.2, R36.2, R38.2, SSFC1.2, ZD1.1 (C)
unnamed: C75.1, Q1.3 (G), R30.1, R31.2
unnamed: Q2.1 (B), R35.2, R37.1
unnamed: R32.1, R33.2
unnamed: R36.1, R37.2
unnamed: R30.2, ZD1.2 (A)
VIN_AC: D2.1 (C), D3.1 (C); also elsewhere on the board
VIN_AC_DET: Q2.3 (C); also elsewhere on the board
VIN_AC_DET_DIV: R33.1, R34.2, ZD4.1 (C); also elsewhere on the board
VIN_AC_LP: R38.1; also elsewhere on the board

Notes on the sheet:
Core: 8mm O.D. 4mm I.D. 3mm Thickness AL = 268.80 (0.4mm wire 10 turns, 100KHz, measured 26.880uH) (E04RA080040030?) 0.4mm wire x2 10 turns Bifilar

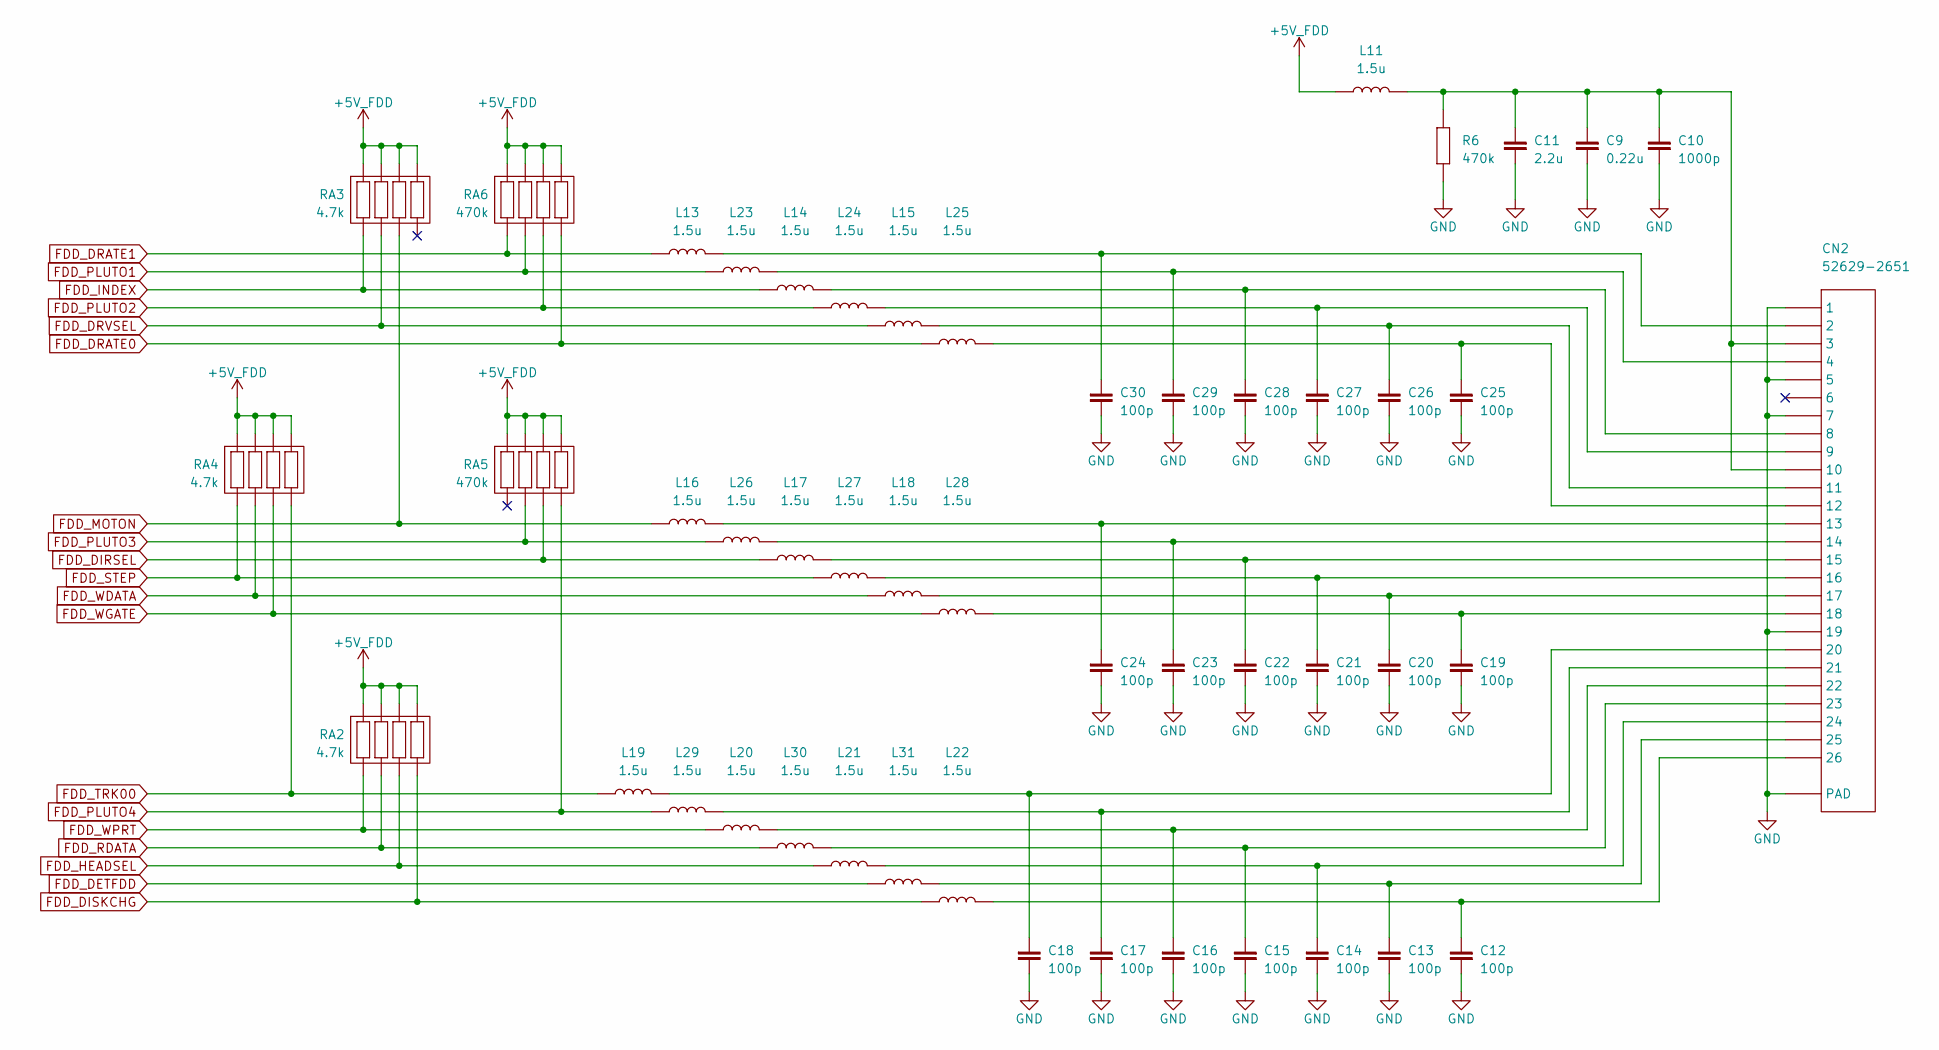
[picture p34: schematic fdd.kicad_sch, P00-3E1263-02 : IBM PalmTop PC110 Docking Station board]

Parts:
C9: 0.22u
C10: 1000p
C11: 2.2u
C12, C13, C14, C15, C16, C17, C18, C19, C20, C21, C22, C23, C24, C25, C26, C27, C28, C29, C30: 100p
CN2: 52629-2651
L11, L13, L14, L15, L16, L17, L18, L19, L20, L21, L22, L23, L24, L25, L26, L27, L28, L29, L30, L31: 1.5u
R6: 470k
RA2, RA3, RA4: 4.7k
RA5, RA6: 470k

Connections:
+5V_FDD: L11.1, RA2.1, RA2.2, RA2.3, RA2.4, RA3.1, RA3.2, RA3.3, RA3.4, RA4.1, RA4.2, RA4.3, RA4.4, RA5.1, RA5.2, RA5.3, RA5.4, RA6.1, RA6.2, RA6.3, RA6.4; also elsewhere on the board
FDD_DETFDD: L31.2; also elsewhere on the board
FDD_DIRSEL: L17.1, RA5.6; also elsewhere on the board
FDD_DISKCHG: L22.1, RA2.5; also elsewhere on the board
FDD_DRATE0: L25.1, RA6.5; also elsewhere on the board
FDD_DRATE1: L13.1, RA6.8; also elsewhere on the board
FDD_DRVSEL: L15.1, RA3.7; also elsewhere on the board
FDD_HEADSEL: L21.1, RA2.6; also elsewhere on the board
FDD_INDEX: L14.1, RA3.8; also elsewhere on the board
FDD_MOTON: L16.1, RA3.6; also elsewhere on the board
FDD_PLUTO1: L23.1, RA6.7; also elsewhere on the board
FDD_PLUTO2: L24.1, RA6.6; also elsewhere on the board
FDD_PLUTO3: L26.1, RA5.7; also elsewhere on the board
FDD_PLUTO4: L29.1, RA5.5; also elsewhere on the board
FDD_RDATA: L30.1, RA2.7; also elsewhere on the board
FDD_STEP: L27.1, RA4.8; also elsewhere on the board
FDD_TRK00: L19.1, RA4.5; also elsewhere on the board
FDD_WDATA: L18.1, RA4.7; also elsewhere on the board
FDD_WGATE: L28.1, RA4.6; also elsewhere on the board
FDD_WPRT: L20.1, RA2.8; also elsewhere on the board
GND: C9.1, C10.1, C11.1, C12.1, C13.2, C14.2, C15.1, C16.2, C17.1, C18.2, C19.1, C20.2, C21.1, C22.2, C23.1, C24.2, C25.1, C26.2, C27.1, C28.2, C29.1, C30.2, CN2.1, CN2.3 (5), CN2.4 (7), CN2.10 (19), CN2.PAD, R6.1; also elsewhere on the board
unnamed: C12.2, CN2.26, L22.2
unnamed: C30.1, CN2.14 (2), L13.2
unnamed: C29.2, CN2.15 (4), L23.2
unnamed: C28.1, CN2.17 (8), L14.2
unnamed: C27.2, CN2.5 (9), L24.2
unnamed: C9.2, C10.2, C11.2, CN2.2 (3), CN2.18 (10), L11.2, R6.2
unnamed: C26.1, CN2.6 (11), L15.2
unnamed: C25.2, CN2.19 (12), L25.2
unnamed: C24.1, CN2.7 (13), L16.2
unnamed: C23.2, CN2.20 (14), L26.2
unnamed: C22.1, CN2.8 (15), L17.2
unnamed: C21.2, CN2.21 (16), L27.2
unnamed: C20.1, CN2.9 (17), L18.2
unnamed: C19.2, CN2.22 (18), L28.2
unnamed: C18.1, CN2.23 (20), L19.2
unnamed: C17.2, CN2.11 (21), L29.2
unnamed: C16.1, CN2.24 (22), L20.2
unnamed: C15.2, CN2.12 (23), L30.2
unnamed: C14.1, CN2.25 (24), L21.2
unnamed: C13.1, CN2.13 (25), L31.1

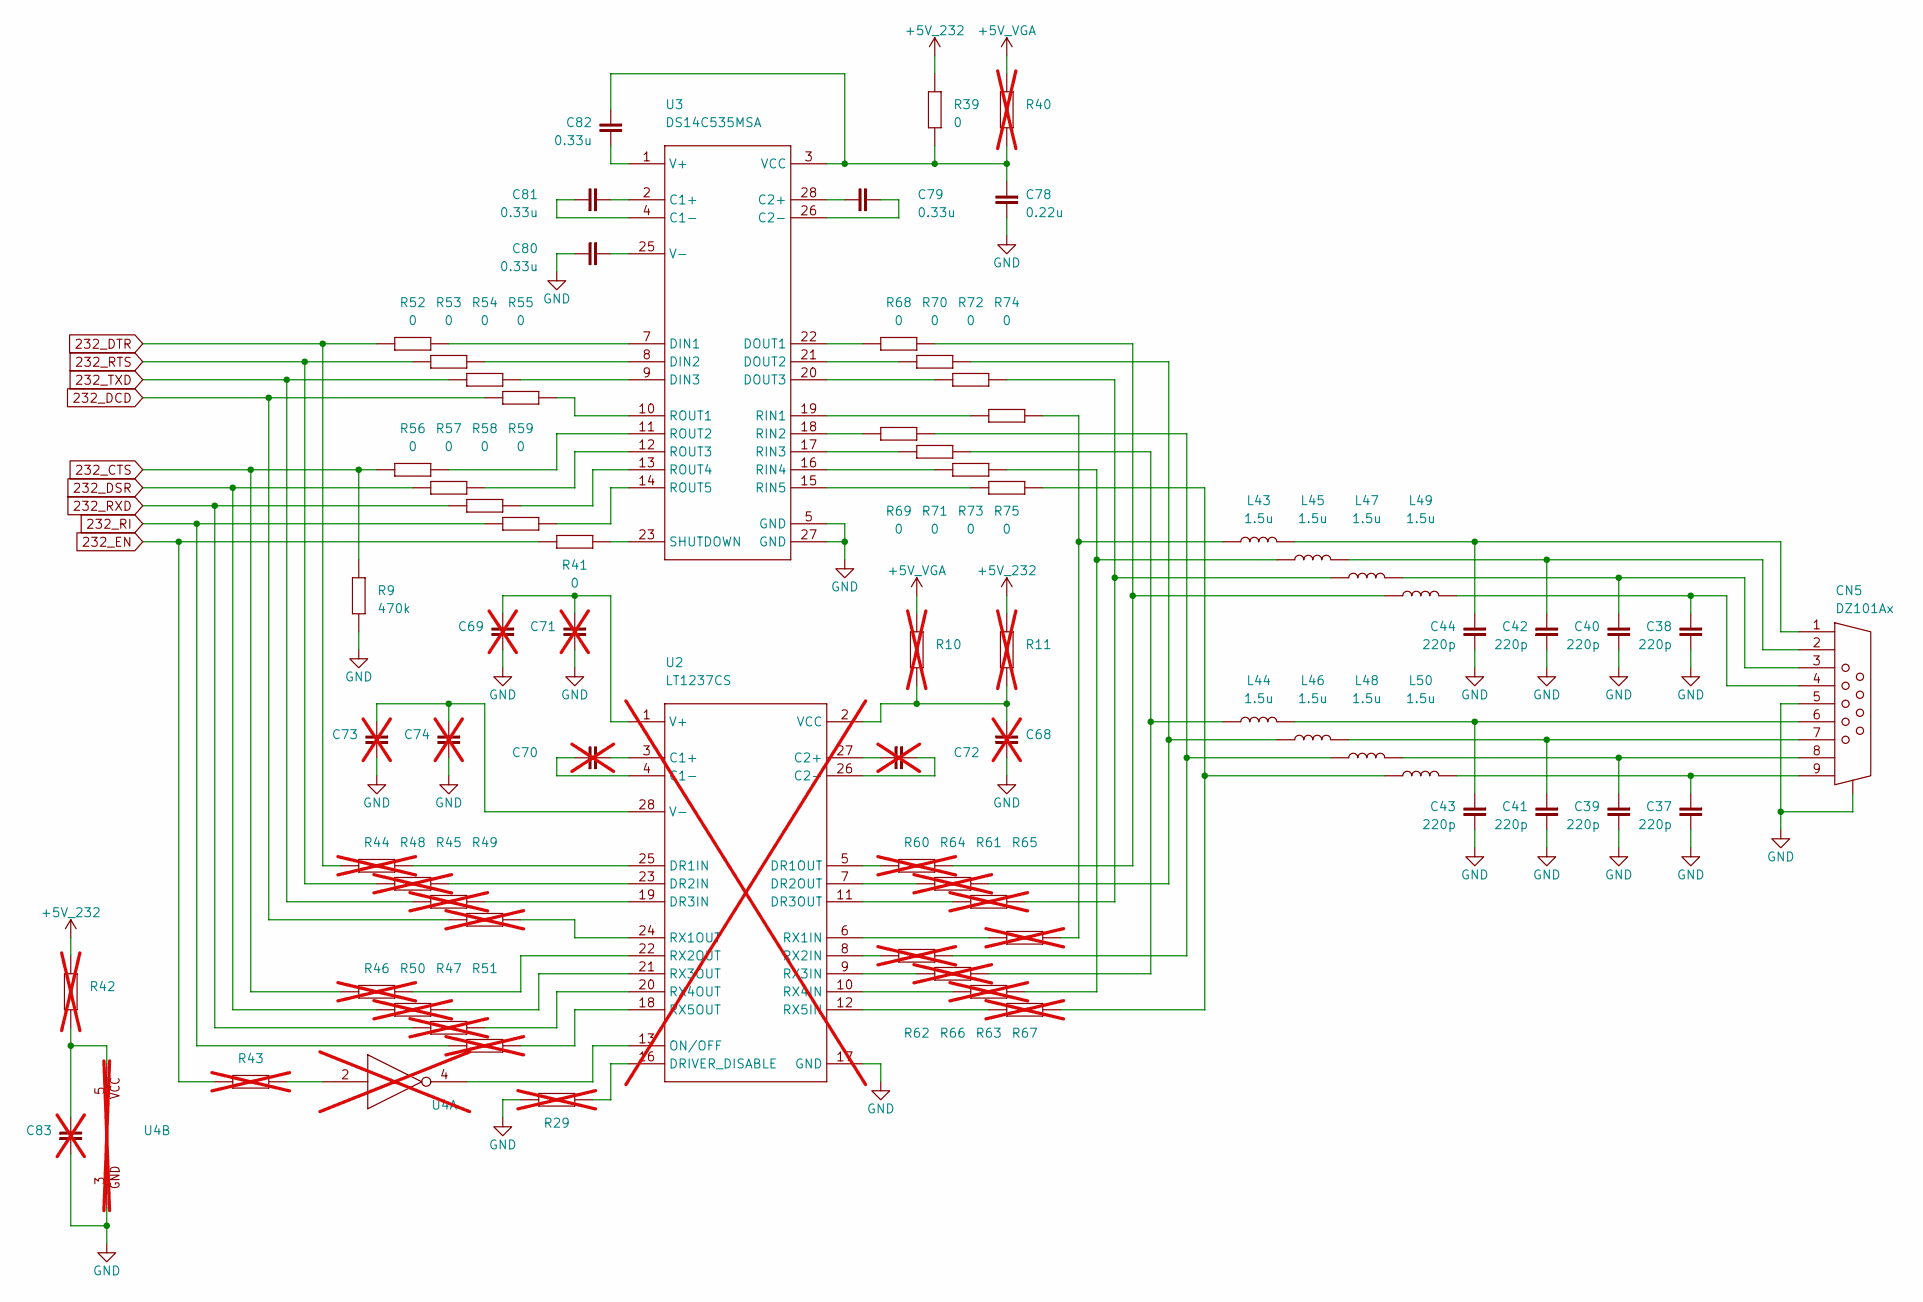
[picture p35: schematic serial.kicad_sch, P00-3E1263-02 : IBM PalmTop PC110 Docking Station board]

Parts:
C37, C38, C39, C40, C41, C42, C43, C44: 220p
C68, C69, C70, C71, C72, C73, C74, C83: not fitted
C78: 0.22u
C79, C80, C81, C82: 0.33u
CN5: DZ101Ax
L43, L44, L45, L46, L47, L48, L49, L50: 1.5u
R9: 470k
R10, R11, R29, R40, R42, R43, R44, R45, R46, R47, R48, R49, R50, R51, R60, R61, R62, R63, R64, R65, R66, R67: not fitted
R39, R41, R52, R53, R54, R55, R56, R57, R58, R59, R68, R69, R70, R71, R72, R73, R74, R75: 0
U2: LT1237CS; not fitted
U3: DS14C535MSA
U4: not fitted

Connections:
232_CTS: R9.1, R46.2, R56.1; also elsewhere on the board
232_DCD: R49.2, R55.1; also elsewhere on the board
232_DSR: R50.2, R57.1; also elsewhere on the board
232_DTR: R44.2, R52.1; also elsewhere on the board
232_EN: R41.1, R43.2; also elsewhere on the board
232_RI: R51.1, R59.2; also elsewhere on the board
232_RTS: R48.2, R53.1; also elsewhere on the board
232_RXD: R47.2, R58.1; also elsewhere on the board
232_TXD: R45.2, R54.1; also elsewhere on the board
+5V_232: R11.1, R39.1, R42.1; also elsewhere on the board
+5V_VGA: R10.2, R40.2; also elsewhere on the board
GND: C37.2, C38.2, C39.2, C40.2, C41.2, C42.1, C43.2, C44.2, C68.2, C69.2, C71.2, C73.2, C74.2, C78.1, C80.2, C83.1, CN5.0, CN5.5, R9.2, R29.1, U2.17 (GND), U3.5 (GND), U3.27 (GND), U4.3 (GND); also elsewhere on the board
unnamed: C37.1, CN5.9, L50.2
unnamed: C38.1, CN5.4, L49.2
unnamed: C39.1, CN5.8, L48.2
unnamed: C40.1, CN5.3, L47.2
unnamed: C41.1, CN5.7, L46.2
unnamed: C42.2, CN5.2, L45.2
unnamed: C43.1, CN5.6, L44.2
unnamed: C44.1, CN5.1, L43.2
unnamed: L43.1, R65.1, R74.2
unnamed: L44.1, R66.1, R71.2
unnamed: L45.1, R63.1, R73.2
unnamed: L46.1, R64.1, R70.2
unnamed: L47.1, R61.1, R72.2
unnamed: L48.1, R62.1, R69.2
unnamed: L49.1, R60.1, R68.2
unnamed: L50.1, R67.1, R75.2
unnamed: C70.2, U2.3 (C1+)
unnamed: C70.1, U2.4 (C1-)
unnamed: C72.2, U2.27 (C2+)
unnamed: C72.1, U2.26 (C2-)
unnamed: R44.1, U2.25 (DR1IN)
unnamed: R60.2, U2.5 (DR1OUT)
unnamed: R48.1, U2.23 (DR2IN)
unnamed: R64.2, U2.7 (DR2OUT)
unnamed: R45.1, U2.19 (DR3IN)
unnamed: R61.2, U2.11 (DR3OUT)
unnamed: R29.2, U2.16 (DRIVER_DISABLE)
unnamed: U2.13 (ON/OFF), U4.4 (O)
unnamed: R65.2, U2.6 (RX1IN)
unnamed: R49.1, U2.24 (RX1OUT)
unnamed: R62.2, U2.8 (RX2IN)
unnamed: R46.1, U2.22 (RX2OUT)
unnamed: R66.2, U2.9 (RX3IN)
unnamed: R50.1, U2.21 (RX3OUT)
unnamed: R63.2, U2.10 (RX4IN)
unnamed: R47.1, U2.20 (RX4OUT)
unnamed: R67.2, U2.12 (RX5IN)
unnamed: R51.2, U2.18 (RX5OUT)
unnamed: C69.1, C71.1, U2.1 (V+)
unnamed: C73.1, C74.1, U2.28 (V-)
unnamed: C68.1, R10.1, R11.2, U2.2 (VCC)
unnamed: C81.2, U3.2 (C1+)
unnamed: C81.1, U3.4 (C1-)
unnamed: C79.1, U3.28 (C2+)
unnamed: C79.2, U3.26 (C2-)
unnamed: R52.2, U3.7 (DIN1)
unnamed: R53.2, U3.8 (DIN2)
unnamed: R54.2, U3.9 (DIN3)
unnamed: R68.1, U3.22 (DOUT1)
unnamed: R70.1, U3.21 (DOUT2)
unnamed: R72.1, U3.20 (DOUT3)
unnamed: R74.1, U3.19 (RIN1)
unnamed: R69.1, U3.18 (RIN2)
unnamed: R71.1, U3.17 (RIN3)
unnamed: R73.1, U3.16 (RIN4)
unnamed: R75.1, U3.15 (RIN5)
unnamed: R55.2, U3.10 (ROUT1)
unnamed: R56.2, U3.11 (ROUT2)
unnamed: R57.2, U3.12 (ROUT3)
unnamed: R58.2, U3.13 (ROUT4)
unnamed: R59.1, U3.14 (ROUT5)
unnamed: R41.2, U3.23 (SHUTDOWN)
unnamed: C82.2, U3.1 (V+)
unnamed: C80.1, U3.25 (V-)
unnamed: C78.2, C82.1, R39.2, R40.1, U3.3 (VCC)
unnamed: R43.1, U4.2 (I)
unnamed: C83.2, R42.2, U4.5 (VCC)

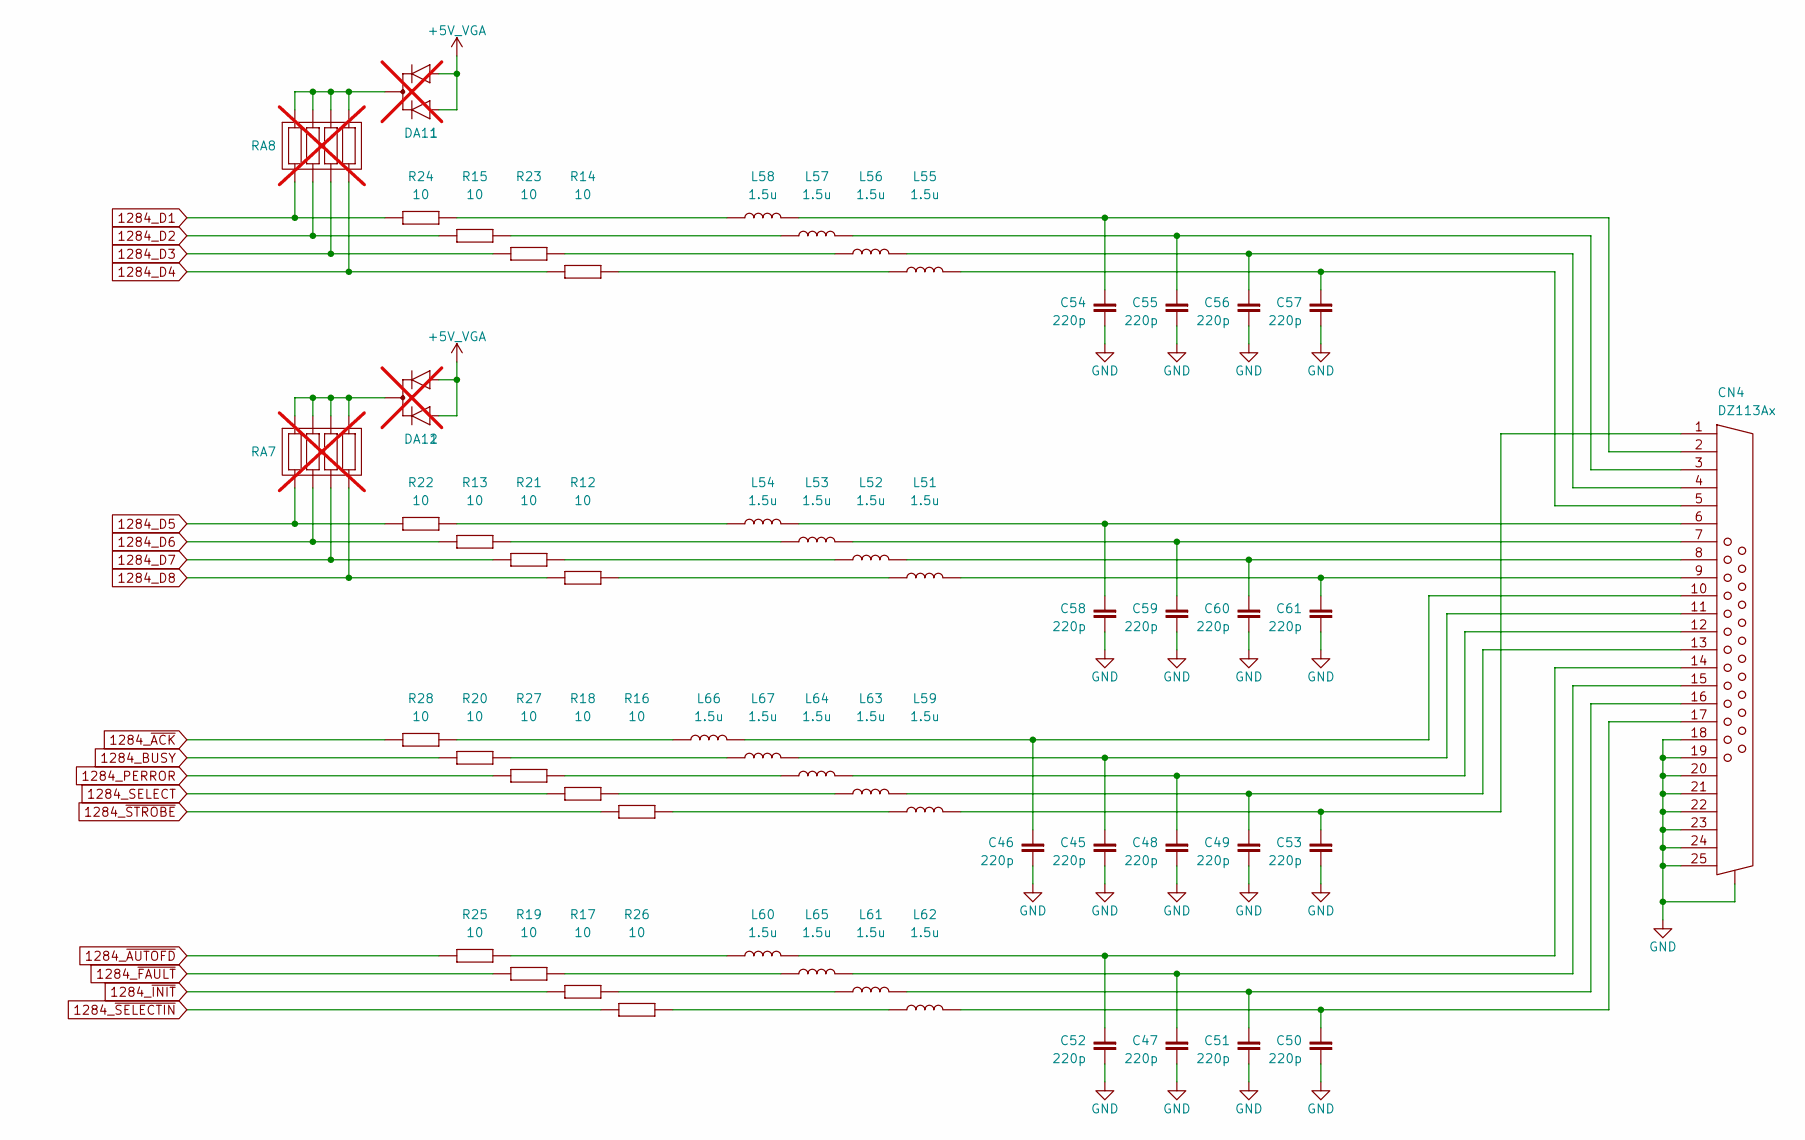
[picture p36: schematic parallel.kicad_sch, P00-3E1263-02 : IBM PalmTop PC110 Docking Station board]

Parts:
C45, C46, C47, C48, C49, C50, C51, C52, C53, C54, C55, C56, C57, C58, C59, C60, C61: 220p
CN4: DZ113Ax
DA11, DA12: 1; not fitted
L51, L52, L53, L54, L55, L56, L57, L58, L59, L60, L61, L62, L63, L64, L65, L66, L67: 1.5u
R12, R13, R14, R15, R16, R17, R18, R19, R20, R21, R22, R23, R24, R25, R26, R27, R28: 10
RA7, RA8: not fitted

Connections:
1284_BUSY: R20.1; also elsewhere on the board
1284_D1: R24.1, RA8.8; also elsewhere on the board
1284_D2: R15.1, RA8.7; also elsewhere on the board
1284_D3: R23.1, RA8.6; also elsewhere on the board
1284_D4: R14.1, RA8.5; also elsewhere on the board
1284_D5: R22.1, RA7.8; also elsewhere on the board
1284_D6: R13.1, RA7.7; also elsewhere on the board
1284_D7: R21.2, RA7.6; also elsewhere on the board
1284_D8: R12.1, RA7.5; also elsewhere on the board
1284_PERROR: R27.1; also elsewhere on the board
1284_SELECT: R18.1; also elsewhere on the board
1284_~ACK: R28.1; also elsewhere on the board
1284_~AUTOFD: R25.1; also elsewhere on the board
1284_~FAULT: R19.1; also elsewhere on the board
1284_~INIT: R17.1; also elsewhere on the board
1284_~SELECTIN: R26.1; also elsewhere on the board
1284_~STROBE: R16.1; also elsewhere on the board
+5V_VGA: DA11.1 (A1), DA11.2 (A2), DA12.1 (A1), DA12.2 (A2); also elsewhere on the board
GND: C45.1, C46.1, C47.1, C48.1, C49.1, C50.1, C51.1, C52.1, C53.1, C54.1, C55.1, C56.1, C57.1, C58.1, C59.1, C60.1, C61.1, CN4.0, CN4.18, CN4.19, CN4.20, CN4.21, CN4.22, CN4.23, CN4.24, CN4.25; also elsewhere on the board
unnamed: C45.2, CN4.11, L67.2
unnamed: C46.2, CN4.10, L66.2
unnamed: C47.2, CN4.15, L65.2
unnamed: C48.2, CN4.12, L64.2
unnamed: C49.2, CN4.13, L63.2
unnamed: C50.2, CN4.17, L62.2
unnamed: C51.2, CN4.16, L61.2
unnamed: C52.2, CN4.14, L60.2
unnamed: C53.2, CN4.1, L59.2
unnamed: C54.2, CN4.2, L58.2
unnamed: C55.2, CN4.3, L57.2
unnamed: C56.2, CN4.4, L56.2
unnamed: C57.2, CN4.5, L55.2
unnamed: C58.2, CN4.6, L54.2
unnamed: C59.2, CN4.7, L53.2
unnamed: C60.2, CN4.8, L52.2
unnamed: C61.2, CN4.9, L51.2
unnamed: DA11.3 (C), RA8.1, RA8.2, RA8.3, RA8.4
unnamed: DA12.3 (C), RA7.1, RA7.2, RA7.3, RA7.4
unnamed: L51.1, R12.2
unnamed: L52.1, R21.1
unnamed: L53.1, R13.2
unnamed: L54.1, R22.2
unnamed: L55.1, R14.2
unnamed: L56.1, R23.2
unnamed: L57.1, R15.2
unnamed: L58.1, R24.2
unnamed: L59.1, R16.2
unnamed: L60.1, R25.2
unnamed: L61.1, R17.2
unnamed: L62.1, R26.2
unnamed: L63.1, R18.2
unnamed: L64.1, R27.2
unnamed: L65.1, R19.2
unnamed: L66.1, R28.2
unnamed: L67.1, R20.2

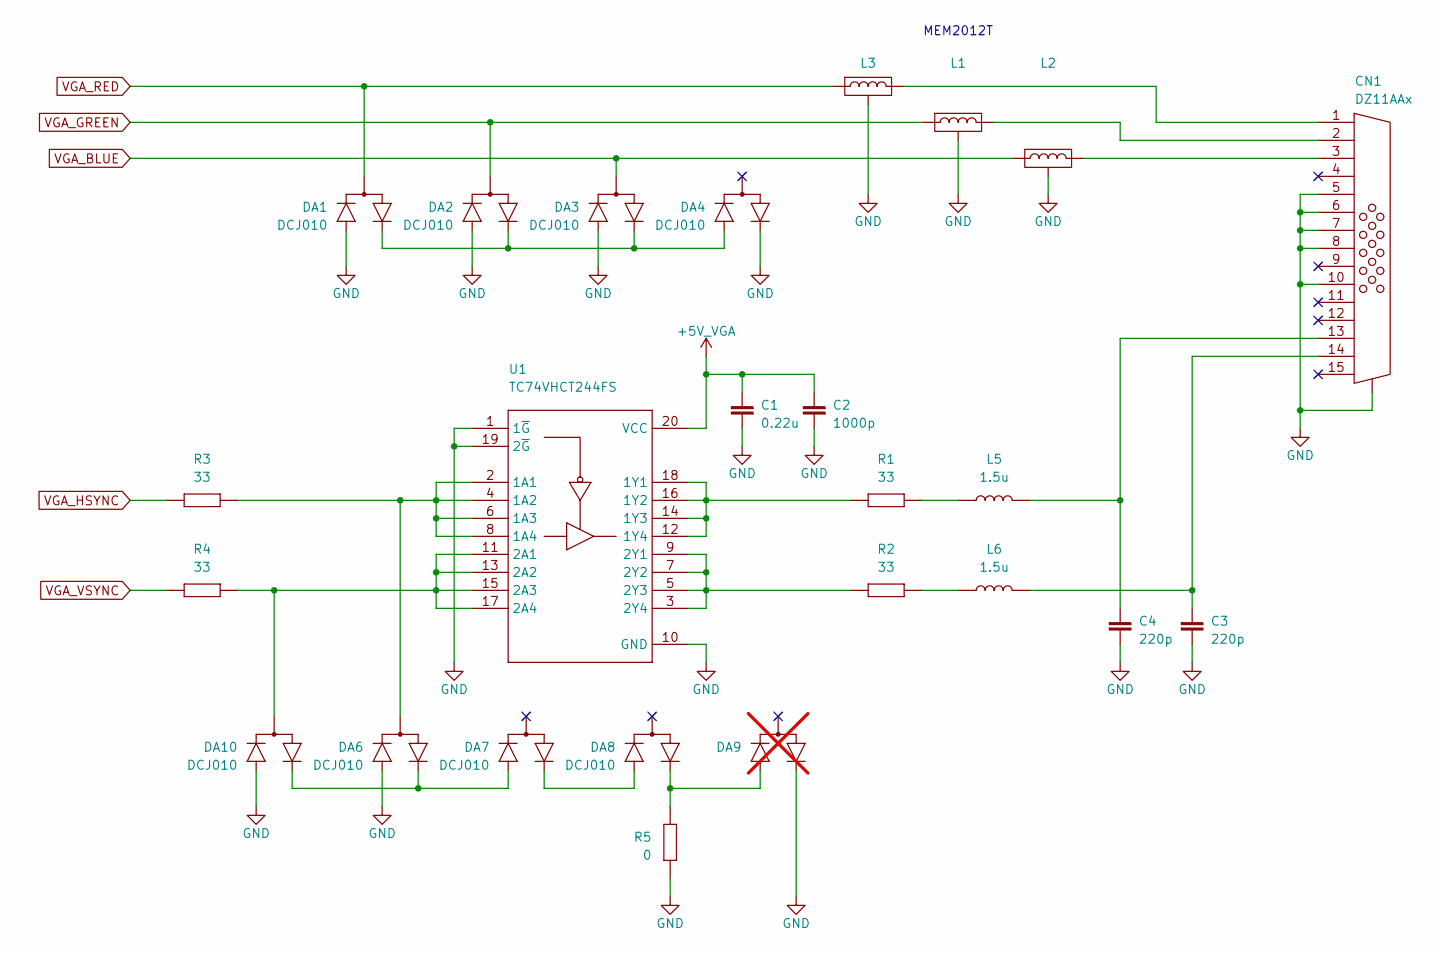
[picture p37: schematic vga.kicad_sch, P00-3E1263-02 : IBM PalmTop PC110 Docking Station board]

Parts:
C1: 0.22u
C2: 1000p
C3, C4: 220p
CN1: DZ11AAx
DA1, DA2, DA3, DA4, DA6, DA7, DA8, DA10: DCJ010
DA9: not fitted
L1, L2, L3: (no value)
L5, L6: 1.5u
R1, R2, R3, R4: 33
R5: 0
U1: TC74VHCT244FS

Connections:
+5V_VGA: C1.2, C2.2, U1.20 (VCC); also elsewhere on the board
GND: C1.1, C2.1, C3.2, C4.2, CN1.0, CN1.5, CN1.6, CN1.7, CN1.8, CN1.10, DA1.1 (A), DA2.1 (A), DA3.1 (A), DA4.2 (C), DA6.1 (A), DA9.2 (C), DA10.1 (A), L1.3, L2.3, L3.3, R5.1, U1.1 (1~G), U1.10 (GND), U1.19 (2~G); also elsewhere on the board
unnamed: C3.1, CN1.14, L6.2
unnamed: C4.1, CN1.13, L5.2
unnamed: CN1.1, L3.2
unnamed: CN1.2, L1.2
unnamed: CN1.3, L2.2
unnamed: DA1.2 (C), DA2.2 (C), DA3.2 (C), DA4.1 (A)
unnamed: DA6.3 (CA), R3.2, U1.2 (1A1), U1.4 (1A2), U1.6 (1A3), U1.8 (1A4)
unnamed: DA7.2 (C), DA8.1 (A)
unnamed: DA8.2 (C), DA9.1 (A), R5.2
unnamed: DA6.2 (C), DA7.1 (A), DA10.2 (C)
unnamed: DA10.3 (CA), R4.2, U1.11 (2A1), U1.13 (2A2), U1.15 (2A3), U1.17 (2A4)
unnamed: L5.1, R1.2
unnamed: L6.1, R2.2
unnamed: R1.1, U1.12 (1Y4), U1.14 (1Y3), U1.16 (1Y2), U1.18 (1Y1)
unnamed: R2.1, U1.3 (2Y4), U1.5 (2Y3), U1.7 (2Y2), U1.9 (2Y1)
VGA_BLUE: DA3.3 (CA), L2.1; also elsewhere on the board
VGA_GREEN: DA2.3 (CA), L1.1; also elsewhere on the board
VGA_HSYNC: R3.1; also elsewhere on the board
VGA_RED: DA1.3 (CA), L3.1; also elsewhere on the board
VGA_VSYNC: R4.1; also elsewhere on the board

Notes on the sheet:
MEM2012T



Board: 4 copper layers, 147.2 x 63.2 mm, 254 parts (4 on the bottom side), 220 nets.

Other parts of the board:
G1: LOGO; logo

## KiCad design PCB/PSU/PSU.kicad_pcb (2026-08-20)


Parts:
C65: 0.1u
CN3: 179029-1
CN4: DF13- 4P-1.25V
D10: MA741WA
D11: MAZ8039-H
F6: 630mA
R107: 1k
R108: 47k
R109, R110: 4.7k
R111: not fitted
RT1, RT2: 103HT-xx
SW1: (no value)

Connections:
+3V3: CN3.8, CN3.28; also elsewhere on the board
+5V_STBY: CN3.16, SW1.1; also elsewhere on the board
+5V_SW: CN3.10, CN3.11, CN3.31, RT1.2, RT2.1; also elsewhere on the board
+12V: CN3.12; also elsewhere on the board
+12V_ENABLE: CN3.34; also elsewhere on the board
BAT_MONT_VOLT: CN3.21; also elsewhere on the board
BAT_MON_CHGCURR: CN3.2; also elsewhere on the board
BAT_MON_DISCHGCURR: CN3.1; also elsewhere on the board
CHG_CONT_1: CN3.19; also elsewhere on the board
CHG_CONT_2: CN3.39; also elsewhere on the board
CHG_MONPWR_EN: CN3.18; also elsewhere on the board
CHG_SUBPWR: CN3.6; also elsewhere on the board
EXT_DEV_DETSW: CN3.33, R107.2; also elsewhere on the board
GND: C65.1, CN3.5, CN3.7, CN3.9, CN3.24, CN3.25, CN3.29, CN3.32, CN3.37, CN4.3, R108.2, R109.1, R110.1; also elsewhere on the board
LCD_BKLIT_ADJ: CN3.20, CN4.2
LCD_BKLIT_INVEN: CN3.40, CN4.1
MONT_VOLT_ENABLE: CN3.38; also elsewhere on the board
unnamed: C65.2, CN4.4, F6.1
unnamed: D10.2 (A), D11.1 (C), R111.1
unnamed: D10.1 (C1), R110.2, RT2.2
unnamed: D10.3 (C2), R109.2, RT1.1
unnamed: R107.1, R108.1, SW1.2
TEMPSENS: CN3.22, D11.2 (A), R111.2
VAA_LCD: CN3.13; also elsewhere on the board
VAA_LCD_ADJ: CN3.15; also elsewhere on the board
VAA_LCD_ENABLE: CN3.35; also elsewhere on the board
VIN_AC_DETECT: CN3.26; also elsewhere on the board
VIN_AC_MON_VOLT: CN3.27; also elsewhere on the board
VREF: CN3.30; also elsewhere on the board
VSW: CN3.14, F6.2; also elsewhere on the board
VSW_ENABLE_1: CN3.17; also elsewhere on the board
VSW_ENABLE_2: CN3.36; also elsewhere on the board
VSYS: CN3.3, CN3.4, CN3.23; also elsewhere on the board

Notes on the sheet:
SOC SSFC? Quick-Acting

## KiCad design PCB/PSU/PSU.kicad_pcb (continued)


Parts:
C27, C33, C38, C42, C43, C45, C49, C54, C57, C58, C62, C64: 0.1u
C28, C47, C52: 1000p
C29, C31, C32, C34, C35, C36, C44, C46: 1u
C30, C63: 0.022u
C37, C39, C40, C41, C50, C51, C55: 0.01u
C48: 2200p
C53, C60: 4700p
C56: 3300p
C59: 100p
C61: not fitted
D9: MA741WA
D50: SB05-03Q
EC1: 56u
EC2: 33u
EC30, EC50, EC51: 47u
EC70: 15u
EC80: 18u
F4: CCP2E15
F5: CCP2E10
L30: 22u
L50: 10u
L70: 68u
L80: 470u
Q8: 2SJ421
Q22: 2SJ204
Q23: 2SK1590
Q24: UN9213
Q25, Q26: UN9110-S
Q30: SB05-03Q
Q50, Q51: 2SK2556
Q123: FP303
Q124: FP301
R65, R106: 470k
R66: 10M
R67: 1k
R68, R83, R84, R89, R90, R91, R96, R101, R102, R103, R104: 10k
R69, R95: 100k
R70, R71, R82: 100
R72: 220m
R73, R79, R80, R81: 100m
R74, R75: 300
R76, R78: 7.5k
R77: not fitted
R85: 2.2k
R86: 220
R87: 200k
R88: 11k
R92: 12k
R93, R105: 20k
R94: 47k
R97: 470
R98: 120
R99: 130k
R100: 15k
U3: MAX786CAI
U4: BA9742
U30: K2337
U103: TC7W14FK

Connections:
+3V3: C40.1, EC30.2 (1), R72.1, R73.1, R75.1; also elsewhere on the board
+5V_MAX786_VL: C34.2, D9.2 (A), R71.1, U3.22 (VL)
+5V_SW: C64.2, EC50.2 (1), EC51.2 (1), R79.1, R80.1, R81.1, R82.1, R84.2, R96.2, U3.21 (FB5), U103.8 (VCC); also elsewhere on the board
+12V: C58.1, C59.2, EC70.2 (1), Q124.4 (C), R99.2; also elsewhere on the board
+12V_ENABLE: R106.2; also elsewhere on the board
BA9742_CT: C47.2, U4.1 (CT); also elsewhere on the board
GND: C28.2, C29.2, C31.2, C32.2, C33.1, C34.1, C35.2, C36.1, C37.1, C41.2, C43.2, C44.1, C45.2, C46.1, C47.1, C49.2, C50.1, C55.1, C57.2, C58.2, C63.2, C64.1, D50.1 (A), D50.3 (A), EC1.1 (2), EC2.1 (2), EC30.1 (2), EC50.1 (2), EC51.1 (2), EC70.1 (2), EC80.1 (2), Q23.2 (S), Q24.2 (E), Q30.1 (A), Q30.3 (A), Q51.1 (S), Q51.2 (S), Q51.3 (S), Q123.2 (E), Q124.2 (E), R76.1, R77.1, R78.2, R83.2, R88.2, R91.2, R93.1, R100.1, R103.2, R105.2, U3.4 (D1), U3.5 (D2), U3.9 (GND), U3.11 (SYNC), U3.20 (PGND), U4.8 (GND), U30.1 (S), U103.4 (GND); also elsewhere on the board
unnamed: C39.1, L30.2, R72.2, R73.2, R74.1
unnamed: C48.1, R86.2
unnamed: C49.1, F5.1, L80.2
unnamed: C52.2, R89.2
unnamed: C56.2, R98.2
unnamed: C57.1, F4.1, L70.1
unnamed: C60.1, R101.1
unnamed: C42.2, D9.1 (C1), U3.18 (BST5)
unnamed: C38.2, D9.3 (C2), U3.25 (BST3)
unnamed: C42.1, D50.2 (C), L50.2, Q50.1 (S), Q50.2 (S), Q50.3 (S), Q51.5 (D), Q51.6 (D), Q51.7 (D), Q51.8 (D), U3.17 (LX5)
unnamed: C27.2, Q8.4 (G), Q22.3 (D), R65.2, R68.1
unnamed: Q22.1 (G), Q23.3 (D), R66.1
unnamed: C28.1, Q23.1 (G), R67.1
unnamed: C29.1, C30.2, Q24.1 (B), R69.1
unnamed: C30.1, Q24.3 (C), R68.2
unnamed: C55.2, Q25.1 (B), R95.2
unnamed: C51.1, Q25.3 (C), R87.1, R88.1, R94.1, U4.3 (NON1)
unnamed: C63.1, Q26.1 (B), R106.1
unnamed: C59.1, Q26.3 (C), R99.1, R100.2, U4.14 (NON2)
unnamed: C38.1, L30.1, Q30.2 (C), U3.26 (LX3), U30.3 (S), U30.7 (D), U30.8 (D)
unnamed: Q50.4 (G), U3.16 (DH5)
unnamed: Q51.4 (G), U3.19 (DL5)
unnamed: Q123.1 (B), R85.1, R86.1
unnamed: L80.1, Q123.3 (A), Q123.5 (C)
unnamed: Q124.1 (B), R97.1, R98.1
unnamed: L70.2, Q124.3 (A), Q124.5 (C)
unnamed: C39.2, R74.2, R76.2, R77.2, U3.1 (CS3)
unnamed: L50.1, R79.2, R80.2, R81.2, U3.15 (CS5)
unnamed: U3.27 (DH3), U30.4 (G)
unnamed: U3.24 (DL3), U30.2 (G)
unnamed: C40.2, R75.2, R78.1, U3.28 (FB3)
unnamed: C36.2, R71.2, U3.3 (ON3), U3.6 (VH), U3.12 (~SHDN), U3.13 (ON5)
unnamed: C35.1, U3.10 (REF)
unnamed: C37.2, U3.2 (SS3)
unnamed: C41.1, U3.14 (SS5)
unnamed: C33.2, R70.1, U3.23 (V+)
unnamed: C54.1, R92.2, R93.2, U4.6 (DT1)
unnamed: C62.2, R104.1, R105.1, U4.11 (DT2)
unnamed: C52.1, C53.1, U4.5 (FB1)
unnamed: C60.2, C61.1, U4.12 (FB2)
unnamed: C53.2, R89.1, R90.2, R91.1, U4.4 (INV1)
unnamed: C61.2, R101.2, R102.1, R103.1, U4.13 (INV2)
unnamed: R83.1, U4.2 (RT)
unnamed: C46.2, U4.15 (SCP)
unnamed: C43.1, R82.2, U4.9 (VCC)
unnamed: R96.1, U4.10 (OUT2), U103.1 (1A), U103.3 (2A)
unnamed: C56.1, R97.2, U103.5 (2Y), U103.7 (1Y)
unnamed: R84.1, U4.7 (OUT1), U103.6 (3A)
unnamed: C48.2, R85.2, U103.2 (3Y)
VAA_LCD: C50.2, C51.2, EC80.2 (1), Q123.4 (C), R87.2; also elsewhere on the board
VAA_LCD_ADJ: R94.2; also elsewhere on the board
VAA_LCD_ENABLE: R95.1; also elsewhere on the board
VREF_BA9742: C44.2, C45.1, C54.2, C62.1, Q25.2 (E), Q26.2 (E), R90.1, R92.1, R102.2, R104.2, U4.16 (VREF)
VSW: C31.1, C32.1, EC1.2 (1), EC2.2 (1), F4.2, F5.2, Q8.5 (D), Q8.6 (D), Q8.7 (D), Q8.8 (D), Q50.5 (D), Q50.6 (D), Q50.7 (D), Q50.8 (D), R70.2, U30.5 (D), U30.6 (D); also elsewhere on the board
VSW_ENABLE_1: R67.2; also elsewhere on the board
VSW_ENABLE_2: R69.2; also elsewhere on the board
VSYS: C27.1, Q8.1 (S), Q8.2 (S), Q8.3 (S), Q22.2 (S), R65.1, R66.2; also elsewhere on the board

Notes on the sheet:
3.3V Supply
LCD VAA Supply
2SK2556 or Si9410DY
Siliconix
DC-DC Control
5V Supply
1.5A
+12V Supply


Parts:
C9: 0.1u
C10: 1u
C11: 4.7u
Q6: UN9210-R
Q7: UN9110-S
R15: 100k
R16: 0
R17, R18: 470k
R19: 10k
U1: S-80745SN-D9-X
U2: S-81350HG
Z2, Z4: not fitted
Z3: MAZ8056-M

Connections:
+5V_STBY: C11.2, U2.1 (VOUT); also elsewhere on the board
GND: C9.2, C10.1, C11.1, Q6.2 (E), U1.3 (VSS), U2.2 (GND), Z2.2 (A), Z4.2 (A); also elsewhere on the board
unnamed: Q6.1 (B), R18.1
unnamed: Q6.3 (C), R19.1
unnamed: Q7.1 (B), R19.2, Z3.2 (A)
unnamed: C10.2, Q7.3 (C), U2.3 (VIN), Z4.1 (C)
unnamed: R16.2, R17.2
unnamed: R16.1, R18.2, U1.1 (OUT)
unnamed: C9.1, R15.1, R17.1, U1.2 (VDD), Z2.1 (C)
VSYS: Q7.2 (E), R15.2, Z3.1 (C); also elsewhere on the board


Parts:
C1, C4, C8: not fitted
C2: 0.01u
C3: 4700p
C5, C6, C7: 0.1u
CN1: HEC3150-012120
D1, D2: EC10QS03L
D3: DCG010
F1: 2.5A
Q1: 3P4J-ZK
Q3: UN9213
Q4: UN9110-S
Q5: UN9210-R
R1, R2: 0
R3, R4, R6, R7, R8: 1k
R5: 33
R9, R10: 470k
R11, R13: 300k
R12, R14: 100k
U100: NJU7064V
Z1: MAZ8180-M

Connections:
AC_IN_DETECT_DIV: Q3.1 (B), R7.2, R8.2; also elsewhere on the board
CHG_CONT_2_OR: D3.3 (A2); also elsewhere on the board
GND: C3.1, C4.2, C5.2, C7.1, Q1.1 (C), Q3.2 (E), Q5.2 (E), R2.2, R3.2, R8.1, R12.2, R13.1; also elsewhere on the board
MONT_VOLT_ENABLE: D3.1 (A1); also elsewhere on the board
MONT_V_EN_OR: D3.2 (C), R10.1
unnamed: C1.1, C2.2, F1.1, R1.1
unnamed: C1.2, C2.1, CN1.2, CN1.3, R2.1
unnamed: C6.1, R5.2
unnamed: C7.2, R5.1
unnamed: CN1.1, F1.2
unnamed: C5.1, Q1.3 (G), R3.1, R4.2
unnamed: Q4.1 (B), R9.1
unnamed: Q4.3 (C), R11.2
unnamed: Q5.1 (B), R10.2
unnamed: Q5.3 (C), R9.2
unnamed: R6.1, R7.1
unnamed: R11.1, R12.1, U100.5 (2IN+)
unnamed: C8.2, R13.2, R14.2, U100.6 (2IN-)
unnamed: R4.1, Z1.2 (A)
VIN_AC: C3.2, C4.1, D1.2 (A), D2.2 (A), Q1.2 (A), Q4.2 (E), R1.2, R6.2, Z1.1 (C); also elsewhere on the board
VIN_AC_DETECT: Q3.3 (C); also elsewhere on the board
VIN_AC_MON_VOLT: C8.1, R14.1, U100.7 (2OUT); also elsewhere on the board
VSYS: C6.2, D1.1 (C), D2.1 (C); also elsewhere on the board

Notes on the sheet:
SOC SSFC? Quick-Acting


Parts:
C12, C18: 0.01u
C13, C19, C22, C24, C25, C26: 0.1u
C14, C17, C20, C21: 1000p
C15: 4.7p
C16: 47p
C23: not fitted
CN5: (no value)
D4, D8: SB007W03Q
D5, D6: MA741WA
D7: DCG010
D105: EC11FS2
F2: 2.5A
L81: 10u
Q2: 2SJ421
Q9, Q14, Q17: UN9110-S
Q10, Q11, Q13, Q18, Q20: UN9213
Q12, Q15, Q16, Q19: UN9210-R
Q21: XN4609
R20, R22, R34, R35, R52, R55, R58: 100k
R21, R42, R46, R51, R54: 47k
R23, R36, R37: 470k
R24, R59: 1k
R25: 470
R26, R27: 100m
R28, R29, R38, R39, R47, R60: 10k
R30, R31, R40, R41, R48: 200k
R32, R33: 300k
R43, R49: 20k
R44: 2k
R45, R53, R56, R61, R62: 4.7k
R50: 10M
R57: not fitted
R63, R64: 1M
U5: LM4040CIM3-4.1
U100: NJU7064V
U101: TA75S393F
U102: TA75W01FU
Z5: MAZ8082-M

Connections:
+5V_CHGMON: C24.1, C25.1, Q9.3 (C), R24.1, U100.4 (VCC+), U102.8 (VCC+)
+5V_STBY: Q9.2 (E); also elsewhere on the board
+5V_SW: C26.2, D4.3 (A2), Q19.3 (C), R58.2, U101.5 (VCC+); also elsewhere on the board
AC_IN_DETECT_DIV: R21.1; also elsewhere on the board
BA9742_CT: R55.1; also elsewhere on the board
BAT_MONT_VOLT: C16.1, R35.1, R46.2, U100.1 (1OUT); also elsewhere on the board
BAT_MON_CHGCURR: C14.1, R31.1, R42.1, U100.14 (4OUT); also elsewhere on the board
BAT_MON_DISCHGCURR: C17.1, R41.1, U100.8 (3OUT); also elsewhere on the board
CHG_CONT_1: D7.1 (A1), Q16.1 (B); also elsewhere on the board
CHG_CONT_2: D7.3 (A2); also elsewhere on the board
CHG_CONT_2_OR: D7.2 (C), R52.2, R54.2; also elsewhere on the board
CHG_MONPWR_EN: R23.1; also elsewhere on the board
CHG_SUBPWR: D8.1 (A1), Z5.1 (C); also elsewhere on the board
EXT_DEV_DETSW: C12.1, R22.1; also elsewhere on the board
GND: C12.2, C13.1, C19.2, C22.1, C23.1, C24.2, C25.2, C26.1, D5.2 (A), D105.2 (A), Q10.2 (E), Q11.2 (E), Q12.2 (E), Q13.2 (E), Q15.2 (E), Q16.2 (E), Q18.2 (E), Q21.3 (Q1_C), R26.1, R27.1, R28.1, R30.2, R34.2, R39.1, R40.1, R45.2, R49.2, R56.2, R62.2, R64.1, U5.1 (A), U100.11 (VCC-), U101.2 (VCC-), U102.4 (VCC-); also elsewhere on the board
unnamed: CN5.1, F2.1
unnamed: CN5.2, R26.2, R27.2, R29.2, R32.1, R38.2
unnamed: D4.1 (A1), R24.2
unnamed: D4.2 (C), R25.2
unnamed: D5.1 (C1), R29.1, R30.1, U100.12 (4IN+)
unnamed: C17.2, D5.3 (C2), R38.1, R41.2, U100.9 (3IN-)
unnamed: D6.2 (A), R53.1, R56.1, U101.1 (1IN-)
unnamed: C20.2, D6.1 (C1), R50.2, U102.1 (1OUT)
unnamed: C18.2, D6.3 (C2), U102.7 (2OUT)
unnamed: D8.2 (C), Q21.6 (Q2_C), R60.2, R61.1
unnamed: D105.1 (C), L81.2, Q2.5 (D), Q2.6 (D), Q2.7 (D), Q2.8 (D)
unnamed: Q2.4 (G), Q21.1 (Q2_E), Q21.4 (Q1_E)
unnamed: Q9.1 (B), R20.1
unnamed: Q10.1 (B), Q11.3 (C), R21.2
unnamed: Q10.3 (C), Q12.3 (C), Q13.3 (C), R20.2
unnamed: Q11.1 (B), R22.2
unnamed: Q12.1 (B), R23.2
unnamed: Q13.1 (B), Z5.2 (A)
unnamed: Q14.1 (B), R36.2
unnamed: C15.2, Q14.3 (C), R33.2
unnamed: Q15.1 (B), R37.1
unnamed: Q15.3 (C), R36.1
unnamed: Q16.3 (C), R44.2
unnamed: Q17.1 (B), R51.1
unnamed: Q17.3 (C), R43.2, R47.2, R48.2
unnamed: Q18.1 (B), R52.1
unnamed: Q18.3 (C), R51.2
unnamed: Q19.1 (B), R54.1
unnamed: Q19.2 (E), R53.2
unnamed: Q20.1 (B), R58.1
unnamed: C21.2, Q20.3 (C), R59.1
unnamed: Q20.2 (E), R57.1, U101.4 (1OUT)
unnamed: C21.1, Q21.2 (Q2_B), Q21.5 (Q1_B), R59.2, R60.1
unnamed: R61.2, R62.1
unnamed: R63.1, R64.2
unnamed: C15.1, R33.1, R34.1, U100.3 (1IN+)
unnamed: C16.2, R32.2, R35.2, U100.2 (1IN-)
unnamed: R39.2, R40.2, U100.10 (3IN+)
unnamed: C14.2, R28.2, R31.2, U100.13 (4IN-)
unnamed: R55.2, R57.2, U101.3 (1IN+)
unnamed: C19.1, R47.1, R48.1, R49.1, U102.3 (1IN+)
unnamed: C20.1, R46.1, R50.1, U102.2 (1IN-)
unnamed: R43.1, R44.1, R45.1, U102.5 (2IN+)
unnamed: C18.1, R42.2, U102.6 (2IN-)
VBAT: C22.2, C23.2, F2.2, L81.1, Q14.2 (E), R63.2
VIN_AC: D8.3 (A2); also elsewhere on the board
VREF: C13.2, Q17.2 (E), R25.1, U5.3 (C); also elsewhere on the board
VSYS: Q2.1 (S), Q2.2 (S), Q2.3 (S); also elsewhere on the board

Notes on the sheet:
Charging Current Amp
Battery connector
SOC SSFC? Quick-Acting
Discharging Current Amp
Battery Voltage Amp



Board: 4 copper layers, 72.3 x 45.0 mm, 257 parts (87 on the bottom side), 154 nets.

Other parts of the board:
G1: LOGO; logo

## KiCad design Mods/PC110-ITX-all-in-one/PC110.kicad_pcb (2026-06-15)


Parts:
C14: 150nF; C_0402_1005Metric
C15: 1nF; C_0402_1005Metric
J1: Debug-10
J2: Debug-6
R15: 10k; R_0402_1005Metric
R16: DNP; R_0402_1005Metric
R17: 33; R_0402_1005Metric
RA1: 10k; R-array
RA2: 22k; R-array
U5: 486SX-33; BGA-256

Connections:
CPU_A2: U5.A3 (A2); also elsewhere on the board
CPU_A3: U5.D2 (A3); also elsewhere on the board
CPU_A4: U5.D1 (A4); also elsewhere on the board
CPU_A5: U5.E2 (A5); also elsewhere on the board
CPU_A6: U5.F2 (A6); also elsewhere on the board
CPU_A7: U5.F1 (A7); also elsewhere on the board
CPU_A8: U5.G2 (A8); also elsewhere on the board
CPU_A9: U5.G1 (A9); also elsewhere on the board
CPU_A10: U5.H2 (A10); also elsewhere on the board
CPU_A11: U5.H1 (A11); also elsewhere on the board
CPU_A12: U5.J1 (A12); also elsewhere on the board
CPU_A13: U5.K2 (A13); also elsewhere on the board
CPU_A14: U5.K1 (A14); also elsewhere on the board
CPU_A15: U5.L2 (A15); also elsewhere on the board
CPU_A16: U5.L1 (A16); also elsewhere on the board
CPU_A17: U5.M2 (A17); also elsewhere on the board
CPU_A18: U5.N1 (A18); also elsewhere on the board
CPU_A19: U5.P2 (A19); also elsewhere on the board
CPU_A20: U5.P1 (A20); also elsewhere on the board
CPU_A20M#: J1.7, U5.B13 (A20M#); also elsewhere on the board
CPU_A21: U5.T3 (A21); also elsewhere on the board
CPU_A22: U5.R3 (A22); also elsewhere on the board
CPU_A23: U5.P3 (A23); also elsewhere on the board
CPU_A24: U5.T4 (A24); also elsewhere on the board
CPU_A25: U5.R4 (A25); also elsewhere on the board
CPU_A31: J2.6, U5.R6 (A31); also elsewhere on the board
CPU_ADS#: U5.B3 (ADS#); also elsewhere on the board
CPU_AHOLD: J2.5, U5.A8 (AHOLD); also elsewhere on the board
CPU_BE0#: J1.6, U5.B10 (BE0#); also elsewhere on the board
CPU_BE1#: J1.3, U5.C10 (BE1#); also elsewhere on the board
CPU_BE2#: J1.8, U5.A11 (BE2#); also elsewhere on the board
CPU_BE3#: J1.5, U5.B11 (BE3#); also elsewhere on the board
CPU_BLAST#: J2.1, U5.C3 (BLAST#); also elsewhere on the board
CPU_BRDY#: J1.2, U5.B5 (BRDY#); also elsewhere on the board
CPU_BS16#: U5.A6 (BS16#); also elsewhere on the board
CPU_D0: U5.R7 (D0); also elsewhere on the board
CPU_D1: U5.P7 (D1); also elsewhere on the board
CPU_D2: U5.T8 (D2); also elsewhere on the board
CPU_D3: U5.R8 (D3); also elsewhere on the board
CPU_D4: U5.P8 (D4); also elsewhere on the board
CPU_D5: U5.T9 (D5); also elsewhere on the board
CPU_D6: U5.R9 (D6); also elsewhere on the board
CPU_D7: U5.P9 (D7); also elsewhere on the board
CPU_D8: U5.R10 (D8); also elsewhere on the board
CPU_D9: U5.P10 (D9); also elsewhere on the board
CPU_D10: U5.R11 (D10); also elsewhere on the board
CPU_D11: U5.P11 (D11); also elsewhere on the board
CPU_D12: U5.T12 (D12); also elsewhere on the board
CPU_D13: U5.R12 (D13); also elsewhere on the board
CPU_D14: U5.P12 (D14); also elsewhere on the board
CPU_D15: U5.T13 (D15); also elsewhere on the board
CPU_D16: U5.P13 (D16); also elsewhere on the board
CPU_D17: U5.R16 (D17); also elsewhere on the board
CPU_D18: U5.P16 (D18); also elsewhere on the board
CPU_D19: U5.P15 (D19); also elsewhere on the board
CPU_D20: U5.N16 (D20); also elsewhere on the board
CPU_D21: U5.N15 (D21); also elsewhere on the board
CPU_D22: U5.M16 (D22); also elsewhere on the board
CPU_D23: U5.M15 (D23); also elsewhere on the board
CPU_D24: U5.L15 (D24); also elsewhere on the board
CPU_D25: U5.K16 (D25); also elsewhere on the board
CPU_D26: U5.K15 (D26); also elsewhere on the board
CPU_D27: U5.J16 (D27); also elsewhere on the board
CPU_D28: U5.J15 (D28); also elsewhere on the board
CPU_D29: U5.H16 (D29); also elsewhere on the board
CPU_D30: U5.H15 (D30); also elsewhere on the board
CPU_D31: U5.G16 (D31); also elsewhere on the board
CPU_DC#: U5.A12 (DC#); also elsewhere on the board
CPU_EADS#: J2.4, U5.A13 (EADS#); also elsewhere on the board
CPU_FLUSH#: J2.2, U5.C16 (FLUSH#); also elsewhere on the board
CPU_HLDA: J1.4, U5.B9 (HLDA); also elsewhere on the board
CPU_HOLD: J1.1, U5.C7 (HOLD); also elsewhere on the board
CPU_INTR: U5.D15 (INTR); also elsewhere on the board
CPU_KEN#: J2.3, U5.B7 (KEN#); also elsewhere on the board
CPU_MIO#: U5.C11 (MIO#); also elsewhere on the board
CPU_NMI: J1.10, U5.D16 (NMI); also elsewhere on the board
CPU_RDY#: U5.A7 (RDY#); also elsewhere on the board
CPU_RESET: U5.C13 (RSTCPU); also elsewhere on the board
CPU_SMI#: U5.F15 (SMI#); also elsewhere on the board
CPU_SMIACT#: U5.E16 (SMIACT#); also elsewhere on the board
CPU_SRESET: J1.9, U5.E15 (SRESET); also elsewhere on the board
CPU_STPCLK#: U5.G15 (STPCLK#); also elsewhere on the board
CPU_WR#: U5.C9 (WR#); also elsewhere on the board
Chipset_CPU_CLK: R17.1; also elsewhere on the board
Chipset_CPU_CLK_Sense: R16.2; also elsewhere on the board
GND: C14.1, C15.1, R15.1, RA1.5 (R4.2), RA1.6 (R3.2), RA1.7 (R2.2), RA1.8 (R1.2), RA2.5 (R4.2), RA2.6 (R3.2), RA2.7 (R2.2), RA2.8 (R1.2), U5.F4 (GND), U5.F5 (GND), U5.F6 (GND), U5.F7 (GND), U5.F8 (GND), U5.F9 (GND), U5.F10 (GND), U5.F11 (GND), U5.F12 (GND), U5.F13 (GND), U5.G4 (GND), U5.G5 (GND), U5.G6 (GND), U5.G7 (GND), U5.G8 (GND), U5.G9 (GND), U5.G10 (GND), U5.G11 (GND), U5.G12 (GND), U5.G13 (GND), U5.H4 (GND), U5.H5 (GND), U5.H6 (GND), U5.H7 (GND), U5.H8 (GND), U5.H9 (GND), U5.H10 (GND), U5.H11 (GND), U5.H12 (GND), U5.H13 (GND), U5.J4 (GND), U5.J5 (GND), U5.J6 (GND), U5.J7 (GND), U5.J8 (GND), U5.J9 (GND), U5.J10 (GND), U5.J11 (GND), U5.J12 (GND), U5.J13 (GND), U5.K4 (GND), U5.K5 (GND), U5.K6 (GND), U5.K7 (GND), U5.K8 (GND), U5.K9 (GND), U5.K10 (GND), U5.K11 (GND), U5.K12 (GND), U5.K13 (GND), U5.L4 (GND), U5.L5 (GND), U5.L6 (GND), U5.L7 (GND), U5.L8 (GND), U5.L9 (GND), U5.L10 (GND), U5.L11 (GND), U5.L12 (GND), U5.L13 (GND); also elsewhere on the board
unnamed: RA1.1 (R1.1), U5.P4 (A26)
unnamed: RA1.2 (R2.1), U5.T5 (A27)
unnamed: RA1.3 (R3.1), U5.R5 (A28)
unnamed: RA1.4 (R4.1), U5.P5 (A29)
unnamed: RA2.1 (R1.1), U5.L16 (DP3)
unnamed: RA2.2 (R2.1), U5.R13 (DP2)
unnamed: RA2.3 (R3.1), U5.T10 (DP1)
unnamed: RA2.4 (R4.1), U5.T7 (DP0)
unnamed: R15.2, U5.T6 (A30)
unnamed: R16.1, R17.2, U5.A9 (CLK_CPU)
PNET1: C14.2, C15.2, U5.D3 (VCC), U5.D4 (VCC), U5.D5 (VCC), U5.D6 (VCC), U5.D7 (VCC), U5.D8 (VCC), U5.D9 (VCC), U5.D10 (VCC), U5.D11 (VCC), U5.D12 (VCC), U5.D13 (VCC), U5.D14 (VCC), U5.E3 (VCC), U5.E4 (VCC), U5.E5 (VCC), U5.E6 (VCC), U5.E7 (VCC), U5.E8 (VCC), U5.E9 (VCC), U5.E10 (VCC), U5.E11 (VCC), U5.E12 (VCC), U5.E13 (VCC), U5.E14 (VCC), U5.F3 (VCC), U5.F14 (VCC), U5.G3 (VCC), U5.G14 (VCC), U5.H3 (VCC), U5.H14 (VCC), U5.J3 (VCC), U5.J14 (VCC), U5.K3 (VCC), U5.K14 (VCC), U5.L3 (VCC), U5.L14 (VCC), U5.M3 (VCC), U5.M4 (VCC), U5.M5 (VCC), U5.M6 (VCC), U5.M7 (VCC), U5.M8 (VCC), U5.M9 (VCC), U5.M10 (VCC), U5.M11 (VCC), U5.M12 (VCC), U5.M13 (VCC), U5.M14 (VCC), U5.N3 (VCC), U5.N4 (VCC), U5.N5 (VCC), U5.N6 (VCC), U5.N7 (VCC), U5.N8 (VCC), U5.N9 (VCC), U5.N10 (VCC), U5.N11 (VCC), U5.N12 (VCC), U5.N13 (VCC), U5.N14 (VCC); also elsewhere on the board

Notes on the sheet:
CPU_ADDRESS_BUS
CPU_DATA_BUS

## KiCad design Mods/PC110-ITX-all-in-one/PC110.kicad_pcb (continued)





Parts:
C113, C121: 150nF; C_0603_1608Metric
C114, C116, C120, C131, C133: 10nF; C_0603_1608Metric
C115, C123: 100pF; C_0402_1005Metric
C117, C138, C139: 1nF; C_0402_1005Metric
C118: 330pF; C_0402_1005Metric
C119, C124, C126: 1uF; C_0603_1608Metric
C122, C125, C129, C135, C137, C142, C150, C151, C152, C153: 150nF; C_0402_1005Metric
C127: 120nF; C_0402_1005Metric
C128: 2.2uF; C_0805_2012Metric
C130: 10uF; C_1206_3216Metric
C132: 5.6uF; C_1206_3216Metric
C134, C136, C146, C149: 100nF; C_0402_1005Metric
C140: 180nF; C_0402_1005Metric
C141: 2.7uF; C_0805_2012Metric
C143: 330nF; C_0603_1608Metric
C144, C145: 18pF; C_0402_1005Metric
C147, C148: 100nF; C_0603_1608Metric
D17, D21, D26, D27, D28, D29, D30, D31, D32, D33, D34, D35: N; SOT-416L
D18: 40; D_0603_1608Metric
D19, D20: 24; D_0603_1608Metric
D22: C6; D_0603_1608Metric
D23: 26; D_0603_1608Metric
D24: A2; D_0603_1608Metric
D25: 83; D_0603_1608Metric
D36, D37: Q; 3D
D38, D43, D44: 3D
D39, D41: DNP; 3D; not fitted
D40, D42: K; SOT-416L
D45: 3D; SOT-23
F1: 0.5A; Fuse_1206_3216Metric
J7: PSU_Connector
J8: BridgeBatt
J9: Flat-4
L10: 1.5uH; L_0603_1608Metric
L11: 68uH; L_1210_3225Metric
Q13, Q26: YQ; SOT-416L
Q14, Q16, Q30: 8B; SOT-416
Q15: 8LR; SOT-416
Q17: 7C; TSOT-23
Q18, Q19, Q20, Q21, Q22, Q28: 8C; SOT-416
Q23, Q25: IS6; SOT-23
Q24: 8C; SOT-523
Q27: 582 B74; SOT-89-3
Q29: HQ; SOT-416L
Q31: 6D; 3D
Q32: DNP; SOT-23
Q33, Q35: HQ; TSOT-23
Q34, Q36: CQ; TSOT-23
R151: 56; R_0603_1608Metric
R152: 133k; R_0402_1005Metric
R153, R155, R162, R169, R174, R179, R180, R205, R206, R207, R208, R209, R221, R222, R235: 47k; R_0402_1005Metric
R154, R157, R160, R181, R231, R232, R233: 10k; R_0402_1005Metric
R156, R234: 50k; R_0402_1005Metric
R158, R161, R163, R164, R165, R167, R168, R170, R173, R177, R178, R189, R220: 470k; R_0402_1005Metric
R159: DNP; R_0402_1005Metric; not fitted
R166: 200k; R_0402_1005Metric
R171, R176, R188, R195, R199, R200, R214, R215, R216, R217, R218, R238: 100k; R_0402_1005Metric
R172: 22k; R_0402_1005Metric
R175, R182: 33k; R_0402_1005Metric
R183: 220; R_0402_1005Metric
R184: 470; R_0402_1005Metric
R185: 56; R_0805_2012Metric
R186, R187, R210, R211, R212, R213, R219, R223, R224, R225, R226, R227, R228, R229, R230: 4.7k; R_0402_1005Metric
R190, R202: 1k; R_0402_1005Metric
R191: 300; R_0805_2012Metric
R192: 100; R_0603_1608Metric
R193, R194, R197, R198, R240: 120k; R_0402_1005Metric
R196: 100K; R_0402_1005Metric
R201, R204: 0; R_0402_1005Metric
R203: 3K; R_0402_1005Metric
R236, R237, R239: 68k; R_0402_1005Metric
SW2: Switch
U23: 7W00; sso-8
U29: 3T01; SOT-23-5
U30: 74LVT74; TSSOP-14_4.4x5mm_P0.65mm
U31: 3T01; TSOP-5_1.65x3.05mm_P0.95mm
U32: 74HC14; TSSOP-14_4.4x5mm_P0.65mm
U33: V74; TSSOP-14_4.4x5mm_P0.65mm
U34: SN74HC74; TSSOP-14_4.4x5mm_P0.65mm
U35: E2; SOT-353
U36: 7W14; sso-8
U37, U41, U42: EA; SOT-353
U38: NJM2904M; soic-8-small
U39: 3F01; TSOP-5_1.65x3.05mm_P0.95mm
U40: 8C01; SOT-23-5
U43: M38223E4HP; QFN-80
U44: Front LCD; LCD
X3: 245759; XTAL-2

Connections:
/Power/M38_COM0: U43.77 (COM0), U44.14
/Power/M38_COM1: U43.76 (COM1), U44.13
/Power/M38_COM2: U43.75 (COM2), U44.12
/Power/M38_COM3: U43.74 (COM3), U44.11
/Power/M38_P10_R413: Q36.3 (B), R209.2, R218.1
/Power/M38_P11_R167: Q35.3 (B), R208.2, R217.1
/Power/M38_P12_R407: Q34.3 (B), R207.2, R216.2
/Power/M38_P13_R390: Q33.3 (B), R206.1, R215.1
/Power/M38_SEG0: U43.70 (SEG0), U44.1
/Power/M38_SEG1: U43.69 (SEG1), U44.2
/Power/M38_SEG2: U43.68 (SEG2), U44.3
/Power/M38_SEG3: U43.67 (SEG3), U44.4
/Power/M38_SEG4: U43.66 (SEG4), U44.5
/Power/M38_SEG5: U43.65 (SEG5), U44.6
/Power/M38_SEG6: U43.64 (SEG6), U44.7
/Power/M38_SEG7: U43.63 (SEG7), U44.8
/Power/M38_SEG8: U43.62 (SEG8), U44.9
/Power/M38_SEG9: U43.61 (SEG9), U44.10
/Power/Touch_X+: J9.2, R194.2, R202.1
/Power/Touch_X-: J9.3, Q34.2 (C)
/Power/Touch_Y+: J9.1, R193.2, R203.1
/Power/Touch_Y-: J9.4, Q36.2 (C)
/Power/U54_D: J7.17, Q20.3 (B), U34.2 (D), U34.6 (~Q)
/Power/U54_Q: D39.2 (K), J7.25, R173.1, U34.5 (Q)
CMOS_BATT_Sense: R231.2, U43.6 (P62); also elsewhere on the board
D4_3: D31.3, J7.35; also elsewhere on the board
D11_2: D39.3 (A); also elsewhere on the board
D18_2_3: D17.1, D17.2, J7.21, R155.2; also elsewhere on the board
D28_1: C121.2 (-), D23.1 (K), J7.12; also elsewhere on the board
D46_1: D26.1, J7.39; also elsewhere on the board
Dock_PWR_IN-: J7.5, J7.36, J7.37; also elsewhere on the board
EN_LCD_VAA: R155.1; also elsewhere on the board
F65_ENAVEE: D17.3, J7.26, R154.1; also elsewhere on the board
GND: C113.2 (-), C114.1 (+), C115.1, C116.2 (-), C117.2 (-), C118.2, C119.1 (+), C120.1 (+), C121.1 (+), C122.2 (-), C123.2 (-), C124.1 (+), C125.1, C128.1 (+), C129.2, C130.2 (-), C131.1 (+), C132.2 (-), C136.1, C137.1, C140.2, C141.2 (-), C142.1 (+), C143.2 (-), C144.2, C145.2, C146.1, C148.1, C149.1, C150.1, C151.2, C152.2, C153.1, D19.2 (A), D20.2 (A), J7.7, J7.9, J7.24, J7.29, J7.32, J8.2, Q13.1 (E), Q14.2 (E), Q15.2 (E), Q16.2 (E), Q18.2 (E), Q19.2 (E), Q21.2 (E), Q26.1 (E), Q27.1 (GND), Q28.2 (E), Q30.2 (E), Q34.1 (E), Q36.1 (E), R158.1, R159.1, R161.2, R162.2, R164.1, R186.2, R187.2, R195.2, R196.2, R197.2, R198.2, R207.1, R209.1, R220.2, R234.1, R236.1, U29.3 (GND), U30.7 (GND), U31.3 (GND), U32.7 (GND), U33.7 (GND), U34.7 (GND), U35.3 (GND), U37.3 (GND), U38.4 (V-), U39.3 (GND), U40.3 (GND), U41.3 (GND), U42.3 (GND), U43.16 (P50), U43.30 (GND), U43.73 (GND); also elsewhere on the board
KB_RESET#: D43.1 (A), D43.3 (A), R232.2; also elsewhere on the board
KB_SPKUP: Q28.3 (C), R188.1; also elsewhere on the board
KB_SPKUP_DN: R189.1; also elsewhere on the board
LCD_VAA: C116.1 (+), C117.1 (+), L10.1 (+); also elsewhere on the board
M38_21: U43.55 (21); also elsewhere on the board
M38_P14: U43.42 (P14); also elsewhere on the board
M38_P15: U43.41 (P15); also elsewhere on the board
M38_P16_R86: R213.1
M38_P20: J7.19, U43.38 (P20); also elsewhere on the board
M38_P21: J7.22, U43.37 (P21); also elsewhere on the board
M38_P22_R88: R212.1; also elsewhere on the board
M38_P27_KB_SPKDN: U43.31 (P27); also elsewhere on the board
M38_P35: U43.57 (P35); also elsewhere on the board
M38_P36: U43.56 (P36); also elsewhere on the board
M38_P41: U43.23 (P41); also elsewhere on the board
M38_P43: U43.21 (P43); also elsewhere on the board
M38_P44: U43.20 (P44); also elsewhere on the board
M38_P52: J7.18, U43.14 (P52); also elsewhere on the board
M38_P53: J7.23, U43.13 (P53); also elsewhere on the board
M38_P60: J7.1, U43.8 (P60); also elsewhere on the board
M38_P61: J7.2, U43.7 (P61); also elsewhere on the board
M38_P63: J7.40, U43.5 (P63); also elsewhere on the board
M38_P64: J7.34, U43.4 (P64); also elsewhere on the board
M38_P65: C139.2, R200.2, U38.1, U43.3 (P65)
M38_P66: C138.2, R199.2, U38.7, U43.2 (P66)
M38_P67: R234.2, U43.1 (P67)
M38_P71: D31.2, R176.2, U32.3, U43.26 (P71)
M38_RESET: C115.2, Q18.3 (C), R170.1, R214.2, U30.4 (~S), U33.1 (~R), U33.13 (~R)
M38_VREF: C150.2, C151.1, J7.31, R231.1, U43.72 (VREF); also elsewhere on the board
MN192_VSEN#: C119.2 (-), R166.2, U32.11; also elsewhere on the board
MN195_U1RD#: R165.2, U32.13; also elsewhere on the board
unnamed: C114.2 (-), D20.1 (K), R157.1, U31.2 (VDD)
unnamed: C123.1 (+), R170.2, U34.1 (~R)
unnamed: C124.2 (-), R173.2, U34.13 (~R)
unnamed: C126.1 (+), D26.3, D27.3, D28.3, Q20.1 (E), R175.2
unnamed: C126.2 (-), C127.2 (-), Q20.2 (C)
unnamed: C128.2 (-), Q27.2 (VI), R185.2
unnamed: C131.2 (-), D38.2 (K), F1.1, Q29.1 (E)
unnamed: C132.1 (+), L11.1, Q29.3 (C)
unnamed: C133.1 (+), Q27.3 (VO), R190.1
unnamed: C133.2 (-), Q26.2 (B), R190.2
unnamed: C134.1 (+), C135.1 (+)
unnamed: C142.2 (-), Q32.2 (K), R201.1, U39.2 (VDD)
unnamed: C143.1 (+), Q32.1 (K), U39.5 (CD)
unnamed: C147.1, C148.2
unnamed: D18.2 (A), Q16.3 (C)
unnamed: D18.1 (K), R160.2
unnamed: D19.1 (K), R152.1, R156.2, R159.2, U29.2 (VDD)
unnamed: D21.2 (K), U33.5 (Q)
unnamed: D22.2 (A), D27.2
unnamed: D23.2 (A), D27.1
unnamed: D24.2 (A), D28.2
unnamed: D25.2 (A), D28.1
unnamed: D26.2, R172.1
unnamed: D29.2, U23.3
unnamed: D29.3, R174.2
unnamed: D32.1, D32.2, D35.1, D35.2, R178.1, U37.2
unnamed: D32.3, U32.4
unnamed: D33.2, R179.1
unnamed: D34.1, R180.1
unnamed: D35.3, U32.2
unnamed: D37.1 (A), L11.2, Q26.3 (C)
unnamed: D38.1 (A), D38.3 (A), R191.2
unnamed: D40.1 (K), D42.2 (A)
unnamed: C146.2, D39.1 (A), D41.2 (A), R204.1, U40.2 (VDD)
unnamed: D41.1 (K), R220.1, U40.1 (OUT), U42.2
unnamed: C149.2, D42.1 (K), U41.5 (VCC), U42.5 (VCC)
unnamed: D43.2 (K), U41.4
unnamed: D44.2 (K), U41.2, U42.4
unnamed: D45.2 (K), U43.9 (P57)
unnamed: F1.2, J8.1
unnamed: L10.2 (-), Q17.3 (C), R151.1, R153.1
unnamed: Q13.2 (B), Q14.3 (C), R153.2
unnamed: Q13.3 (C), R151.2
unnamed: Q14.1 (B), Q16.1 (B), R154.2
unnamed: Q15.1 (B), R152.2, U29.1 (OUT)
unnamed: Q17.1 (B), R160.1
unnamed: Q18.1 (B), R169.1
unnamed: Q19.1 (B), R171.1
unnamed: C118.1, Q19.3 (C), R163.2, U30.13 (~R)
unnamed: Q21.1 (B), R174.1
unnamed: Q22.1 (B), R181.1
unnamed: Q22.3 (C), R183.1
unnamed: D33.1, Q22.2 (E)
unnamed: Q23.1 (B), R179.2, R183.2
unnamed: Q24.1 (B), R182.1
unnamed: Q24.3 (C), R184.1
unnamed: D34.2, Q24.2 (E)
unnamed: Q25.1 (B), R180.2, R184.2
unnamed: Q28.1 (B), R189.2
unnamed: Q29.2 (B), R192.1
unnamed: Q30.3 (C), R192.2
unnamed: Q31.3 (B), U43.39 (P17)
unnamed: Q33.2 (C), R202.2
unnamed: Q35.2 (C), R203.2
unnamed: R188.2, U37.4
unnamed: R162.1, R166.1, SW2.2 (B)
unnamed: R163.1, U30.6 (~Q)
unnamed: U30.11 (C), U32.12
unnamed: D29.1, U30.9 (Q), U33.11 (C)
unnamed: U30.8 (~Q), U35.1
unnamed: R167.1, U31.1 (OUT), U32.9
unnamed: U33.6 (~Q), U35.2
unnamed: D30.3, U33.9 (Q)
unnamed: U32.10, U34.3 (C)
unnamed: U32.8, U34.11 (C)
unnamed: R172.2, U34.9 (Q)
unnamed: R194.1, R196.1, U38.3 (+)
unnamed: C139.1, R198.1, R200.1, U38.2 (-)
unnamed: R193.1, R195.1, U38.5 (+)
unnamed: C138.1, R197.1, R199.1, U38.6 (-)
unnamed: R214.1, U39.1 (OUT), U43.25 (RESET)
unnamed: C147.2, U40.5 (CD)
unnamed: R225.1, U43.52 (P02)
unnamed: R226.2, U43.51 (P03)
unnamed: R227.1, U43.50 (P04)
unnamed: R228.1, U43.49 (P05)
unnamed: R229.1, U43.48 (P06)
unnamed: R218.2, U43.46 (P10)
unnamed: R217.2, U43.45 (P11)
unnamed: R216.1, U43.44 (P12)
unnamed: R215.2, U43.43 (P13)
unnamed: R213.2, U43.40 (P16)
unnamed: R212.2, U43.36 (P22)
unnamed: R211.1, U43.35 (P23)
unnamed: R210.2, U43.24 (P40)
unnamed: R219.1, U43.19 (P45)
unnamed: R222.2, U43.15 (P51)
unnamed: R223.2, U43.54 (SEG00)
unnamed: R224.1, U43.53 (SEG01)
unnamed: R230.2, U43.47 (SEG07)
unnamed: R236.2, R237.2, U43.80 (VL1)
unnamed: R237.1, R239.1, U43.79 (VL2)
unnamed: R239.2, R240.1, U43.78 (VL3)
unnamed: C144.1, U43.28 (Xin), X3.1 (+)
unnamed: R205.1, U43.29 (Xout)
unnamed: C145.1, R205.2, X3.2 (-)
PNET1: C129.1, C135.2 (-), D25.1 (K), D41.3 (common), J7.8, J7.33, Q23.2 (E), R168.1, R177.1, R178.2, R204.2, R232.1, R233.2, R238.2, U23.5, U37.5 (VCC); also elsewhere on the board
PNET2: Q25.3 (C), R182.2, R187.1, R228.2; also elsewhere on the board
PNET4: D36.3 (K), J7.3, J7.4, J7.38; also elsewhere on the board
PNET5: C122.1 (+), D24.1 (K), J7.10, J7.11, J7.30, Q25.2 (E), Q31.1 (E), R222.1; also elsewhere on the board
PNET7: Q23.3 (C), R181.2, R186.1, R191.1; also elsewhere on the board
PNET8: C136.2, C141.1 (+), Q31.2 (C), Q33.1 (E), Q35.1 (E), R206.2, R208.1, U38.8 (V+)
PSU_AUX_SW1: J7.28, R210.1, U32.1; also elsewhere on the board
PWRGD_shift: R171.2, U36.1; also elsewhere on the board
PWRGD_shift_buff: D33.3, D34.3, U36.7, U43.27 (PWRGD); also elsewhere on the board
Pluto_50: R175.1; also elsewhere on the board
Pluto_52: R169.2; also elsewhere on the board
Pluto_72: D21.1 (A), D21.3 (A), R168.2; also elsewhere on the board
Pluto_73: D30.1, D30.2, R177.2; also elsewhere on the board
Q43_2: C120.2 (-), D22.1 (K), J7.13, Q17.2 (E); also elsewhere on the board
R73_2: J7.15; also elsewhere on the board
R284_2: C113.1 (+), J7.14, R156.1, R157.2; also elsewhere on the board
R412_1: J7.20; also elsewhere on the board
RESET: D44.1 (A), D44.3 (A), R233.1; also elsewhere on the board
RIOUT#: U23.6; also elsewhere on the board
U8_1A3_KB_TP139: R211.2; also elsewhere on the board
U8_2A1_KB_RXD: R219.2; also elsewhere on the board
U21_97: R230.1; also elsewhere on the board
U21_98: R229.2; also elsewhere on the board
U21_101: R227.2; also elsewhere on the board
U21_102: R226.1; also elsewhere on the board
U21_103: R225.2; also elsewhere on the board
U21_104: R224.2; also elsewhere on the board
U21_105: R223.1; also elsewhere on the board
U21_131: J7.27; also elsewhere on the board
U21_139: D45.1 (A), D45.3 (A), R238.1; also elsewhere on the board
U30_D0: R158.2, U30.2 (D); also elsewhere on the board
U53_2CLK: R161.1, U30.3 (C); also elsewhere on the board
U54_1PRE#: U34.4 (~S), U35.4
U61_RTCBAT_470K: Q21.3 (C); also elsewhere on the board
U106_1CLK: R164.2, U33.3 (C), U43.11 (1CLK)
VCC: C125.2, C127.1 (+), C134.2 (-), C137.2, C140.1, C152.1, C153.2, D40.2 (A), J7.16, Q32.3 (A), R165.1, R167.2, R176.1, R201.2, R221.1, R235.2, R240.2, SW2.1 (A), U30.1 (~R), U30.10 (~S), U30.12 (D), U30.14 (VCC), U32.14 (VCC), U33.2 (D), U33.10 (~S), U33.12 (D), U33.14 (VCC), U34.10 (~S), U34.12 (D), U34.14 (VCC), U35.5 (VCC), U43.71 (VCC); also elsewhere on the board
YellowWire1_2: Q15.3 (C), Q30.1 (B); also elsewhere on the board
YellowWire2_1: C130.1 (+), D36.1 (A), D37.3 (K), R185.1; also elsewhere on the board
YellowWire2_3: J7.6; also elsewhere on the board

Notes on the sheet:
5v switched on via PWRGD
10.5v
YellowWire1
U103_NAND_of_U53_1CLK_and_U53_1Q#

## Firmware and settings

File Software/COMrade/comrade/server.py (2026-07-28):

"""
server.py - the FastMCP stdio server exposing the DOS box as MCP tools.

Claude Code launches this over stdio; it opens (as a client) the serial stream
to the DOS resident agent -- a real serial port on hardware, or a TCP socket
standing in for the COM port under QEMU.  Tools map onto the control protocol:

  screen_read   -> SCREEN_GET     (current painted 80x25 screen + cursor)
  console_read  -> CONSOLE_GET    (lossless output stream, pull by seq)
  keys_send     -> KEYS_SEND      (inject keystrokes)
  file_read     -> FILE_READ      (out-of-band file read, chunked)
  file_write    -> FILE_WRITE     (out-of-band file write, chunked)
  dir_list      -> DIR_LIST       (out-of-band directory listing, continuation)
  file_stat     -> DIR_LIST       (find-first of an exact name)
  file_setattr  -> FILE_ATTR      (out-of-band get-modify-set of DOS attributes)
  run_command   -> KEYS_SEND + CONSOLE_GET poll loop
  dos_status    -> connection + HELLO info / ping

All logging is forced to stderr (stdout is the MCP JSON-RPC channel).
"""

from __future__ import annotations

import asyncio
import base64
import logging
import os
from contextlib import asynccontextmanager

from mcp.server.fastmcp import FastMCP

from . import console as console_mod
from . import keymap, protocol, screen
from .connection import ConnectionManager, port_name

log = logging.getLogger("comrade.server")

# Set by __main__ before mcp.run().
CONFIG = {"transport": "tcp", "host": "127.0.0.1", "port": 7777,
          "device": "/dev/ttyUSB0", "baud": 115200,
          "op_timeout": 8.0, "chunk_max": 1024}

# Single shared connection manager (one DOS box per bridge).
_state: dict = {"cm": None}


def _cm() -> ConnectionManager:
    cm = _state["cm"]
    if cm is None:
        raise RuntimeError("bridge not started")
    return cm


async def _open_stream():
    if CONFIG["transport"] == "tcp":
        return await asyncio.open_connection(CONFIG["host"], CONFIG["port"])
    try:
        import serial_asyncio  # pyserial-asyncio, only needed for real hardware
    except ImportError as exc:
        raise RuntimeError(
            "the --serial transport needs pyserial-asyncio: "
            "`pip install pyserial-asyncio` (or `pip install -e .`)") from exc
    dev = CONFIG["device"]
    try:
        return await serial_asyncio.open_serial_connection(
            url=dev, baudrate=CONFIG["baud"])
    except Exception as exc:  # noqa: BLE001 — surface a usable message, not a raw traceback
        raise RuntimeError(
            f"cannot open serial device {dev!r} at {CONFIG['baud']} baud: {exc}. "
            f"Check the node exists (`dmesg | grep tty`) and you are in the "
            f"`dialout` group.") from exc


@asynccontextmanager
async def _lifespan(_server: FastMCP):
    cm = ConnectionManager(op_timeout=CONFIG["op_timeout"], chunk_max=CONFIG["chunk_max"])
    await cm.start(_open_stream)
    _state["cm"] = cm
    try:
        yield {"cm": cm}
    finally:
        await cm.stop()
        _state["cm"] = None


mcp = FastMCP("comrade", lifespan=_lifespan)


@mcp.tool(name="dos_status",
          description="Connection status to the DOS box plus its HELLO info "
                      "(screen size, protocol version, machine). Includes a "
                      "round-trip ping when connected.")
async def dos_status() -> dict:
    cm = _cm()
    st = cm.status()
    if st["connected"]:
        try:
            st["rtt_ms"] = round(await cm.ping(timeout=5), 1)
        except Exception as exc:  # noqa: BLE001
            st["rtt_ms"] = None
            st["ping_error"] = str(exc)
    return st


@mcp.tool(name="screen_read",
          description="Read the current DOS text screen (the painted 80x25 "
                      "window) and cursor. Use this for full-screen / TUI "
                      "programs (editors). For scrolling command output use "
                      "console_read instead.")
async def screen_read(annotate_cursor: bool = False, include_cells: bool = False) -> dict:
    cm = _cm()
    payload = await cm.get_screen()
    view = screen.render(payload)
    return view.to_dict(include_cells=include_cells, annotate_cursor=annotate_cursor)


@mcp.tool(name="desktop_screenshot",
          description="Capture a small grayscale thumbnail of the Windows 95 desktop. "
                      "This is available when COMR95.EXE is running; DOS TSRs return "
                      "an unsupported-operation error. Set dest_path to write a PGM "
                      "image on the bridge host instead of returning base64 data.")
async def desktop_screenshot(width: int = 80, height: int = 60,
                             dest_path: str | None = None) -> dict:
    cm = _cm()
    info = await cm.get_win_screenshot(width, height)
    if info["status"] != protocol.Status.OK:
        raise protocol.DosError(info["status"], "desktop screenshot failed")
    w, h, data = info["width"], info["height"], info["data"]
    if dest_path is not None:
        target = _host_path(dest_path)
        with open(target, "wb") as fh:
            fh.write(f"P5\n{w} {h}\n255\n".encode("ascii"))
            fh.write(data)
        return {"ok": True, "path": dest_path, "width": w, "height": h,
                "format": "pgm", "bytes": len(data)}
    return {"ok": True, "width": w, "height": h, "format": "gray8",
            "data_base64": base64.b64encode(data).decode("ascii")}


@mcp.tool(name="console_read",
          description="Read newly captured console output as a lossless text "
                      "stream. Pass since=next_seq from the previous call to "
                      "get only new output (start with since=0). This captures "
                      "fast-scrolling output (compilers, DIR, build logs) that "
                      "a screen snapshot would miss.")
async def console_read(since: int = 0, max_bytes: int = 0) -> dict:
    cm = _cm()
    max_len = max_bytes if max_bytes > 0 else (cm.chunk_max or 1024)
    chunk = await cm.read_console(since, max_len)
    return console_mod.format_chunk(chunk)


# Keystrokes are injected in small, buffer-respecting batches at roughly a human
# typing rate, so we never dump more than the ~15-slot BIOS type-ahead buffer can
# hold (which silently drops keys, especially in hardware mode where INT 9 fills
# the buffer) and never outrun programs that process input per keypress. Tune via
# COMRADE_KEY_DELAY_MS (per-key ms) / COMRADE_KEY_BATCH (keys per frame).
_KEY_DELAY_MS = float(os.environ.get("COMRADE_KEY_DELAY_MS", "40"))
_KEY_BATCH = int(os.environ.get("COMRADE_KEY_BATCH", "4"))


@mcp.tool(name="keys_send",
          description="Inject keystrokes into the foreground DOS program. "
                      "Plain text is typed literally; use brace tokens for "
                      "special keys, e.g. {Enter} {Esc} {Tab} {Up} {F1} "
                      "{Ctrl+C}. Newlines map to Enter. method='bios' (default) "
                      "stuffs the BIOS type-ahead buffer (works for DOS/INT 16h "
                      "input); method='hardware' feeds raw make/break scancodes "
                      "to the keyboard controller (a real INT 9) so it also "
                      "reaches games and full-screen apps that bypass the BIOS. "
                      "Keys are paced at ~human speed in buffer-safe batches; pass "
                      "delay_ms to change the per-key rate (0 = send all at once).")
async def keys_send(keys: str, method: str = "bios",
                    delay_ms: float | None = None) -> dict:
    cm = _cm()
    d = _KEY_DELAY_MS if delay_ms is None else float(delay_ms)
    if method == "hardware":
        key_seqs = keymap.to_scancode_keys(keys)
        sent = await cm.type_scancode_keys(key_seqs, d, _KEY_BATCH)
        return {"ok": True, "method": "hardware", "keys": len(key_seqs),
                "scancodes_sent": sent, "delay_ms": d}
    pairs = keymap.parse(keys)
    sent = await cm.type_pairs(pairs, d, _KEY_BATCH)
    return {"ok": True, "method": "bios", "pairs_parsed": len(pairs),
            "pairs_injected": sent, "delay_ms": d}


@mcp.tool(name="key_down",
          description="Press and HOLD a key down (hardware injection, no release) "
                      "-- for games / held keys. key is a name like 'Up', 'Left', "
                      "'Space', 'Ctrl', or a single character. Release it with "
                      "key_up. (8042 controller; needs the box to accept cmd 0xD2.)")
async def key_down(key: str) -> dict:
    cm = _cm()
    n = await cm.send_keys_raw(keymap.key_make(key))
    return {"ok": True, "key": key, "event": "down", "scancodes_sent": n}


@mcp.tool(name="key_up",
          description="Release a key previously held with key_down (hardware "
                      "injection). key as in key_down.")
async def key_up(key: str) -> dict:
    cm = _cm()
    n = await cm.send_keys_raw(keymap.key_break(key))
    return {"ok": True, "key": key, "event": "up", "scancodes_sent": n}


# Direct disk<->disk transfers read/write the BRIDGE HOST's filesystem, so the
# model-chosen path is confined to an allow-root (default: the bridge's working
# dir; widen via COMRADE_HOST_FS_ROOT, set it to "/" to disable confinement).
_HOST_FS_ROOT = os.path.realpath(os.environ.get("COMRADE_HOST_FS_ROOT", os.getcwd()))


def _host_path(p: str, must_exist: bool = False) -> str:
    rp = os.path.realpath(p)
    try:
        inside = os.path.commonpath([_HOST_FS_ROOT, rp]) == _HOST_FS_ROOT
    except ValueError:                      # different drive / unrelated root
        inside = False
    if not inside:
        raise ValueError(f"host path {p!r} is outside the allowed root "
                         f"{_HOST_FS_ROOT!r} (set COMRADE_HOST_FS_ROOT to widen it)")
    if must_exist and not os.path.isfile(rp):
        raise ValueError(f"host file not found: {p!r}")
    return rp


@mcp.tool(name="file_read",
          description="Read a file from the DOS filesystem out-of-band (fast, no "
                      "screen capture). path is a DOS path e.g. C:\\\\SRC\\\\X.C. "
                      "By default returns CP437 text (or base64 if encoding='base64'). "
                      "Set dest_path to stream the file straight to a file on the "
                      "BRIDGE HOST instead -- bytes bypass the model context and the "
                      "transfer is verified end-to-end (CRC-32) with retry; the "
                      "result is metadata only (size, crc32, sha256), no content.")
async def file_read(path: str, offset: int = 0, length: int = -1,
                    encoding: str = "text", dest_path: str | None = None) -> dict:
    cm = _cm()
    if dest_path is not None:
        meta = await cm.read_file_to(path, _host_path(dest_path),
                                     offset, None if length < 0 else length)
        return {"ok": True, "mode": "direct", "path": path, **meta}
    data, total, eof = await cm.read_file(path, offset, length)
    if encoding == "base64":
        payload = base64.b64encode(data).decode("ascii")
    else:
        payload = data.decode("cp437")
    return {"path": path, "total_size": total, "offset": offset,
            "bytes_returned": len(data), "eof": eof,
            "encoding": encoding, "data": payload}


@mcp.tool(name="file_write",
          description="Write a file on the DOS filesystem out-of-band. "
                      "mode='overwrite' (default) or 'append'. data is CP437 text, "
                      "or base64 when encoding='base64'. Set src_path to stream a "
                      "file from the BRIDGE HOST straight to the box instead "
                      "(overwrites; bytes bypass the model context; verified "
                      "end-to-end with CRC-32 + retry); data is then ignored.")
async def file_write(path: str, data: str = "", mode: str = "overwrite",
                     encoding: str = "text", src_path: str | None = None) -> dict:
    cm = _cm()
    if src_path is not None:
        meta = await cm.write_file_from(path, _host_path(src_path, must_exist=True))
        return {"ok": True, "mode": "direct", "path": path, **meta}
    raw = base64.b64decode(data) if encoding == "base64" else data.encode("cp437")
    written = await cm.write_file(path, raw, mode)
    return {"path": path, "bytes_written": written, "ok": True, "mode": mode}


@mcp.tool(name="file_hash",
          description="Checksum a file ON THE DOS BOX (CRC-32 + length) without "
                      "transferring it -- a fast way to verify integrity or that "
                      "two copies are in sync. Returns {length, crc32, crc32_hex}. "
                      "Optionally pass host_path (a file on the bridge host): it's "
                      "hashed too and {match: bool} is returned, so you can confirm "
                      "a DOS file and a host file are byte-identical. The agent "
                      "reads the whole file in a DOS-safe window.")
async def file_hash(path: str, host_path: str | None = None) -> dict:
    cm = _cm()
    h = await cm.file_hash(path)
    if h["status"] != protocol.Status.OK:
        raise protocol.DosError(h["status"], f"file_hash failed for {path}")
    out = {"path": path, "length": h["length"], "crc32": h["crc32"],
           "crc32_hex": f"{h['crc32']:08x}"}
    if host_path is not None:
        import zlib
        with open(_host_path(host_path, must_exist=True), "rb") as fh:
            data = fh.read()
        hc = zlib.crc32(data) & 0xFFFFFFFF
        out.update(host_path=host_path, host_length=len(data), host_crc32=hc,
                   host_crc32_hex=f"{hc:08x}",
                   match=(hc == h["crc32"] and len(data) == h["length"]))
    return out


@mcp.tool(name="dir_list",
          description="List a directory on the DOS filesystem out-of-band (no "
                      "console/keystrokes). path is a DOS wildcard, e.g. "
                      "'A:\\\\*.*', 'C:\\\\DOS\\\\*.EXE', or a drive root 'C:\\\\'. "
                      "Returns entries with name, size, attributes and mtime. "
                      "Hidden, system and subdirectory entries are included.")
async def dir_list(path: str) -> dict:
    cm = _cm()
    if path.endswith("\\") or path.endswith(":"):
        path = path + "*.*"                          # 'C:\' -> 'C:\*.*'
    entries = await cm.list_dir(path)
    return {"path": path, "count": len(entries), "entries": entries}


@mcp.tool(name="file_stat",
          description="Stat a single file or directory on the DOS filesystem "
                      "out-of-band. Give an exact path (e.g. 'C:\\\\FOO.TXT'). "
                      "Returns {exists, entry:{name,size,attr,mtime,is_dir,...}}.")
async def file_stat(path: str) -> dict:
    cm = _cm()
    entries = await cm.list_dir(path)
    match = entries[0] if entries else None
    return {"path": path, "exists": match is not None, "entry": match}


@mcp.tool(name="file_setattr",
          description="Change a file's DOS attributes out-of-band (like ATTRIB). "
                      "Pass hidden/system/readonly/archive as true to set, false "
                      "to clear, or omit to leave unchanged. Returns the resulting "
                      "attributes.")
async def file_setattr(path: str, hidden: bool | None = None,
                       system: bool | None = None, readonly: bool | None = None,
                       archive: bool | None = None) -> dict:
    cm = _cm()
    attr = await cm.file_attr(path, do_set=False)        # current, to preserve unset flags

    def apply(bit, val):
        nonlocal attr
        if val is True:
            attr |= bit
        elif val is False:
            attr &= ~bit

    apply(protocol.A_HIDDEN, hidden)
    apply(protocol.A_SYSTEM, system)
    apply(protocol.A_RDONLY, readonly)
    apply(protocol.A_ARCH, archive)
    new = await cm.file_attr(path, do_set=True, attr=attr)
    return {"path": path, "attr": new,
            "is_hidden": bool(new & protocol.A_HIDDEN),
            "is_system": bool(new & protocol.A_SYSTEM),
            "is_readonly": bool(new & protocol.A_RDONLY),
            "is_archive": bool(new & protocol.A_ARCH)}


def _parse_addr(a) -> int:
    """Linear 20-bit address from an int, a 'SEG:OFF' hex string, or a hex
    string ('0xB8000' / 'B8000'). String forms are HEX; pass an int for decimal."""
    if isinstance(a, int):
        addr = a
    else:
        s = str(a).strip()
        if ":" in s:
            seg, off = s.split(":", 1)
            addr = (int(seg, 16) << 4) + int(off, 16)
        else:
            addr = int(s, 16)
    if not (0 <= addr <= 0xFFFFF):
        raise ValueError(f"address {addr:#x} out of real-mode range (0..0xFFFFF)")
    return addr


def _hexdump(data: bytes, base: int) -> str:
    """DEBUG-style hex+ASCII dump: 16 bytes/row, dash after the 8th, linear addr."""
    lines = []
    for off in range(0, len(data), 16):
        row = data[off:off + 16]
        cells = [f"{row[i]:02X}" if i < len(row) else "  " for i in range(16)]
        hexpart = " ".join(cells[:8]) + "-" + " ".join(cells[8:])
        ascii_part = "".join(chr(b) if 32 <= b < 127 else "." for b in row)
        lines.append(f"{base + off:05X}  {hexpart}  {ascii_part}")
    return "\n".join(lines)


@mcp.tool(name="mem_read",
          description="Read raw bytes from the DOS box's memory (real-mode space "
                      "0..0xFFFFF). address is a linear int (0xB8000), a SEG:OFF "
                      "hex string ('B800:0000'), or a hex string. Returns the bytes "
                      "as hex (or base64 if encoding='base64'). E.g. read the BIOS "
                      "data area, video RAM, or ROMs.")
async def mem_read(address, length: int, encoding: str = "hex") -> dict:
    cm = _cm()
    addr = _parse_addr(address)
    if not (0 < length <= 0x10000) or addr + length > 0x100000:
        raise ValueError("length must be 1..65536 and stay within 0..0xFFFFF")
    data = await cm.mem_read(addr, length)
    payload = data.hex() if encoding == "hex" else base64.b64encode(data).decode("ascii")
    return {"address": addr, "length": len(data), "encoding": encoding, "data": payload}


@mcp.tool(name="mem_write",
          description="Write raw bytes into the DOS box's memory. DANGER: this can "
                      "corrupt DOS/the agent or crash the box -- it is an unguarded "
                      "hardware/debug poke. address as in mem_read; data is hex "
                      "(or base64 if encoding='base64').")
async def mem_write(address, data: str, encoding: str = "hex") -> dict:
    cm = _cm()
    addr = _parse_addr(address)
    raw = bytes.fromhex(data) if encoding == "hex" else base64.b64decode(data)
    if addr + len(raw) > 0x100000:
        raise ValueError("write would run past 0xFFFFF")
    written = await cm.mem_write(addr, raw)
    return {"address": addr, "bytes_written": written, "ok": True}


@mcp.tool(name="mem_dump",
          description="Hex + ASCII dump of DOS memory, DEBUG 'D'-style (16 bytes "
                      "per row). address as in mem_read; length defaults to 128. "
                      "Returns {text} ready to read, plus the raw hex.")
async def mem_dump(address, length: int = 128) -> dict:
    cm = _cm()
    addr = _parse_addr(address)
    if not (0 < length <= 0x10000) or addr + length > 0x100000:
        raise ValueError("length must be 1..65536 and stay within 0..0xFFFFF")
    data = await cm.mem_read(addr, length)
    return {"address": addr, "length": len(data),
            "text": _hexdump(data, addr), "hex": data.hex()}


@mcp.tool(name="io_in",
          description="Read an I/O port (IN instruction). width 1 (byte) or 2 "
                      "(word). Returns the value. Reading some ports has side "
                      "effects -- know the hardware.")
async def io_in(port: int, width: int = 1) -> dict:
    cm = _cm()
    val = await cm.io_in(port, width)
    return {"port": port, "width": width, "value": val, "hex": f"0x{val:0{width * 2}x}",
            "name": port_name(port)}


@mcp.tool(name="io_out",
          description="Write an I/O port (OUT instruction). width 1 (byte) or 2 "
                      "(word). DANGER: writing ports reprograms hardware (PIC, "
                      "PIT, disk, video, ...) and can hang/damage the box.")
async def io_out(port: int, value: int, width: int = 1) -> dict:
    cm = _cm()
    await cm.io_out(port, value, width)
    return {"port": port, "value": value, "width": width, "ok": True,
            "name": port_name(port)}


@mcp.tool(name="bus_stim",
          description="Tight-loop bus stimulus for reverse-engineering / logic-"
                      "analyzer work: repeat one bus cycle 'count' times back-to-"
                      "back on the box from one round-trip, so the driven cycles "
                      "dominate the bus. kind: 'io'/'mem' (reads, safe) or "
                      "'io_out'/'mem_write' (writes -- pass 'value'). WRITE kinds "
                      "to deny-listed ports (see safe_policy) are refused unless "
                      "unsafe=True. max_ticks caps wall-clock (~55 ms/tick, 0=off) "
                      "so a big count can't pin the box. Blocks for the burst.")
async def bus_stim(kind: str, target: int, width: int = 1, count: int = 100000,
                   value: int = 0, unsafe: bool = False, max_ticks: int = 0) -> dict:
    cm = _cm()
    info = await cm.bus_stim(kind, target, width, count, value=value,
                             unsafe=unsafe, max_ticks=max_ticks)
    return {"kind": kind, "target": target, "hex_target": f"0x{target:x}",
            "name": port_name(target), "width": width,
            "iterations": info["iterations"], "last_value": info["last"],
            "hex_last": f"0x{info['last']:0{width * 2}x}"}
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

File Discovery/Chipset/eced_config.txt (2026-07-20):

PC110 VL82C420 EC/ED config window (I/O 0xEC index / 0xED data)
Read live 2026-07-20 via the BIOS gate: out 0xFB (enable); out 0xEC,idx; in 0xED; out 0xF9 (disable).
Confirms this is the chipset shadow/cache/ROM config bank (13j.5), NOT a power-MCU mailbox.

 idx  0  1  2  3  4  5  6  7  8  9  a  b  c  d  e  f
 00: 42 d5 0b 00 06 a8 1a ec 38 00 03 00 29 00 00 2a
 10: 00 00 aa 55 55 6a 55 55 aa 1a 04 08 74 00 00 00
 20: 00 00 00 00 ff ff ff ff ff ff ff ff 00 00 00 00
 30: 00 00 00 00 00 00 00 10 00 00 00 00 00 00 00 00

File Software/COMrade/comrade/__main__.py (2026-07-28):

"""
comrade entry point - MCP stdio server bridged to a DOS serial agent.

Real hardware (DOS box on a serial cable / USB-serial):
    python3 -m comrade --serial /dev/ttyUSB0 --baud 115200
QEMU (guest COM port bridged to a host socket):
    python3 -m comrade --tcp 127.0.0.1:7777

Register with Claude Code:
    claude mcp add comrade -- python3 -m comrade --serial /dev/ttyUSB0
"""

from __future__ import annotations

import argparse
import logging
import sys

from . import server


def main() -> int:
    ap = argparse.ArgumentParser(description="MCP bridge to a serial MS-DOS agent")
    g = ap.add_mutually_exclusive_group()
    g.add_argument("--serial", metavar="DEVICE",
                   help="serial device to the DOS box, e.g. /dev/ttyUSB0 or COM3")
    g.add_argument("--tcp", metavar="HOST:PORT",
                   help="TCP socket carrying the serial stream (QEMU -serial tcp:...)")
    ap.add_argument("--baud", type=int, default=115200, help="serial baud (default 115200)")
    ap.add_argument("--op-timeout", type=float, default=8.0)
    ap.add_argument("--chunk-max", type=int, default=1024)
    ap.add_argument("--log-level", default="INFO")
    args = ap.parse_args()

    logging.basicConfig(level=getattr(logging, args.log_level.upper(), logging.INFO),
                        stream=sys.stderr,
                        format="%(asctime)s %(name)s %(levelname)s %(message)s")

    if args.tcp:
        host, port = args.tcp.rsplit(":", 1)
        server.CONFIG.update(transport="tcp", host=host, port=int(port))
    else:
        server.CONFIG.update(transport="serial",
                             device=args.serial or "/dev/ttyUSB0", baud=args.baud)
    server.CONFIG.update(op_timeout=args.op_timeout, chunk_max=args.chunk_max)

    server.mcp.run(transport="stdio")
    return 0


if __name__ == "__main__":
    raise SystemExit(main())

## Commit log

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2026-07-02 Add PS2.EXE reverse-engineering + PS2TUI text-UI tool
    Discovery/PS2: analysis of IBM's PS2.EXE system-management utility.
    Mechanism is APM (INT 15h AH=53h: standard 530A + IBM vendor ext 5380 x38)
    plus direct port pokes to CMOS (70/71), SCAMP VL82C420 (74/76) and the
    power MCU (EC/ED) - the same registers reverse-engineered in Discovery/.
    Includes the live _@REVision firmware manifest (BIOS 0.33, APM 0.27, VGA
    0.15, SETUP/DIAG 0.27, KBFIRM 0.21, PSMC 0.38) and a command<->subsystem
    cross-reference (e.g. inking tablet = the 15E0/35E0 windows).
    Software/PS2TUI: a full-screen text-UI front-end that replaces PS2.EXE's
    ~50 cryptic switches with a navigable menu, applying changes by invoking
    the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
2026-07-02 PS2TUI: fix invisible menu text (black-on-black) + brighten palette; link standalone repo
    The un-selected menu items were drawn with attribute 0x00 (black on black,
    invisible on the LCD) because 'mov ax,[top]' clobbered the attribute in AH.
    Fixed the register use and switched to bright-white body text with a
    reverse-video selection. Now mirrors the standalone github.com/ahmadexp/PS2TUI.
2026-07-02 PS2TUI: add _@COMB, _@Token ring, _@IRQClear (full command coverage)
    Cross-checked the menu against the full PS2.EXE reference
    (basterfield.com/pc110/ps2); these three enumerated commands were missing.
    Added to Advanced (COMB flagged '!' - re-muxes the shared UART). Remaining
    menu-absent commands need free-form input: ON alarm, _@CMOS, _@FNkey.
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2026-07-03 Discovery: unlock+dump VL82C420 config space; live-probe Pluto & Bowman
    VL82C420 (Chipset §13a): cracked the config lock. The 0x74/0x76 indexed config
    reads all-FF post-POST because the BIOS locks it via the 0x22/0x23 gate
    (enable: out 0x23,0/out 0x22,0x80/out 0x22 word 0x0080; disable sets bit8).
    With the gate open and read ATOMICALLY (it re-locks between bus cycles), the
    full config space is readable - dumped live (scamp_config.txt); idx 0x7A/0x7B =
    'SL' signature confirms validity. Also mapped the BIOS register-access helper
    table (F000:DB60-DC90) and its indexed banks. Resolves Open Question #1.
    Pluto (§6c): live host-register probe - FDC (0x3F0-0x3F7, controller alive),
    PCIC (0x3E0/0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
    [scamp_config.txt]
2026-07-03 Chipset §13c: live-verify VL82C420 integrated peripheral cores
    Read-only probe of the running unit confirms the integrated 8259A x2,
    8254 PIT, 8237 DMA x2, MC146818 RTC, port-92 A20 gate and 8042 KBC
    interface, and pins down the concrete PC110 IRQ map (IMR 0xA8/0xAC):
    IRQ0/1/2/4/6/8/9/12/14 live; IRQ13 masked (no FPU on the 486SX). PIT ch0
    mode-3 18.2 Hz tick counting; RTC VRT=1 (battery good), no POST errors;
    equipment word 0x4225 matches the machine. No config writes, no CPU-speed
    change.
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2026-07-03 Discovery: live audio (ES488/OPL2) + correct storage vs PCIC socket A
    ES488 §6a: SB DSP present at 0x220 reporting v2.01 (SB 2.0-compat mode,
    matches the ADDAUdio 0220 finding); YM3812 OPL2 responds at 0x388.
    Pluto §6c: correct the socket-A note - boot storage is the standard ATA
    channel (0x1F0, status 0x50 ready, IRQ14), NOT PCIC socket A. Socket A
    is a separate I/O card on IRQ9 with a live window at 0x530 (identity
    undetermined). Add ATA row to the live-probe table.
2026-07-03 Live-Dump: sync I/O-port map with 2026-07 deep probes
    Add ATA (0x1F0, IRQ14 boot storage), ES488 audio (DSP v2.01 @0x220),
    OPL2 (0x388); refine COM1 UART (16550A, OUT2->IRQ4) and VGA (F65535
    rev1, XR00=C1); note SCAMP 0x74/0x76 is now unlockable. Correct §5.2:
    the boot CF is on ATA, not PCIC socket 0 (socket 0 = separate I/O card
    on IRQ9). Cross-links to the per-chip live sections.
2026-07-03 Trackpoint §7a: live probe of U75 + firmware-extraction verdict
    Brought up the 8042 aux channel (disabled at rest, cmd byte 0x65) and
    queried U75 over PS/2: reset -> FA AA 00, ID 0x00 (standard mouse), status
    -> 4 counts/mm, 100 Hz. Restored aux to disabled. Documents why the
    uPD17137A mask-ROM firmware is NOT dumpable from inside (separate 4-bit
    MCU, internal mask ROM, PS/2 aux is the only host path and has no ROM-read
    command; mask part has no in-system verify) and the real offline paths
    (decap/optical, SEM, OTP substitution).
2026-07-03 PS2TUI: add pointing-device (trackpad U75) identify + settings
    Sync the new build with the 8042-aux pointing-device screen (reset/
    self-test, device ID, live resolution + sample-rate settings for the
    NEC uPD17137A trackpad MCU). Cross-refs Discovery/Trackpoint §7a.
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2026-07-03 PSU-MB-M38 §6.3: add MCU-window liveness test result
    Sampling 0xEC/0xED before/after ~18s of sustained CPU+bus load moved no
    byte (no LSB jitter). Records that the raw window can't be shown live vs
    latched from the host (battery current ~0 + regulated bus on AC/full), and
    that cooked telemetry (AC/battery%/state) is separately live via APM 530A.
2026-07-03 Live-Dump §14a: ATA IDENTIFY of internal flash + storage topology
    Direct ATA IDENTIFY DEVICE on 0x1F0: the '4 MB CHS stub' is a real
    SanDisk SunDisk SDP3B-4 (serial MZX00050880, FW Rev 1.20, 123x2x32 =
    3.8 MB) = drive D: (factory PC DOS/EZPLAY). Clarifies the two-device
    topology: 0x1F0 ATA = 4 MB SanDisk (D:), PCIC socket A = ~90 MB Win95 CF
    (C:) in PC-Card ATA I/O mode on IRQ9 (SNSCCARD stack). COMRADE launches
    from C:\AUTOEXEC; RMUDOSAT.SYS on D: owns the 0x15E8/0x35EA EC windows.
    Corrects the earlier over-correction that called only 0x1F0 'the storage'
    (both are storage). Pluto §6c socket-A note updated to match.
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2026-07-03 Correct storage/PCMCIA topology: 2GB CF slave + PCMCIA sound/SCSI card
    Deeper ATA + config probing corrects an earlier wrong inference:
    - 0x1F0 master = SanDisk SDP3B-4 (3.8MB) = D: (factory PC DOS/EZPLAY)
    - 0x1F0 SLAVE = SanDisk SDCFX3-2048 (2GB CF) = C: (Windows 95) [IDENTIFY]
    - PCIC socket A = a PCMCIA sound+SCSI multimedia card, NOT storage:
    SNSCDOSV.PRM shows PCM_CODEC_IO=530h FM_IO=388h SCSI_IO=140h IRQ=9
    AD-LIB_COMP -> AdLib audio + SCSI CD-ROM (MSCDEX PSSC_CD); snsccard.drv
    is the active Win95 audio. (Board also has onboard ESS ES488 on IRQ5.)
    Fixes the socket-A=C: claim in Live-Dump 5.2/14a and Pluto 6c.
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2026-07-03 PS2TUI: sync two-level menu redesign (categories -> sub-menus)
    Polished framed UI with a category main menu opening sub-menus; title/
    breadcrumb bar, blue/cyan theme, context footer. Information category now
    surfaces Battery status + Current settings as menu items. Binary + source
    + new screenshots synced from the standalone repo.
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2026-07-06 Trackpoint 7b: SETTLED via NEC manual - mask uPD17137A has no verify-mode pins
    Obtained the NEC uPD17134A subseries user manual (U11607EJ3V0UM00). Chapter 18
    documents the full one-time-PROM write/verify readout (Table 18-1 pins: VPP
    +12.5V, VDD +6V, RESET, CLK=4-pulse address advance, MD0-3 mode select, D0-D7
    data; Table 18-3 verify mode = MD LLHH; Fig 18-2 read = clock CLK, 4 clocks per
    address out on D0-D7). BUT Table 18-2 states plainly that the VPP pin and
    operating-mode-select pins are 'Not available' on the mask ROM versions
    (17134A/17135A/17137A) and only 'Provided' on the OTP (17P136A/17P137A). So the
    mask uPD17137A (U75) physically cannot enter verify mode -> no pin-level ROM
    reado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
2026-07-15 Chipset/Bowman: correct ML-bus pin IDs (MLCLK=39, MLADS#=52)
    Schematic re-check + 2026-07-14 live payload capture: MLCLK = Chipset_IO3
    = Bowman U21 pin 39 (continuous ~22.7 MHz), MLADS# = Chipset_IO4 = pin 52
    (per-cycle strobe). Earlier 52/140 IDs were a 0.5mm-pitch miscount; the
    idle trio is now Chipset_IO1/2/5 (45/140/130). Updates the payload-probe
    guide tables, Chipset 11b, and the Bowman pinout row.
2026-07-15 Chipset/Bowman: 2026-07-14 ML-bus payload capture results + Bowman marking
    Chipset 11c (measured): 3-group multiplex confirmed live; high address
    A[25:10] static within a transaction; dynamic/multiplexed content is on
    the low lines A[9:2]; MLADS# frames memory/companion cycles, NOT ISA I/O
    (io_in shows MIO# low ~4us with MLADS# never asserting); all probes
    validated incl. MIO#. Bowman: package is laser-marked
    'RIOS BOWMAN 63G33 1017 JAPAN S536AAI' -> BOWMAN is a real IBM 63G33-series
    part marking, not just a schematic codename (resolves open Q4).
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2026-07-15 Chipset 11d: PC110 does not multiplex addr/data on A[25:2]
    Decisive write experiment (mem_write 0xFFFF -> 0xB8000, trigger locked to
    that exact write with A[9:2] all low): the low lines stay 0x000 through the
    entire cycle and all MLADS# strobes -- the data byte never appears on the
    address lines. Combined with 11c (high lines also static within a cycle):
    the CPU address is presented STATICALLY on A[25:2], data rides a separate
    bus, and the multiple MLADS# strobes are Bowman decode/handshake phases,
    not US 5,793,990 multiplex groups (that scheme is a generic VL82C420
    capability this implementation doesn't use). Amends the 11c interpretation
    and flags the payload-probe doc's hypothesis accordi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
2026-07-15 Chipset 11d: add ML companion-cycle timing signature
    Tight-triggered isolated read/write cycles to VGA 0xB8000: a companion ML
    memory cycle spans ~128 ns (~3 MLCLK @ 22.7 MHz) with MLADS# re-strobing
    2-3x -- quantifies the decode/handshake framing. No robust read/write
    difference (variability dominates); not claimed. Note: COMrade's own UART
    traffic generates companion MLADS# cycles, so a clean decode-window map
    needs target reads isolated from that background (attempted, too noisy at
    current A2-9/A18-20 address visibility).
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2026-07-17 Chipset 11i-follow-2: upper-mem + I/O companion scan - nothing companion at runtime
    BUS_STIM-driven dominant scan of upper memory + I/O: total MLADS#=0 in every
    window. UMB 0xD0000 / BIOS-ext 0xE0000 internal; UART 0x3F8, CF/IDE 0x1F0,
    FDC 0x3F4 all direct ISA (resolves the 11e UART caveat -> ML carries no I/O
    at all). No runtime companion region found -> ML/Bowman path is boot-ROM-only.
    (3 mem targets' bursts under-ran on connect timing; their windows still 0
    companion.)
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2026-07-17 Pluto Pass-2b: cycle timing + aliasing resolved (0x1Ex = inking pad)
    Exhausted remaining current-wiring measurements before rewire. Timing: every
    port shows uniform 536ns IOR# low / no differential wait states -> VL82C420
    issues one standard 8-bit-ISA cycle for all; timing can't attribute owner.
    Aliasing via full-address io_in: 0x15E0=0x00 / 0x15EE=0x80 real while
    0x1E0/0x1EE open-bus 0xFF -> device decodes full 0x15E0 base = the inking pad
    (INKDRV); the 0x1Ex ~50us poll loop is pad polling. 0x0074=0x0F idx vs
    0x0474=0xFF confirms 0x74 full-decoded chipset port. Wiring now fully
    exhausted; owner attribution needs Pass-3 select pins.
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2026-07-18 Pluto Pass-4: extended pin fan (method limit) + unknown pins are static
    IOR#-only trigger + 10 probe pins (unknown 50/55/56/57/74, MN195/Bowman/FDD).
    Every probe pin static (0 transitions) for all ports incl keyboard: they are
    subsystem-output/status lines that only move when the subsystem is exercised,
    not on passive reads, and KB_CCS (the proven select) was dropped -> no
    positive control, so null can't attribute 0x24/0x25. Real result: unknown
    pins 50/55/56/57/74 hold static DC (50=L,55=H,56=L,57=L,74=H) through
    thousands of I/O cycles -> straps/config/slow-status, not bus selects. Pass-3
    attribution stands (0x24/0x25=chipset by identity w/ 0x74/0x76). Rig: fixed
    ser2net to bind :2010 dura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
2026-07-18 Correct FDC attribution: U22 (SMC FDC37C665IR) is the FDC, not Pluto
    Netlist shows U22 = FDC37C665IR Super-I/O (FDC + 2x 16550 UART + IDE + LPT,
    own 24.576MHz xtal). Pluto is only the decode/glue front-end: FDC_IOW strobe
    (pin 58) to U22 + FDD_IO1-4 routing. Fixes wrong 'Pluto is the FDC' claims in
    readme 6b/6c and the over-attribution of FDC/UART/IDE (=U22) and PCIC (=U74
    RB5C396) to Pluto. Reinterprets Pass-5: Pluto_IOW = FDC_IOW to U22 (why it was
    quiet on keyboard writes; fires on floppy writes), not an external-BIOS strobe.
    Corroborated by logic-analyzer attribution (Pass 3-5): Pluto directly decodes
    only keyboard/KBC + inking-pad branch.
2026-07-18 Test result: Pluto pin 58 is NOT the FDC write strobe (disproves prior note)
    Live test: continuous 0x3F2<-0x0C (FDC DOR, safe no-op) with a direct trigger
    on pin 58 (CH3) -> never asserted (28s timeout); 0 assertions in windowed
    counts on floppy, keyboard, and idle writes. So pin 58 (net-named FDC_IOW) is
    NOT the FDC's write strobe: FDC37C665 U22 takes IOW# directly from the ISA bus
    (its own pin 43). Pin 58 static under every stimulus tried; function/connectivity
    unconfirmed. Corrects the earlier reinterpretation. U22=FDC finding unaffected
    (rests on netlist part ID, not pin 58).
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2026-07-18 Service manual rev 2.1: live I/O attribution; FDC=U22 correction
    Fold this session's logic-analyzer findings into the service manual:
    - NEW section 10.5 I/O-ownership map (which chip decodes each host port)
    - CORRECT the FDC: U22 (SMC FDC37C665IR Super-I/O) is the FDC/UART/IDE, NOT
    Pluto (fixes 10, 16, 19); Pluto only routes FDD glue
    - Pluto directly decodes only keyboard/KBC (0x60/64->KB_CCS) + inking-pad
    branch (0x15EA->KB_CNTR#); PCIC=U74; config/RTC=VL82C420
    - Pin 58 'FDC_IOW' shown NOT to be the FDC write strobe; pins 55-57/74 static
    straps
    - VL82C420 TP1 (ball T14) probed static-high ONCE#-class test strap (8.4, 20)
    - roster U22 sharpened; KB_CCS + TP1 added to test-point ref; re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
2026-07-18 KiCad: rename Pluto pins per measured findings (58, 75, 79)
    Symbol pin names + PCB pad pinfunctions (cosmetic only - no net labels or
    netlist changes; verified none of these strings are used as nets):
    - pin 58: Pluto_IOW -> Pluto_58 (tested NOT a write strobe: never asserts on
    floppy/keyboard/any writes; function unconfirmed, placeholder convention)
    - pin 75: NM192_VDSA# -> MN195_VSDA# (modem chip is the Panasonic MN195001;
    long-flagged transcription error)
    - pin 79: FDC_O -> ESS_AEN (drives the existing ESS_AEN audio address-enable
    net; old FDC-ish name misleading since the FDC is U22)
    Applied to ASIC.kicad_sch, PC110.kicad_sym, PC110.kicad_pcb and the
    Single-Sheet-Schematic copies; P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
    [ASIC.kicad_sch, PC110.kicad_pcb, PC110.kicad_sch]
2026-07-18 KiCad: ML-bus pin names on Bowman+chipset; re-correct Chipset 11b
    KiCad cleanup (cosmetic pinfunction/pin-name only; net names untouched):
    - PCB pad pinfunctions: U61 N9/P9/R9/T9/T13 (were Bowman1-5) and U21
    39/45/52/130/140 (were Chipset_IO1-5) -> MLCLK/MLADS#/MLRDY#/MLLBA#/
    MPriority, matching the already-updated symbols
    - Single-Sheet sym+sch symbol pins updated the same way (wire labels/nets
    left as-is); QFP-variant VL82C420 symbol in main lib updated (75-78, 61)
    Doc re-correction found during the cross-check: Chipset 11b 'Correction 1'
    was itself wrong - balls N9/P9/R9/T9/T13 are U61 (VL82C420FC5 netlist
    section), NOT Pluto (a QFP; has no balls). Bowman1-5 and Chipset_IO1-5 are
    t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
    [PC110.kicad_pcb, PC110.kicad_sch]
2026-07-18 PC110.kicad_sym: fix pre-correction ML pin swap (45/52, N9/T9)
    The main symbol library still carried the pre-2026-07-14 assignments in its
    Bowman and VL82C420-BGA copies: pin 45=MLADS#/52=MLRDY# and N9=MLADS#/
    T9=MLRDY#. Corrected to the measured mapping (45=MLRDY#, 52=MLADS#;
    N9=MLRDY#, T9=MLADS#) so the library matches ASIC.kicad_sch,
    Chipset.kicad_sch, both PCBs' pinfunctions, and the Single-Sheet copies.
    Audited with a proper pin-block parser (name paired with its own number).
2026-07-18 Adopt ML-bus trio naming as official across docs
    Per decision: MLRDY#=Bowman1/N9/pin45, MLLBA#=Bowman2/P9/pin140,
    MPriority=Bowman5/T13/pin130 (MLCLK/MLADS# were already measured). Stated
    plainly in Chipset 11b + open-questions summary (also fixes the stale
    'Bowman-Pluto link' wording there), Bowman readme pin table, and service
    manual 8.3; matches the names applied in KiCad.
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2026-07-20 Chipset 13f: controlled-change attribution log (volume, cover, method)
    Live snapshot/act/diff findings via new COMrade toolkit:
    - Volume up/down -> CMOS 0x73 (high nibble = level 0-7; min 08/mid 48/max 78),
    reversible/monotonic
    - Cover close -> box SUSPENDS (PS2 Cover=Enable on this unit; clean resume on
    reopen) -- behavioural, no latched register
    - Caps Lock -> BDA 0040:0017 bit6 only (method validation; no chipset/EC reg)
    - AC unplug -> EC-B 0x06 bit1/0x09 bit3 (cross-ref Pluto)
    - Pad deferred (needs INKDRV, absent); 0x15E8 EC-A byte noise; EC-B battery/
    thermal indices need sustained drain
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2026-07-20 EC-B AC bit cross-validated vs APM 530A; battery telemetry via APM
    Read APM INT 15h AX=530A live over COMrade (DEBUG script): BH (AC on-line)
    agrees with our mapped EC-B 0x06 bit1 and flips with the adapter -> independent
    BIOS confirmation of the AC-present attribution. Full battery telemetry
    (state/charge%/time) is available safely via APM 530A, so the raw EC Zn
    mailbox (0x15E8/0x15EC) needn't be fuzzed. Confirms battery gauge is
    command-driven (surfaced by APM), matching the passive-drain negative.
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2026-07-20 Chipset 13b/13g: datasheet-hunt verdict + block2 live-unlock hung the box
    Research (13b): exhaustive sweep confirms NO VL82C420/144/146/410 databook is
    public. Patents pin the architecture: US5659680 (indexed 1-byte extension regs,
    ~100pg map on paper), US6021498 (index base is software-programmable -> same
    SCAMP design at 0xEC/ED, 0x24/25, 0x74/76 by relocation), US5630052 (0x22/23
    gate is Intel PM-debug, not VLSI). Best OCR cross-refs: VL82C480 datasheet for
    0x24/25 (DRAM/shadow/ISA), 386SL/82360SL for 0x74/76 PM indices. yyzkevin
    corroborates the 0x24/25 window.
    13g: live block2 unlock (atomic cli gate+read via DEBUG) HUNG the box -- a
    config access stalls the bus under cli, freezing COM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
2026-07-20 Chipset 13g: block2 unlock is SAFE (method fix); block2 is write-only
    Re-attempted block2 unlock with two fixes: interactive 'a 100' assembly
    (the prior e-command hex-load was corrupted over the console) + no cli (so a
    soft stall can't freeze COMRADE's ISR). Same gate sequence ran clean, box
    stayed alive -> the earlier hang was our method, not the operation (13g
    'unsafe' overturned). But block2 (0x24/0x25) reads 0xFF under every condition:
    plain, gated, swept 0x00-1F, at 0x2E/0xB7, and 0x24 doesn't even read back its
    index (unlike 0x74). block2 is write-only / read path not decoded; the 0x22/23
    gate unlocks 0x74/76 not 0x24/25. Its contents need BIOS disasm, not live
    reads. Safe dead end.
2026-07-20 Chipset 13i: block2 FULLY READ live via four-read enable (write-only overturned)
    Assembled a CRC-verified .COM replicating the BIOS gate (cli; out 0x70,0x80;
    IN FC23/F023/C023/0023; read 0x24/0x25 x256; relock; NMI on; write file),
    delivered via write_file, ran it, read back C:\BLK2.BIN. Block2 read cleanly:
    119/256 indices non-FF, box stayed alive. So block2 is fully readable -- the
    13g 'write-only' reading was the wrong gate. Full dump in block2_config.txt.
    Structure: ~0x80-stride mirror (0x00-0F ~ 0x90-9F); DRAM-timing bytes shared
    with SCAMP 0x74/76 (block2 0xB0 = BA 9E..5A 50..10 14 = SCAMP row 0x30) ->
    0x24/25 and 0x74/76 are related views of the VL82C420 config; block2 0x84/85 =
    15EE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
    [block2_config.txt]
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2026-07-21 PSU-MB-M38 §8: front LCD live hardware capture + pin/element map
    - New visual section with real screenshots from the LCD driven by an
    Arduino Uno WiFi Rev2 (SEG0-9=D2..D11, COM0-3=A0..A3).
    - Full-layout photo: 4-digit 7-seg + colon (88:88) + % + battery + arrow
    + tri-1 + tri-A + [up/down box].
    - Wiring table (Arduino <-> U43 <-> net <-> U6) and SEG*COM -> element maps.
    - Hardware-confirms the §7 decode: segment bit-map, colon = seb3 $41
    (SEG2xCOM3), icon byte $44 bits 0,1,4,5,6 = battery/arrow/tri-1/tri-A/box;
    % segment present on glass but never driven by this ROM rev.
    - §7.6 caveats 'icon legends' and 'glyph geometry' marked RESOLVED.
2026-07-23 Bowman/Pluto: map M38813 (U67) KBC to gate arrays; correct M38_IO attribution
    - Read U67 pinout from the schematic (M38813M4.png, IC79 TQFP-64) + KBC firmware.
    - CORRECTION: M38_IO1..12 does NOT connect to U67 (U67 has no such pins).
    U67's host side is a standard 8042-style KBC bus: SD0-7 data, IOR#/IOW#,
    KBCCS# (chip-sel from Pluto), SA2/A0, IRQ1(pin15)->Bowman86, IRQ12(pin14)
    ->Bowman76, RESET#(19), KBRST#/A20G outputs, speaker->Pluto43/44.
    - Added full 64-pin U67 pinout table (matrix, 2x PS/2, pointer, LEDs, SMI) and
    the DBB host-protocol notes (DBB0/1, OBF/IBF/A0) to Pluto readme.
    - Fixed Bowman $3.6 + component table; flagged M38_IO far-end (likely U6) and
    the U6-telemetry ser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
2026-07-23 Resolve M38_IO far-end: confirmed Bowman<->U6 (power MCU) by wire trace
    - Deterministic trace of ASIC.kicad_sch: Bowman pins 106/107/110/111 carry
    U6 nets M38_P15_Buf/M38_P14_Buf/M38_P43/M38_P41 (P14/P15 buffered), all
    present on U6's sheet Power.kicad_sch. So M38_IO1..12 = U6's ~12-line
    parallel host interface to Bowman, NOT U67. (pin139/'IO13' = power via R349.)
    - Bowman §3.6 upgraded [H]->[C]; Pluto open-item (1) marked RESOLVED.
    - PSU-MB-M38 §6.1: noted U6's parallel Bowman link as a strong candidate for
    the 0xEC/0xED host window (vs the SIO1-serial-bridge story); path not settled.
2026-07-23 Pluto: decode pins 55/56/57 as a 3-bit weighted-resistor DAC (contrast/analog level)
    Deterministic ASIC.kicad_sch trace: Pluto pins 55/56/57 (was 'Pluto_55..57'
    placeholders) each drive an NPN (Q44/Q43/Q19) via a 22k base R; each collector
    adds a weighted R (R409 2.2k / R412 7.5k / R410 20k) onto common node R412_1,
    which crosses J5/J3 pin 20 to the PSU board. => a 3-bit (8-step) analog-level
    DAC, most likely LCD contrast/VEE-bias (exact PSU-side load off-project).
    Pin 74 (PNET7_SENSE) = power-rail sense (R304 4.7k). Corrects the earlier
    'static straps' guess in the Service Manual. Pins 50/58 remain placeholders.
2026-07-23 Bowman §6: font ROM (U36) decode + paging resolved; correct ROMCE# attribution
    - Traced ROM.kicad_sch: U36 font ROM is a Bowman-paged, MEMORY-mapped ROM.
    A0-A11 <- ISA SA1-SA12 (window); A12-A19 <- Bowman ROMA12-19 (page latch);
    CE# <- Bowman ROMCE#; OE# <- MEMR#. Page 0 = 8KB option-ROM window (55 AA hdr).
    - CORRECTION: Bowman ROMA*/ROMCE# drive the FONT ROM, not the BIOS flash.
    BIOS flash (U59, 28F002) is chipset-decoded (Chipset_BIOS_CE#/Chipset_SA16/
    BIOS_SA17) -- separate select; the two ROMs never share a chip-enable.
    - Bank question resolved: MSM538032E is 8-Mbit (1 MiB, 512Kx16/1Mx8); the 1 MiB
    dump is the complete device -- no second bank.
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2026-08-20 assign bus label and fix copper zone net
    [Modem.kicad_pcb, ramrom.kicad_sch]
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

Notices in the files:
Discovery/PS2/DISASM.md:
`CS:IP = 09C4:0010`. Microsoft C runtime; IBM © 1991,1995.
